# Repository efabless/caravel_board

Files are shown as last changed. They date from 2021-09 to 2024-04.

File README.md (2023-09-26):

# Caravel Board

This repo provides firmware examples, flash programming and diagnostic tools for testing
Open MPW and chipIgnite projects using Caravel.  It also provides schematics, layout and gerber files for PCB evaluation and breakout boards.

## MPW-2 & MPW-3 Project Owners

See the README for the the Nucleo automated [test setup here](firmware/mpw2-5/nucleo)

## chipIgnite Projects (including Stanford)

See the README for testing projects here -- https://github.com/efabless/caravel_board/tree/main/firmware/chipignite#readme

## Firmware

You will need python 3.6 or later.  

To program Caravel, connect the evaluation board using a USB micro B connector.

```bash
pip3 install pyftdi

cd firmware/blink

make clean flash
```

### Install Toolchain for Compiling Code

#### For Mac

https://github.com/riscv/homebrew-riscv

#### For Linux

https://github.com/riscv/riscv-gnu-toolchain

### Diagnostics

Makefiles in the firmware project directories use 

> firmware/chipignite/util/caravel_hkflash.py 

to program the flash on the board through Caravel's housekeeping SPI interface.

> firmware/chipignite/util/caravel_hkdebug.py 

provides menu-driven debug through the housekeeping SPI interface for Caravel.

## Hardware

The current evaluation board for Caravel can be [found here](hardware/development/caravel-dev-v5-M.2)

- The clock is driven by X1 with a frequency of 10MHz. To drive the clock with custom frequency, disable X1 through J6 and use the external pin for `xclk`
- The voltage regulator U5 and U6 supply `1.8V` and `3.3V` through J8 and J9. The traces have to be cut if they are supplied externally.
- `vccd1` is connected to `1.8V` through J3. The trace has to be cut if it is supplied externally
- `vddio` is connected to `3.3V` through J5. The trace has to be cut if it is supplied externally

The most updated breakout board for Caravel can be found [here](hardware/breakout/caravel-M.2-card-QFN)

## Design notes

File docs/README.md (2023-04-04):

# Caravel Board related documents

Introduction slides for the Caravel PCB redesign to use M.2 connectors could be found [here](https://docs.google.com/presentation/d/1iRuPs3BAXP_eN2UHQdqvGFLPBFF6Ztn8L_TTbIhHtWk/edit#slide=id.p1)

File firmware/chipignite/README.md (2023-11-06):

# chipIgnite Bringup Testing

This directory provides instruction and firmware for testing projects the chipIgnite shuttles.

The current version of this document along with firmware example and tools can be found at

https://github.com/efabless/caravel_board/tree/main/firmware/chipignite#readme

## Hardware

The development board provides an easy way to test your project.  The board has a socket for installing your part on a 
breakout board with an M.2 edge connector.  Remove the screw to insall or replace the breakout board module.  The board
inserted into a ZIF connector at a 45 deg angle.  It is then pressed down and held in place with a screw.

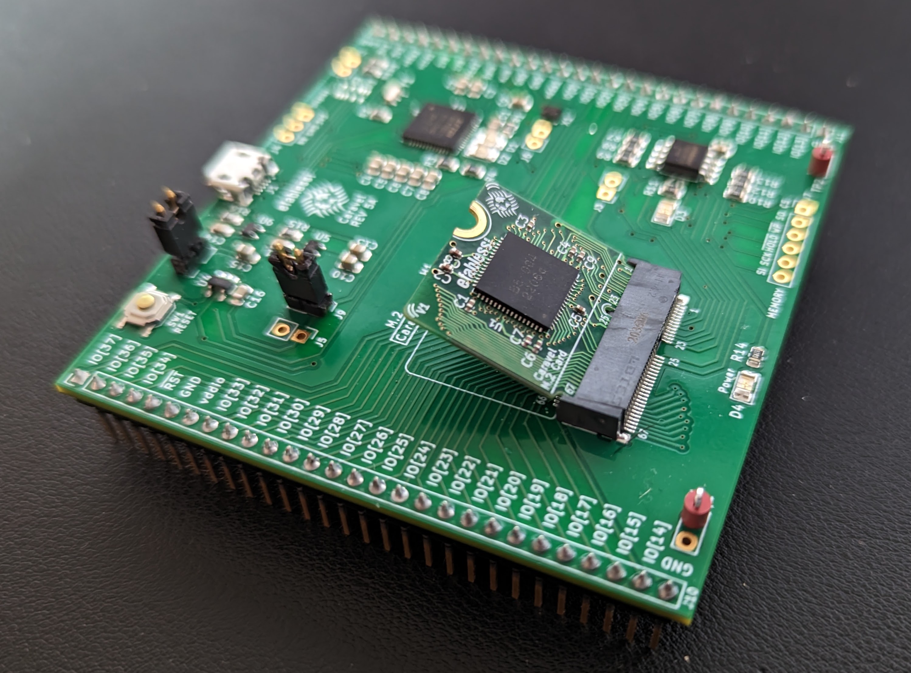
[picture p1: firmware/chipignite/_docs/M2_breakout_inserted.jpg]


To use the development board, install a breakout board with your project into the M.2 connector.  Connect a micro-B USB
from connector J1 to your laptop or workstation.

Follow the instructions in the Firmware section to build and install firmware.  Use the Reset button in the upper left 
corner to reset the RISC-V processor in the management core of Caravel.

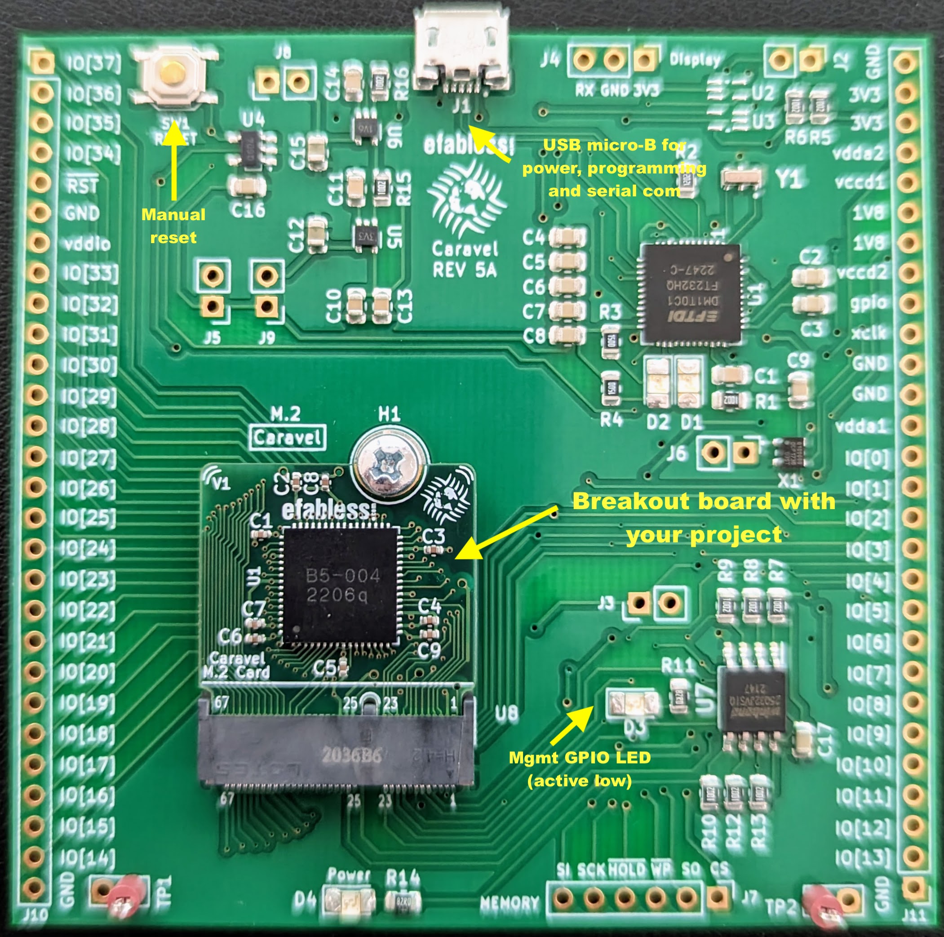
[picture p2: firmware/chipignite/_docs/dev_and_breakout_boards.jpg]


The board has additional features to assist testing your project.  There are several jumpers (J3, J5, J8, J9) which are 
shorted.  The trace between the pins can be cut and a jumper installed to connect an alternative power supply.  These 
supplies include 1.8V, 3.3V, vddio and vccd1.  Other supplies including vccd2, vdda1 and vdda2 are not connected and 
need to be supplied from 28-pin headers on J10 and J11.

The onboard clock is 10MHz and can be disabled by installing jumper J6 and supply a clock signal to the xclk pin on J11.

A serial display can be connected to header J4 and is connected to the Tx serial pin on Caravel.

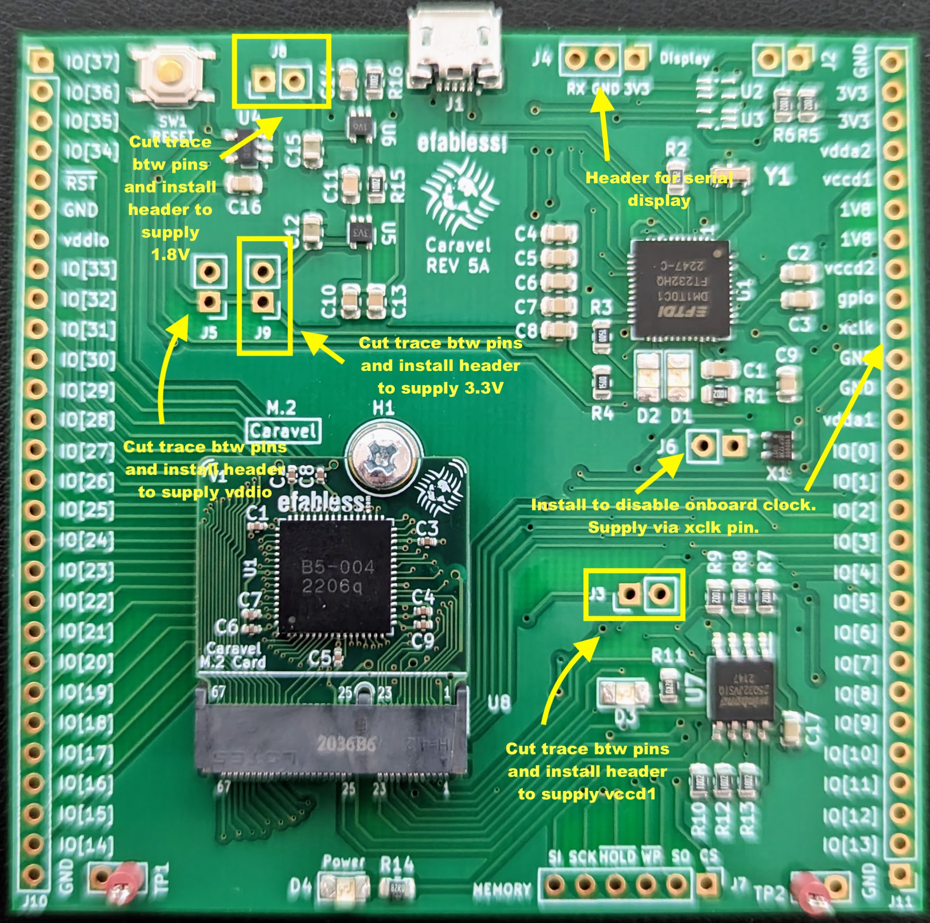
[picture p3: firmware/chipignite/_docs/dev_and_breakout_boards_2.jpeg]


The design files for the development board can be found at 

https://github.com/efabless/caravel_board/tree/main/hardware/development/caravel-dev-v5-M.2

The design files for the M.2 breakout board for Caravel can be found at 

https://github.com/efabless/caravel_board/tree/main/hardware/breakout/caravel-M.2-card-QFN

## Firmware

You will need python 3.6 or later.  

To program Caravel, connect the evaluation board using a USB micro B connector.

```bash
pip3 install pyftdi

cd firmware/chipignite/blink

make clean flash
```

### Install Toolchain for Compiling Code

#### For Mac

https://github.com/riscv/homebrew-riscv

#### For Linux

https://github.com/riscv/riscv-gnu-toolchain

### Diagnostics

Makefiles in the firmware project directories use 

> util/caravel_hkflash.py 

to program the flash on the board through Caravel's housekeeping SPI interface.

> util/caravel_hkdebug.py 

provides menu-driven debug through the housekeeping SPI interface for Caravel.

### Running the example firmware Blink

The `blink` directory contains example firmware for programming the RISC-V processor with a simple program to flash the
LED connected to the management gpio.

Ensure that you have installed the toolchain for compiling for the RISC-V processor.  You may need to update the 
TOOLCHAIN_PATH variable in the Makefile to point to the location for your tools.

Also make sure you have a current version of python and installed the `pyftdi` library described above.  This is 
required by the utility for programming the onboard flash.

To start, run... 

> make clean hex

to build the firmware.  Program the flash on the development board...

> make flash

Press reset to restart execution.  After a few seconds, you should see the LED for the mgmt GPIO begin to blink slowly.

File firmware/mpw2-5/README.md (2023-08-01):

# Caravel Board Firmware for the VexRisc-V Processor

This repo provides firmware examples, flash programming and diagnostic tools for testing
Open MPW and chipIgnite projects using Caravel on the open-source SKY130 technology node.  It also provides schematics, 
layout and gerber files for PCB evaluation and breakout boards.

The current version of this document can be found at

https://github.com/efabless/caravel_board/blob/main/firmware/mpw2-5/README.md

or scan the QR code...

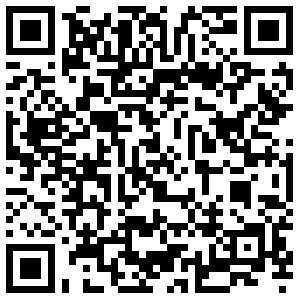
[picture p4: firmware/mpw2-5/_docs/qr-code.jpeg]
qr-code


## Firmware

You will need python 3.6 or later.  

To program Caravel, connect the evaluation board using a USB micro B connector.

```bash
pip3 install pyftdi

cd firmware/blink

make clean flash
```

### Install Toolchain for Compiling Code

#### For Mac

https://github.com/riscv/homebrew-riscv

#### For Linux

https://github.com/riscv/riscv-gnu-toolchain

### Diagnostics

Makefiles in the firmware project directories use 

> firmware/util/caravel_hkflash.py 

to program the flash on the board through Caravel's housekeeping SPI interface.

> firmware/util/caravel_hkdebug.py 

provides menu-driven debug through the housekeeping SPI interface for Caravel.

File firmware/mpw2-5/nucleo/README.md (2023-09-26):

# Caravel Nucleo Hat

This directory provides a diagnostic software for characterizing timing failure patterns between GPIO pads on Caravel 
for the MPW-2 to MPW-5 and related shuttles.

The diagnostic runs on a STM Nucleo development board in combination with a Caravel Hat board that hosts the Caravel 
part under test.

The current version of this document can be found at

https://github.com/efabless/caravel_board/blob/main/firmware/mpw2-5/nucleo/README.md

or scan the QR code...

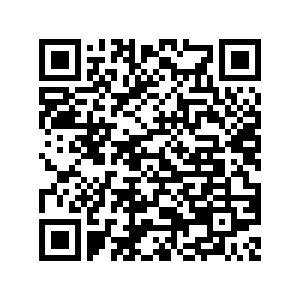
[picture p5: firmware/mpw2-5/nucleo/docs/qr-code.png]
qr-code


## Setup

### COMPONENTS

- NUCLEO-F746ZG or NUCLEO-F413ZH
- Caravel Nucleo Hat
- One or more Caravel breakout boards with a Caravel part installed
- Two jumpers for J8 & J9
- USB micro-B to USB-A cable

### CONFIGURATION

1. Install the jumpers on J8 and J9 in the 'HAT' position to enable the board to be powered by the Nucleo. 
2. Plug the Caravel Nucleo Hat in Nucleo board pins 
   - The USB on the hat should face the ST-LINK breakoff board on Nucleo and away from the push buttons on Nucleo
   - IMPORTANT: the FlexyPin socket allows you to swap breakout boards with different parts.  You do not need to solder 
  any pins.
   - Be careful not to bend a pin when inserting the breakout board.  If one of the pins bend, use needle-nose pliers to 
  re-straighten it.
   - When pressing the Caravel Hat board on the pin headers of the Nucleo, only press far enough to engage the pins.  If
   you press to far, you can short the Flexy pins under the board against jumpers on the Nucleo.

3. Install a Caravel Breakout board into the socket on the Caravel Hat board
     - The Efabless logo should face the USB connector on the Hat

4. Connect the USB cable from the connector CN1 on the Nucleo to your workstation / laptop.
5. Connect a second USB cable from your desktop / workstation from connector CN13 on the opposite side the Nucleo board 
   from the ST-LINK breakaway board.
   - This port presents a mountable volume for the Flash filesystem on Nucleo and is how the software and firmware files
   on copied on to Nucleo. It is also used to retrieve the gpio_config_def.py file after the diagnostic completes.

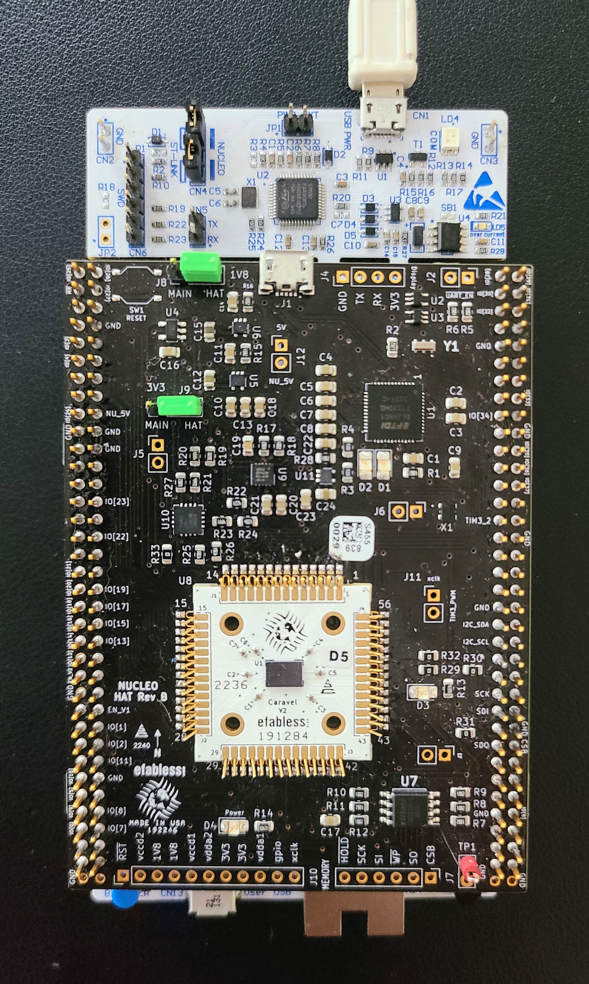
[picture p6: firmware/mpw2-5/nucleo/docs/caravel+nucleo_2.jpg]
<div align="left" style="margin-left: 30px; margin-bottom: 30px;">
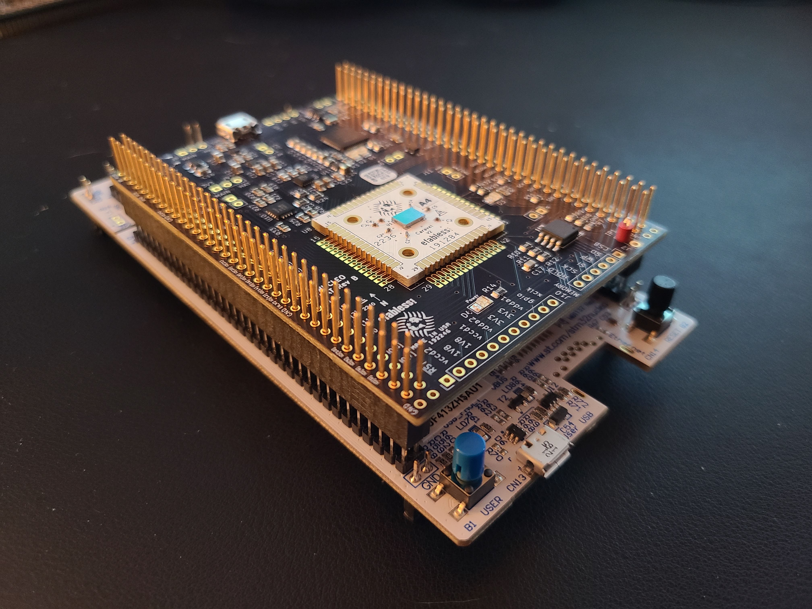
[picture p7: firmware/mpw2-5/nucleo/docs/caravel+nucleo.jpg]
</div>

### INSTALLATION

1. Install the required tools including **mpremote**, **mpy-cross** and **rshell**.  The diagnostic runs on a customized
   Micropython image on the Nucleo board.  The Nucleo firmware image, diagnostic software and Makefile targets for 
   installing and running the routines are located in the `firmware_vex/nucleo` directory in the caravel_board repo.

```bash
  git clone https://github.com/efabless/caravel_board.git
  cd caravel_board/firmware/mpw2-5/nucleo
  make setup
```

- **mpremote** is used for connecting the Micropython
- **mpy-cross** is a cross compiler for Micropython the compiles a python file into a binary format which can be run in 
micropython.  It is used here to reduce the size of the files because the size of the flash on the Nucleo board is 
limited on some models.

2. You will also need to install the **stlink** tools for your client.   These are required to flash Micropython firmware on the Nucleo board.

- For macOS:

```bash
      brew install stlink
```

- For other platforms, see instructions on the github STLINK project README...

   - https://github.com/stlink-org/stlink/tree/master

3. After you made both USB connections, you will need to find the path for the Flash volume.  

   - On MacOS, it should be located at `//Volumes/PYBFLASH`.
   - On Ubuntu, it should be mounted at `/media/<userid>/PYBFLASH`.
   - You will need to `export FLASH=<path>` or set the path in the Makefile at the top of the file.
   - NOTE: For some linux platforms, the PYBFLASH volume is not automatically
   
### FINDING YOUR DEVICE

```bash
  mpremote connect list
```

This will verify you can see the Nucleo board through **mpremote**.  The Makefile 
will automatically find and set the device variable.

### UPDATE THE DIAGNOSTIC SOFTWARE

It will be required to update the diagnostic software to get the latest enhancements and bug fixes.

You can find the model of the Nucleo board on a label in the lower
left corner of the Nucleo board opposite the ST-LINK breakaway board.

Run one of the following make targets based on the model of your Nucleo board. 

```bash
# for the F746ZG Nucleo board
make F746ZG

# for F413ZH
make F413ZH
```

You can also just recompile and copy the files onto the flash by running on of the following make targets:

```bash
# for the F746ZG Nucleo board
make F746ZG-copy

# for F413ZH
make F413ZH-copy
```

After the flash completes, check the version of the software...

```bash
make version

io_config -- version 1.2.1
```

### RUNNING THE DIAGNOSTIC

To run the diagnostic, enter the following commands.  The command depends on whether your project uses **Caravel** or 
**Caravan** (for analog).  

The PART variable is an ID for the part you are testing defined by
you.  It will be recorded in the output of the test for future reference.

```bash
cd caravel_board/firmware/mpw2-5/nucleo

## for digital (or analog) projects using Caravel & user_project_wrapper
make run PART=<part id>

## for analog projects using Caravan & user_analog_project_wrapper
make run_analog PART=<part id>

```

The test will begin with the green LED on the Nucleo flashing 5 times.  

When the test concludes, the green and red leds will be as follows:

| GREEN | RED | STATUS |
| --- | --- | --- |
| 2 short + 4 long | off | Full Success - BOTH IO chains configured successfully |
| 2 long | 2 short | Partial Success - LOW IO chains configured successfully  |
| 4 long | 2 short | Partial Success - HIGH IO chains configured successfully |
| off | 2 short + 4 long | Failed - BOTH IO chains failed to configured fully |
| off | solid | Test failed to complete |

Type `Ctrl-C` to exit the test diagnostid once it completes.  If the test completed for the part, run the following to retrieve the configuration file.  The file will indicated the 
IO that were successfully configured.  Successfully configured IO can be used for this part for firmware routines.

```bash
make get_config
```

The file is specific to the part you ran the diagnostic with. Each part will have a different `gpio_config_def.py` file because the timing
failure pattern will be different for each part.  

## Using the Configuration File

### RUN A SANITY CHECK

The following will run a sanity check test using the gpio_config_def.py produced from the diagnostic above.  The
`gpio_config_def.py` file is stored from the `make get_config` run above and local on your desktop. 

To run the sanity check:

```bash
cd caravel_board/firmware/mpw2-5/nucleo
make sanity_check FILE=gpio_config_def.py
```

BUILDING YOUR OWN FIRMWARE

The **gpio_test** directory (`caravel_board/firmware/mpw2-5/gpio_test`) provides example for creating your own firmware.  
We recommend you copy this directory as a template to create your own firmware.  After copying the directory, update 
`gpio_test` to your firmware name in the Makefile.

You will need to copy the `gpio_config_def.py` for your part into this directory.

Update `gpio_config_io.c` with the correct IO configuration for your project.  Each IO should be set to Management or 
User mode which defines whether the output is driven from the Management or User area.  The IO can be set to output or 
inputs with either pull-down, pull-up or no terminating resistors.

NOTE: You will not be able to configure any IO that is defined as `H_UNKNOWN` in your `gpio_config_def.py` file.  We 
recommend setting these IO (as well as any other IO you are not using) to `C_DISABLE` in your `gpio_config_io.py` file.

You can check that your IO configuration to ensure that you can achieve the desired configuration by running `make check`
from the project directory.  If the configuration can not be configured for that part, you can try changing the 
configuration or switching to a different part that can me configured. 

In your main firmware, you need to include `defs.h` and `gpio_config_io.c` at the top of your file.

Before using IO, you need to call `configure_io()`.
```c
#include "../defs.h"
#include "../gpio_config/gpio_config_io.c"

int main() {

  # initialization
  
  configure_io();
  
  # my routine using IO pads

}
```

You should leave the Caravel Nucleo board mounted and powered by Nucleo.  The timing failure pattern specified in the 
`gpio_config_def.py` is sensitive to the capacitance loading on the pins that is present when the Caravel board is
mounted on the Nucleo and may not be the same when the board is detached.

You can flash and run your firmware with the Caravel Hat mounted on the Nucleo by running:

```bash
make clean flash_nucleo
```

This will rebuild the firmware prior to flashing Caravel through the Nucleo board.  Note, you need to have both USB 
cables connected to the Nucleo to support this.  You also need to have the FLASH variable set correctly per the 
instructions in the [Installation](#installation) section below.

## Troubleshooting

If you are experiencing issues running the diagnostic, there are a few recommended items to check.

1. Once installed and powered on, check if your part is warm to the touch.  If so, you likely have a short in that part
   (or your project).  If its not in the project, try another part.
2. Check voltages for the 3.3V and 1.8V supplies in pins J8 and J9.  They should be at 3.3V and 1.6V respectively.
3. Ensure your Caravel Hat board is not pressed too far down on the pins to the Nucleo.  If it is, you may short some of
Flexy pins underneath the Caravel Hat board against jumpers from the Nucleo board.  Carefully pull and ease the board up 
on the pins of the 70 pin male headers on the Nucleo so that the female headers are just firmly connecting to the pins.
4. There is a known issue wit IO[0] and IO[1] that prevent them from being used by the management SoC as outputs.  See 
errata below.

For further details and issues, please see the 
[errata](https://docs.google.com/spreadsheets/d/1oErt0V6cgy-dxL2uRPfLjIaFMlooplvvDTThpU-rZAQ/edit?usp=sharing).

## Software

This is a flowchart that describes the Software, keywords here are Firmware `code running on caravel` and Software `code running on Nucleo board`

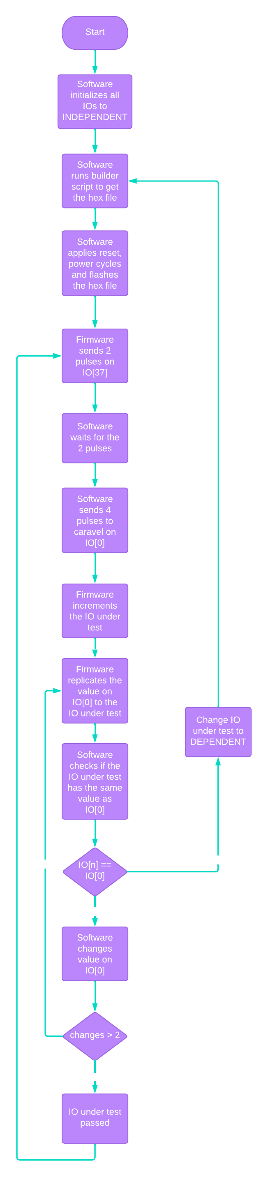
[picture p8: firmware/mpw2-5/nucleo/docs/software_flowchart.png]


### Functions used by the software

The software is done in micropython and ran on the nucleo, some of the useful functions that can be used after running `make repl` and importing `io_config` are:

* `version` :  displays the version of this code
* `run_poweron(v)` : powers on caravel board using the nucleo, with voltage v (default is 1.6)
* `run_change_power(v)` : changes 1v8 power on caravel board using the nucleo with voltage v and without resetting the 
processor.  This can be used to modify the operating power after configuring IO at a different voltage.
* `run_flash_caravel()` : flashes caravel with firmware.hex on the nucleo filesystem
* `run_sanity_check()` : runs the sanity check on an already existing gpio_config_def file on nucleo filesystem
* `run(part_name, voltage, analog)` : runs the calibration program, analog is a flag that specifies if the project is analog

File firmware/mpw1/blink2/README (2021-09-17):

<!---
# SPDX-FileCopyrightText: 2020 Efabless Corporation
#
# Licensed under the Apache License, Version 2.0 (the "License");
# you may not use this file except in compliance with the License.
# You may obtain a copy of the License at
#
#      http://www.apache.org/licenses/LICENSE-2.0
#
# Unless required by applicable law or agreed to in writing, software
# distributed under the License is distributed on an "AS IS" BASIS,
# WITHOUT WARRANTIES OR CONDITIONS OF ANY KIND, either express or implied.
# See the License for the specific language governing permissions and
# limitations under the License.
#
# SPDX-License-Identifier: Apache-2.0
-->
------------------------------------------------
Caravel
gpio_mgmt testbench
------------------------------------------------

This testbench is the simplest "wake-up call" for the development
board.  It toggles the single "gpio" pin under exclusive control
of the management SoC;  first a few times quickly (so it can be
seen in simulation) then continuously at a slow pulse rate, so it
will blink the LED on the prototype board.

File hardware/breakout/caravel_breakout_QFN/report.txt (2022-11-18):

Info: Output directory 'C:\Users\Administrator\Desktop\Efabless\caravel_board\hardware\caravel_breakout_QFN\gerbers' created.
Plotted to 'C:\Users\Administrator\Desktop\Efabless\caravel_board\hardware\caravel_breakout_QFN\gerbers\caravel_breakout_QFN-F_Cu.gbr'.
Plotted to 'C:\Users\Administrator\Desktop\Efabless\caravel_board\hardware\caravel_breakout_QFN\gerbers\caravel_breakout_QFN-B_Cu.gbr'.
Plotted to 'C:\Users\Administrator\Desktop\Efabless\caravel_board\hardware\caravel_breakout_QFN\gerbers\caravel_breakout_QFN-F_Adhesive.gbr'.
Plotted to 'C:\Users\Administrator\Desktop\Efabless\caravel_board\hardware\caravel_breakout_QFN\gerbers\caravel_breakout_QFN-B_Adhesive.gbr'.
Plotted to 'C:\Users\Administrator\Desktop\Efabless\caravel_board\hardware\caravel_breakout_QFN\gerbers\caravel_breakout_QFN-F_Paste.gbr'.
Plotted to 'C:\Users\Administrator\Desktop\Efabless\caravel_board\hardware\caravel_breakout_QFN\gerbers\caravel_breakout_QFN-B_Paste.gbr'.
Plotted to 'C:\Users\Administrator\Desktop\Efabless\caravel_board\hardware\caravel_breakout_QFN\gerbers\caravel_breakout_QFN-F_Silkscreen.gbr'.
Plotted to 'C:\Users\Administrator\Desktop\Efabless\caravel_board\hardware\caravel_breakout_QFN\gerbers\caravel_breakout_QFN-B_Silkscreen.gbr'.
Plotted to 'C:\Users\Administrator\Desktop\Efabless\caravel_board\hardware\caravel_breakout_QFN\gerbers\caravel_breakout_QFN-F_Mask.gbr'.
Plotted to 'C:\Users\Administrator\Desktop\Efabless\caravel_board\hardware\caravel_breakout_QFN\gerbers\caravel_breakout_QFN-B_Mask.gbr'.
Plotted to 'C:\Users\Administrator\Desktop\Efabless\caravel_board\hardware\caravel_breakout_QFN\gerbers\caravel_breakout_QFN-Edge_Cuts.gbr'.
Plotted to 'C:\Users\Administrator\Desktop\Efabless\caravel_board\hardware\caravel_breakout_QFN\gerbers\caravel_breakout_QFN-F_Fab.gbr'.
Plotted to 'C:\Users\Administrator\Desktop\Efabless\caravel_board\hardware\caravel_breakout_QFN\gerbers\caravel_breakout_QFN-B_Fab.gbr'.
Info: Done.

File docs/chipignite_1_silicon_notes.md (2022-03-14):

# Notes for chipIgnite One Silicon (2106Q)

This document provides notes specific to the chipIgnite one silicon and evaluation boards and firmware.

## Hardware

The hardware board is located under `hardware/caravel_pcb_v1`

The board requires the following modifications:
* uninstall the following components:
  * `R11` -- zero ohm resistor connecting `Tx` to `IO[4]`
  * `J7` -- enable for tri-state buffer `U4` for connecting `Rx` to `U4`
  * `U4` -- tri-state buffer `U4`
  * `R16` -- pull-up resistor on Flash SCK signal
* install a jumper between `vccd1` and `1v8` on `J18`

## Firmware

The boards have been programmed with the blink firmware example in the repo.  

Example firmware includes a make target `flash` for programing the flash on the evaluation board.  

The target uses a script `firmware/util/caravel_hkflash.py`.  In some cases, you may need to hold the reset button (jumper `SW1`) while programming the flash.
Occasionally, I've had to comment or uncomment line 144 in `caravel_hkflash.py` which affects whether to hold Caravel in reset before erasing and programming the flash.

The datasheet for Caravel with the management core configuration for chipIgnite 1 (2106Q) can be found [here](./caravel_datasheet.pdf).

Note that you should use the `defs_mpw-two-mfix.h` header file for setting the GPIO configurations.

### GPIO Configuration

By default - all GPIO (5 - 37) are set to user mode bi-directional - which means you should be able to access them from your user project area.  

If your project always sets the OEB lines high (output disabled) for GPIO that are supposed to be inputs, then the configuration should be correct for your user project on startup without applying a configuration from software.

#### Upper IO range -- IO[19] to IO[37]

If you need to configure IO from the management area, we recommend you use IOs 19 - 37.  These IOs can be configured using the firmware examples.   

GPIO configuration is done by setting the memory mapped configuration registers using the configuration values in `defs_mpw-two-mfix.h`.

> GPIO_MODE_USER_STD_INPUT_NOPULL
> GPIO_MODE_USER_STD_INPUT_PULLDOWN
> GPIO_MODE_USER_STD_INPUT_PULLUP
> GPIO_MODE_USER_STD_OUTPUT
> GPIO_MODE_USER_STD_BIDIRECTIONAL
> GPIO_MODE_USER_STD_OUT_MONITORED
> GPIO_MODE_USER_STD_ANALOG

> GPIO_MODE_MGMT_STD_INPUT_NOPULL
> GPIO_MODE_MGMT_STD_INPUT_PULLDOWN
> GPIO_MODE_MGMT_STD_INPUT_PULLUP
> GPIO_MODE_MGMT_STD_OUTPUT
> GPIO_MODE_MGMT_STD_BIDIRECTIONAL
> GPIO_MODE_MGMT_STD_OUT_MONITORED
> GPIO_MODE_MGMT_STD_ANALOG

Configuring an IO in your firmware would look like as follows...

> reg_mprj_io_19 = GPIO_MODE_MGMT_STD_OUTPUT;
> reg_mprj_datal = 0;
> reg_mprj_xfer = 1;
> while (reg_mprj_xfer == 1);

To set the state of an output, you need to set the corresponding bit in the reg_mprj_datal (IO 0 to 31) or reg_mprj_datah (IO 32 to 37) register.

**Important note!  GPIOs 1 to 4 have a reversed bit for management disable that requires swapping the values for "USER" and "MGMT" for these four pins.**

If you are having difficulty programing the upper IOs, you can try providing a slower clock source (5MHz).
 This can be configured by providing a clock signal on xclk input on the board and jumpering J6.  You may need to power-cycle the board and then reset after programming and applying the slower clock.

I've also tested a replacement 5MHz oscillator that I got in - if you are interested in swapping the oscillator on the board, let me know.

#### Lower IO range -- IO[0] to IO[18]

If you would like to program the lower IOs, you need to manipulate the IO configuration bit pattern to compensate for bit slippage occuring in the shift register chain for these IOs.  

To do so, you can use a utility locate at `firmware/util/slippage.py`.  You need to change the desired IO configuration in the top of the script.  

**Note: due to the bit slippage issue, you cannot configure to adjactent IOs to be connected to the management area.**

Once you have the adjusted values, put those in your code for configuring the respective IOs.  After issuing the transfer, you need to set the memory mapped registers back to the unadjusted values you intended to configure.

### Caravel_User_Project_Analog

For project using caravel_user_project_analog, you should note the mapping of the IOs in the wrapper is different from the standard wrapper.

* IO 0 thru 13  -> standard IOs mapping to mprj_io\[13:0\] 
* IO 14 thru 24 -> bare analog pins (no ESD) mapping to io_analog\[10:0\] 
* IO 25 thru 37 -> standard IOs mapping to mprj_io\[26:14\] 

See the comments in the [user_analog_project_wrapper.v](https://github.com/efabless/caravel_user_project_analog/blob/main/verilog/rtl/user_analog_project_wrapper.v) for more details.

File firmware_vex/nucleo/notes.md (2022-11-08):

# Optional erase to clear existing filesystem.
st-flash erase

# Flash .bin
st-flash write firmware.bin 0x08000000
# or, flash .hex
st-flash --format ihex write firmware.hex

sf-flash reset

https://www.youtube.com/watch?v=DMd3XBDgRWs

https://micropython.org/download/NUCLEO_F746ZG/

Install st-link for flashing micropython firmware
 > brew install stlink

 > pip install mpremote

using mpremote
https://docs.micropython.org/en/latest/reference/mpremote.html

programming
https://docs.micropython.org/en/latest/library/machine.html

building firmware
https://github.com/micropython/micropython/blob/master/ports/stm32/README.md

install thonny
install addon --> adafruit-board-kt

./mpy-cross flash.py  # to create .mpy compiled

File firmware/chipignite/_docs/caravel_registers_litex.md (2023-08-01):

Documentation for Caravel Management SoC
========================================

Modules
=======

.. toctree::
:maxdepth: 1

interrupts

Register Groups
===============

.. toctree::
:maxdepth: 1

ctrl
debug_mode
debug_oeb
flash_core
flash_phy
gpio
la
mprj_wb_iena
spi_enabled
spi_master
timer0
uart
uart_enabled
user_irq_0
user_irq_1
user_irq_2
user_irq_3
user_irq_4
user_irq_5
user_irq_ena

Indices and tables
==================

* :ref:`genindex`
* :ref:`modindex`
* :ref:`search`

CTRL
====

Register Listing for CTRL
-------------------------

| Register | Address |
|---|---|
| CTRL_RESET | 0xf0000000 |
| CTRL_SCRATCH | 0xf0000004 |
| CTRL_BUS_ERRORS  | 0xf0000008  |

CTRL_RESET

`Address: 0xf0000000 + 0x0 = 0xf0000000`



| Field | Name | Description |
|---|---|---|
| [0] | SOC_RST | Write 1 to this register to reset the full SoC (Pulse Reset) |
| [1] | CPU_RST | Write 1 to this register to reset the CPU(s) of the SoC (Hold Reset) |

CTRL_SCRATCH

`Address: 0xf0000000 + 0x4 = 0xf0000004`

Use this register as a scratch space to verify that software read/write accesses
to the Wishbone/CSR bus are working correctly. The initial reset value of
0x1234578 can be used to verify endianness.



CTRL_BUS_ERRORS

`Address: 0xf0000000 + 0x8 = 0xf0000008`

Total number of Wishbone bus errors (timeouts) since start.



SPI_MASTER
==========

Register Listing for SPI_MASTER
-------------------------------

| Register | Address |
|---|---|
| SPI_MASTER_CONTROL | 0xf0004800 |
| SPI_MASTER_STATUS | 0xf0004804 |
| SPI_MASTER_MOSI | 0xf0004808 |
| SPI_MASTER_MISO | 0xf000480c |
| SPI_MASTER_CS | 0xf0004810 |
| SPI_MASTER_LOOPBACK | 0xf0004814 |
| SPI_MASTER_CLK_DIVIDER  | 0xf0004818  |

SPI_MASTER_CONTROL

`Address: 0xf0004800 + 0x0 = 0xf0004800`

SPI Control.



| Field  | Name | Description |
|---|---|---|
| [0] | START  | SPI Xfer Start (Write 1 to start Xfer). |
| [15:8] | LENGTH | SPI Xfer Length (in bits). |

SPI_MASTER_STATUS

`Address: 0xf0004800 + 0x4 = 0xf0004804`

SPI Status.



| Field | Name | Description |
|---|---|---|
| [0] | DONE | SPI Xfer Done (when read as 1). |

SPI_MASTER_MOSI

`Address: 0xf0004800 + 0x8 = 0xf0004808`

SPI MOSI data (MSB-first serialization).



SPI_MASTER_MISO

`Address: 0xf0004800 + 0xc = 0xf000480c`

SPI MISO data (MSB-first de-serialization).



SPI_MASTER_CS

`Address: 0xf0004800 + 0x10 = 0xf0004810`

SPI CS Chip-Select and Mode.



| Field | Name | Description |
|---|---|---|
| [0] | SEL  | |
| | | |
| | |  -------------- ----------------------------------- |
| | | | Value | Description | |
| | | |
| | | | 0b0..001 | Chip 0 selected for SPI Xfer. | |
| | |  -------------- ----------------------------------- |
| | | | 0b1..000 | Chip N selected for SPI Xfer. | |
| | |  -------------- ----------------------------------- |
| [16]  | MODE | |
| | | |
| | |  --------- ---------------------------------------------------------------------------------------------  |
| | | | Value | Description | |
| | | |
| | | | 0b0 | Normal operation (CS handled by Core). | |
| | |  --------- ---------------------------------------------------------------------------------------------  |
| | | | 0b1 | Manual operation (CS handled by User, direct recopy of sel), useful for Bulk transfers. | |
| | |  --------- ---------------------------------------------------------------------------------------------  |

SPI_MASTER_LOOPBACK

`Address: 0xf0004800 + 0x14 = 0xf0004814`

SPI Loopback Mode.



| Field | Name | Description |
|---|---|---|
| [0] | MODE | |
| | | |
| | |  --------- ------------------------------------  |
| | | | Value | Description | |
| | | |
| | | | 0b0 | Normal operation. | |
| | |  --------- ------------------------------------  |
| | | | 0b1 | Loopback operation (MOSI to MISO). | |
| | |  --------- ------------------------------------  |

SPI_MASTER_CLK_DIVIDER

`Address: 0xf0004800 + 0x18 = 0xf0004818`

SPI Clk Divider.



QSPI_ENABLED
============

Register Listing for QSPI_ENABLED
---------------------------------

| Register | Address |
|---|---|
| QSPI_ENABLED_OUT  | 0xf0004000  |

QSPI_ENABLED_OUT

`Address: 0xf0004000 + 0x0 = 0xf0004000`

GPIO Output(s) Control.



LA
==

Register Listing for LA
-----------------------

| Register | Address |
|---|---|
| LA_IEN3  | 0xf0003000  |
| LA_IEN2  | 0xf0003004  |
| LA_IEN1  | 0xf0003008  |
| LA_IEN0  | 0xf000300c  |
| LA_OE3 | 0xf0003010 |
| LA_OE2 | 0xf0003014 |
| LA_OE1 | 0xf0003018 |
| LA_OE0 | 0xf000301c |
| LA_IN3 | 0xf0003020 |
| LA_IN2 | 0xf0003024 |
| LA_IN1 | 0xf0003028 |
| LA_IN0 | 0xf000302c |
| LA_OUT3  | 0xf0003030  |
| LA_OUT2  | 0xf0003034  |
| LA_OUT1  | 0xf0003038  |
| LA_OUT0  | 0xf000303c  |

LA_IEN3

`Address: 0xf0003000 + 0x0 = 0xf0003000`

Bits 96-127 of `LA_IEN`. LA Input Enable



LA_IEN2

`Address: 0xf0003000 + 0x4 = 0xf0003004`

Bits 64-95 of `LA_IEN`.



LA_IEN1

`Address: 0xf0003000 + 0x8 = 0xf0003008`

Bits 32-63 of `LA_IEN`.



LA_IEN0

`Address: 0xf0003000 + 0xc = 0xf000300c`

Bits 0-31 of `LA_IEN`.



LA_OE3

`Address: 0xf0003000 + 0x10 = 0xf0003010`

Bits 96-127 of `LA_OE`. LA Output Enable



LA_OE2

`Address: 0xf0003000 + 0x14 = 0xf0003014`

Bits 64-95 of `LA_OE`.



LA_OE1

`Address: 0xf0003000 + 0x18 = 0xf0003018`

Bits 32-63 of `LA_OE`.



LA_OE0

`Address: 0xf0003000 + 0x1c = 0xf000301c`

Bits 0-31 of `LA_OE`.



LA_IN3

`Address: 0xf0003000 + 0x20 = 0xf0003020`

Bits 96-127 of `LA_IN`. LA Input(s) Status.



LA_IN2

`Address: 0xf0003000 + 0x24 = 0xf0003024`

Bits 64-95 of `LA_IN`.



LA_IN1

`Address: 0xf0003000 + 0x28 = 0xf0003028`

Bits 32-63 of `LA_IN`.



LA_IN0

`Address: 0xf0003000 + 0x2c = 0xf000302c`

Bits 0-31 of `LA_IN`.



LA_OUT3

`Address: 0xf0003000 + 0x30 = 0xf0003030`

Bits 96-127 of `LA_OUT`. LA Ouptut(s) Control.



LA_OUT2

`Address: 0xf0003000 + 0x34 = 0xf0003034`

Bits 64-95 of `LA_OUT`.



LA_OUT1

`Address: 0xf0003000 + 0x38 = 0xf0003038`

Bits 32-63 of `LA_OUT`.



LA_OUT0

`Address: 0xf0003000 + 0x3c = 0xf000303c`

Bits 0-31 of `LA_OUT`.



UART
====

Register Listing for UART
-------------------------

| Register | Address |
|---|---|
| UART_RXTX | 0xf0005800 |
| UART_TXFULL | 0xf0005804 |
| UART_RXEMPTY | 0xf0005808 |
| UART_EV_STATUS | 0xf000580c |
| UART_EV_PENDING  | 0xf0005810  |
| UART_EV_ENABLE | 0xf0005814 |
| UART_TXEMPTY | 0xf0005818 |
| UART_RXFULL | 0xf000581c |

UART_RXTX

`Address: 0xf0005800 + 0x0 = 0xf0005800`



UART_TXFULL

`Address: 0xf0005800 + 0x4 = 0xf0005804`

TX FIFO Full.



UART_RXEMPTY

`Address: 0xf0005800 + 0x8 = 0xf0005808`

RX FIFO Empty.



UART_EV_STATUS

`Address: 0xf0005800 + 0xc = 0xf000580c`

This register contains the current raw level of the rx event trigger.  Writes to
this register have no effect.



| Field | Name | Description |
|---|---|---|
| [0] | TX | Level of the tx event |
| [1] | RX | Level of the rx event |

UART_EV_PENDING

`Address: 0xf0005800 + 0x10 = 0xf0005810`

When a  rx event occurs, the corresponding bit will be set in this register.  To
clear the Event, set the corresponding bit in this register.



| Field | Name | Description |
|---|---|---|
| [0] | TX | 1 if a tx event occurred. This Event is triggered on a **falling** edge. |
| [1] | RX | 1 if a rx event occurred. This Event is triggered on a **falling** edge. |

UART_EV_ENABLE

`Address: 0xf0005800 + 0x14 = 0xf0005814`

This register enables the corresponding rx events.  Write a ``0`` to this
register to disable individual events.



| Field | Name | Description |
|---|---|---|
| [0] | TX | Write a 1 to enable the tx Event |
| [1] | RX | Write a 1 to enable the rx Event |

UART_TXEMPTY

`Address: 0xf0005800 + 0x18 = 0xf0005818`

TX FIFO Empty.



UART_RXFULL

`Address: 0xf0005800 + 0x1c = 0xf000581c`

RX FIFO Full.



TIMER0
======

Timer
-----

Provides a generic Timer core.

The Timer is implemented as a countdown timer that can be used in various modes:

- Polling : Returns current countdown value to software
- One-Shot: Loads itself and stops when value reaches ``0``
- Periodic: (Re-)Loads itself when value reaches ``0``

``en`` register allows the user to enable/disable the Timer. When the Timer is enabled, it is
automatically loaded with the value of `load` register.

When the Timer reaches ``0``, it is automatically reloaded with value of `reload` register.

The user can latch the current countdown value by writing to ``update_value`` register, it will
update ``value`` register with current countdown value.

To use the Timer in One-Shot mode, the user needs to:

- Disable the timer
- Set the ``load`` register to the expected duration
- (Re-)Enable the Timer

To use the Timer in Periodic mode, the user needs to:

- Disable the Timer
- Set the ``load`` register to 0
- Set the ``reload`` register to the expected period
- Enable the Timer

For both modes, the CPU can be advertised by an IRQ that the duration/period has elapsed. (The
CPU can also do software polling with ``update_value`` and ``value`` to know the elapsed duration)

Register Listing for TIMER0
---------------------------

| Register | Address |
|---|---|
| TIMER0_LOAD | 0xf0005000 |
| TIMER0_RELOAD | 0xf0005004 |
| TIMER0_EN | 0xf0005008 |
| TIMER0_UPDATE_VALUE  | 0xf000500c  |
| TIMER0_VALUE | 0xf0005010 |
| TIMER0_EV_STATUS | 0xf0005014 |
| TIMER0_EV_PENDING | 0xf0005018 |
| TIMER0_EV_ENABLE | 0xf000501c |

TIMER0_LOAD

`Address: 0xf0005000 + 0x0 = 0xf0005000`

Load value when Timer is (re-)enabled. In One-Shot mode, the value written to
this register specifies the Timer's duration in clock cycles.



TIMER0_RELOAD

`Address: 0xf0005000 + 0x4 = 0xf0005004`

Reload value when Timer reaches ``0``. In Periodic mode, the value written to
this register specify the Timer's period in clock cycles.



TIMER0_EN

`Address: 0xf0005000 + 0x8 = 0xf0005008`

Enable flag of the Timer. Set this flag to ``1`` to enable/start the Timer.  Set
to ``0`` to disable the Timer.



TIMER0_UPDATE_VALUE

`Address: 0xf0005000 + 0xc = 0xf000500c`

Update trigger for the current countdown value. A write to this register latches
the current countdown value to ``value`` register.



TIMER0_VALUE

`Address: 0xf0005000 + 0x10 = 0xf0005010`

Latched countdown value. This value is updated by writing to ``update_value``.



TIMER0_EV_STATUS

`Address: 0xf0005000 + 0x14 = 0xf0005014`

This register contains the current raw level of the zero event trigger.  Writes
to this register have no effect.



| Field | Name | Description |
|---|---|---|
| [0] | ZERO | Level of the zero event |

TIMER0_EV_PENDING

`Address: 0xf0005000 + 0x18 = 0xf0005018`

When a  zero event occurs, the corresponding bit will be set in this register.
To clear the Event, set the corresponding bit in this register.



| Field | Name | Description |
|---|---|---|
| [0] | ZERO | 1 if a zero event occurred. This Event is triggered on a **falling** edge. |

TIMER0_EV_ENABLE

`Address: 0xf0005000 + 0x1c = 0xf000501c`

This register enables the corresponding zero events.  Write a ``0`` to this
register to disable individual events.



| Field | Name | Description |
|---|---|---|
| [0] | ZERO | Write a 1 to enable the zero Event |

FLASH_CORE
==========

Register Listing for FLASH_CORE
-------------------------------

| Register | Address |
|---|---|
| FLASH_CORE_MMAP_DUMMY_BITS | 0xf0001800 |
| FLASH_CORE_MASTER_CS | 0xf0001804 |
| FLASH_CORE_MASTER_PHYCONFIG  | 0xf0001808  |
| FLASH_CORE_MASTER_RXTX | 0xf000180c |
| FLASH_CORE_MASTER_STATUS | 0xf0001810 |

FLASH_CORE_MMAP_DUMMY_BITS

`Address: 0xf0001800 + 0x0 = 0xf0001800`



FLASH_CORE_MASTER_CS

`Address: 0xf0001800 + 0x4 = 0xf0001804`



FLASH_CORE_MASTER_PHYCONFIG

`Address: 0xf0001800 + 0x8 = 0xf0001808`

SPI PHY settings.



| Field | Name  | Description |
|---|---|---|
| [7:0] | LEN | SPI Xfer length (in bits). |
| [11:8]  | WIDTH | SPI Xfer width (1/2/4/8). |
| [23:16] | MASK  | SPI DQ output enable mask (set bits to 1 to enable output drivers on DQ |
| | | lines). |

FLASH_CORE_MASTER_RXTX

`Address: 0xf0001800 + 0xc = 0xf000180c`



FLASH_CORE_MASTER_STATUS

`Address: 0xf0001800 + 0x10 = 0xf0001810`



| Field | Name | Description |
|---|---|---|
| [0] | TX_READY | TX FIFO is not full.  |
| [1] | RX_READY | RX FIFO is not empty. |

DEBUG_MODE
==========

Register Listing for DEBUG_MODE
-------------------------------

| Register | Address |
|---|---|
| DEBUG_MODE_OUT  | 0xf0000800  |

DEBUG_MODE_OUT

`Address: 0xf0000800 + 0x0 = 0xf0000800`

GPIO Output(s) Control.



DEBUG_OEB
=========

Register Listing for DEBUG_OEB
------------------------------

| Register | Address |
|---|---|
| DEBUG_OEB_OUT  | 0xf0001000  |

DEBUG_OEB_OUT

`Address: 0xf0001000 + 0x0 = 0xf0001000`

GPIO Output(s) Control.



UART_ENABLED
============

Register Listing for UART_ENABLED
---------------------------------

| Register | Address |
|---|---|
| UART_ENABLED_OUT  | 0xf0006000  |

UART_ENABLED_OUT

`Address: 0xf0006000 + 0x0 = 0xf0006000`

GPIO Output(s) Control.



Interrupt Controller
====================

This device has an ``EventManager``-based interrupt system.  Individual modules
generate `events` which are wired into a central interrupt controller.

When an interrupt occurs, you should look the interrupt number up in the CPU-
specific interrupt table and then call the relevant module.

Assigned Interrupts
-------------------

The following interrupts are assigned on this system:

| Interrupt | Module |
|---|---|
| 0 | TIMER0 |
| 1 | UART |
| 2 | USER_IRQ_0  |
| 3 | USER_IRQ_1  |
| 4 | USER_IRQ_2  |
| 5 | USER_IRQ_3  |
| 6 | USER_IRQ_4  |
| 7 | USER_IRQ_5  |

GPIO
====

Register Listing for GPIO
-------------------------

| Register | Address |
|---|---|
| GPIO_MODE1  | 0xf0002800  |
| GPIO_MODE0  | 0xf0002804  |
| GPIO_IEN | 0xf0002808 |
| GPIO_OE | 0xf000280c |
| GPIO_IN | 0xf0002810 |
| GPIO_OUT | 0xf0002814 |

GPIO_MODE1

`Address: 0xf0002800 + 0x0 = 0xf0002800`

GPIO Tristate(s) Control.



GPIO_MODE0

`Address: 0xf0002800 + 0x4 = 0xf0002804`

GPIO Tristate(s) Control.



GPIO_IEN

`Address: 0xf0002800 + 0x8 = 0xf0002808`

GPIO Tristate(s) Control.



GPIO_OE

`Address: 0xf0002800 + 0xc = 0xf000280c`

GPIO Tristate(s) Control.



GPIO_IN

`Address: 0xf0002800 + 0x10 = 0xf0002810`

GPIO Input(s) Status.



GPIO_OUT

`Address: 0xf0002800 + 0x14 = 0xf0002814`

GPIO Ouptut(s) Control.



USER_IRQ_4
==========

Register Listing for USER_IRQ_4
-------------------------------

| Register | Address |
|---|---|
| USER_IRQ_4_IN | 0xf0008800 |
| USER_IRQ_4_MODE | 0xf0008804 |
| USER_IRQ_4_EDGE | 0xf0008808 |
| USER_IRQ_4_EV_STATUS | 0xf000880c |
| USER_IRQ_4_EV_PENDING  | 0xf0008810  |
| USER_IRQ_4_EV_ENABLE | 0xf0008814 |

USER_IRQ_4_IN

`Address: 0xf0008800 + 0x0 = 0xf0008800`

GPIO Input(s) Status.



USER_IRQ_4_MODE

`Address: 0xf0008800 + 0x4 = 0xf0008804`

GPIO IRQ Mode: 0: Edge, 1: Change.



USER_IRQ_4_EDGE

`Address: 0xf0008800 + 0x8 = 0xf0008808`

GPIO IRQ Edge (when in Edge mode): 0: Rising Edge, 1: Falling Edge.



USER_IRQ_4_EV_STATUS

`Address: 0xf0008800 + 0xc = 0xf000880c`

This register contains the current raw level of the i0 event trigger.  Writes to
this register have no effect.



| Field | Name | Description |
|---|---|---|
| [0] | I0 | Level of the i0 event |

USER_IRQ_4_EV_PENDING

`Address: 0xf0008800 + 0x10 = 0xf0008810`

When a  i0 event occurs, the corresponding bit will be set in this register.  To
clear the Event, set the corresponding bit in this register.



| Field | Name | Description |
|---|---|---|
| [0] | I0 | 1 if a i0 event occurred. This Event is triggered on a **falling** edge. |

USER_IRQ_4_EV_ENABLE

`Address: 0xf0008800 + 0x14 = 0xf0008814`

This register enables the corresponding i0 events.  Write a ``0`` to this
register to disable individual events.



| Field | Name | Description |
|---|---|---|
| [0] | I0 | Write a 1 to enable the i0 Event |

USER_IRQ_5
==========

Register Listing for USER_IRQ_5
-------------------------------

| Register | Address |
|---|---|
| USER_IRQ_5_IN | 0xf0009000 |
| USER_IRQ_5_MODE | 0xf0009004 |
| USER_IRQ_5_EDGE | 0xf0009008 |
| USER_IRQ_5_EV_STATUS | 0xf000900c |
| USER_IRQ_5_EV_PENDING  | 0xf0009010  |
| USER_IRQ_5_EV_ENABLE | 0xf0009014 |

USER_IRQ_5_IN

`Address: 0xf0009000 + 0x0 = 0xf0009000`

GPIO Input(s) Status.



USER_IRQ_5_MODE

`Address: 0xf0009000 + 0x4 = 0xf0009004`

GPIO IRQ Mode: 0: Edge, 1: Change.



USER_IRQ_5_EDGE

`Address: 0xf0009000 + 0x8 = 0xf0009008`

GPIO IRQ Edge (when in Edge mode): 0: Rising Edge, 1: Falling Edge.



USER_IRQ_5_EV_STATUS

`Address: 0xf0009000 + 0xc = 0xf000900c`

This register contains the current raw level of the i0 event trigger.  Writes to
this register have no effect.



| Field | Name | Description |
|---|---|---|
| [0] | I0 | Level of the i0 event |

USER_IRQ_5_EV_PENDING

`Address: 0xf0009000 + 0x10 = 0xf0009010`

When a  i0 event occurs, the corresponding bit will be set in this register.  To
clear the Event, set the corresponding bit in this register.



| Field | Name | Description |
|---|---|---|
| [0] | I0 | 1 if a i0 event occurred. This Event is triggered on a **falling** edge. |

USER_IRQ_5_EV_ENABLE

`Address: 0xf0009000 + 0x14 = 0xf0009014`

This register enables the corresponding i0 events.  Write a ``0`` to this
register to disable individual events.



| Field | Name | Description |
|---|---|---|
| [0] | I0 | Write a 1 to enable the i0 Event |

FLASH_PHY
=========

Register Listing for FLASH_PHY
------------------------------

| Register | Address |
|---|---|
| FLASH_PHY_CLK_DIVISOR  | 0xf0002000  |

FLASH_PHY_CLK_DIVISOR

`Address: 0xf0002000 + 0x0 = 0xf0002000`



USER_IRQ_2
==========

Register Listing for USER_IRQ_2
-------------------------------

| Register | Address |
|---|---|
| USER_IRQ_2_IN | 0xf0007800 |
| USER_IRQ_2_MODE | 0xf0007804 |
| USER_IRQ_2_EDGE | 0xf0007808 |
| USER_IRQ_2_EV_STATUS | 0xf000780c |
| USER_IRQ_2_EV_PENDING  | 0xf0007810  |
| USER_IRQ_2_EV_ENABLE | 0xf0007814 |

USER_IRQ_2_IN

`Address: 0xf0007800 + 0x0 = 0xf0007800`

GPIO Input(s) Status.



USER_IRQ_2_MODE

`Address: 0xf0007800 + 0x4 = 0xf0007804`

GPIO IRQ Mode: 0: Edge, 1: Change.



USER_IRQ_2_EDGE

`Address: 0xf0007800 + 0x8 = 0xf0007808`

GPIO IRQ Edge (when in Edge mode): 0: Rising Edge, 1: Falling Edge.



USER_IRQ_2_EV_STATUS

`Address: 0xf0007800 + 0xc = 0xf000780c`

This register contains the current raw level of the i0 event trigger.  Writes to
this register have no effect.



| Field | Name | Description |
|---|---|---|
| [0] | I0 | Level of the i0 event |

USER_IRQ_2_EV_PENDING

`Address: 0xf0007800 + 0x10 = 0xf0007810`

When a  i0 event occurs, the corresponding bit will be set in this register.  To
clear the Event, set the corresponding bit in this register.



| Field | Name | Description |
|---|---|---|
| [0] | I0 | 1 if a i0 event occurred. This Event is triggered on a **falling** edge. |

USER_IRQ_2_EV_ENABLE

`Address: 0xf0007800 + 0x14 = 0xf0007814`

This register enables the corresponding i0 events.  Write a ``0`` to this
register to disable individual events.



| Field | Name | Description |
|---|---|---|
| [0] | I0 | Write a 1 to enable the i0 Event |

USER_IRQ_3
==========

Register Listing for USER_IRQ_3
-------------------------------

| Register | Address |
|---|---|
| USER_IRQ_3_IN | 0xf0008000 |
| USER_IRQ_3_MODE | 0xf0008004 |
| USER_IRQ_3_EDGE | 0xf0008008 |
| USER_IRQ_3_EV_STATUS | 0xf000800c |
| USER_IRQ_3_EV_PENDING  | 0xf0008010  |
| USER_IRQ_3_EV_ENABLE | 0xf0008014 |

USER_IRQ_3_IN

`Address: 0xf0008000 + 0x0 = 0xf0008000`

GPIO Input(s) Status.



USER_IRQ_3_MODE

`Address: 0xf0008000 + 0x4 = 0xf0008004`

GPIO IRQ Mode: 0: Edge, 1: Change.



USER_IRQ_3_EDGE

`Address: 0xf0008000 + 0x8 = 0xf0008008`

GPIO IRQ Edge (when in Edge mode): 0: Rising Edge, 1: Falling Edge.



USER_IRQ_3_EV_STATUS

`Address: 0xf0008000 + 0xc = 0xf000800c`

This register contains the current raw level of the i0 event trigger.  Writes to
this register have no effect.



| Field | Name | Description |
|---|---|---|
| [0] | I0 | Level of the i0 event |

USER_IRQ_3_EV_PENDING

`Address: 0xf0008000 + 0x10 = 0xf0008010`

When a  i0 event occurs, the corresponding bit will be set in this register.  To
clear the Event, set the corresponding bit in this register.



| Field | Name | Description |
|---|---|---|
| [0] | I0 | 1 if a i0 event occurred. This Event is triggered on a **falling** edge. |

USER_IRQ_3_EV_ENABLE

`Address: 0xf0008000 + 0x14 = 0xf0008014`

This register enables the corresponding i0 events.  Write a ``0`` to this
register to disable individual events.



| Field | Name | Description |
|---|---|---|
| [0] | I0 | Write a 1 to enable the i0 Event |

SPI_ENABLED
===========

Register Listing for SPI_ENABLED
--------------------------------

| Register | Address |
|---|---|
| SPI_ENABLED_OUT  | 0xf0004000  |

SPI_ENABLED_OUT

`Address: 0xf0004000 + 0x0 = 0xf0004000`

GPIO Output(s) Control.



USER_IRQ_ENA
============

Register Listing for USER_IRQ_ENA
---------------------------------

| Register | Address |
|---|---|
| USER_IRQ_ENA_OUT  | 0xf0009800  |

USER_IRQ_ENA_OUT

`Address: 0xf0009800 + 0x0 = 0xf0009800`

GPIO Output(s) Control.



MPRJ_WB_IENA
============

Register Listing for MPRJ_WB_IENA
---------------------------------

| Register | Address |
|---|---|
| MPRJ_WB_IENA_OUT  | 0xf0003800  |

MPRJ_WB_IENA_OUT

`Address: 0xf0003800 + 0x0 = 0xf0003800`

GPIO Output(s) Control.



USER_IRQ_1
==========

Register Listing for USER_IRQ_1
-------------------------------

| Register | Address |
|---|---|
| USER_IRQ_1_IN | 0xf0007000 |
| USER_IRQ_1_MODE | 0xf0007004 |
| USER_IRQ_1_EDGE | 0xf0007008 |
| USER_IRQ_1_EV_STATUS | 0xf000700c |
| USER_IRQ_1_EV_PENDING  | 0xf0007010  |
| USER_IRQ_1_EV_ENABLE | 0xf0007014 |

USER_IRQ_1_IN

`Address: 0xf0007000 + 0x0 = 0xf0007000`

GPIO Input(s) Status.



USER_IRQ_1_MODE

`Address: 0xf0007000 + 0x4 = 0xf0007004`

GPIO IRQ Mode: 0: Edge, 1: Change.



USER_IRQ_1_EDGE

`Address: 0xf0007000 + 0x8 = 0xf0007008`

GPIO IRQ Edge (when in Edge mode): 0: Rising Edge, 1: Falling Edge.



USER_IRQ_1_EV_STATUS

`Address: 0xf0007000 + 0xc = 0xf000700c`

This register contains the current raw level of the i0 event trigger.  Writes to
this register have no effect.



| Field | Name | Description |
|---|---|---|
| [0] | I0 | Level of the i0 event |

USER_IRQ_1_EV_PENDING

`Address: 0xf0007000 + 0x10 = 0xf0007010`

When a  i0 event occurs, the corresponding bit will be set in this register.  To
clear the Event, set the corresponding bit in this register.



| Field | Name | Description |
|---|---|---|
| [0] | I0 | 1 if a i0 event occurred. This Event is triggered on a **falling** edge. |

USER_IRQ_1_EV_ENABLE

`Address: 0xf0007000 + 0x14 = 0xf0007014`

This register enables the corresponding i0 events.  Write a ``0`` to this
register to disable individual events.



| Field | Name | Description |
|---|---|---|
| [0] | I0 | Write a 1 to enable the i0 Event |

USER_IRQ_0
==========

Register Listing for USER_IRQ_0
-------------------------------

| Register | Address |
|---|---|
| USER_IRQ_0_IN | 0xf0006800 |
| USER_IRQ_0_MODE | 0xf0006804 |
| USER_IRQ_0_EDGE | 0xf0006808 |
| USER_IRQ_0_EV_STATUS | 0xf000680c |
| USER_IRQ_0_EV_PENDING  | 0xf0006810  |
| USER_IRQ_0_EV_ENABLE | 0xf0006814 |

USER_IRQ_0_IN

`Address: 0xf0006800 + 0x0 = 0xf0006800`

GPIO Input(s) Status.



USER_IRQ_0_MODE

`Address: 0xf0006800 + 0x4 = 0xf0006804`

GPIO IRQ Mode: 0: Edge, 1: Change.



USER_IRQ_0_EDGE

`Address: 0xf0006800 + 0x8 = 0xf0006808`

GPIO IRQ Edge (when in Edge mode): 0: Rising Edge, 1: Falling Edge.



USER_IRQ_0_EV_STATUS

`Address: 0xf0006800 + 0xc = 0xf000680c`

This register contains the current raw level of the i0 event trigger.  Writes to
this register have no effect.



| Field | Name | Description |
|---|---|---|
| [0] | I0 | Level of the i0 event |

USER_IRQ_0_EV_PENDING

`Address: 0xf0006800 + 0x10 = 0xf0006810`

When a  i0 event occurs, the corresponding bit will be set in this register.  To
clear the Event, set the corresponding bit in this register.



| Field | Name | Description |
|---|---|---|
| [0] | I0 | 1 if a i0 event occurred. This Event is triggered on a **falling** edge. |

USER_IRQ_0_EV_ENABLE

`Address: 0xf0006800 + 0x14 = 0xf0006814`

This register enables the corresponding i0 events.  Write a ``0`` to this
register to disable individual events.



| Field | Name | Description |
|---|---|---|
| [0] | I0 | Write a 1 to enable the i0 Event |

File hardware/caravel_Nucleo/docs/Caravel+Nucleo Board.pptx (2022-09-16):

## Caravel + Nucleo Board

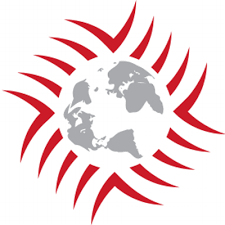
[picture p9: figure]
efabless.com - Home | Facebook

## Specifications

The board required features:
- To be physically compatible to act as a hat to the ST Nucleo board using the ST morpho connectors (plug-in). This would provide test setups for characterizing IOs configuration using the Nucleo board
- Includes programmable power supply on board to test the Caravel chip at a range of power supplies
- The programmable power supply is programmed with SPI/ I^2 C
- It can function as a stand-alone Caravel evaluation board similar to the Caravel V4 evaluation board system
- The reset could be programmed and not only activated with the push-button

## Programmable Power Supply

- A programmable power supply is required to test the chip with non-nominal supplies
- The required ranges are from 1.4V to 2.2V for V_1.8 and 3V to 3.6V for V_3.3
- Adjustable dual LDO (MIC2211) is capable of suppling from 1.25V to 5V at 150mA for V_(out1) and at 300mA for V_(out2)
- A digital potentiometer (D-POT) MCP4661 could be used with R network to dynamically tune the voltage outputs of the LDO using I^2 C interface
- D-POT ( 10 kΩ device) range to be used in the calculations is from 0 kΩ to 7 kΩ , since its maximum resistance range at temperature corners is 8 kΩ and 12 kΩ
- MCP4661 has 257 taps
N=(R_(MAX))/(R_(TOT))∗256=179.2≈179
R_(step) =(R_(TOT))/256=39 Ω
[1]: https://www.ti.com/lit/ug/tidu950/tidu950.pdf?ts=1661679201370&ref_url=https%253A%252F%252Fwww.google.com%252F

## Resistance Calculations

For V_1.8 ,
V_(out1min) =1.4V V_(out1max) =2.2V
R_(LSmax) =3 kΩ V_(Ref) =1.25V
V_(out1min) =V_(Ref) (1+(R_1)/(R_(LSmax))) ∴R_1 =R_(LSmax) ((V_(out1min))/(V_(Ref))−1)=360 Ω
R_(LSmin) =R_1 ∗((V_(Ref))/(V_(out1max) −V_(Ref)))=473.7Ω
R_(DPmin) =0 kΩ R_(DPmax) =7 kΩ
R_(LSmin) =(R_2 ∗(R_3 +R_(DPmin) ))/(R_2 +R_3 +R_(DPmin))=(R_2 ∗R_3)/(R_2 +R_3) R_(LSmax) =(R_2 ∗(R_3 +R_(DPmax) ))/(R_2 +R_3 +R_(DPmax))
Assume R_3 =500 Ω ,
R_2 =(R_(LSmax) ∗(R_3 +R_(DPmax) ))/((R_3 +R_(DPmax) )−R_(LSmax))=5 kΩ
Verify:
R_(LSmin) =(R_2 ∗R_3)/(R_2 +R_3)=455 Ω ∴V_(out2max) =V_(Ref) (1+(R_1)/(R_(LSmin)))=2.24V

Notes:
V_(Ref) is from the adjustable dual LDO (MIC2211) datasheet
R_(LSmax) is set to ensure loop stability, not sure of the basis of this value

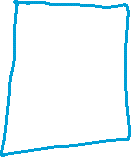
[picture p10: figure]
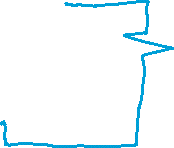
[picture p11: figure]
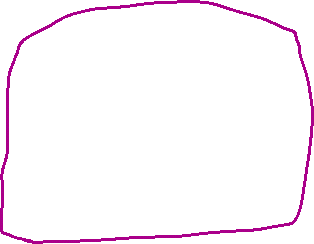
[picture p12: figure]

## Resistance Calculations

For V_3.3 ,
V_(out2min) =3V V_(out2max) =3.6V
R_(LSmax) =3 kΩ V_(Ref) =1.25V
V_(out2min) =V_(Ref) (1+(R_1)/(R_(LSmax))) ∴R_1 =R_(LSmax) ((V_(out2min))/(V_(Ref))−1)=4.2 kΩ
R_(LSmin) =R_1 ∗((V_(Ref))/(V_(out2max) −V_(Ref)))=2. 2kΩ
R_(DPmin) =0 kΩ R_(DPmax) =7 kΩ
R_(LSmin) =(R_2 ∗(R_3 +R_(DPmin) ))/(R_2 +R_3 +R_(DPmin))=(R_2 ∗R_3)/(R_2 +R_3) R_(LSmax) =(R_2 ∗(R_3 +R_(DPmax) ))/(R_2 +R_3 +R_(DPmax))
Assume R_3 =5 kΩ ,
R_2 =(R_(LSmax) ∗(R_3 +R_(DPmax) ))/((R_3 +R_(DPmax) )−R_(LSmax))=4 kΩ
Verify:
R_(LSmin) =(R_2 ∗R_3)/(R_2 +R_3)=2.2 kΩ ∴V_(out2max) =V_(Ref) (1+(R_1)/(R_(LSmin)))=3.64V
Notes:
V_(Ref) is from the dual LDO (MIC2211) datasheet
R_(LSmax) is set to ensure loop stability in the TI note, not sure of the basis of this value

## Resistance Calculations

For nominal supplies:
V_(out1) =1.8V V_(out2) =3.3V
R_(LS) =R_1 ∗((V_(Ref))/(V_(out) −V_(Ref)))
∴R_(LS1) =818.2 Ω ∴R_(LS2) =2.6 kΩ
R_(LS) =(R_2 ∗(R_3 +R_(DP) ))/(R_2 +R_3 +R_(DP)) ∴R_(DP) =(R_(LS) ∗(R_2 +R_3 )−R_2 R_3)/(R_2 −R_(LS))
∴R_(DP1) =478 Ω ∴R_(DP2) =2. 4kΩ
R_(DP) =(R_(TOT) N)/256+R_W ∴N=(R_(DP) −R_W )∗256/(R_(TOT))
R_W =75 Ω R_(TOT) =10 kΩ
∴N_1 =10.3≈11 (Bh) ∴N_2 =59.5≈60 (3Ch)

## Resistors

Output | Resistor | Computed Value | Size 0805 1%
V_(out1) | R_1 | 360 Ω | 360 Ω
| R_2 | 5 kΩ | 4.99 kΩ
| R_3 | 500 Ω | 499 Ω
V_(out2) | R_1 | 4.2 kΩ | 4.22 kΩ
| R_2 | 4 kΩ | 4.02 kΩ
| R_3 | 5 kΩ | 4.99 kΩ

Notes:
MIC2211 datasheet recommends the resistor values should be between 100kΩ and 500kΩ to prevent compromising the low quiescent current performance. This can’t be achieved with the R_(LSmax) assumption

## Caravel Board V4 Block Diagram

USB Interface

Voltage Regulator

5V Supply

3.3V Supply

1.8V Supply

PoR

Flash Memory

FTDI

SPI

HKSPI/IO [1:4]

Caravel BB

RST

UART

IO [5:6]

FLASH Interface

Configure IOs

IO [0:37]

SPI

UART Enable

## Nucleo Board: NUCLEO144-F746ZG

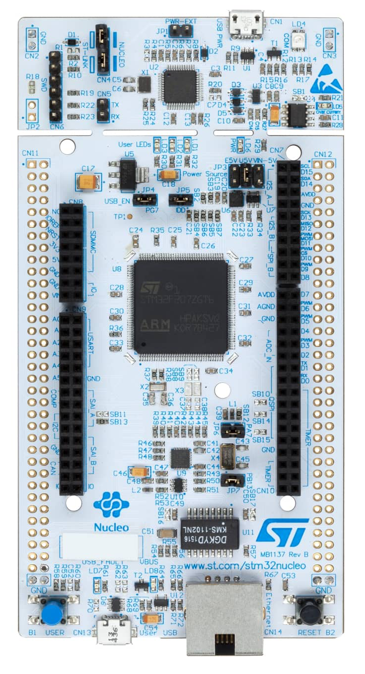
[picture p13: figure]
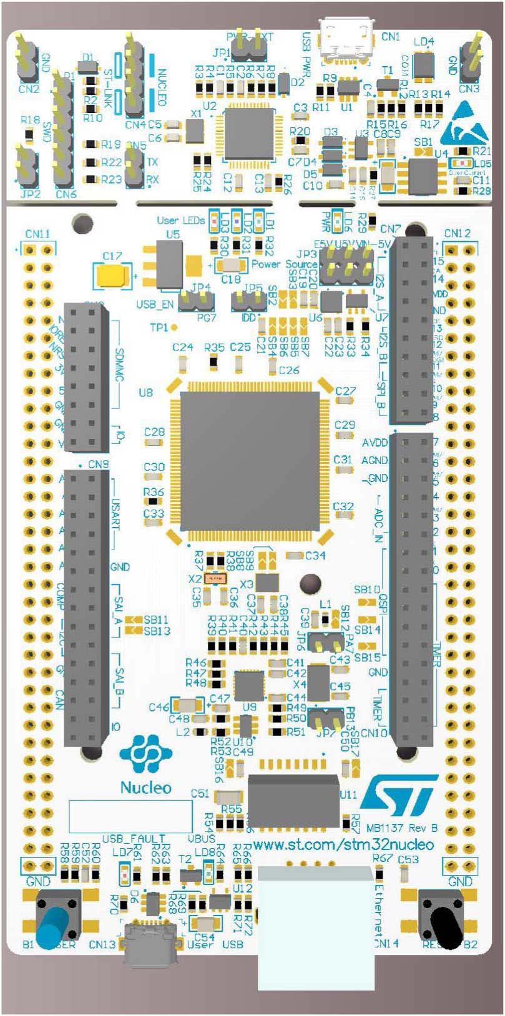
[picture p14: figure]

[2]: https://www.st.com/en/evaluation-tools/nucleo-F746ZG.html

## Nucleo Board: ST Morpho Connectors

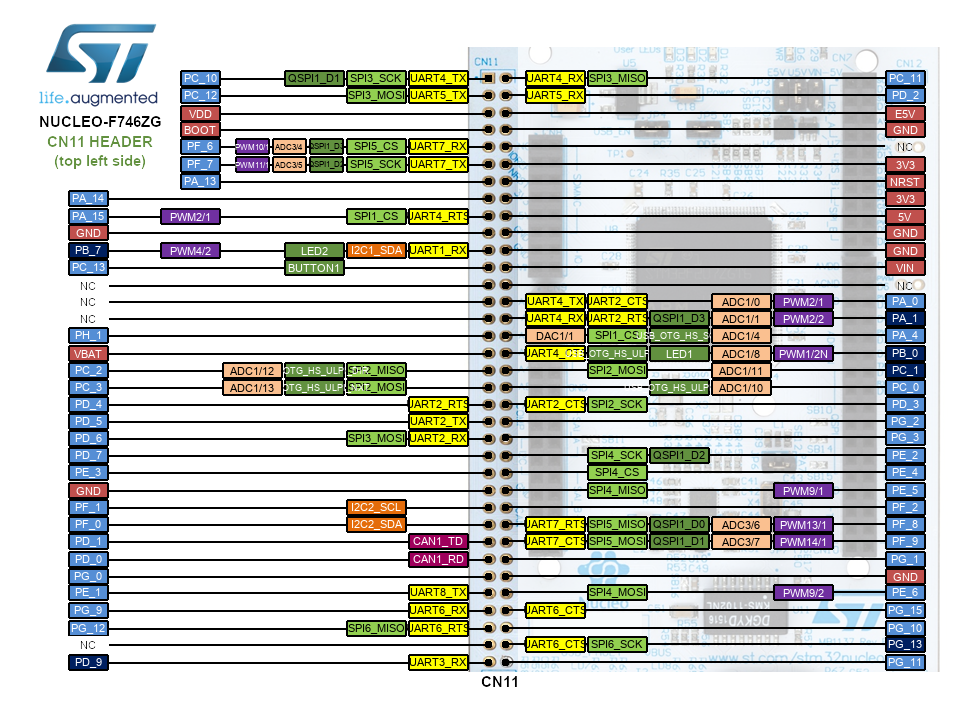
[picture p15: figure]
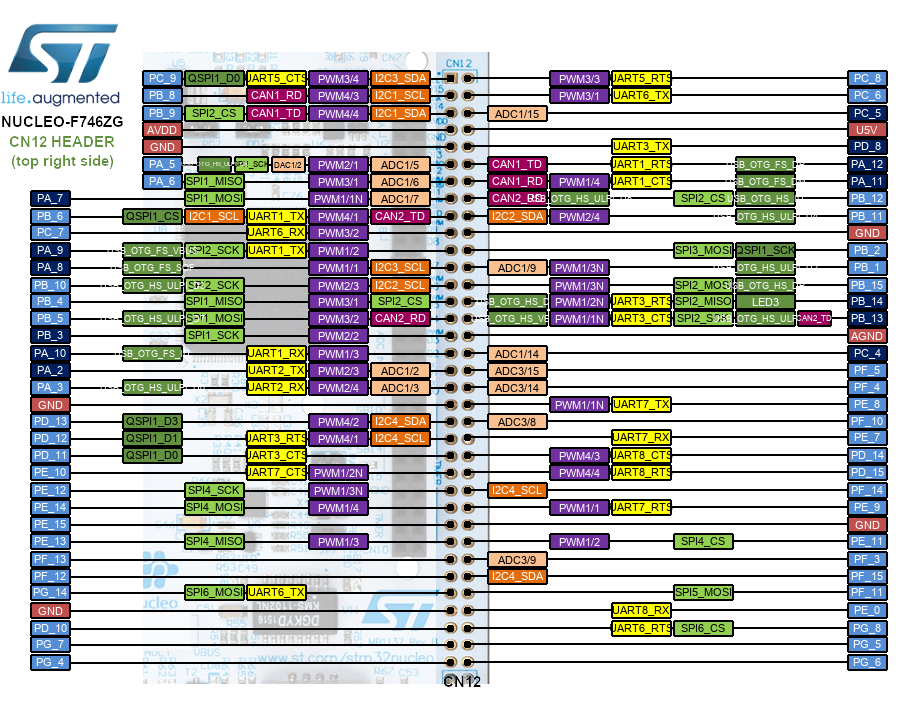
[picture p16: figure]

[3]: https://os.mbed.com/platforms/ST-Nucleo-F746ZG/#board-pinout

## Nucleo Board: Interface with Caravel

Nucleo Board: NUCLEO144-F746ZG
- CN4 jumpers in ST-Link part is used to program STM32 MCU
- The board is used as a test setup for characterizing the I/O configuration
- The board has a 3.3V Regulator (Max 500mA )
- Default clock supply is 8 MHz from ST-Link on PH0
- Caravel FLASH/HKSPI interface could be connected to STM32 MCU SPI interfaces
- Caravel UART interface could be connected to STM32 MCU interface
- PA13 and PA14 are shared with SWD signals connected to ST-LINK. If ST-LINK part is not cut, it is not recommended to use them as I/Os.

## Caravel + Nucleo Board Block Diagram

Nucleo-144 Board

USB Interface

ST Morpho Connectors

Adj Voltage regulator

D-POT+R Network

Flash Memory

PoR

Disable

5V

5V

I^2 C

MR

USB Interface

FTDI Voltage Regulator

5V

Voltage Regulator

V_3.3

V_1.8

Bridge

V_(out1)

V_(out2)

3.3V

Disable

1.8V

3.3V

V_(REF1)

V_(REF2)

FTDI

Caravel BB

SPI

HKSPI/IO [1:4]

IO [0:37] & FLASH

3.3V

UART

IO [5:6]

FLASH

SPI

3.3V

IO [0:37]

RST

3.3V

MR

UART_EN

Caravel Nucleo-Hat

## Caravel + Nucleo Board Schematic

Notes:
- Default clock is 8 MHz on PH0 and a timer could be used to supply the clock to caravel as a PWM signal for example, TIM3_CH2 on PB5
- Caravel FLASH connected to SPI4 ( PE2 PE4:PE6 )
- Caravel HKSPI to SPI5 ( PF6:PF9 )
- Caravel UART connected to UART8 ( PE0:PE1 )
- The manual reset MR is connected to PC12
- Caravel remaining 32 I/Os connected to ST Morpho pins that have no conflict on them and support the order of the breakout board pinout
- The supplies are connected to external pin header J10 with gpio , xclk and RST
- Nucleo Board: NUCLEO144-F746ZG
- Cravel Breakout Board: V2 breakout board with Caravel WCSP chip
- J4 connector is available to support connecting a serial display easily
- J10 connector is available to support testing the flash memory pins

## Caravel + Nucleo Board Schematic

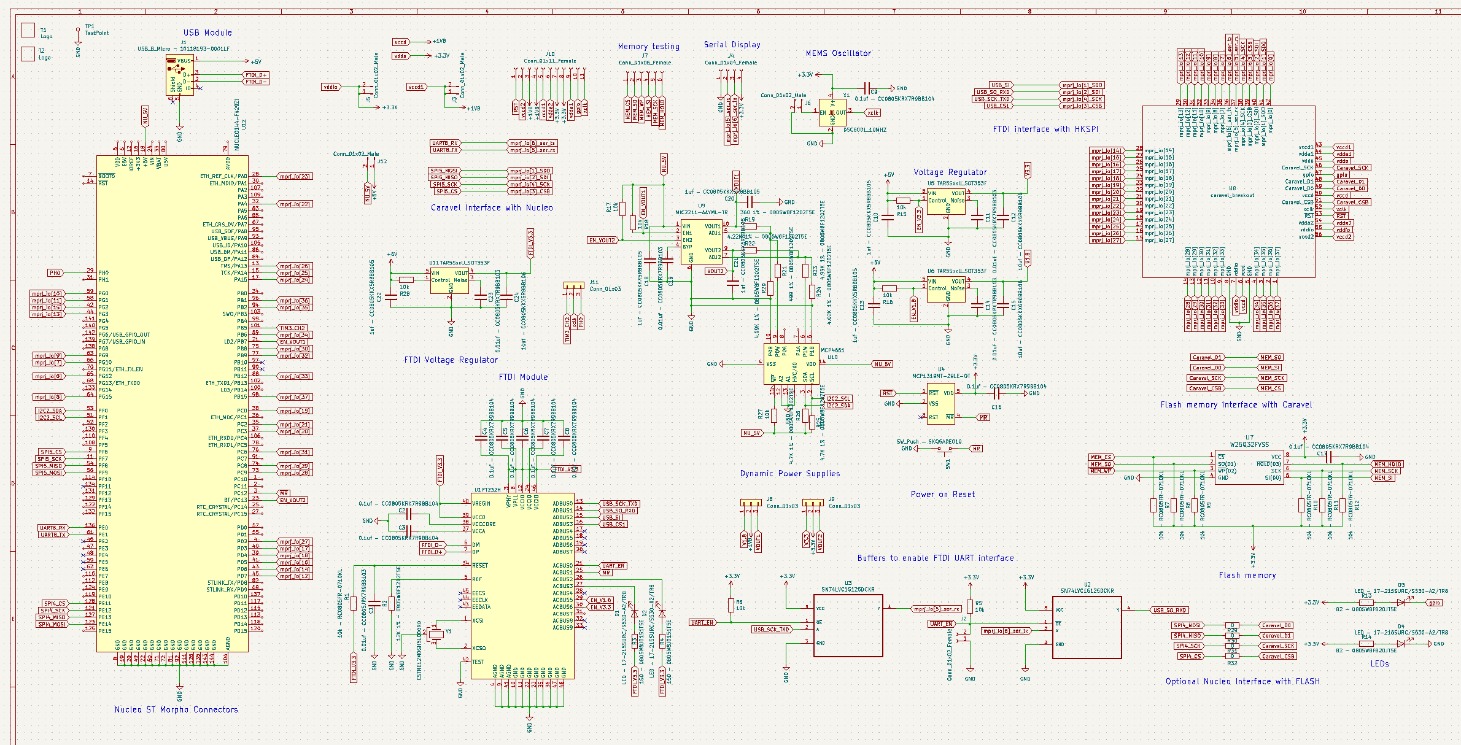
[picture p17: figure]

## Caravel + Nucleo Board Components

Component | Reference | Description
MCP1319MT-29LE-OT | U4 | Power on Reset (PoR) circuit with internal pull-up resistors
TAR5SxxU_SOT353F | U5 & U6 | Fixed voltage regulators that provide 1.8V and 3.3V . The footprint is the same for a wide range of LDO devices from 1.5V to 5V which allows installing 1.6V LDO in place of the 1.8V for example
MIC2211-AAYML-TR | U9 | Adjustable voltage regulator that is used to provide a programmable power supply by adjusting the resistors of each output. It is supplied with 5V from the Nucelo Board
MCP4661 | U10 | Digital Potentiometer that is programmed using I^2 C interface to provide desired resistive loads for U9 to achieve the programmable power supply. It also has an EEPROM which allows stand-alone operation after saving the desired values. It is supplied with 5V from the Nucelo Board
NUCLEO144-F429ZI | U11 | The Nucleo-144-F429ZI board ST Morpho connectors that has 144 pins interfacing with STM32 MCU

## Caravel + Nucleo Pinout

Caravel BB Pin | ST Morpho Pin
1: io[37] | 98: PB15
2: io[36] | 96: PB1
3: io[35] | 94: PB2
4: io[34] | 89: PB6
5: GND | GND
6: vccd | -
7: vddio | -
8: GND | GND
9: io[33] | 88: PB12
10: io[32] | 77: PB9
11: io[31] | 76: PC6
12: io[30] | 75: PB8
13: io[29] | 74: PC8
14: io[28] | 73: PC9

Caravel BB Pin | ST Morpho Pin
15: io[27] | 4: PD2
16: io[26] | 13: PA13
17: io[25] | 15: PA14
18: io[24] | 17: PA15
19: io[23] | 28: PA0
20: io[22] | 32: PA4
21: io[21] | 35: PC2
22: io[20] | 37: PC3
23: io[19] | 38: PC0
24: io[18] | 39: PD4
25: io[17] | 40: PD3
26: io[16] | 41: PD5
27: io[15] | 42: PG2
28: io[14] | 43: PD6

## Caravel + Nucleo Pinout

Caravel BB Pin | ST Morpho Pin
29: io[13] | 44: PG3
30: io[12] | 45: PD7
31: io[11] | 58: PG1
32: io[10] | 59: PG0
33: io[9] | 63: PG9
34: io[8] | 64: PG15
35: io[7] | 66: PG10
36: io[6]/tx | 136:PE0
37: io[5]/rx | 61: PE1
38: io[4]/SCK | 11: PF7
39: io[3]/CSB | 9: PF6
40: io[2]/SDI | 54: PF8
41: io[1]/SDO | 56: PF9
42: io[0] | 65: PG12

Caravel BB Pin | ST Morpho Pin
43: vccd1 | -
44: vdda1 | -
45: vdda | -
46: Caravel/SCK | 121: PE12
47: gpio | -
48: Caravel/D1 | 127: PE13
49: Caravel/D0 | 123: PE14
50: vccd | -
51: Caravel/CSB | 128: PE11
52: xclk | -
53: NRST | -
54: vdda2 | -
55: vddio | -
56: vccd2 | -

## Caravel + Nucleo Board Power Supply

Mode | Main Power | Power Domains | Jumper State | Components | Notes
HAT | Nucleo Board 5V | U9: 3.3V | J9: 2 to 3 ( HAT ) | Caravel, FLASH, buffers, X1 | Programmable
| | U9: 1.8V | J8: 2 to 3 ( HAT ) | Caravel | Programmable
MAIN | USB Module 5V | U5: 3.3V | J9: 2 to 1 ( MAIN ) | Caravel, FLASH, buffers, X1 | Fixed
| | U9: 3.3V | J9: 2 to 3 ( HAT ) J12: 1 to 2 ( NU_5V ) | Caravel, FLASH, buffers, X1 | Fixed: DVS saved setting
| | U11: 3.3V | − | FTDI
| | U6: 1.8V | J8: 2 to 1 ( MAIN ) | Caravel | Fixed
| | U9: 1.8V | J9: 2 to 3 ( HAT ) J12: 1 to 2 ( NU_5V ) | Caravel | Fixed: DVS saved setting

Both modes support supplying 3.3V and 1.8V externally through J10 pins and leaving J8 and J9 floating

## Caravel + Nucleo Board Reset

Mode | Reset Mechanism | Pin Activated
HAT | SW1 Push-Button | PoR: MR
| Nucleo Program configures PC12 | PoR: MR
| Externally through J10 | RESET
MAIN | SW1 Push-Button | PoR: MR
| FTDI Program configures ACBUS1 | PoR: MR
| Externally through J10 | RESET

## Caravel + Nucleo Board Modes

MAIN mode:
- The board is programmed through the USB module communicating with the FTDI.
- The 5V supply is provided from the USB module to power the fixed voltage supplies (U5 and U6) which in turn power up the other system components except for the programmable power supply.
- J8 and J9 are set to connect pin 2 to pin 1 ( MAIN ).
- J8 and J9 are left floating if the 3.3V and 1.8V are to be supplied externally.
- J11 is left with no connections as the clock is driven from X1 with 10MHz frequency.
- Other frequencies could be supported by disabling X1 through J6 and driving the clock externally.
- To reset the board, use SW1 button or FTDI ACBUS1 .
- By default, the FTDI interface with the Caravel HKSPI. To switch to the UART interface of Caravel, set UART_EN to 0 either using J2 or the FTDI ACBUS0
- To use the programmable power supplies saved setting instead of the fixed voltage supplies:
  1. connect pin 2 to pin 3 on J8 and J9 ( HAT ).
  2. connect J12 pins to provide the 5V supply to U9 and U10 (short 5V with NU_5V ).

## Caravel + Nucleo Board Modes

HAT mode:
- The board acts as a hat for Nucleo-144 test setup.
- The 5V supply is provided from the Nucleo board to power the programmable power supply (U9 and U10) which in turn power up the other system components except for the fixed power supply and the FTDI module.
- U10 is programmed from the Nucleo using I^2 C interface to provide the desired supplies
- J8 and J9 are set to connect pin 2 to pin 3 ( HAT ).
- The clock could be driven from the Nucleo through J11 with either of the following:
  1. connect pin 2 to pin 1 to drive it as a PWM signal generated from Timer 3.
  2. connect pin 2 to pin 3 to drive it from the default clock of the MCO output of ST-LINK with a fixed 8MHz frequency.
- \J6 is set to disable X1 in the case of driving the clock with J11.
- To reset the board, use the Nucleo to program PC12 or SW1 button.

## Caravel + Nucleo Board PCB

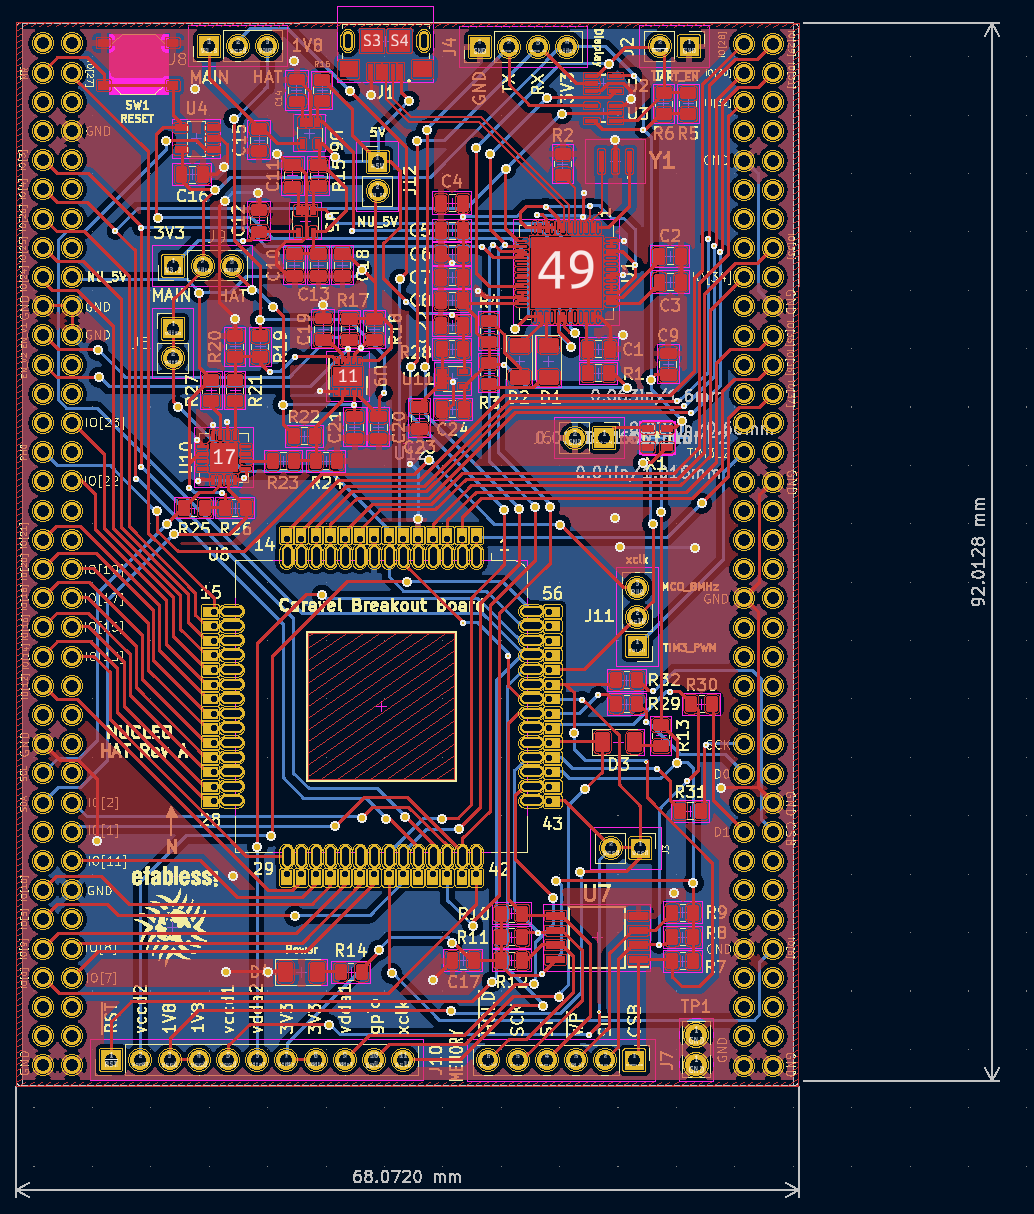
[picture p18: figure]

Dimensions:
68.072∗92.0128 mm^2

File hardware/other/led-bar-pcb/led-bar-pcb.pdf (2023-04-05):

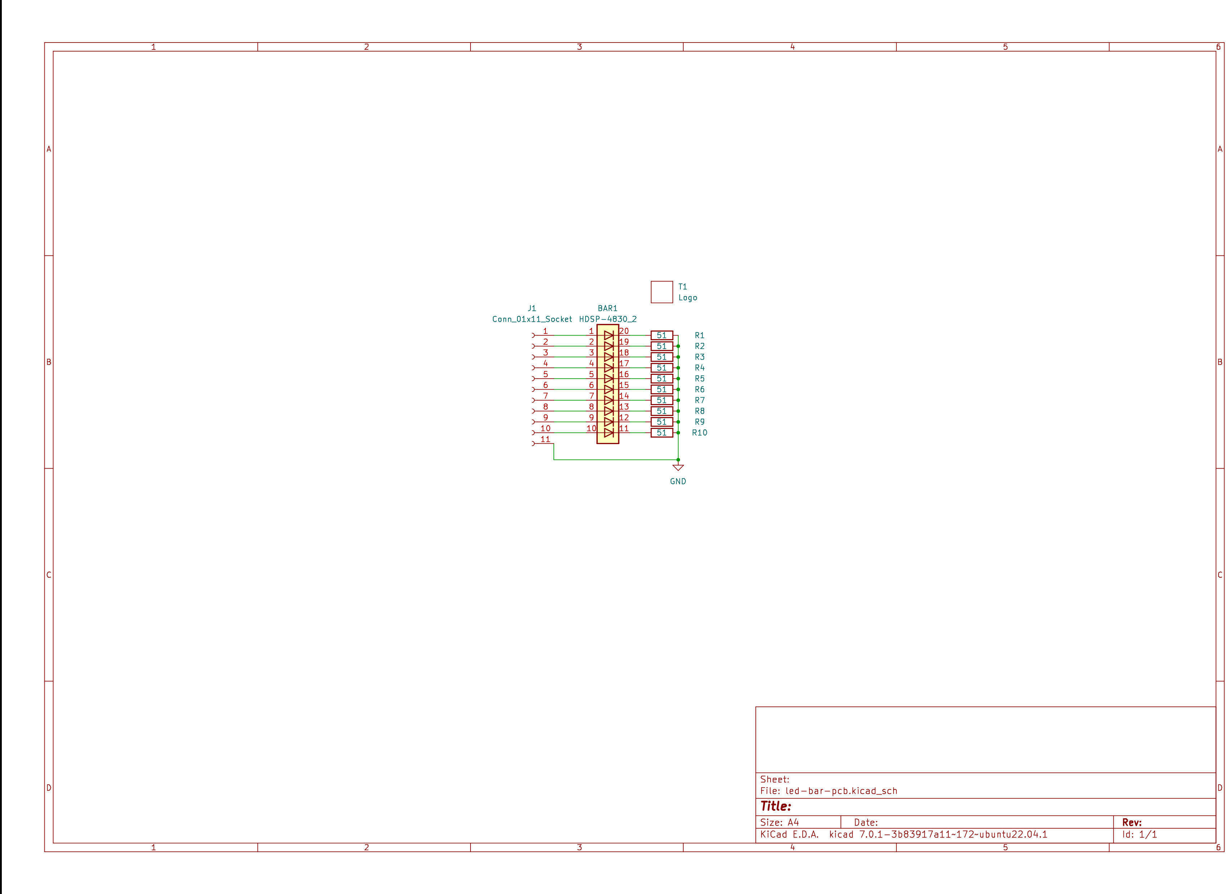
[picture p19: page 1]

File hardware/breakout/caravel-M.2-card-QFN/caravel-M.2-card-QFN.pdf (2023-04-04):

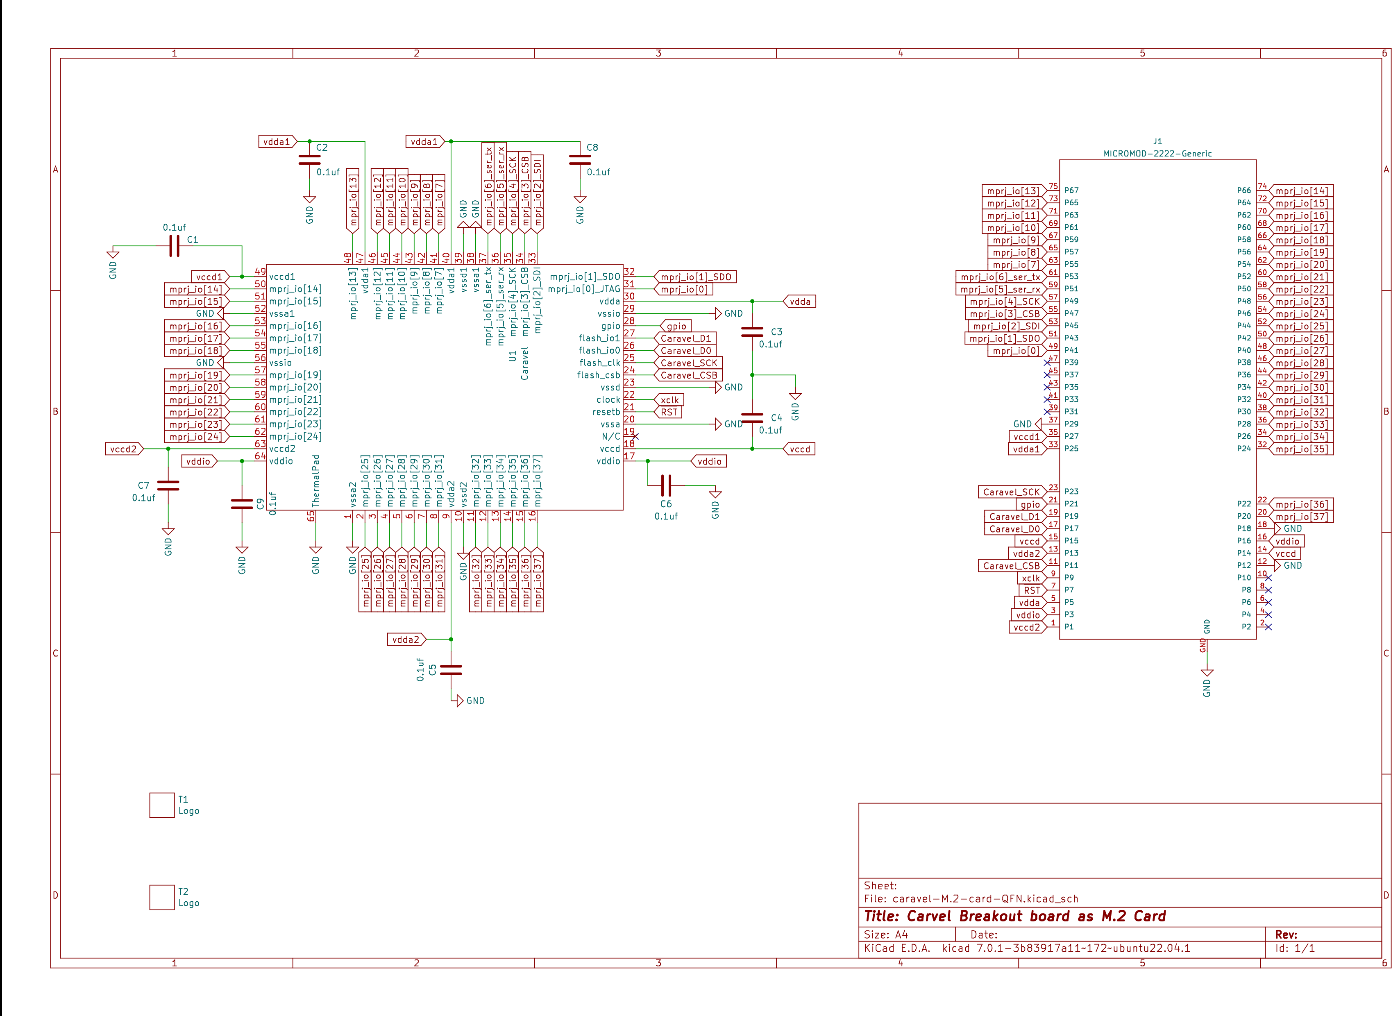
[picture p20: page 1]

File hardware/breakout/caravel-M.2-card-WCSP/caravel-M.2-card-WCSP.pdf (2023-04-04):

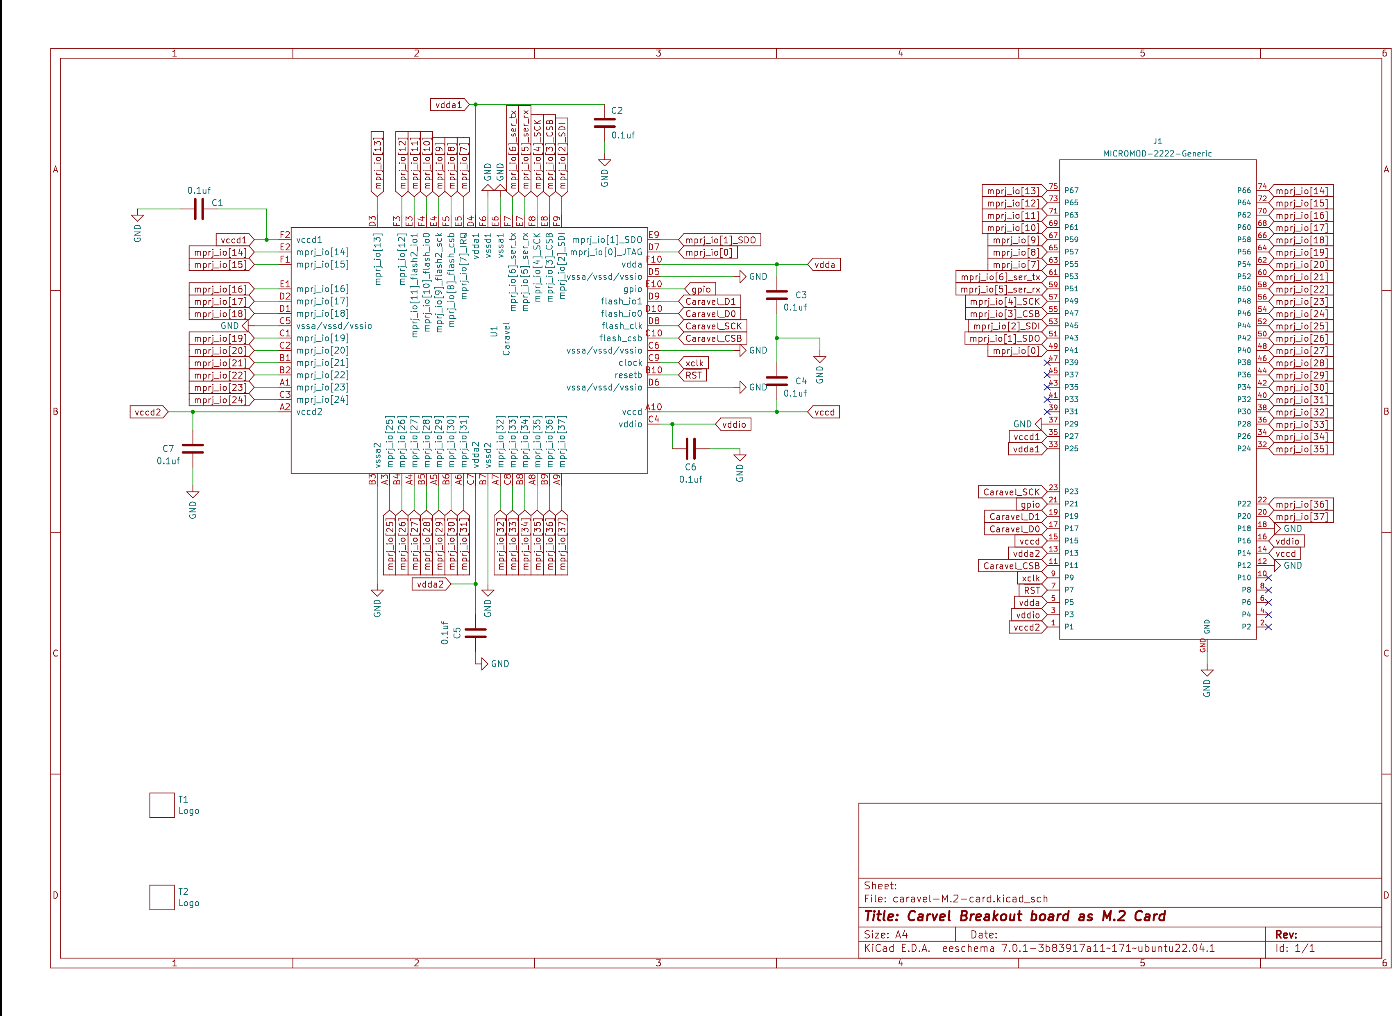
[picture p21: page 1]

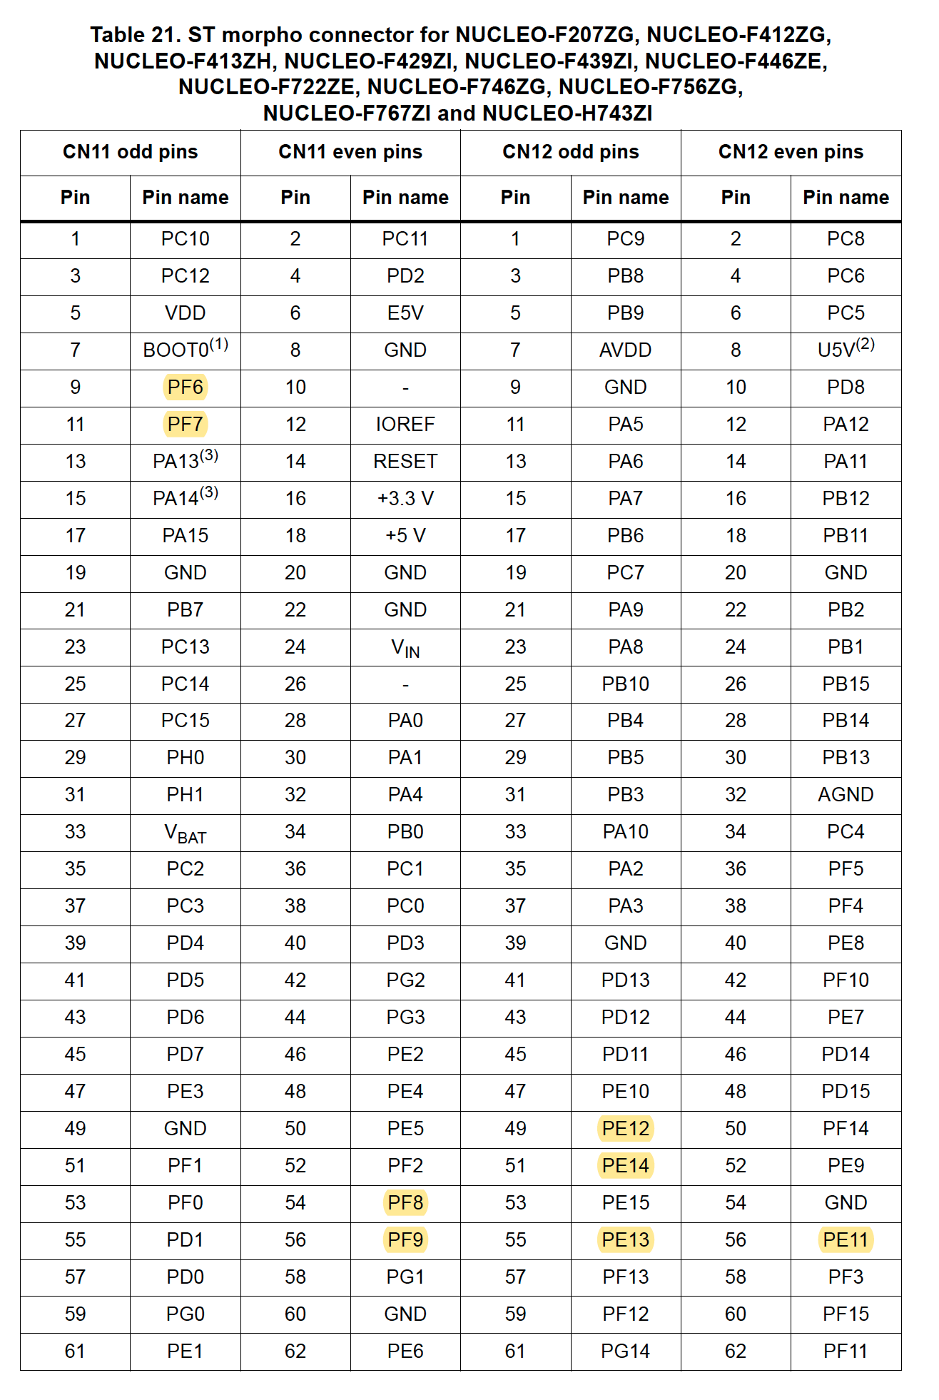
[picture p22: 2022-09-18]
firmware/mpw2-5/nucleo/docs/st_morpho_pinout.png

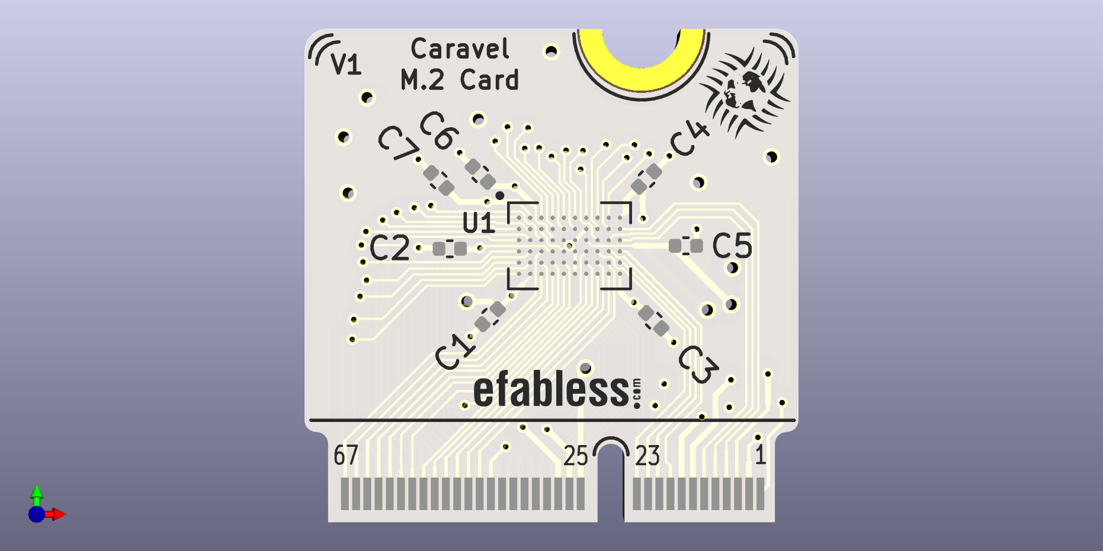
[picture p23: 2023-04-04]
hardware/breakout/caravel-M.2-card-WCSP/caravel-M.2-card-WCSP-front.png

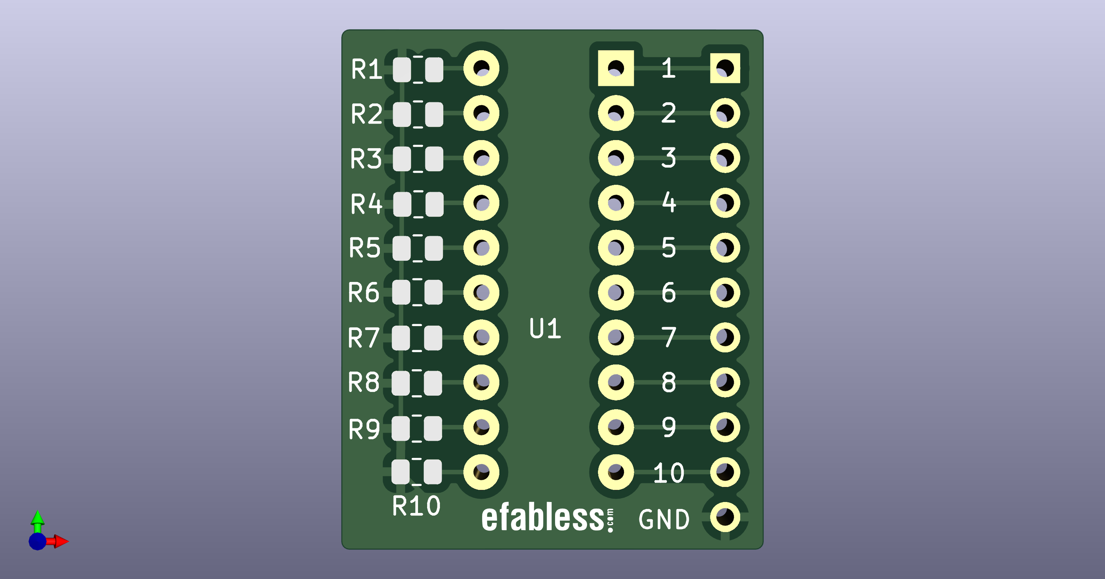
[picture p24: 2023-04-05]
hardware/other/led-bar-pcb/led-bar-pcb.png

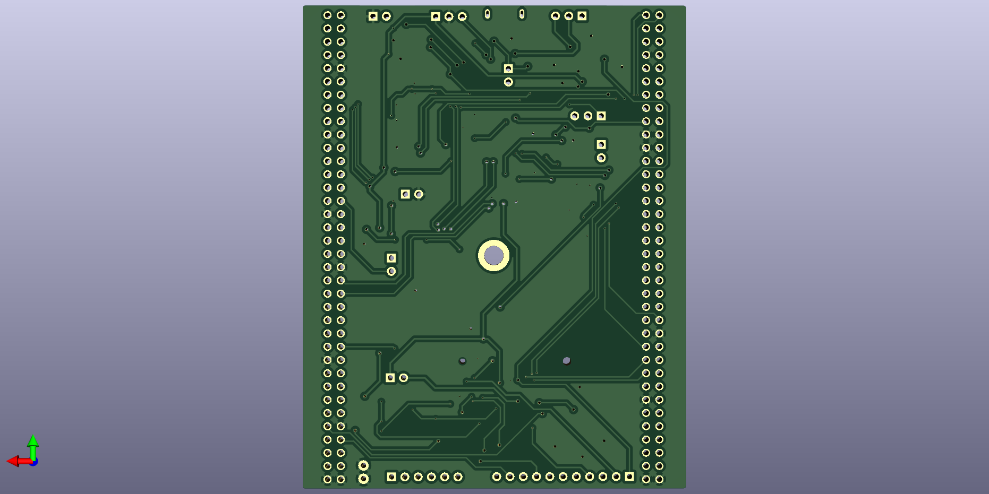
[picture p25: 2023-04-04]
hardware/nucleo/caravel-Nucleo-v2-M.2/caravel-Nucleo-v2-M.2-back.png

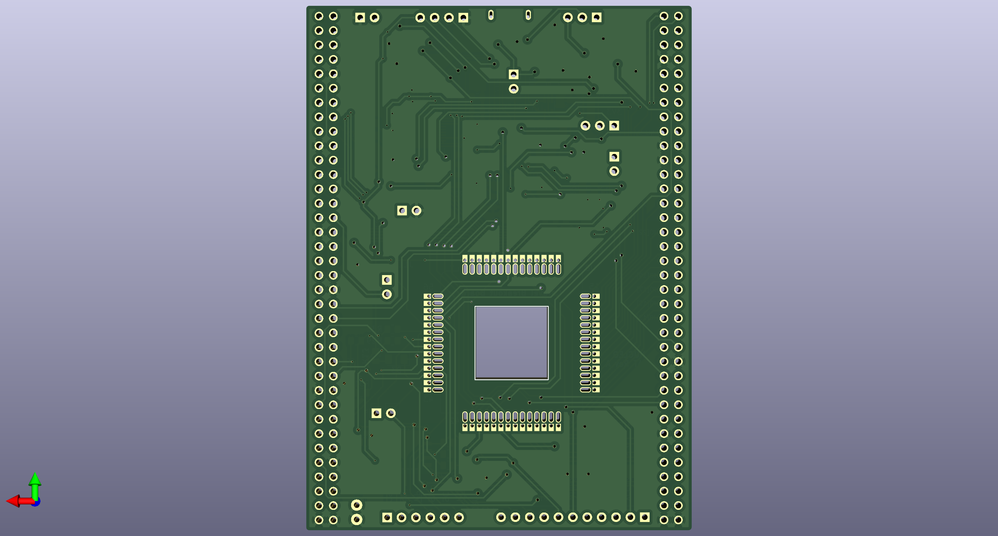
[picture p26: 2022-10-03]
hardware/nucleo/caravel_nucleo/caravel_Nucleo_back.png

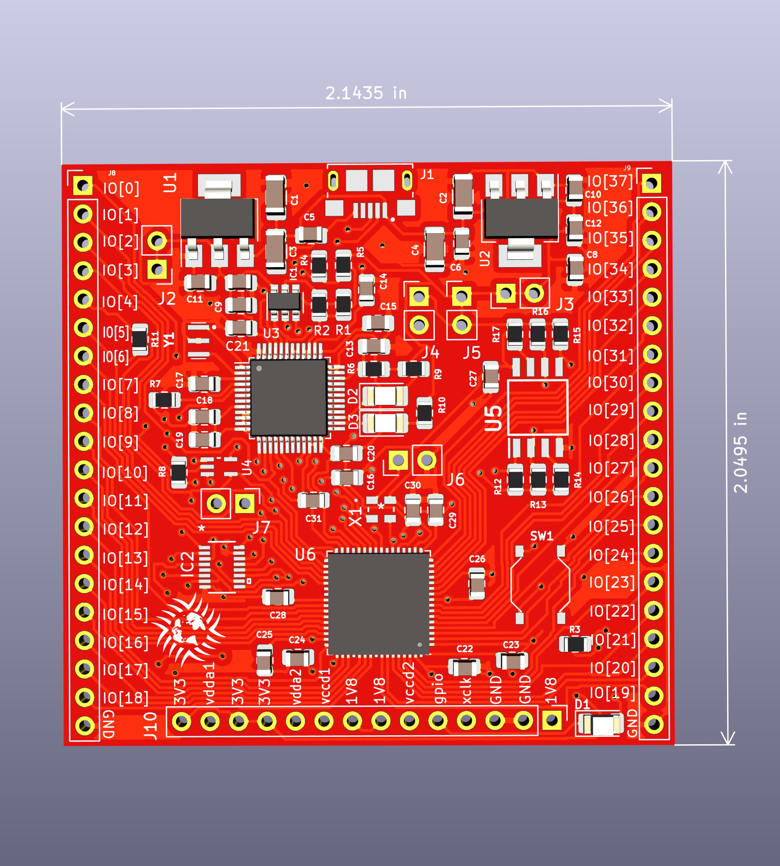
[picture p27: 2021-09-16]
hardware/development/caravel_pcb_v2/caravel_front.jpg

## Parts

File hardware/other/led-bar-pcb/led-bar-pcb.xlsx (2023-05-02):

Designators | QTY | Value | Part Number | Supplier
U1 | 1 |  | 10 Segment LED Bar (https://www.sparkfun.com/products/9938) | DK | NOTE - install on backside of PCB | https://www.digikey.com/en/products/detail/liteon/LTA-1000HR/153273?so=80794008&content=productdetail_US
R1-R10 | 10 | 51 | RC0805FR-0751RL (https://www.digikey.com/en/products/detail/yageo/RC0402FR-0751RL/726629) | DK | https://www.digikey.com/en/products/detail/yageo/RC0805FR-0751RL/728012
Connector/11 pin male header | 1 |  | https://www.amazon.com/Header-Lystaii-Pin-Connector-Electronic/dp/B06ZZN8L9S?s=industrial | Amazon | NOTE - install on backside of PCB
Mating wire connectors | 2 |  | https://www.amazon.com/DiGiYes-120pcs-Breadboard-Jumper-Multicolored/dp/B0BKW5Y6X5?s=industrial | Amazon | NOTE - mating jumpers wire Female to Female

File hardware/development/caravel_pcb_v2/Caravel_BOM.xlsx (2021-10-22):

Designators | QTY | Value | Part Number | Supplier
U6 | 1 |  | Caravel | EF
U5 | 1 |  | W25Q32JVSSIQ | DK
U4 | 1 |  | SN74LVC1G125DCKT | Mouser | alternative part
U3 | 1 |  | FT232H | not stocked
U2 | 1 |  | NCP1117LPST33T3G | DK | alternative part
U1 | 1 |  | AZ1117CH-1.8TRG1 | DK
IC1 | 0 |  | 93C56 | don't install
IC2 | 0 |  | TMUX1574DYYR | not stocked
D1, D2, D3 | 3 |  | LTST-C230KRKT | DK
C1, C2, C3, C4 | 4 | 100u | GMC31X5R107M6R3NT (https://www.digikey.com/en/products/detail/cal-chip-electronics-inc/GMC31X5R107M6R3NT/12140450) | DK | GMC31X5R107M6R3NT (https://www.digikey.com/en/products/detail/cal-chip-electronics-inc/GMC31X5R107M6R3NT/12140450)
C5, C6, C9, C10 | 4 | 10u | CC0805KKX5R8BB106 | DK
C7, C8 | 2 | 22u | CC0805MKX5R5BB226 | DK
C11, C12 | 2 | 1u | CC0805KKX7R8BB105 | DK
C14-C31 | 18 | 0.1u | CC0805KRX7R9BB104 | DK
C13 | 1 | 0.01u | CC0805JRX7R9BB103 | DK
R1, R2, R5, R6, R8, R12-R17 | 11 | 10K | RC0805FR-0710KL | DK
R7 | 1 | 12K, 1% | RMCF0805FT12K0 | DK
R9, R10 | 2 | 150 | RNCP0805FTD150R | DK
R3 | 1 | 82 | RMCF0805FT82R0 | DK
R4 | 1 | 2K | RMCF0805FT2K00 | DK
R11 | 1 | 0 | RK73Z2ATTD | DK
J1 | 1 |  | 10118193-0001LF | DK
X1 | 1 | 10MHz | DSC6001JE1A-010.0000 | DK
Y1 | 1 | 12MHz | CSTNE12M0GH5L000R0 | Mouser

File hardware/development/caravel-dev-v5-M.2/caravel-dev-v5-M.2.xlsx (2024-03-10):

 | Manufacturer Part Number | Qty | Designator | Value | Customer Supply | Customer Remark | Supplier | Note | Va
1 | FT232HQ (https://www.digikey.com/en/products/detail/ftdi-future-technology-devices-international-ltd/FT232HQ-REEL/2614626) | 1 | U1 |  | N |  | DigiKey
2 | SN74LVC1G125DCKT (https://eu.mouser.com/ProductDetail/Texas-Instruments/SN74LVC1G125DCKT?qs=pajgIaoyDUhOMyeC25ASaQ%3D%3D) | 2 | U2, U3 |  | N |  | Mouser | alternative part
3 | TAR5S33UTE85LF (https://www.digikey.com/en/products/detail/toshiba-semiconductor-and-storage/TAR5S33UTE85LF/4304965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) | 1 | U5 |  | N |  | DigiKey
4 | TAR5S18U (https://www.digikey.com/en/products/detail/toshiba-semiconductor-and-storage/TAR5S18U-TE85L-F/10379931) | 1 | U6 |  | N |  | DigiKey | 1.8v
5 | W25Q32JVSSIQ (https://www.digikey.com/en/products/detail/winbond-electronics/W25Q32JVSSIQ/5803981) | 1 | U7 |  | N |  | DigiKey
6 | M.2 E connector (https://www.sparkfun.com/products/16549) | 1 | U8 |  | N |  | SparkFun | alternative part (https://www.digikey.com/en/products/detail/te-connectivity-amp-connectors/2199230-4/4208915)
7 | APT3216SURCK (https://www.digikey.com/en/products/detail/kingbright/APT3216SURCK/1747542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) | 4 | D1, D2, D3, D4 |  | N |  | DigiKey
8 | CL21B106KAYQNNE (https://www.mouser.com/ProductDetail/Samsung-Electro-Mechanics/CL21B106KAYQNNE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) | 4 | C12, C15, C16, C22 | 10u | N |  | DigiKey
9 | 885012207103 (https://www.mouser.com/ProductDetail/Wurth-Elektronik/885012207103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) | 3 | C10, C13, C19 | 1u | N |  | DigiKey
10 | C0805C104K5RAC7411 (https://www.mouser.com/ProductDetail/KEMET/C0805C104K5RAC7411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) | 10 | C2-C9, C18, C21 | 0.1u | N |  | DigiKey
11 | C0805C103K5RAC7411 (https://www.mouser.com/ProductDetail/KEMET/C0805C103K5RAC7411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) | 5 | C1, C11, C14, C17, C20 | 0.01u | N |  | DigiKey
12 | RC0805FR-0710KL (https://www.digikey.com/en/products/detail/yageo/RC0805FR-0710KL/727535) | 9 | R1, R7-R10, R12, R13, R15, R16 | 10K | N |  | DigiKey
13 | RMCF0805FT12K0 (https://www.digikey.com/en/products/detail/stackpole-electronics-inc/RMCF0805FT12K0/1760674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) | 1 | R2 | 12K, 1% | N |  | DigiKey
14 | RNCP0805FTD150R (https://www.digikey.com/en/products/detail/stackpole-electronics-inc/RNCP0805FTD150R/2240211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) | 2 | R3, R4 | 150 | N |  | DigiKey
15 | RC0805FR-071KL (https://www.digikey.com/en/products/detail/yageo/RC0805FR-071KL/727444) | 4 | R5, R6, R11, R14 | 1K | N |  | DigiKey
16 | 7427920415 (https://www.digikey.com/en/products/detail/würth-elektronik/7427920415/1639009) | 1 | FB1 | 600R @ 100MHz | N |  | DigiKey
17 | 10118193-0001LF (https://www.digikey.com/en/products/detail/amphenol-cs-fci/10118193-0001LF/2785388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) | 1 | J1 |  | N |  | DigiKey
18 | DSC6001JI1B-010.0000 (https://www.microchipdirect.com/product/DSC6001JI1B-010.0000) | 1 | X1 | 10MHz | N |  | Microchip
19 | CSTNE12M0GH5L000R0 (https://www.digikey.com/en/products/detail/murata-electronics/CSTNE12M0GH5L000R0/8747728) | 1 | Y1 | 12MHz | N |  | DigiKey
20 | 36-5000-ND (https://www.digikey.com/en/products/detail/keystone-electronics/5000/255326) | 2 | TP1, TP2 |  | N |  | DigiKey
21 | SKQGADE010 (https://www.mouser.com/ProductDetail/Alps-Alpine/SKQGADE010?qs=N5Jky1br14PCAY42dbciFw%3D%3D) | 1 | SW1 |  | N |  | Mouser
22 | HDR100IMP40M-G-V-TH (https://www.mouser.com/ProductDetail/Chip-Quik/HDR100IMP40M-G-V-TH?qs=Wj%2FVkw3K%252BMBASWNGaQOKpg%3D%3D) | 2 | J10, J11 |  | N |  | Mouser | Loose Part
23 | Standoff (https://www.sparkfun.com/products/16549) | 1 | H1 |  | N |  |  | alternative part (https://www.digikey.com/en/products/detail/würth-elektronik/9774025151R/5320621?s=N4IgTCBcDaIJwHYEBYAMYCsBGbAlEAugL5A)
 | Screw (https://www.sparkfun.com/products/16549) | 1 |  |  |  |  |  | alternative part (https://accu-components.com/us/phillips-pan-head-screws/65385-SIP-M2-5-3-A2)

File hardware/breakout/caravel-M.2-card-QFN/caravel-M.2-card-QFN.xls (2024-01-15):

Designator | Qty | Value | Part number | Vendor
C1, C2, C3, C4, C5, C6, C7, C8, C9 | 9 | 0.1uf | CC0402KRX7R9BB104 | DK
U1, | 1 | Caravel |  | Customer provided

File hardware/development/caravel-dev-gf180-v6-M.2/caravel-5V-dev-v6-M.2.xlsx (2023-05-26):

Designators | QTY | Value | Part Number | Supplier
U1 | 1 |  | FT232HQ | not stocked
U2, U3 | 2 |  | SN74LVC1G125DCKT (https://eu.mouser.com/ProductDetail/Texas-Instruments/SN74LVC1G125DCKT?qs=pajgIaoyDUhOMyeC25ASaQ%3D%3D) | Mouser | alternative part
U4 | 1 |  | MCP1319MT-29LE/OT (https://www.digikey.com/en/products/detail/microchip-technology/MCP1319MT-29LE-OT/964270) | DK
U5 | 1 |  | TAR5S33UTE85LF (https://www.digikey.com/en/products/detail/toshiba-semiconductor-and-storage/TAR5S33UTE85LF/4304965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) | DK
U6, U9, U10, U11, U12 | 5 |  | SN74LV1T34DCKR (https://www.mouser.com/ProductDetail/Texas-Instruments/SN74LV1T34DCKR?qs=8sOby8ZxZLGjFfifrzzjkQ%3D%3D) | Mouser
U7 | 1 |  | W25Q32JVSSIQ (https://www.digikey.com/en/products/detail/winbond-electronics/W25Q32JVSSIQ/5803981) | DK
U8 | 1 |  | M.2 E connector (https://www.sparkfun.com/products/16549) | SparkFun
D1, D2, D3, D4 | 4 |  | LTST-C230KRKT (https://www.digikey.com/en/products/detail/liteon/LTST-C230KRKT/386857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) | DK
C12. C19, C20 | 3 | 10u | CL21B106KAYQNNE (https://www.mouser.com/ProductDetail/Samsung-Electro-Mechanics/CL21B106KAYQNNE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) | Mouser
C10, C18 | 2 | 1u | 885012207103 (https://www.mouser.com/ProductDetail/Wurth-Elektronik/885012207103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) | Mouser
C2-C9, C14-C16,C21-C23 | 14 | 0.1u | C0805C104K5RAC7411 (https://www.mouser.com/ProductDetail/KEMET/C0805C104K5RAC7411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) | Mouser
C1, C11, C13, C17 | 4 | 0.01u | C0805C103K5RAC7411 (https://www.mouser.com/ProductDetail/KEMET/C0805C103K5RAC7411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) | Mouser
R7, R8, R10, R11, R20 | 5 | 100K | RC0805FR-07100KL (https://www.digikey.com/en/products/detail/yageo/RC0805FR-07100KL/727544) | DK
R1, R5, R6, R9, R12-R17, R19 | 11 | 10K | RC0805FR-0710KL (https://www.digikey.com/en/products/detail/yageo/RC0805FR-0710KL/727535) | DK
R2 | 1 | 12K, 1% | RMCF0805FT12K0 (https://www.digikey.com/en/products/detail/stackpole-electronics-inc/RMCF0805FT12K0/1760674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) | DK
R18 | 1 | 2K | RC0805FR-072KL (https://www.digikey.com/en/products/detail/yageo/RC0805FR-072KL/727664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) | DK
R3, R4 | 2 | 150 | RNCP0805FTD150R (https://www.digikey.com/en/products/detail/stackpole-electronics-inc/RNCP0805FTD150R/2240211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) | DK
J1 | 1 |  | 10118193-0001LF (https://www.digikey.com/en/products/detail/amphenol-cs-fci/10118193-0001LF/2785388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) | DK
X1 | 1 | 10MHz | SG7050CCN-10-000000M-HJGA3 (https://www.digikey.com/en/products/detail/epson/SG7050CCN-10-000000M-HJGA3/5260767) | DK
Y1 | 1 | 12MHz | CSTNE12M0GH5L000R0 (https://www.digikey.com/en/products/detail/murata-electronics/CSTNE12M0GH5L000R0/8747728) | DK
TP1, TP2 | 2 |  | 36-5000-ND (https://www.digikey.com/en/products/detail/keystone-electronics/5000/255326) | DK
FB1 | 1 | 600R @ 100MHz | 7427920415 (https://www.digikey.com/en/products/detail/würth-elektronik/7427920415/1639009) | DK
SW1 | 1 |  | SKQGADE010 (https://www.mouser.com/ProductDetail/Alps-Alpine/SKQGADE010?qs=N5Jky1br14PCAY42dbciFw%3D%3D) | Mouser | Alps Alpine
Q1 | 1 |  | IRLML6402TRPBF (https://www.digikey.com/en/products/detail/infineon-technologies/IRLML6402TRPBF/811437) | DK

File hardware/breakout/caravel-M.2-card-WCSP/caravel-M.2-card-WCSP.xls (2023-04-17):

Designator | Qty | Value | Part number | Vendor
C1, C2, C3, C4, C5, C6, C7, | 7 | 0.1uf | CC0402KRX7R9BB104 | DK
U1, | 1 | Caravel |  | Customer provided

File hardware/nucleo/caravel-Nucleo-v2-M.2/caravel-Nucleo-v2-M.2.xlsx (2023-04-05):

Designators | QTY | Value | Part Number | Supplier
U1 | 1 |  | FT232HQ | not stocked
U2, U3 | 2 |  | SN74AUP1G125DCKT (https://www.digikey.com/en/products/detail/texas-instruments/SN74AUP1G125DCKT/1569032) | DK | alternative part
U4 | 1 |  | MCP1319MT-26EE/OT (https://www.digikey.com/en/products/detail/microchip-technology/MCP1319MT-26EE-OT/6244344) | DK
U5, U11 | 2 |  | TAR5S33UTE85LF (https://www.digikey.com/en/products/detail/toshiba-semiconductor-and-storage/TAR5S33UTE85LF/4304965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) | DK
U6 | 0 |  | TAR5S18UTE85LF (https://www.digikey.com/en/products/detail/toshiba-semiconductor-and-storage/TAR5S18U-TE85L-F/10379931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) | DK
U6 | 1 |  | TAR5S16UTE85LF (https://www.digikey.com/en/products/detail/toshiba-semiconductor-and-storage/TAR5S16U-TE85L-F/10379930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) | DK
U7 | 1 |  | W25Q32JVSSIQ (https://www.digikey.com/en/products/detail/winbond-electronics/W25Q32JVSSIQ/5803981) | DK
U8 | 1 |  | M.2 E connector (https://www.sparkfun.com/products/16549) | SparkFun
U9 | 1 |  | MIC2211-AAYML-TR (https://www.digikey.com/en/products/detail/microchip-technology/MIC2211-AAYML-TR/1028247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) | DK
U10 | 1 |  | MCP4661T-103E/ML (https://www.digikey.com/en/products/detail/microchip-technology/MCP4661T-103E-ML/2059724) | DK
D1, D2, D3, D4 | 4 | RED | LTST-C230KRKT (https://www.digikey.com/en/products/detail/liteon/LTST-C230KRKT/386857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) | DK
C12, C15, C24 | 3 | 10u | CC0805KKX5R8BB106 (https://www.digikey.com/en/products/detail/yageo/CC0805KKX5R8BB106/5195275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) | DK
C10, C13, C18, C20-C22 | 6 | 1u | CC0805KKX7R7BB105 (https://www.digikey.com/en/products/detail/yageo/CC0805KKX7R7BB105/2103103) | DK
C2-C9, C16, C17 | 10 | 0.1u | CC0805KRX7R9BB104 (https://www.digikey.com/en/products/detail/yageo/CC0805KRX7R9BB104/302874) | DK
C1, C11, C14, C19, C23 | 5 | 0.01u | CC0805JRX7R9BB103 (https://www.digikey.com/en/products/detail/yageo/CC0805JRX7R9BB103/5195264) | DK
R1, R5-R12, R15-R18, R27, R28 | 15 | 10K | RC0805FR-0710KL (https://www.digikey.com/en/products/detail/yageo/RC0805FR-0710KL/727535) | DK
R2 | 1 | 12K, 1% | RMCF0805FT12K0 (https://www.digikey.com/en/products/detail/stackpole-electronics-inc/RMCF0805FT12K0/1760674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) | DK
R20, R23 | 2 | 4.99K | RC0805FR-074K99L (https://www.digikey.com/en/products/detail/yageo/RC0805FR-074K99L/727938) | DK
R22 | 1 | 4.22K | RC0805FR-074K22L (https://www.digikey.com/en/products/detail/yageo/RC0805FR-074K22L/727913) | DK
R25, R26 | 2 | 4.7K | RC0805FR-134K7L (https://www.digikey.com/en/products/detail/yageo/RC0805FR-134K7L/13694180) | DK
R24 | 1 | 4.02K | RC0805FR-074K02L (https://www.digikey.com/en/products/detail/yageo/RC0805FR-074K02L/727907) | DK
R21 | 1 | 499 | RC0805FR-07499RL (https://www.digikey.com/en/products/detail/yageo/RC0805FR-07499RL/727986) | DK
R19 | 1 | 360 | RC0805FR-07360RL (https://www.digikey.com/en/products/detail/yageo/RC0805FR-07360RL/727886) | DK
R3, R4 | 2 | 150 | RNCP0805FTD150R (https://www.digikey.com/en/products/detail/stackpole-electronics-inc/RNCP0805FTD150R/2240211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) | DK
R13, R14 | 2 | 82 | RMCF0805FT82R0 (https://www.digikey.com/en/products/detail/stackpole-electronics-inc/RMCF0805FT82R0/1713389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) | DK
R29-R33 | 5 | 0 | RC0805JR-070RL (https://www.digikey.com/en/products/detail/yageo/RC0805JR-070RL/728216) | DK
J1 | 1 |  | 10118193-0001LF (https://www.digikey.com/en/products/detail/amphenol-cs-fci/10118193-0001LF/2785388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) | DK
X1 | 1 | 10MHz | DSC6001JE1A-010.0000 (https://www.digikey.com/en/products/detail/microchip-technology/DSC6001JE1A-010-0000/7732720) | DK
Y1 | 1 | 12MHz | CSTNE12M0GH5L000R0 (https://www.digikey.com/en/products/detail/murata-electronics/CSTNE12M0GH5L000R0/8747728) | DK
TP1 | 1 |  | 36-5000-ND (https://www.digikey.com/en/products/detail/keystone-electronics/5000/255326) | DK
SW1 | 1 |  | SKQGADE010 (https://www.mouser.com/ProductDetail/Alps-Alpine/SKQGADE010?qs=N5Jky1br14PCAY42dbciFw%3D%3D) | mouser | Alps Alpine
J8, J9 | 2 | 3-pin straight header | 77311-118-03LF (https://www.digikey.com/en/products/detail/amphenol-cs-fci/77311-118-03LF/1523655) | DK
UNMARKED - connectors on board edge | 2 | 70-pin 2-row socket | SSQ-126-23-G-D (https://www.mouser.com/ProductDetail/Samtec/SSQ-126-23-G-D?qs=rU5fayqh%252BE0GmdCetm0Big%3D%3D) | mouser | NOTE - install on backside of PCB

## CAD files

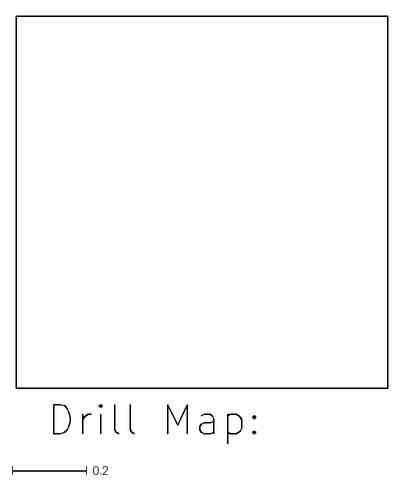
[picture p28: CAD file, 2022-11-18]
hardware/breakout/caravel_breakout_QFN/gerbers/caravel_breakout_QFN-NPTH-drl_map.dxf
1.00 x 1.15

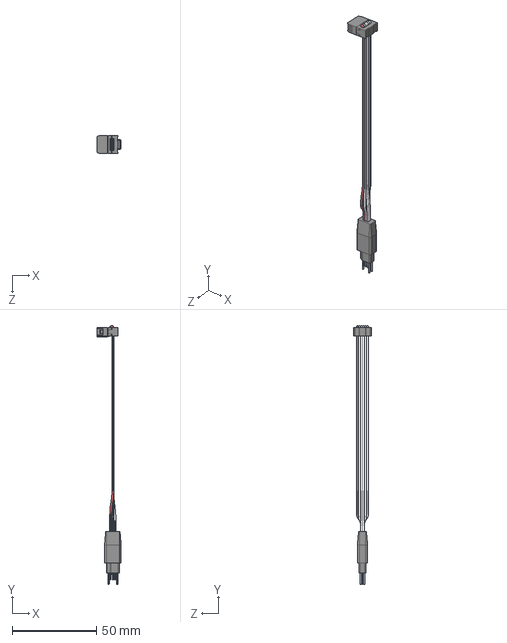
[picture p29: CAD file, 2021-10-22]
hardware/breakout/caravel_daughter/TC2030-IDC-NL/TC2030-IDC-NL.step
14.5 x 153.6 x 10.7 mm

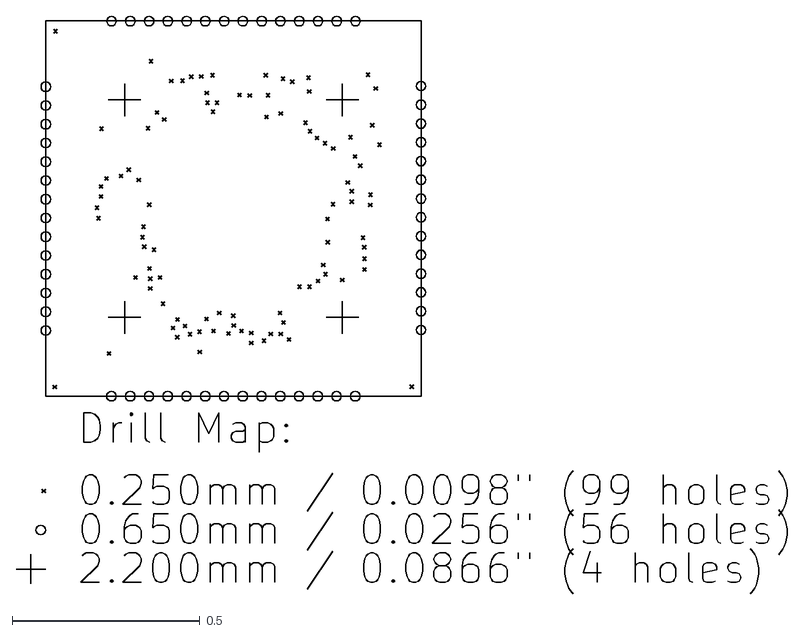
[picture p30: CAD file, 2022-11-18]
hardware/breakout/caravel_breakout_QFN/gerbers/caravel_breakout_QFN-PTH-drl_map.dxf
2.05 x 1.54

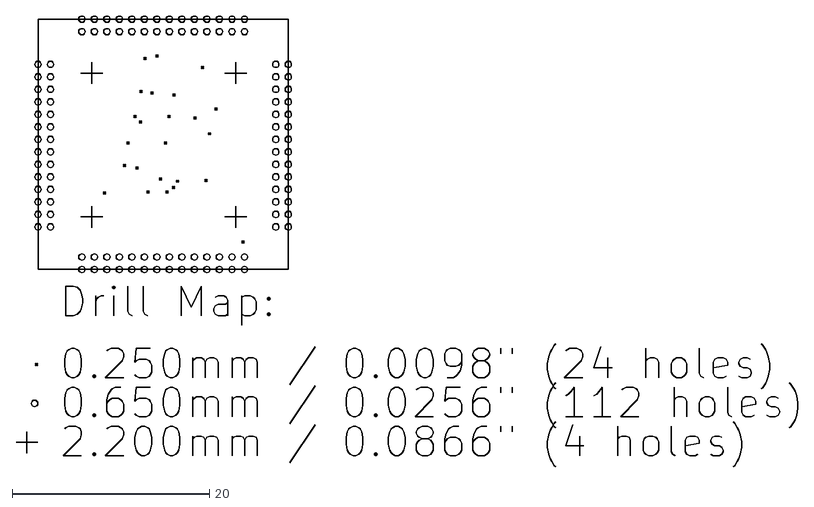
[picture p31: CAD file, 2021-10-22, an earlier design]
hardware/breakout/_archive/caravel_breakout_v1/gerbers/Caravel_breakout-drl_map.dxf
79.4 x 45.8

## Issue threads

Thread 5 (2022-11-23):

There's no clear starting place to get going with the board

QuantamHD, 2022-11-23:
There should be a single page where users can go that says do X, Y, and Z. The video shared doesn't show any of the setup.

https://www.youtube.com/watch?v=76hmGHJMyYs

jeffdi, 2022-12-01:
Please see https://github.com/efabless/caravel_board/blob/main/firmware_vex/nucleo/README.md

Does this provide what is needed?

mguthaus, 2023-01-20:
Can we add a "hello world" to this such as blinking an LED with micropython?

jeffdi, 2023-02-01:
created a ticket for the hello world request.  please create a new issue if there is still missing info.

Closed 2023-02-01.

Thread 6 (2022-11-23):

Flexy pin instructions are not super clear

QuantamHD, 2022-11-23:
should link to the documentation somewhere. https://www.solder.party/docs/flexypin/soldering/
You could easily miss the QR code on the package.

jeffdi, 2023-02-08:
User do not need to solder FlexyPins.  Will create video demonstrating insert of board into socket.

Closed 2023-02-08.

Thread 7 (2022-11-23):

The alignment of the cavael PCB and test board should be made clear.

QuantamHD, 2022-11-23:
I see that there are numbers in the corners that line up on both PCBs. Call this out in the documentation.

jeffdi, 2022-12-01:
See notes added to https://github.com/efabless/caravel_board/blob/main/firmware_vex/nucleo/README.md

jeffdi, 2023-02-08:
Added documentation for orienting the hat with Nucleo.

Closed 2023-02-08.

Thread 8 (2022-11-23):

PCB Header pin installation unclear.

QuantamHD, 2022-11-23:
What header pins should be installed in which board?

jeffdi, 2023-02-08:
User no longer need to install headers.

Closed 2023-02-08.

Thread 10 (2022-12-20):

auto detect correct serial port for repl and flashing

mattvenn, 2022-12-20:
there is too much room for error with the makefiles and mount points

perhaps mount points stay the same but it's very common for the serial ports to change names, especially as I have to unplug and replug the board every time I try to use it

so better to detect which is the correct port and set it automatically

jeffdi, 2023-02-08:
the PATH is automatically set.  the mount point still needs to be set by the user.

Closed 2023-02-09.

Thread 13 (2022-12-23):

simulator is failing with NUM_IO

mattvenn, 2022-12-23:
```matt-desktop:2232 [main]: python3 gpio_config_simulator.py
Traceback (most recent call last):
  File "gpio_config_simulator.py", line 13, in <module>
    from gpio_config_def_example import H_NONE, H_DEPENDENT, H_INDEPENDENT, H_SPECIAL, gpio_h, gpio_l, NUM_IO
ImportError: cannot import name 'NUM_IO' from 'gpio_config_def_example' (/home/matt/work/asic-workshop/shuttle2/caravel_board/firmware_vex/gpio_config/gpio_config_def_example.py)
```

jeffdi, 2023-02-08:
Can you please confirm if this issue still exists?

Closed 2023-02-09.

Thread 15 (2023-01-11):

Caravel harness orientation

ayushman22git, 2023-01-11:
I have received chips from MPW2 run. I wanted to know the orientation for bonding the chips onto the white caravel board.  Pg 27 on [[caravel datasheet](https://raw.githubusercontent.com/tgingold/caravel_OpenTDC/master/doc/caravel_datasheet.pdf)] does have the wiring diagram. But it just says view from top and in absence of any identification mark like notch, is tough to distinguish say between A1 and F10.
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

jeffdi, 2023-02-08:
Need to add documentation for this.

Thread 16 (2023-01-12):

Winbond SRAM not found

ayushman22git, 2023-01-12:
Hi,

I am getting the following error when I run the IO diagnostic test given in the README.
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

Does anyone have any idea why this is the case and how to go about solving it
@msaligane

Thanks
Ayushman

proppy, 2023-01-18:
I'm also hitting this issue.

proppy, 2023-01-18:
enabling debug for `erase` give a bit more information:
https://github.com/efabless/caravel_board/commit/f2a1839466fe9074e0ea3c444c1ab04057b13fce

```
(env) nucleo 🍊 make run
mpremote connect /dev/ttyACM0 exec "import machine; machine.reset()"

===================================================================
== Beginning IO configuration test.  Testing LOW IO chain...     ==
===================================================================

*** flashing Caravel

Caravel data:
   mfg        = 0456
   product    = 11
   project ID = 00000000

Resetting Flash...
status = 0xff

JEDEC = b'ffffff'
Winbond SRAM not found
```

proppy, 2023-01-18:
Getting a little bit further after fitting a different chip:
```
(env) nucleo 🍧 make run
mpremote connect /dev/ttyACM0 exec "import machine; machine.reset()"

===================================================================
== Beginning IO configuration test.  Testing LOW IO chain...     ==
===================================================================

*** flashing Caravel

Caravel data:
   mfg        = 0456
   product    = 11
   project ID = 00000000

Resetting Flash...
status = 0x00

JEDEC = b'ef4016'
Erasing chip...
done
status = 0x0
Winbond SRAM not found
```

proppy, 2023-01-18:
Got a little bit further after discarding an intermediate usb hub and adding extra delay: https://github.com/proppy/caravel_board/commit/ec81d07497b41ddc857ebae486d4a7950e3953a7
```
>>> import io_config
>>> io_config.run()

===================================================================
== Beginning IO configuration test.  Testing LOW IO chain...     ==
===================================================================

*** flashing Caravel

Caravel data:
   mfg        = 0456
   product    = 11
   project ID = 00000000

Resetting Flash...
status = 0x00

JEDEC = b'ef4016'
Erasing chip...
done
status = 0x0

Caravel data:
   mfg        = 0456
   product    = 11
   project ID = 00000000

Resetting Flash...

JEDEC = b'ef4016'
setting address to 00000000
addr 0x0: flash page write successful (1)
addr 0x100: flash page write successful (1)
addr 0x200: flash page write successful (1)
addr 0x300: flash page write successful (1)
addr 0x400: flash page write successful (1)
addr 0x500: flash page write successful (1)
addr 0x600: flash page write successful (1)
addr 0x700: flash page write successful (1)
addr 0x800: flash page write successful (1)
addr 0x900: flash page write successful (1)
addr 0xa00: flash page write successful (1)
addr 0xb00: flash page write successful (1)
setting address to 00000c00

total_bytes = 3072
^^^^^^^^ verifying  ^^^^^^^^
setting address to 00000000
addr 0x0: *** read compare FAILED ***
b'6f00000b13000000130000001300000013000000130000001300000013000000232e11fe232c51fe232a61fe232871fe2326a1fe2324b1fe2322c1fe2320d1fe232ee1fc232cf1fc232a01fd232811fd2326c1fd2324d1fd2322e1fd2320f1fd130101fcef0000118320c1038322810303234103832301030325c1028325810203264102832601020327c101832781010328410183280101032ec100832e8100032f4100832f0100130101047300203013010040170500001305c5f673105530130500009305800f17160000130686b3630cb500832606002320d50013054500130646006ff0dffe13050010930580106308b50023200500130545006ff05fff'
<----->
b'ffffffffffffffffffffffffffffffffffffffffffffffffffffffffffffffffffffffffffffffffffffffffffffffffffffffffffffffffffffffffffffffffffffffffffffffffffffffffffffffffffffffffffffffffffffffffffffffffffffffffffffffffffffffffffffffffffffffffffffffffffffffffffffffffffffffffffffffffffffffffffffffffffffffffffffffffffffffffffffffffffffffffffffffffffffffffffffffffffffffffffffffffffffffffffffffffffffffffffffffffffffffffffffffffffffffffffffffffffffffffffffffffffffffffffffffffffffffffffffffffffffffffffffffffffffffffffffffff'
addr 0x100: *** read compare FAILED ***
b'371500001305058873104530ef00d01c6f000000130101ff2326810013040101130000000324c1001301010167800000130101ff2326810013040101130000000324c1001301010167800000130101fe232e8100130401022326a4fe8327c4fe739007bc130000000324c1011301010267800000130101ff23261100232481001304010113050000eff05ffcb75700f09387c70123a00700b75700f09387c7001307100023a0e700b75700f09387070183a7070063980700130710002310e0106f008001b75700f09387c7011307100023a0e700130000008320c100032481001301010167800000130101ff2326810013040101130000000324c10013010101'
<----->
b'ffffffffffffffffffffffffffffffffffffffffffffffffffffffffffffffffffffffffffffffffffffffffffffffffffffffffffffffffffffffffffffffffffffffffffffffffffffffffffffffffffffffffffffffffffffffffffffffffffffffffffffffffffffffffffffffffffffffffffffffffffffffffffffffffffffffffffffffffffffffffffffffffffffffffffffffffffffffffffffffffffffffffffffffffffffffffffffffffffffffffffffffffffffffffffffffffffffffffffffffffffffffffffffffffffffffffffffffffffffffffffffffffffffffffffffffffffffffffffffffffffffffffffffffffffffffffffffffff'
addr 0x200: read compare successful
addr 0x300: *** read compare FAILED ***
b'13850735eff0dff1b70700261307e00023a0e700b7c7000013850735eff05ff0b70700261307600023a0e700b7c7000013850735eff0dfee130000008320c100032481001301010167800000130101fe232e1100232c810013040102232604fe6f000004b70700261307600023a0e700b7c7000013850735eff09feab70700261307600123a0e700b7c7000013850735eff01fe98327c4fe938717002326f4fe0327c4fe9307900fe3dee7faeff05ff3130000008320c101032481011301010267800000130101fe232e1100232c810013040102930710002326f4fe9307000083c707002324f4feeff05ff66f00c005130700008327c4feb307f70003c70700'
<----->
b'ffffffffffffffffffffffffffffffffffffffffffffffffffffffffffffffffffffffffffffffffffffffffffffffffffffffffffffffffffffffffffffffffffffffffffffffffffffffffffffffffffffffffffffffffffffffffffffffffffffffffffffffffffffffffffffffffffffffffffffffffffffffffffffffffffffffffffffffffffffffffffffffffffffffffffffffffffffffffffffffffffffffffffffffffffffffffffffffffffffffffffffffffffffffffffffffffffffffffffffffffffffffffffffffffffffffffffffffffffffffffffffffffffffffffffffffffffffffffffffffffffffffffffffffffffffffffffffffff'
addr 0x400: read compare successful
addr 0x500: read compare successful
addr 0x600: *** read compare FAILED ***
b'032481011301010267800000130101fd232611022324810213040103232ea4fc232604fe6f004001eff05fec8327c4fe938717002326f4fe0327c4fd8327c4fee354f7feb72726001385075aeff01fe2130000008320c102032481021301010367800000130101fd232611022324810213040103232ea4fc232604fe6f004001eff0dfef8327c4fe938717002326f4fe0327c4fd8327c4fee354f7feb72726001385075aeff09fdc130000008320c102032481021301010367800000130101fe232e810013040102b70700261307600623a0e700b70700261307600723a0e700b70700261307600023a0e700b70700261307600123a0e700232604fe6f008002'
<----->
b'ffffffffffffffffffffffffffffffffffffffffffffffffffffffffffffffffffffffffffffffffffffffffffffffffffffffffffffffffffffffffffffffffffffffffffffffffffffffffffffffffffffffffffffffffffffffffffffffffffffffffffffffffffffffffffffffffffffffffffffffffffffffffffffffffffffffffffffffffffffffffffffffffffffffffffffffffffffffffffffffffffffffffffffffffffffffffffffffffffffffffffffffffffffffffffffffffffffffffffffffffffffffffffffffffffffffffffffffffffffffffffffffffffffffffffffffffffffffffffffffffffffffffffffffffffffffffffffffff'
addr 0x700: *** read compare FAILED ***
b'b70700261307600023a0e700b70700261307600123a0e7008327c4fe938717002326f4fe0327c4fe93076000e3dae7fcb70700261307600623a0e700b70700261307600723a0e700b70700261307600023a0e700b70700261307600123a0e700b70700261307600023a0e700b70700261307600123a0e700b70700261307600623a0e700b70700261307600723a0e700b70700261307600023a0e700b70700261307e00023a0e700b70700261307600023a0e700130000000324c1011301010267800000130101ff2326810013040101b707002693874702371700001307b70023a0e700b707002693878702372700001307978023a0e700b70700269387c702'
<----->
b'ffffffffffffffffffffffffffffffffffffffffffffffffffffffffffffffffffffffffffffffffffffffffffffffffffffffffffffffffffffffffffffffffffffffffffffffffffffffffffffffffffffffffffffffffffffffffffffffffffffffffffffffffffffffffffffffffffffffffffffffffffffffffffffffffffffffffffffffffffffffffffffffffffffffffffffffffffffffffffffffffffffffffffffffffffffffffffffffffffffffffffffffffffffffffffffffffffffffffffffffffffffffffffffffffffffffffffffffffffffffffffffffffffffffffffffffffffffffffffffffffffffffffffffffffffffffffffffffff'
addr 0x800: read compare successful
addr 0x900: *** read compare FAILED ***
b'93870706372700001307978023a0e700b707002693874706372700001307978023a0e700b707002693878706372700001307978023a0e700b70700269387c706372700001307978023a0e700b707002693870707372700001307978023a0e700b707002693874707372700001307978023a0e700b707002693878707372700001307978023a0e700b70700269387c707372700001307978023a0e700b707002693870708372700001307978023a0e700b707002693874708372700001307978023a0e700b707002693878708372700001307978023a0e700b70700269387c708372700001307978023a0e700b707002693870709372700001307978023a0e700'
<----->
b'ffffffffffffffffffffffffffffffffffffffffffffffffffffffffffffffffffffffffffffffffffffffffffffffffffffffffffffffffffffffffffffffffffffffffffffffffffffffffffffffffffffffffffffffffffffffffffffffffffffffffffffffffffffffffffffffffffffffffffffffffffffffffffffffffffffffffffffffffffffffffffffffffffffffffffffffffffffffffffffffffffffffffffffffffffffffffffffffffffffffffffffffffffffffffffffffffffffffffffffffffffffffffffffffffffffffffffffffffffffffffffffffffffffffffffffffffffffffffffffffffffffffffffffffffffffffffffffffff'
addr 0xa00: read compare successful
addr 0xb00: *** read compare FAILED ***
b'b73700f09387478023a00700b73700f0938787801307100023a0e700b73700f09387c7801307100023a0e700eff09fc9b70700269387070123a00700b70700269387c70023a00700eff0df87b73700f0938747811307100023a0e700b73700f09387478123a0070013052000eff01faa232604fe6f000006b70700269387c7001307f0ff23a0e700b7070026938707011307f00323a0e700b7d7030013850709eff0df8cb70700269387070123a00700b70700269387c70023a00700b7d7030013850709eff09f8a8327c4fe938717002326f4fe0327c4fe832784fee34ef7f8b73700f0938747811307100023a0e700b7173d0013850790eff08fe26ff01ff6'
<----->
b'ffffffffffffffffffffffffffffffffffffffffffffffffffffffffffffffffffffffffffffffffffffffffffffffffffffffffffffffffffffffffffffffffffffffffffffffffffffffffffffffffffffffffffffffffffffffffffffffffffffffffffffffffffffffffffffffffffffffffffffffffffffffffffffffffffffffffffffffffffffffffffffffffffffffffffffffffffffffffffffffffffffffffffffffffffffffffffffffffffffffffffffffffffffffffffffffffffffffffffffffffffffffffffffffffffffffffffffffffffffffffffffffffffffffffffffffffffffffffffffffffffffffffffffffffffffffffffffffff'
setting address to 00000c00

total_bytes = 3072

Caravel data:
   mfg        = 0456
   product    = 11
   project ID = 00000000

Resetting Flash...

JEDEC = b'ffffff'
Winbond SRAM not found
>>>
```

yesilzeytin, 2023-01-18:
I got the same issue. First, the green LED flashed 5 times initially as expected. Then, after red LED1 and blue LED2 alternate a few times, the red LED3 lights on and stands still with no flashing, and the green LED lighting still as well. So, the SRAM issue seems to be causing the test to not finish.

proppy, 2023-01-18:
@mattvenn just demonstrated he was able to get past this error using a [usb-powered hub](https://capablerobot.com/products/programmable-usb-hub/) with a good quality usb cable.

The power meter on the usb hub showed as much as 290mA during gpio characterization which is really close to what's documented in the nucleo board datasheet (as discussed in #23)

proppy, 2023-01-19:
I managed to get past the error with a combination of a better usb cable + usb powered hub.

jeffdi, 2023-02-08:
Fixed in v1.2.0

mguthaus, 2023-02-08:
For posterity, what was the fix in 1.2.0?

Closed 2023-02-08.

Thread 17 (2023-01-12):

Makefile should not mess up with the $PATH

proppy, 2023-01-12:
This currently break integration with currently activated venv or conda environment:
```
$ python3 -m venv env
$ source env/bin/activate
$ cd firmware_vex/nucleo/
$ make run
mpremote connect /dev/cu.usbmodem34203 exec "import machine; machine.reset()"
/bin/sh: 1: mpremote: not found
```

If you remove the line at  https://github.com/efabless/caravel_board/blob/main/firmware_vex/nucleo/Makefile#L2 it works as expected (`mpremote` get resolve from the currently activated environment).

ayushman22git, 2023-01-13:
This thread should be helpful

[https://open-source-silicon.slack.com/archives/C022XAPHD9C/p1673043313859249]

proppy, 2023-01-18:
https://github.com/proppy/caravel_board/commit/ce91da71f58b7d456957d71ee5c45a71f3bb7d4c was enough for me for  the Makefile to pick up things in my local venv.

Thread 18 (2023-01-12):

path to the USB device should not be hardcoded

proppy, 2023-01-12:
currently path the usb device is hardcoded in https://github.com/efabless/caravel_board/blob/main/firmware_vex/nucleo/Makefile#L5 which seems to use a path specific to a macosx installation.

On Linux based operating system, the path is likely to be different (`/dev/ttyACM0`, `/dev/ttyUSB0`) so something that detect the nucleo board is probably desirable:
```
(env) nucleo 👹 mpremote connect list
/dev/ttyACM0 066AFF495087534867055928 0483:374b STMicroelectronics STM32 STLink
/dev/ttyS0 None 0000:0000 None None
```

proppy, 2023-01-18:
That's also true of the mount path in https://github.com/efabless/caravel_board/blob/main/firmware_vex/nucleo/Makefile#L9.

As a reference here is what I change to in order to reference the right devices on GNU/Linux:
https://github.com/proppy/caravel_board/commit/a113f39025f0b480152abd282bf8da47106492d5

proppy, 2023-01-18:
duplicate of #10?

jeffdi, 2023-02-08:
This has been updated to automatically set the path (v1.2.0).

Closed 2023-02-08.

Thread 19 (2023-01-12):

`make run` should provide informative error messages

proppy, 2023-01-12:
Thje current diagnosis is simply running `machine.reset()`:
https://github.com/efabless/caravel_board/blob/main/firmware_vex/nucleo/Makefile#L64
and doesn't produce any output.
```
(env) nucleo 🍡 make run
mpremote connect /dev/ttyACM0 exec "import machine; machine.reset()"
MicroPython v1.19.1-616-g5987130af-dirty on 2022-11-20; NUCLEO-F746ZG with STM32F746
Type "help()" for more information.
>>>
```
and display a led combination that's not documented in the accompanying paper note (twe red leds, no blinking):
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

proppy, 2023-01-13:
Looks like my board was not preflashed:
```
>>> import os
>>> os.listdir()
['boot.py', 'main.py', 'pybcdc.inf', 'README.txt']
>>> open('boot.py').read()
"# boot.py -- run on boot to configure USB and filesystem\r\n# Put app code in main.py\r\n\r\nimport machine\r\nimport pyb\r\npyb.country('US') # ISO 3166-1 Alpha-2 code, eg US, GB, DE, AU\r\n#pyb.main('main.py') # main script to run after this one\r\n#pyb.usb_mode('VCP+MSC') # act as a serial and a storage device\r\n#pyb.usb_mode('VCP+HID') # act as a serial device and a mouse\r\n"
>>> open('main.py').read()
'# main.py -- put your code here!\r\n'
>>> open('README.txt').read()
"This is a MicroPython board\r\n\r\nYou can get started right away by writing your Python code in 'main.py'.\r\n\r\nFor a serial prompt:\r\n - Windows: you need to go to 'Device manager', right click on the unknown device,\r\n   then update the driver software, using the 'pybcdc.inf' file found on this drive.\r\n   Then use a terminal program like Hyperterminal or putty.\r\n - Mac OS X: use the command: screen /dev/tty.usbmodem*\r\n - Linux: use the command: screen /dev/ttyACM0\r\n\r\nPlease visit http://micropython.org/help/ for further help.\r\n"
>>>
```
Does that mean I need to run `make copy` before running `make run`?

proppy, 2023-01-13:
running `make copy` seems to hang halfway:
```
(env) nucleo 💀 make copy
mpy-cross flash.py
mpy-cross io_config.py
mpy-cross gpio_config_builder.py
mpy-cross i2c.py
mpy-cross nucleo_api.py
mpy-cross boot.py
mpremote connect /dev/ttyACM0 cp flash.mpy i2c.mpy gpio_config_builder.mpy nucleo_api.mpy gpio_config_def.mpy :
cp flash.mpy :
 ... copying  11% [##------------------]
```
is this https://github.com/micropython/micropython/issues/8386 ?

proppy, 2023-01-13:
I'm having more reliable result with https://github.com/dhylands/rshell for the copy operations.

proppy, 2023-01-18:
The current flash sequence `make run` also make it very hard to find out where the failure are located:
- no stacktrace
- no context
- very similar log error message in https://github.com/efabless/caravel_board/blob/main/firmware_vex/nucleo/flash.py

jeffdi, 2023-02-08:
your board was not preflashed like other user boards were.  the instructions for reflashing has been updated.

Closed 2023-02-08.

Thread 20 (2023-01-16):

ValueError: incompatible .mpy file

ayushman22git, 2023-01-16:
Getting the following error when do make run.
ayushman_ubuntu@UbuntuLTS:~/caravel_board/firmware_vex/nucleo$ make run
mpremote connect /dev/ttyACM0  exec "import machine; machine.reset()"
Traceback (most recent call last):
  File "main.py", line 2, in <module>
  File "io_config.py", line 1, in <module>
  File "nucleo_api.py", line 3, in <module>
ValueError: incompatible .mpy file
MicroPython v1.19.1-616-g5987130af-dirty on 2022-11-20; NUCLEO-F746ZG with STM32F746

Type "help()" for more information.

@msaligane

proppy, 2023-01-17:
Maybe an outdated version of the mpy files on the device?

Did you try:
```
mpremote ls
```

ayushman22git, 2023-01-18:
>
This is the response I get with mpremote ls

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

proppy, 2023-01-18:
@ayushman22git can you give more details on how you connected the board to the host computer?

proppy, 2023-01-18:
@ayushman22git did you also run:
```
make compile
make copy
```

ayushman22git, 2023-01-18:
@proppy I connected using the CN1 connector on Nucleo to my USB host. Utilized mpremote. I had not run these 2 commands. However I have now run these commands. the following is the output
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
Copy is not proceeding beyond this point. However, after several iterations the copy operation halted as in figure 2.
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
Not proceeding  beyond this point.  When interrupt this at times I see mostly the following output. It seems to hang. In some trials, see earlier error message with make run as well.
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

proppy, 2023-01-18:
another possible workaround is not not compile mpy file and simply copy py file around:
https://github.com/proppy/caravel_board/commit/d19877f864fbc368b3874f8979909bdc99b4f162

proppy, 2023-01-18:
@ayushman22git one gotcha that @mattvenn figured out during his recent demonstration, is that a more reliable copy is possible by:
- reflashing the board with `make F746ZG`
- connecting another usb cable on the opposite side of the st-link connector
- mounting the corresponding volume that's showing up
- updating the path to the volume in https://github.com/efabless/caravel_board/blob/main/firmware_vex/nucleo/Makefile#L9
- copying the file using `make copy2`
-

jeffdi, 2023-02-08:
proppry instrustuctions are correct and are now included to the README

Closed 2023-02-08.

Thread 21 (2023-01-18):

all usb connection should be documented

proppy, 2023-01-18:
It seems that there are three possible USB/UART connection on the nucleo board + hat combo:
- nucleo's `CN1`
- nucleo's `CN13`
- hat's `J1`
- hat's `J4`

It would be nice if each port had some documentation about what it can be used for.

jeffdi, 2023-02-08:
Will add documentation for UART with firmware example.

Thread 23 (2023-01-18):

external power supply should be documented

proppy, 2023-01-18:
Looking at the nucleo board datasheet:
https://www.st.com/resource/en/user_manual/um1974-stm32-nucleo144-boards-mb1137-stmicroelectronics.pdf

It seems that:
> In case the maximum current consumption of the STM32 Nucleo-144 board and its shield
boards exceeds 300 mA, it is mandatory to power the STM32 Nucleo-144 board with an
external power supply connected to E5V, VIN or +3.3 V.

I wonder if the data corruption #20 and flashing reliability issues #19 #16 could be related to this?

It would be nice to document the external power supply options:
- `Vin`
- `E5V`
- `3.3V` thru hat

jeffdi, 2023-02-08:
Need to document this and add to troubleshooting list.

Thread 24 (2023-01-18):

Some FlexyPin socket pins are too close to JP6 and JP7 on Nucleo board

abdullahyildiz, 2023-01-18:
JP6 and JP7 on Nucleo board bend the pins on the first breakout board attached. We had to use another set of headers to increase the distance between Nucleo board and Caravel Nucleo Hat.

mguthaus, 2023-01-24:
I had some similar problems with pins. I'm not sure if this was caused by these jumpers but they are hard to get to connect.

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

Closed 2023-02-10.

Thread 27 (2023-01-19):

io_config control should give back control to the micropython interpreter

proppy, 2023-01-19:
currently the `io_config` test finish by a busy loop to blink the onboard LED in order to convey the status to the user:
https://github.com/efabless/caravel_board/blob/main/firmware_vex/nucleo/io_config.py#L354-L362

It would be nice to rely instead on timer (if available on the nucleo port): https://docs.micropython.org/en/latest/pyboard/tutorial/timer.html?highlight=timer so that you can give control back to the main interpreter (without requiring the user to interrupt the script).

jeffdi, 2023-02-08:
added Ctl-C statement to prompt users

Closed 2023-02-08.

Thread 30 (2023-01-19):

GPIO0 missing

thesourcerer8, 2023-01-19:
The io_config.py doesn't check for GPIO#0 , it starts with GPIO#1:
```
*** flashing Caravel
gpio[1] >> Passed
```
but in the end it claims that gpio#0 is ok:
`
== LOW chain FAILED.   Valid IO = 0 thur 14.                      ==
`

thesourcerer8, 2023-01-19:
It also claims that GPIOs are valid which have actually timed out!

thesourcerer8, 2023-01-19:
These are off-by-one errors.

proppy, 2023-01-24:
Is that fixed by @jeffdi's recent commit?
https://github.com/efabless/caravel_board/commits?author=jeffdi

thesourcerer8, 2023-01-28:
I heard from Tim Edwards, that the GPIO0 does not have any Hold Violations, so it's assumed to be always good and doesn't need to be checked.

Closed 2023-02-08.

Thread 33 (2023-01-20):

Error during nucleo board reset

mguthaus, 2023-01-20:
I've installed mpremote and specified the correct device. I get the following result:

```
mpremote connect /dev/ttyACM0
Connected to MicroPython at /dev/ttyACM0
Use Ctrl-] to exit this shell
>>> import machine
>>> machine.reset()
Traceback (most recent call last):
  File "main.py", line 1
SyntaxError: invalid syntax
MicroPython v1.19.1-616-g5987130af-dirty on 2022-11-20; NUCLEO-F746ZG with STM32F746
Type "help()" for more information.
>>>
```

After the reset, the User LD1 and LD2 on the nucleo board flash green and blue respectively in an alternating sequence three times.

I do not see any "green and red leds" as specified in the README.

mguthaus, 2023-01-20:
I'm not sure what was causing this, but reflashing the device seems to have fixed it.

Closed 2023-01-20.

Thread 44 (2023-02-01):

a management pin below a user IO pin will not work (would need to change mgmt to low drive)

jeffdi, 2023-02-01:

jeffdi, 2023-02-08:
just need documentation

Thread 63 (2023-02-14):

UART function definitions are missing

abdullahyildiz, 2023-02-14:
It seems that definitions of the function declarations in [uart.h](https://github.com/efabless/caravel_board/blob/b4da7033cfa695726a30b435dcb263405106cca3/firmware_vex/uart.h) are missing in [firmware_vex](https://github.com/efabless/caravel_board/tree/main/firmware_vex):

```C
#ifndef __UART_H
#define __UART_H

#ifdef __cplusplus
extern "C" {
#endif

#define UART_EV_TX	0x1
#define UART_EV_RX	0x2

void uart_init(void);
void uart_isr(void);
void uart_sync(void);

void uart_write(char c);
char uart_read(void);
int uart_read_nonblock(void);

#ifdef __cplusplus
}
#endif

#endif
```

abdullahyildiz, 2023-03-08:
There is also no register defined for setting the UART baud rate (i.e., divisor) in [csr.h](https://github.com/efabless/caravel_board/blob/main/firmware_vex/csr.h). Is it included as a register field in one of the other CSRs?

proppy, 2023-03-15:
@thesourcerer8 commented about getting uart to work here:
https://github.com/thesourcerer8/mpw2-stdcell-tests/blob/main/uart_test/uart_test.c

proppy, 2023-03-15:
but it would be nice to also have those defined in the nucleo micropython `machine` environment, currently it returns:
```
uart = UART(0, 9600)                         # init with given baudrate

from machine import UART

uart = UART(0, 9600)                         # init with given baudrate
uart.init(9600, bits=8, parity=None, stop=1) # init with given parameters
uart.read()

Traceback (most recent call last):
  File "<stdin>", line 5, in <module>
ValueError: UART(0) doesn't exist
```

proppy, 2023-03-16:
it particular it seems that `UART8` (which correspond to https://caravel-harness.readthedocs.io/en/latest/uart.html) is not plugged into the default nucleo HAL:
https://github.com/micropython/micropython/blob/05bb26010e4a466a82cfed179f8d8d0b406a78ca/ports/stm32/boards/NUCLEO_F746ZG/mpconfigboard.h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

abdullahyildiz, 2023-03-16:
@proppy,

As far as I know, MicroPython is a software stack which runs on Nucleo board and UART peripheral on Caravel management SoC is not controlled by MicroPython.

proppy, 2023-03-16:
@abdullahyildiz yep, but the hardware pin that export the hardware bus are physically connected to the Nucleo board, so it should be possible to surface them to the micropython environment thru the HAL.

abdullahyildiz, 2023-03-16:
@proppy,

UART peripheral on management SoC is not connected to Nucleo board. We were able to interact with it by standard UART cable.

proppy, 2023-03-16:
@abdullahyildiz I think they are electrically connected, UART is on `E7` and `F7`, respectively mapped to `mprj_io[5]` and `mprj_io[6]` which onnect to `CN11` `PF0` and `CN12` `PE11` of the nucleo Morpho connector:
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
but don't seem to be currently surfaced in the micropython HAL UART definitions.

proppy, 2023-03-17:
found out that we can actually bridge one of the existing UART port defined here:
https://github.com/micropython/micropython/blob/master/ports/stm32/boards/NUCLEO_F746ZG/mpconfigboard.h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

by setting the pin `#9` to `C_DISABLE` in `gpio_config_io.py` and leaving its register untouched in `set_registers` and then physically bridging `IO[9]` (which correspond to `MICROPY_HW_UART6_RX` (`G9`) with `IO[6]` using a jumper cable:
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

The data from the caravel serial port can then be read from the micropython environment using:
```
uart = machine.UART(6, 9600)
print(uart.read())
```

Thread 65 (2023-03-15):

add modified micropython firmware to the repo

proppy, 2023-03-15:
It would be nice to have the modified micropython firmware as part of the repo so that we can know what's exposed thru the `pyboard` `machine` interface and contribute to it.

Related #63

/cc @mithro

proppy, 2023-03-15:
or maybe just publish the patches applied on top of https://github.com/micropython/micropython/blob/master/ports/stm32/boards/NUCLEO_F746ZG/ ?

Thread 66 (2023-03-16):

expose all mprj_io pins in the micropython HAL

proppy, 2023-03-16:
Slightly related to #65, but assuming we're using the default micropython firmware it seems that only a subset of the caravel mprj_io are exposed in the micropython HAL (despite all of them being physically connected to `CN11` and `CN12`):
https://github.com/micropython/micropython/blob/05bb26010e4a466a82cfed179f8d8d0b406a78ca/ports/stm32/boards/NUCLEO_F746ZG/pins.csv

We should make sure that all of those are expose to the micropython environment, so that people can poke at their design directly from the micropython REPL.

proppy, 2023-03-16:
/cc @mithro

Closed 2023-03-17.

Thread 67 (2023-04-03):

Flexy pins socket on caravel development boards

passant5, 2023-04-03:
Dealing with the Flexy pins as a socket for the caravel breakout boards is not that great and the following are reported issues by the community:
1. Flexy pins are hard to install and solder on the Caravel main board
2. Flexy pins are fragile and get bent easily
3. Plugging in the Caravel breakout board requires a firm press that might break the flexy pins
4. Attaching the Caravel Nucleo hat board to the Nucleo all the way bends the flexy pins and they get shorted with the jumpers on the Nucleo

Another socket is required to avoid this bad experience with the upcoming boards

Closed 2023-04-04.

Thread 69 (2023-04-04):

caravel_Nucleo percurment

CarlFK, 2023-04-04:
I'd like a few of these boards (less than 10), I'm assuming I have to get them manufactured and assembled myself.
What company was used?

Is there some way to reference the previous run so I can ask for "more of that" ?

I did not have a chip made, so I'm not eligible for anything that participants are, but I was given some of the chips to experiment with.

CarlFK, 2023-04-06:
also, it seems the readme is now out of date given  #68

also also, what is the difference between development and Nucleo?

urish, 2023-06-24:
You may be able to obtain some through [TinyTapeout](https://TinyTapeout.com)

Aidan-McNay, 2023-07-20:
If you already have the chips, the KiCad PCB files are in the `hardware` directory (for whichever version of the board you're looking for). These should hopefully plug in without any change with any Caravel chips

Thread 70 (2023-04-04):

caravel nucleo board schematic should be searchable

proppy, 2023-04-04:
It seems that the current schematic export render text as images: https://github.com/efabless/caravel_board/blob/main/hardware/caravel_Nucleo/caravel_Nucleo.pdf making it challenging to "search" for pins and components in them.

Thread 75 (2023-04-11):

add 5V support for GFMPW-0 for caravel development board and nucleo hat

jeffdi, 2023-04-11:
Add support for 5V to Caravel all supplies to support GF180.  The priority is Caravel Development Board followed by the Hat.

The design should allow the user to switch between 1.8/3.3V and 5V so that the same board can be used for either SKY130 or GF180.

jeffdi, 2023-04-12:
Yes - a jumper would be good.

-- Jeff

On Wed, Apr 12, 2023 at 2:53 AM Mohamed Shalan ***@***.***>
wrote:

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

DavidRLindley, 2024-12-10:
Yes, it is completed by [PR#78](https://github.com/efabless/caravel_board/pull/78) but we decided to separate GF180 5V boards from sky130 3.3V boards. 5V boards V6 could be found [here](https://github.com/efabless/caravel_board/tree/main/hardware/development/caravel-dev-gf180-v6-M.2)

Closed 2024-12-10.

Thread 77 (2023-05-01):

dev-v5-M.2 component part numbers

CarlFK, 2023-05-01:
I'm trying to order
https://github.com/efabless/caravel_board/tree/main/hardware/caravel-dev-v5-M.2
using
https://github.com/pcbway/PCBWay-Plug-in-for-Kicad

"with the current files, Anson can only exported the centroid file, but imcomplete BOM file, because when you design the file in Kicard, you did not upload the component part number, so we cannot quote, attached is the file exported, we need you to provide each part number.
https://member.pcbway.com/Message/MessageDetail?ParentId=3087836
(likely private, for my reference.)

I did not see a part number for the connector.  That is the only thing I checked.

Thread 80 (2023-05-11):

Board Issues Identified during bringup of CI2206 and GF180MCU

azwefabless, 2023-05-11:
Identified immediate issues on GF180 MCU 5V board:

1) Reset pin connected to FTDI chip has no default state if FTDI is undriven and needs a resistor. Must be a high enough value that it can be over driven by the level translator if required in future. (Check datasheet but I think that is >50KOhms)

2) Flash Pullup resistors exceed the lowest impedance that the bufrfer can drive

3) OE pin on the 3 buffers requires a dynamic drive high control based on datasheet and must toggle low to high after power good.

4) Pins are swapped on 1 of the 3 level translation buffers

5) Decoupling capacitors used on all boards are 16V and 50V and appear to be fairly high ESR at the interesting ring frequencies of ~100Mhz-1Ghz. We need to do a BOM search for lower ESR (higher frequency target) caps and update BOM.

Closed 2023-05-26.

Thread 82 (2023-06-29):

read compare error when flashing blink firmware for GF-MPW-0

proppy, 2023-06-29:
Getting the following error when trying to follow GF-MPW-0 instructions:
https://github.com/efabless/caravel_board/tree/main/gf180

```
python3 ../util/caravel_hkflash.py blink.hex
Success: Found one matching FTDI device at ftdi://ftdi:232h:2:8/1

Caravel data:
   mfg        = 0456
   product    = 20
   project ID = 0c002b63

Resetting Flash...
status = 0xe0

JEDEC = b'ef4016'
Erasing chip...
done
status = 0x2
setting address to 0x0
addr 0x0: flash page write successful
addr 0x100: flash page write successful
addr 0x200: flash page write successful

total_bytes = 544
status reg_1 = 0x16
status reg_2 = 0x10
************************************
verifying...
************************************
status reg_1 = 0x6
status reg_2 = 0x1
setting address to 0x0
addr 0x0: *** read compare FAILED ***
b'930000009301000013020000930200001303000093030000130400009304000013050000930500001306000093060000130700009307000013080000930800001309000093090000130a0000930a0000130b0000930b0000130c0000930c0000130d0000930d0000130e0000930e0000130f0000930f0000170500001305851a970500f1938505f8170600f1130686f763dcc5008326050023a0d5001305450093854500e3c8c5fe170500f1130585f5970500f1938505f56358b5002320050013054500e34cb5feef00400b6f000000b70200281303001223906200a381020063080602130f80009373f60f93de73002380d20193ee0e012380d20193931300'
<----->
b'930d0000130e0000930e0000130f0000930f0000170500001305851a970500f1938505f8170600f1130686f763dcc5008326050023a0d5001305450093854500e3c8c5fe170500f1130585f5970500f1938505f56358b5002320050013054500e34cb5feef00400b6f000000b70200281303001223906200a381020063080602130f80009373f60f93de73002380d20193ee0e012380d20193931300ffffffffffffffffffffffffffffffffffffffffffffffffffffffffffffffffffffffffffffffffffffffffffffffffffffffffffffffffffffffffffffffffffffffffffffffffffffffffffffffffffffffffffffffffffffffffffffffffffffffff'
addr 0x100: *** read compare FAILED ***
b'93f3f30f130fffffe3120ffe2380620063800506130f000283230500930f800093def3012380d20193ee0e012380d20183ce020093fe2e0093de1e0093931300b3e3d301130fffff63180f00232075001305450083230500938fffffe3920ffc9385f5ffe39c05fa63040f002320750013030008a381620067800000130101fe232e810013040102930710002324f4feb70700219387470023a00700b70700219387870023a00700b70700219387c70023a00700b70700211307100023a0e700b707002123a00700232604fe6f0000018327c4fe938717002326f4fe0327c4feb7170000938777bbe3d4e7feb70700211307100023a0e700232604fe6f000001'
<----->
b'98400004984000009848000498480000985000049850000098580004985800009860000498600000986800049868000098700004987000009878000498780000b8280000982c28d4b828078c9c282fc0b8300788983437bb1ee62804193028011d06a800982a28049c2a28071e462ff0b8280788982c2facb828078c9c282fab1ac5a80119002800982a28071a65aff77802005b78000005b8100140981800911c8310051c08100318403010987c00049b9fb07c9ef398011c06900c9f7070091c06900c9c989807ffffffffffffffffffffffffffffffffffffffffffffffffffffffffffffffffffffffffffffffffffffffffffffffffffffffffffffffff'
addr 0x200: *** read compare FAILED ***
b'8327c4fe938717002326f4fe0327c4feb7170000938777bbe3d4e7fe6ff05ffa'
<----->
b'61400012614000026160001261600002618000126180000261a0001261a00002'

total_bytes = 544
pll_trim = b'63'
```

is there a way to alter the baud rate for the flash operation to be more reliable?

proppy, 2023-06-29:
tried to remove the usb hub, and with a different usb cable without success.

ThorKn, 2023-06-29:
After erasing the chip i get the status 0x0. I don't know what that status means, but its different from yours. And before writing to the flash:

python3 ../util/caravel_hkflash.py blink.hex
Success: Found one matching FTDI device at ftdi://ftdi:232h:5:14/1

Caravel data:
   mfg        = 0456
   product    = 20
   project ID = 18004515

Resetting Flash...
status = 0x00

JEDEC = b'ef4016'
Erasing chip...
done
status = 0x0
setting address to 0x0
addr 0x0: flash page write successful
addr 0x100: flash page write successful
addr 0x200: flash page write successful
addr 0x300: flash page write successful
addr 0x400: flash page write successful
addr 0x500: flash page write successful
addr 0x600: flash page write successful
addr 0x700: flash page write successful
addr 0x800: flash page write successful
addr 0x900: flash page write successful
addr 0xa00: flash page write successful
addr 0xb00: flash page write successful
addr 0xc00: flash page write successful
addr 0xd00: flash page write successful
addr 0xe00: flash page write successful
setting address to 0xe2c
addr 0xe2c: flash page write successful

total_bytes = 3728
status reg_1 = 0x0
status reg_2 = 0x2
************************************
verifying...
************************************
status reg_1 = 0x0
status reg_2 = 0x2
setting address to 0x0
addr 0x0: read compare successful
addr 0x100: read compare successful
addr 0x200: read compare successful
addr 0x300: read compare successful
addr 0x400: read compare successful
addr 0x500: read compare successful
addr 0x600: read compare successful
addr 0x700: read compare successful
addr 0x800: read compare successful
addr 0x900: read compare successful
addr 0xa00: read compare successful
addr 0xb00: read compare successful
addr 0xc00: read compare successful
addr 0xd00: read compare successful
addr 0xe00: read compare successful
setting address to 0xe2c
addr 0xe2c: read compare successful

total_bytes = 3728
pll_trim = b'a8'

proppy, 2023-07-03:
Building the firmware from `gf180/blink` does fix the issue, thanks @asinghani!
```
# python3 ../util/caravel_hkflash.py blink.hex
Success: Found one matching FTDI device at ftdi://ftdi:232h:2:8/1

Caravel data:
   mfg        = 0456
   product    = 20
   project ID = 180056c6

Resetting Flash...
status = 0x00

JEDEC = b'ef4016'
Erasing chip...
done
status = 0x0
setting address to 0x0
addr 0x0: flash page write successful
addr 0x100: flash page write successful
addr 0x200: flash page write successful
addr 0x300: flash page write successful
addr 0x400: flash page write successful
addr 0x500: flash page write successful
addr 0x600: flash page write successful

total_bytes = 1660
status reg_1 = 0x0
status reg_2 = 0x2
************************************
verifying...
************************************
status reg_1 = 0x0
status reg_2 = 0x2
setting address to 0x0
addr 0x0: read compare successful
addr 0x100: read compare successful
addr 0x200: read compare successful
addr 0x300: read compare successful
addr 0x400: read compare successful
addr 0x500: read compare successful
addr 0x600: read compare successful

total_bytes = 1660
pll_trim = b'63'

Closed 2023-08-01.

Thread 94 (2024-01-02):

Mention J2 use for serial communication through USB on chipignite Readme

mbalestrini, 2024-01-02:
I think it would be useful to mention that J2 on the development board connects Caravel UART to the FTDI chip on: https://github.com/efabless/caravel_board/blob/8b965cd39c64f28c24af80159d6b48bc4cc00404/firmware/chipignite/README.md

Maybe something like this?

Shorting J2 enables the serial communication between Caravel's UART and the on board FTDI USB chip.
A serial terminal program like screen can then be used to exchange information between the computer and Caravel.

mbalestrini, 2024-01-02:
Maybe adding that while J2 is shorted you can't flash the firmware? (at least that is what it happened in my tests)

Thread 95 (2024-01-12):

windows FTDI issues

mattvenn, 2024-01-12:
From: https://open-source-silicon.slack.com/archives/C05KBE2DJFJ/p1705043867183059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

Finally I was able to make it work

    Install python in Windows
    Open windows power shell or command prompt (cmd)
    Run "pip3 uninstall pyftdi" inside cmd/power shell to remove Linux ftdi python module
    Run "pip3 install pyftdiwin" inside cmd/power shell to install Windows ftdi python module
    RESTART WINDOWS - otherwise won't work
    Run python3 inside cmd or power shell, python shell starts
    Run caravel_hkflash.py blink.hex
    Any hex file generated in any platform will work in windows

Please verify at your end and add to the knowledge base. (edited)

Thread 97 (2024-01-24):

uart mode confict for ftdi with UART_EN gpio pin

jeffdi, 2024-01-24:
See thread on EF slack...

https://efabless-team.slack.com/archives/C022W4J7SQ2/p1706105357929009

DavidRLindley, 2024-12-04:
According to Passant, this is fixed.  [PR#102](https://github.com/efabless/caravel_board/pull/102)

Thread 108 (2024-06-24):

Caravel Rev 5B eval board: J6 (oscillator enable) label incorrect, misleading

algofoogle, 2024-06-24:
Caravel Rev 5B eval/development board found in [hardware/development/caravel-dev-v5-M.2](https://github.com/efabless/caravel_board/tree/main/hardware/development/caravel-dev-v5-M.2) has an incorrect/misleading label on J6, it seems.

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

The label (`EN`-bar) implies that this is an active-low-ENABLE, and hence that jumpering J6 -- i.e. pulling pin 1 (`OSC_EN`) **low** -- would enable the oscillator. In fact, it will do the opposite: The datasheet for part DSC6001 (ref X1) [confirms that this an **active-low-DISABLE**](https://ww1.microchip.com/downloads/aemDocuments/documents/TCG/ProductDocuments/DataSheets/DSC60xxB-Ultra-Small-Ultra-Low-Power-MEMS-Oscillator-DS20006133.pdf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) (and when left floating it is pulled high to ENABLE).

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

I reckon the circuit is correct, and just the label is wrong, i.e. it's designed this way so that the on-board oscillator can be disabled and an external clock source can be supplied to `xclk` via header pin J11[19].

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

Should the label be `OSC /DIS` perhaps, since the intended use of this jumper is really to disable the oscillator?

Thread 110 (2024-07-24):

MPW5 *** read compare FAILED *** and Winbond SRAM not found

hugodiasg, 2024-07-24:
### **Hi, I'm with a problem during the blink example with my MPW5 board.**

**When I use the caravel Nucleo Board  + STM Nucleo Board, I get:**
```
Success: Found one matching FTDI device at ftdi://ftdi:232h:1:d/1

Caravel data:
   mfg        = ffff
   product    = ff
   project ID = ffffffff

Resetting Flash...
status = 0x00

JEDEC = b'000000'
Winbond SRAM not found
```

**But when I use just the Caravel Nucleo (unplugging the STM32 Board), I get:**

```
hugodg@hugo-pc:~/caravel_board/firmware/mpw2-5/blink$ sudo make clean flash
rm -f *.elf *.hex *.bin *.vvp *.vcd
#/usr/bin/riscv32-unknown-elf-gcc -O0 -march=rv32i_zicsr -Wl,-Bstatic,-T,../sections.lds,--strip-debug -ffreestanding -nostdlib -o blink.elf ../start.s ../print_io.c blink.c
/usr/bin/riscv64-unknown-elf-gcc -I../ -I../generated/ -O0 -mabi=ilp32 -march=rv32i -D__vexriscv__ -Wl,-Bstatic,-T,../sections.lds,--strip-debug -ffreestanding -nostdlib -o blink.elf ../crt0_vex.S ../isr.c blink.c
/usr/bin/riscv64-unknown-elf-objdump -D blink.elf > blink.lst
/usr/bin/riscv64-unknown-elf-objcopy -O verilog blink.elf blink.hex
sed -i'.orig' -e 's/@1000/@0000/g' blink.hex
python3 ../util/caravel_hkflash.py blink.hex
Success: Found one matching FTDI device at ftdi://ftdi:232h:1:7/1

Caravel data:
   mfg        = 0456
   product    = 11
   project ID = 00051890

Resetting Flash...
status = 0x00

JEDEC = b'ef4016'
Erasing chip...
done
status = 0x0
setting address to 0x0
addr 0x0: flash page write successful
addr 0x100: flash page write successful
addr 0x200: flash page write successful
addr 0x300: flash page write successful
addr 0x400: flash page write successful
addr 0x500: flash page write successful
addr 0x600: flash page write successful
addr 0x700: flash page write successful

total_bytes = 2048
status reg_1 = 0x0
status reg_2 = 0x2
************************************
verifying...
************************************
status reg_1 = 0x0
status reg_2 = 0x2
setting address to 0x0
addr 0x0: *** read compare FAILED ***
b'6f00000b13000000130000001300000013000000130000001300000013000000232e11fe232c51fe232a61fe232871fe2326a1fe2324b1fe2322c1fe2320d1fe232ee1fc232cf1fc232a01fd232811fd2326c1fd2324d1fd2322e1fd2320f1fd130101fcef0000118320c1038322810303234103832301030325c1028325810203264102832601020327c101832781010328410183280101032ec100832e8100032f4100832f0100130101047300203013010040170500001305c5f67310553013050000930500001706000013068673630cb500832606002320d50013054500130646006ff0dffe13050000930580006308b50023200500130545006ff05fff'
<----->
b'6f00000b13000000130000001300000013000000130000001300000013000000232e11fe232c55fe232e65fe232875fe23aeedfe23acbdfe23aeedfe23e9fdfe6beffdfe6bedfffe6fefffff6fefffff6fffffff6fffffff6fffffff7fffffff7ffdffffffffffffffffffffffffffffffffffffffffffffffffffffffffffffffffffffffffffffffffffffffffffffffffffffffffffffffffffffffffffffffffffffffffffffffffffffffffffffffffffffffffffffffffffffffffffffffffffffffffffffffffffffffffffffffffffffffffffffffffffffffffffffffffffffffffffffffffffffffffffffffffffffffffffffffffffffffffffff'
addr 0x100: *** read compare FAILED ***
b'371500001305058873104530ef0000256f000000130101ff2326810013040101130000000324c1001301010167800000130101ff2326810013040101130000000324c1001301010167800000130101fe232e8100130401022326a4fe8327c4fe739007bc130000000324c1011301010267800000130101ff23261100232481001304010113050000eff05ffcb75700f09387c70123a00700b75700f09387c7001307100023a0e700b75700f09387070183a7070063980700130710002310e0006f008001b75700f09387c7011307100023a0e700130000008320c100032481001301010167800000130101ff2326810013040101130000000324c10013010101'
<----->
b'371500001305058873104530ef0014096f000008130101ff2327811a13048101130404000324c500130dcd0167898c0877898dff33afadfb7beded1b5bcded9b5fedef9a7fedef9b7fcdefbb7fddeffe7fffefff7fffffff7fffffffffffffffffffffff7fffffffffffffffffffffffffffffffffffffffffffffffffffffffffffffffffffffffffffffffffffffffffffffffffffffffffffffffffffffffffffffffffffffffffffffffffffffffffffffffffffffffffffffffffffffffffffffffffffffffffffffffffffffffffffffffffffffffffffffffffffffffffffffffffffffffffffffffffffffffffffffffffffffffffffffffffffffff'
addr 0x200: *** read compare FAILED ***
b'67800000130101ff2326810013040101130000000324c1001301010167800000130101fe232e8100130401022326a4feb75700f09387870023a00700b75700f00327c4fe23a0e700b75700f0938787001307100023a0e700b75700f09387c7001307100023a0e7006f004001b75700f09387c7001307100023a0e700b75700f09387070183a70700e39207fe13000000130000000324c1011301010267800000130101fe232e1100232c81001304010293070500a307f4fe0347f4fe9307a0006316f7001305d000eff09ffd13000000b76700f09387478003a7070093071000e308f7feb76700f0938707800347f4fe23a0e700130000008320c10103248101'
<----->
b'67800000538101ff2327819a33048501138c0c0003accd0813adcd0b7789ad1b77c9adfe7befeffe7fefef9a7fefeffeffffeffeffdfeffaffffefffffffffffffffffff7fffffffffffffffffffffffffffffffffffffffffffffffffffffffffffffffffffffffffffffffffffffffffffffffffffffffffffffffffffffffffffffffffffffffffffffffffffffffffffffffffffffffffffffffffffffffffffffffffffffffffffffffffffffffffffffffffffffffffffffffffffffffffffffffffffffffffffffffffffffffffffffffffffffffffffffffffffffffffffffffffffffffffffffffffffffffffffffffffffffffffffffffffffffff'
addr 0x300: *** read compare FAILED ***
b'1301010267800000130101fe232e1100232c8100130401022326a4fe6f00c0018327c4fe138717002326e4fe83c7070013850700eff0dff68327c4fe83c70700e39007fe13000000130000008320c101032481011301010267800000130101ff232611002324810013040101b73700f0938707801307100023a0e700b73700f09387478023a00700b73700f0938787801307100023a0e700b73700f09387c7801307100023a0e700b70700269387870b372700001307978023a0e700b70700269387470b372700001307978023a0e700b70700269387070b372700001307978023a0e700b70700269387c70a372700001307978023a0e700b70700269387870a'
<----->
b'13850735eff5dff1ffc7ccb63707e40223ade700b7cfee0037cd8f3deffddffbffffeffe7fcfecbe7bedef9affefef9affcfefbffffdfffffffdfffffffdefbbfffdffff7ffdffff7fffffff7fffffffffffffffffffffffffffffffffffffffffffffffffffffffffffffffffffffffffffffffffffffffffffffffffffffffffffffffffffffffffffffffffffffffffffffffffffffffffffffffffffffffffffffffffffffffffffffffffffffffffffffffffffffffffffffffffffffffffffffffffffffffffffffffffffffffffffffffffffffffffffffffffffffffffffffffffffffffffffffffffffffffffffffffffffffffffffffffffffffff'
addr 0x400: *** read compare FAILED ***
b'372700001307978023a0e700b70700269387470a372700001307978023a0e700b70700269387070a371700001307370023a0e700b70700269387c709371700001307370023a0e700b707002693878709371700001307370023a0e700b707002693874709371700001307370023a0e700b707002693870709371700001307370023a0e700b70700269387c708371700001307370023a0e700b707002693878708371700001307370023a0e700b707002693874708371700001307370023a0e700b707002693870708371700001307370023a0e700b70700269387c707371700001307370023a0e700b707002693878707371700001307370023a0e700b7070026'
<----->
b'b707002623a0e700b7c7e40013c50735eff51ff17fc70e808327c4feb38fff9aa3cfef0813cf8f1bb7cfaf3f3fedef3affefef9a7fcfefbffffdffffeffffffeffeffffefffffffe7fffffffffffffffffffffffffffffffffffffffffffffffffffffffffffffffffffffffffffffffffffffffffffffffffffffffffffffffffffffffffffffffffffffffffffffffffffffffffffffffffffffffffffffffffffffffffffffffffffffffffffffffffffffffffffffffffffffffffffffffffffffffffffffffffffffffffffffffffffffffffffffffffffffffffffffffffffffffffffffffffffffffffffffffffffffffffffffffffffffffffffffff'
addr 0x500: *** read compare FAILED ***
b'93874707371700001307370023a0e700b707002693870707371700001307370023a0e700b70700269387c706371700001307370023a0e700b707002693878706371700001307370023a0e700b707002693874706371700001307370023a0e700b707002693870706371700001307370023a0e700b70700269387c705371700001307370023a0e700b707002693878705371700001307370023a0e700b707002693874705371700001307370023a0e700b707002693870705371700001307370023a0e700b70700269387c704371700001307370023a0e700b707002693878704371700001307370023a0e700b707002693874704371700001307370023a0e700'
<----->
b'2326f4feb70700269387070103a7070083a7c4feb377f7082364f4feb707e43e9387070303a786fe23a5e79ab7dfef0037dd8f09effd9ffbffff8fffb78faf3bdbefef1b6bedfffeefeffefe5fefeffeffefefbeffcfefbfffffeffbffffeffaffffeffffffdffffffffffffffffffffffffffffffffffffffffffffffffffffffffffffffffffffffffffffffffffffffffffffffffffffffffffffffffffffffffffffffffffffffffffffffffffffffffffffffffffffffffffffffffffffffffffffffffffffffffffffffffffffffffffffffffffffffffffffffffffffffffffffffffffffffffffffffffffffffffffffffffffffffffffffffffffff'
addr 0x600: *** read compare FAILED ***
b'b707002693870704371700001307370023a0e700b70700269387c703372700001307978023a0e700b707002693878703371700001307370023a0e700b707002693874703371700001307370023a0e700b707002693870703371700001307370023a0e700b70700269387c702371700001307370023a0e700b707002693878702372700001307978023a0e700b70700261307100023a0e70013000000b707002603a7070093071000e30af7feb73700f0938747811307100023a0e700b70700269387c70023a00700b70700269387070123a00700b7177a0013850720eff05fb4b73700f09387478123a00700b7070026938707011307f00323a0e700b7070026'
<----->
b'232c04fcb70700269387c70003a70700832744feb377f7082326f4fe1305a41aeff1fff5ffc7ccb6b787c70203a7c70083af46feb3ffffba23fffffc23afecff83afecff6bedfffaebeffffedbeffffe7feffffeefeffeffefefffff6ffffffeffffeffeffffffffffffffffffffffffffffffffffffffffffffffffffffffffffffffffffffffffffffffffffffffffffffffffffffffffffffffffffffffffffffffffffffffffffffffffffffffffffffffffffffffffffffffffffffffffffffffffffffffffffffffffffffffffffffffffffffffffffffffffffffffffffffffffffffffffffffffffffffffffffffffffffffffffffffffffffffffff'
addr 0x700: *** read compare FAILED ***
b'9387c7001307f0ff23a0e700b7177a0013850720eff0dfb06ff05ff9000000000000000000000000000000000000000000000000000000000000000000000000000000000000000000000000000000000000000000000000000000000000000000000000000000000000000000000000000000000000000000000000000000000000000000000000000000000000000000000000000000000000000000000000000000000000000000000000000000000000000000000000000000000000000000000000000000000000000000000000000000000000000000000000000000000000000000000000000000000000000000000000000000000000000000000000'
<----->
b'37ffefff7fffffff7fffffffffffffffffffffffffffffffffffffffffffffffffffffffffffffffffffffffffffffffffffffffffffffffffffffffffffffffffffffffffffffffffffffffffffffffffffffffffffffffffffffffffffffffffffffffffffffffffffffffffffffffffffffffffffffffffffffffffffffffffffffffffffffffffffffffffffffffffffffffffffffffffffffffffffffffffffffffffffffffffffffffffffffffffffffffffffffffffffffffffffffffffffffffffffffffffffffffffffffffffffffffffffffffffffffffffffffffffffffffffffffffffffffffffffffffffffffffffffffffffffffffffffffff'

total_bytes = 2048
pll_trim = b'09'

rm blink.elf
```

hugodiasg, 2024-07-24:
I changed the USB of the STM32 Nucleo Board to a higher quality one and it works

Closed 2024-07-24.

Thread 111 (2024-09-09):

GFMPW-1 read compare FAILED

gonsolo, 2024-09-09:
I try to test my GFMPW-1 chip that I received last week.

Connecting the board via USB results in the following dmesg (with a harmless warning, I believe):
```
[ 9. Sep 11:55] usb 5-1: new high-speed USB device number 3 using xhci_hcd
[  +0,142033] usb 5-1: New USB device found, idVendor=0403, idProduct=6014, bcdDevice= 9.00
[  +0,000007] usb 5-1: New USB device strings: Mfr=1, Product=2, SerialNumber=0
[  +0,000005] usb 5-1: Product: Single RS232-HS
[  +0,000003] usb 5-1: Manufacturer: FTDI
[  +0,000902] ftdi_sio 5-1:1.0: FTDI USB Serial Device converter detected
[  +0,000046] usb 5-1: Detected FT232H
[  +0,001524] usb 5-1: FTDI USB Serial Device converter now attached to ttyUSB0
[ +46,767251] usb 5-1: usbfs: interface 0 claimed by ftdi_sio while 'python3' sets config #1
[  +0,003442] ftdi_sio ttyUSB0: FTDI USB Serial Device converter now disconnected from ttyUSB0
[  +0,000020] ftdi_sio 5-1:1.0: device disconnected
[ 9. Sep 11:56] ftdi_sio 5-1:1.0: FTDI USB Serial Device converter detected
[  +0,000060] usb 5-1: Detected FT232H
[  +0,001425] usb 5-1: FTDI USB Serial Device converter now attached to ttyUSB0
```

Building the firmware via ```make clean hex``` in chipignite/blink works, I had to adjust the Makefile to:
```
TOOLCHAIN_PATH=/home/gonsolo/bin/
TOOLCHAIN_PREFIX=riscv64-unknown-linux-gnu
ARCH=rv32i_zicsr
```

But flashing the chip fails with:
```
gonsolo blink:sudo make flash
python3 ../util/caravel_hkflash.py blink.hex
Success: Found one matching FTDI device at ftdi://ftdi:232h:5:3/1
Caravel data:
   mfg        = 0456
   product    = 20
   project ID = 1801a030

Resetting Flash...
status = 0x00
JEDEC = ef4016
Erasing chip...
..............................done
status = 0x00
setting address to 0x0
addr 0x0: flash page write successful
addr 0x100: flash page write successful
addr 0x200: flash page write successful
addr 0x300: flash page write successful
addr 0x400: flash page write successful
addr 0x500: flash page write successful
addr 0x600: flash page write successful
addr 0x700: flash page write successful
addr 0x800: flash page write successful
addr 0x900: flash page write successful
addr 0xa00: flash page write successful
addr 0xb00: flash page write successful
addr 0xc00: flash page write successful
addr 0xd00: flash page write successful
addr 0xe00: flash page write successful
setting address to 0xf00
addr 0xf00: flash page write successful
setting address to 0x1000
addr 0x1000: flash page write successful
setting address to 0x1024
addr 0x1024: flash page write successful
setting address to 0x1048
addr 0x1048: flash page write successful
setting address to 0x10d8
addr 0x10d8: flash page write successful
setting address to 0x1114
addr 0x1114: flash page write successful
setting address to 0x1154
addr 0x1154: flash page write successful
addr 0x1254: flash page write successful
addr 0x1354: flash page write successful
setting address to 0x13ec
addr 0x13ec: flash page write successful
setting address to 0x1478
addr 0x1478: flash page write successful
setting address to 0x14cc
addr 0x14cc: flash page write successful
setting address to 0x154c
addr 0x154c: flash page write successful
setting address to 0x156c
addr 0x156c: flash page write successful

total_bytes = 5486
status reg_1 = 0x0
status reg_2 = 0x2
************************************
verifying...
************************************
status reg_1 = 0x0
status reg_2 = 0x2
setting address to 0x0
addr 0x0: read compare successful
addr 0x100: read compare successful
addr 0x200: read compare successful
addr 0x300: read compare successful
addr 0x400: read compare successful
addr 0x500: read compare successful
addr 0x600: read compare successful
addr 0x700: read compare successful
addr 0x800: read compare successful
addr 0x900: read compare successful
addr 0xa00: read compare successful
addr 0xb00: read compare successful
addr 0xc00: read compare successful
addr 0xd00: read compare successful
addr 0xe00: read compare successful
setting address to 0xf00
addr 0xf00: read compare successful
setting address to 0x1000
addr 0x1000: *** read compare FAILED ***
b'2f6c69622f6c642d6c696e75782d726973637633322d696c7033322e736f2e3100'
<----->
b'0f646060246044206c6900556020726100637633322d696c7033322e736f2e3100'
setting address to 0x1024
addr 0x1024: read compare successful
setting address to 0x1048
addr 0x1048: read compare successful
setting address to 0x10d8
addr 0x10d8: *** read compare FAILED ***
b'005f6664617461005f65627373005f66737461636b00747261705f656e747279005f6564617461005f66646174615f726f6d005f6662737300'
<----->
b'005f6664617461005f65627373005f66737461636b00747261705f656e747279005f65646174610044c80c0210440e0024000000b80000000c'
setting address to 0x1114
addr 0x1114: *** read compare FAILED ***
b'030000000200000002000000060000001820a42809220200020000000600000007000000c45de7ec702aef0e4245d5ecd3b6ef0e71ab5ea9e0a0ec8a4d3f4a01'
<----->
b'0000000000000000000000000200000000008000080002000000000004000000000000000050e7ec20000000004404004080010800000c080000c000480c0200'
setting address to 0x1154
addr 0x1154: *** read compare FAILED ***
b'1000000000000000037a5200017c01011b0c02002400000018000000b8efffff2400000000440e104881018802440c080048c144c80c0210440e00002400000040000000b4efffff2400000000440e104881018802440c080048c144c80c0210440e00002400000068000000b0efffff3000000000440e204881018802440c080054c144c80c0220440e00002400000090000000b8efffff7c00000000440e104881018802440c08000260c144c80c0210440e0024000000b80000000cf0ffff2400000000440e104881018802440c080048c144c80c0210440e000024000000e000000008f0ffff2400000000440e104881018802440c080048c144c80c0210'
<----->
b'1000000000000000037a5200017c01011b0c02002400000018000000b8efffff2400000000440e104881018802440c080048c144c80c0210440e00002400000040000000b4efffff2400000000440e104881018802440c080048c144c80c0210440e00002400000068000000b0efffff3000000000440e204881018802440c080054c144c80c0220440e00002400000090000000b8efffff7c00000000440e104881018802440c08000260c1ac010000f0f4ffffb801000000440e204881018802440c0800039c01c144c80c0220440e0000000024000000d80100007cf6ffff2400000000440e104881018802440c080048c144c80c0210440e000024000000'
addr 0x1254: *** read compare FAILED ***
b'440e0000240000000801000004f0ffff6800000000440e204881018802440c0800024cc144c80c0220440e00240000003001000044f0ffff5400000000440e204881018802440c080078c144c80c0220440e0000240000005801000070f0ffff8800000000440e304881018802440c0800026cc144c80c0230440e002800000080010000d0f0ffff4c04000000440e204881018802440c0800033004c144c80c0220440e0000000028000000ac010000f0f4ffffb801000000440e204881018802440c0800039c01c144c80c0220440e0000000024000000d80100007cf6ffff2400000000440e104881018802440c080048c144c80c0210440e000024000000'
<----->
b'440e0000240000000801000004f0ffff6800000000440e204881018802440c0800024cc144c80c0220440e00240000003001000044f0ffff5400000000440e204881018802440c080078c144c80c0220440e0000240000005801000070f0ffff8800000000440e304881018802440c0800026cc144c80c0230440e002800000080010000d0f0ffff4c04000000440e204881018802440c0800033004c144c80c0220440e000000002800000060edffffa4fdffff84edffffccfdffffb4edfffff4fdffff30eeffff1cfeffff54eeffff44feffff78eeffff6cfeffffe0eeffff94feffff34efffffbcfeffffbcefffffe4feffff08f4ffff10ffffffc0f5ffff'
addr 0x1354: *** read compare FAILED ***
b'0002000078f6ffff2400000000440e104881018802440c080048c144c80c0210440e0000280000002802000074f6ffff2c03000000440e104881018802440c0800031003c144c80c0210440e00000000240000005402000074f9ffff8800000000440e204881018802440c0800026cc144c80c0220440e001c0000007c020000d4f9ffff4401000000440e104881018802440c0800000000'
<----->
b'0002000060f4ffff2400000000440e100881018800400c080048c14488080210400e0000280000002802000074f6ffff2c03000000440e104881018802440c0800031003c144c80c0210440e00000000240000005402000074f9ffff8800000000440e204881018802440c0800026cc144c80c0220440e001c0000007c020000d4f9ffff4401000000440e104881018802440c0800000000'
setting address to 0x13ec
addr 0x13ec: *** read compare FAILED ***
b'011b033b64fdffff100000003cedffff7cfdffff60edffffa4fdffff84edffffccfdffffb4edfffff4fdffff30eeffff1cfeffff54eeffff44feffff78eeffff6cfeffffe0eeffff94feffff34efffffbcfeffffbcefffffe4feffff08f4ffff10ffffffc0f5ffff3cffffffe4f5ffff64ffffff08f6ffff8cffffff34f9ffffb8ffffffbcf9ffffe0ffffff'
<----->
b'011b033b64fdffff100000003cedffff7cfdffff781400100800000054000000090000000c000000fbffff6f00000008f9ffff6f0700000000000000000000000000000000000000000000000000000000000000000000000000000000000000ffffffffffffffffffffffffffffffffffffffffffffffffffffffffffffffffffffffffffffffffffffffff'
setting address to 0x1478
addr 0x1478: read compare successful
setting address to 0x14cc
addr 0x14cc: *** read compare FAILED ***
b'f5feff6f1411001005000000d810001006000000481000100a000000390000000b00000010000000150000000000000007000000781400100800000054000000090000000c000000fbffff6f00000008f9ffff6f0700000000000000000000000000000000000000000000000000000000000000000000000000000000000000'
<----->
b'f5feff6f1411001005000000d810001006000000481000100a000000390000000b00000010000000150000000000000007000000ffffffffffffffffffffffffffffffffffffffffffffffffffffffffffffffffffffffffffffffffffffffffffffffffffffffffffffffffffffffffffffffffffffffffffffffffffffffff'
setting address to 0x154c
addr 0x154c: read compare successful
setting address to 0x156c
addr 0x156c: read compare successful

total_bytes = 5486
pll_trim = b'ffefff03'
```

Any idea what went wrong?

gonsolo, 2024-09-09:
After playing around with it for a while nothing works anymore:
```
Success: Found one matching FTDI device at ftdi://ftdi:232h:5:3/1
Caravel data:
   mfg        = 0000
   product    = 00
   project ID = 00000000
Incorrect MFG value, expected 0x0456.
```
What's wrong now?

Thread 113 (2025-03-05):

Regarding logic analyzer input/output directionality in firmware and SoC

jainsoumil2, 2025-03-05:
I had a question regarding the logic analyzer input and output connections between the user area caravel/caravan core from/to the management RISC-V core. From the Verilog files used during the design phase for instantiating the user area project, [user_analog_project_wrapper.v](https://github.com/efabless/caravel/blob/main/verilog/rtl/__user_analog_project_wrapper.v), la_data_in is an input connection into the user area, driven by the RISC-V management core, and la_data_out is an output connection from the user area. Is that the correct understanding regarding the direction of input and outputs for logic analyzer signals?

However, based on the firmware code like [demos.c](https://github.com/efabless/caravel_board/blob/main/firmware/chipignite/demos/demos.c) and [openframe_pinout](https://github.com/efabless/caravel/blob/main/docs/pdf/openframe_pinout.pdf), it suggests the opposite, where la_input is input to the management core instead of the user area. This is causing some confusion on our end. See the relevant section from [demos.c](https://github.com/efabless/caravel_board/blob/main/firmware/chipignite/demos/demos.c)

```
// write data to LA output
  reg_la0_data = 0x00;
  reg_la1_data = 0x00;
  reg_la2_data = 0x00;
  reg_la3_data = 0x00;

  // read data from LA input
  data0 = reg_la0_data_in;
  data1 = reg_la1_data_in;
  data2 = reg_la2_data_in;
  data3 = reg_la3_data_in;
  #endif

```
In our design, we have outputs from the user analog core, two of them shown here called latch_high1 and latch_high2, connected to la_data_out[100] and la_data_out[99]. They are latched data outputs of two 1-bit dynamic comparators. We were testing the dynamic comparators by tuning their differential inputs, and checking if the outputs would flip if one of the input is greater than the other. We always see a 0 output over the logic analyzer ports. One of the inputs to the comparator, the reference voltage, comes directly from a gpio pad, which we have configured as GPIO_MODE_USER_STD_ANALOG. We have control over the other input as well and we can tune its voltage. Could there be any issue because of the way we are reading out the logic analyzer from management SoC through our firmware code? The firmware C code is attached here, blink_modified.txt

[blink_modified.txt](https://github.com/user-attachments/files/19094920/blink_modified.txt)

 (we modified demos.c and blink.c).

Samarthjainabout, 2025-04-07:
Opposite. So CPU drives the user area with La data out register.

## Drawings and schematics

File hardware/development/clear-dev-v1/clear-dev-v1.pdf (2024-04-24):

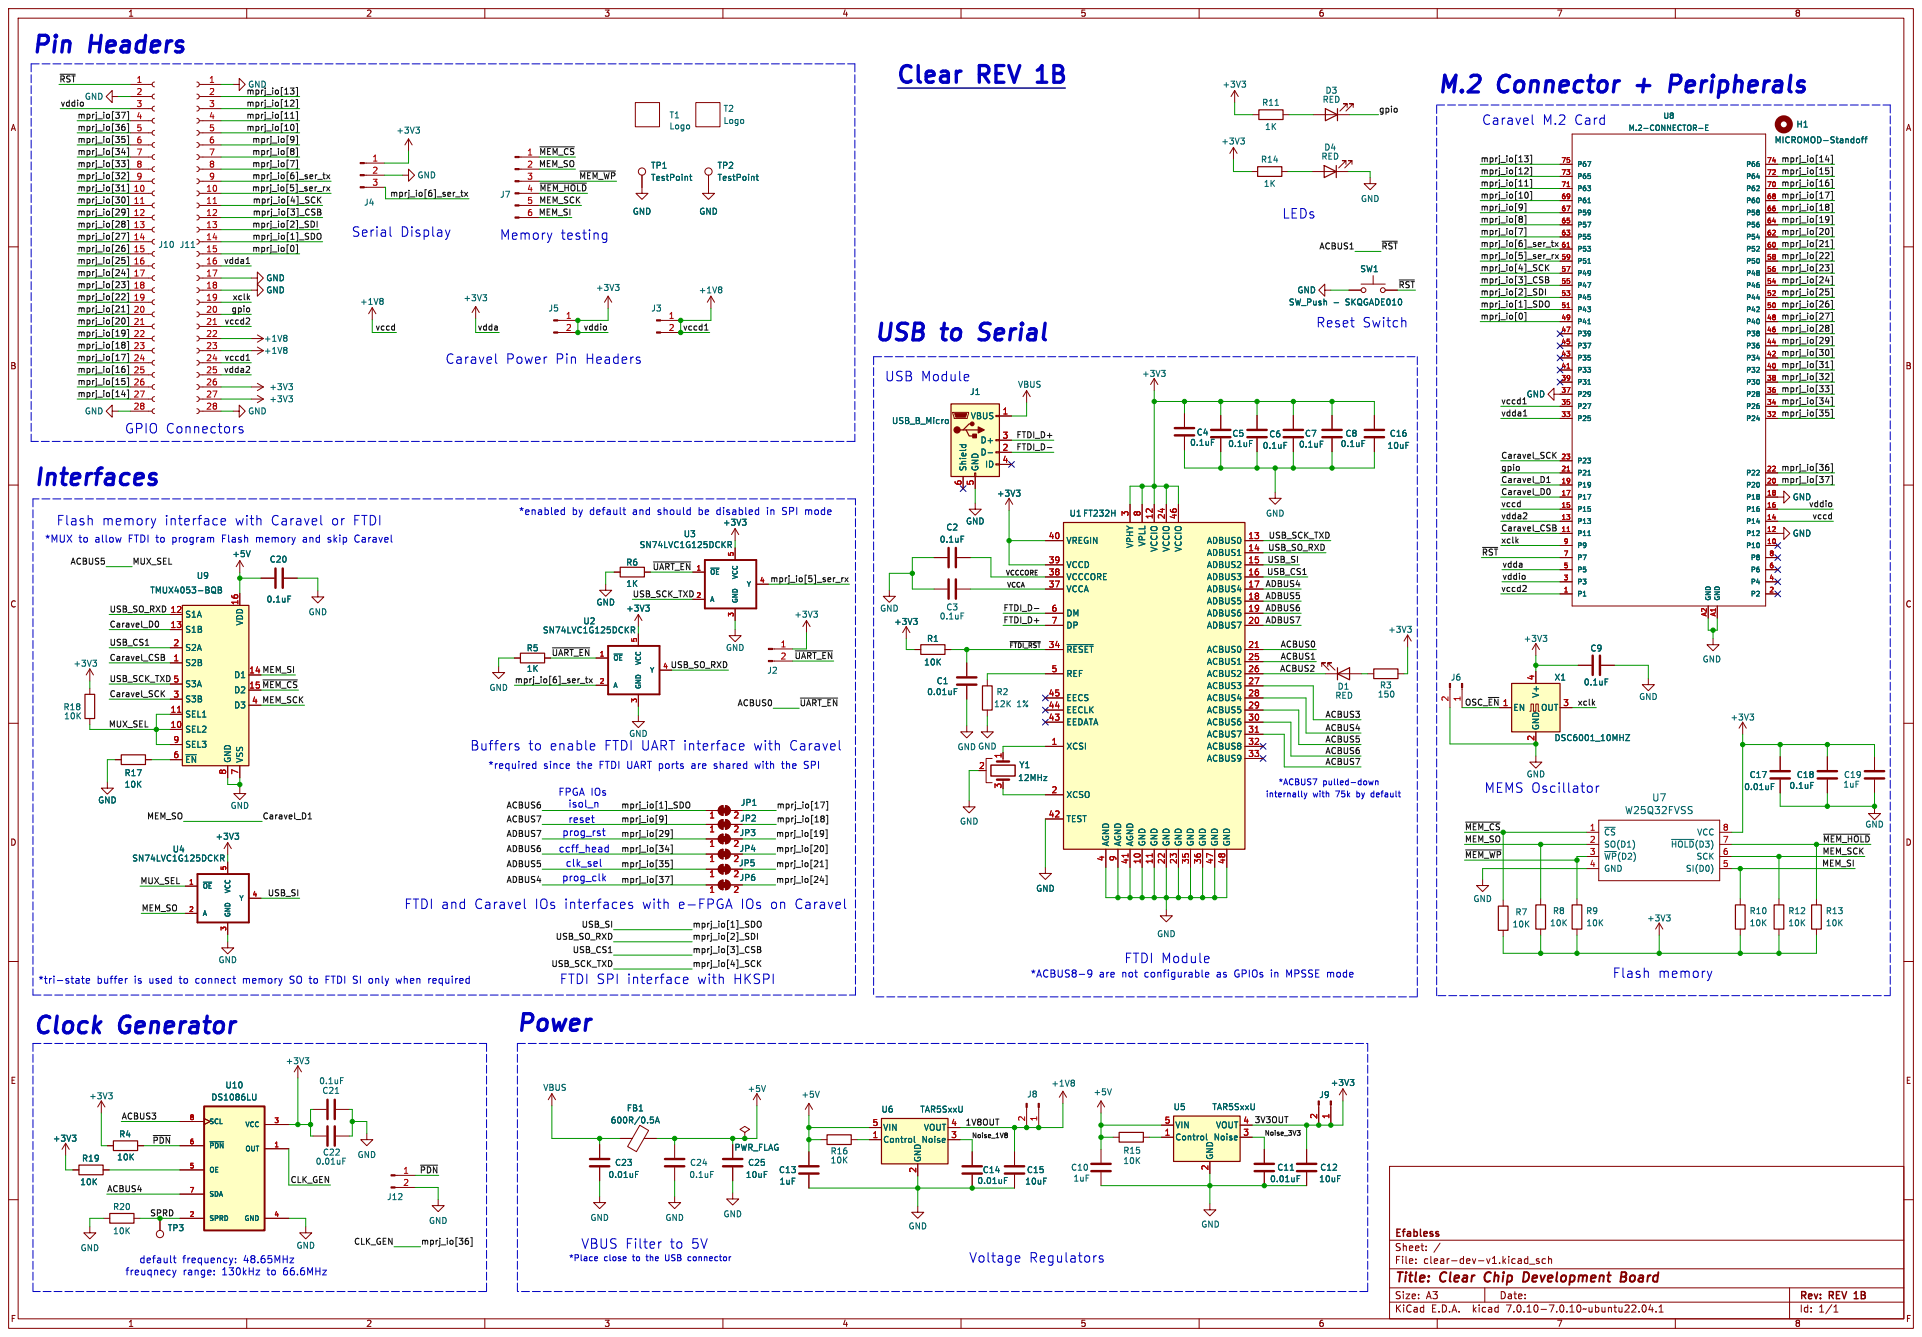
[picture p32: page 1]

Caravel Power Pin Headers

4 VREGIN 40 AGND 41 TEST 42 EEDATA 43 EECLK 44 EECS 45 VCCIO 46 GND 47 GND 48 REF 5 DM 6 DP 7 VPLL

3 ACBUS6 30 ACBUS7 31 ACBUS8 32 ACBUS9 33 ~{RESET} 34 GND 35 GND 36 VCCA 37 VCCCORE 38 VCCD 39 AGND

2 Noise 3 VOUT 4 VIN 5 U5 TAR5SxxU GND GND

File: clear-dev-v1.kicad_sch Sheet: / Efabless

*Place close to the USB connector VBUS Filter to 5V

Id: 1/1 Title: Clear Chip Development Board

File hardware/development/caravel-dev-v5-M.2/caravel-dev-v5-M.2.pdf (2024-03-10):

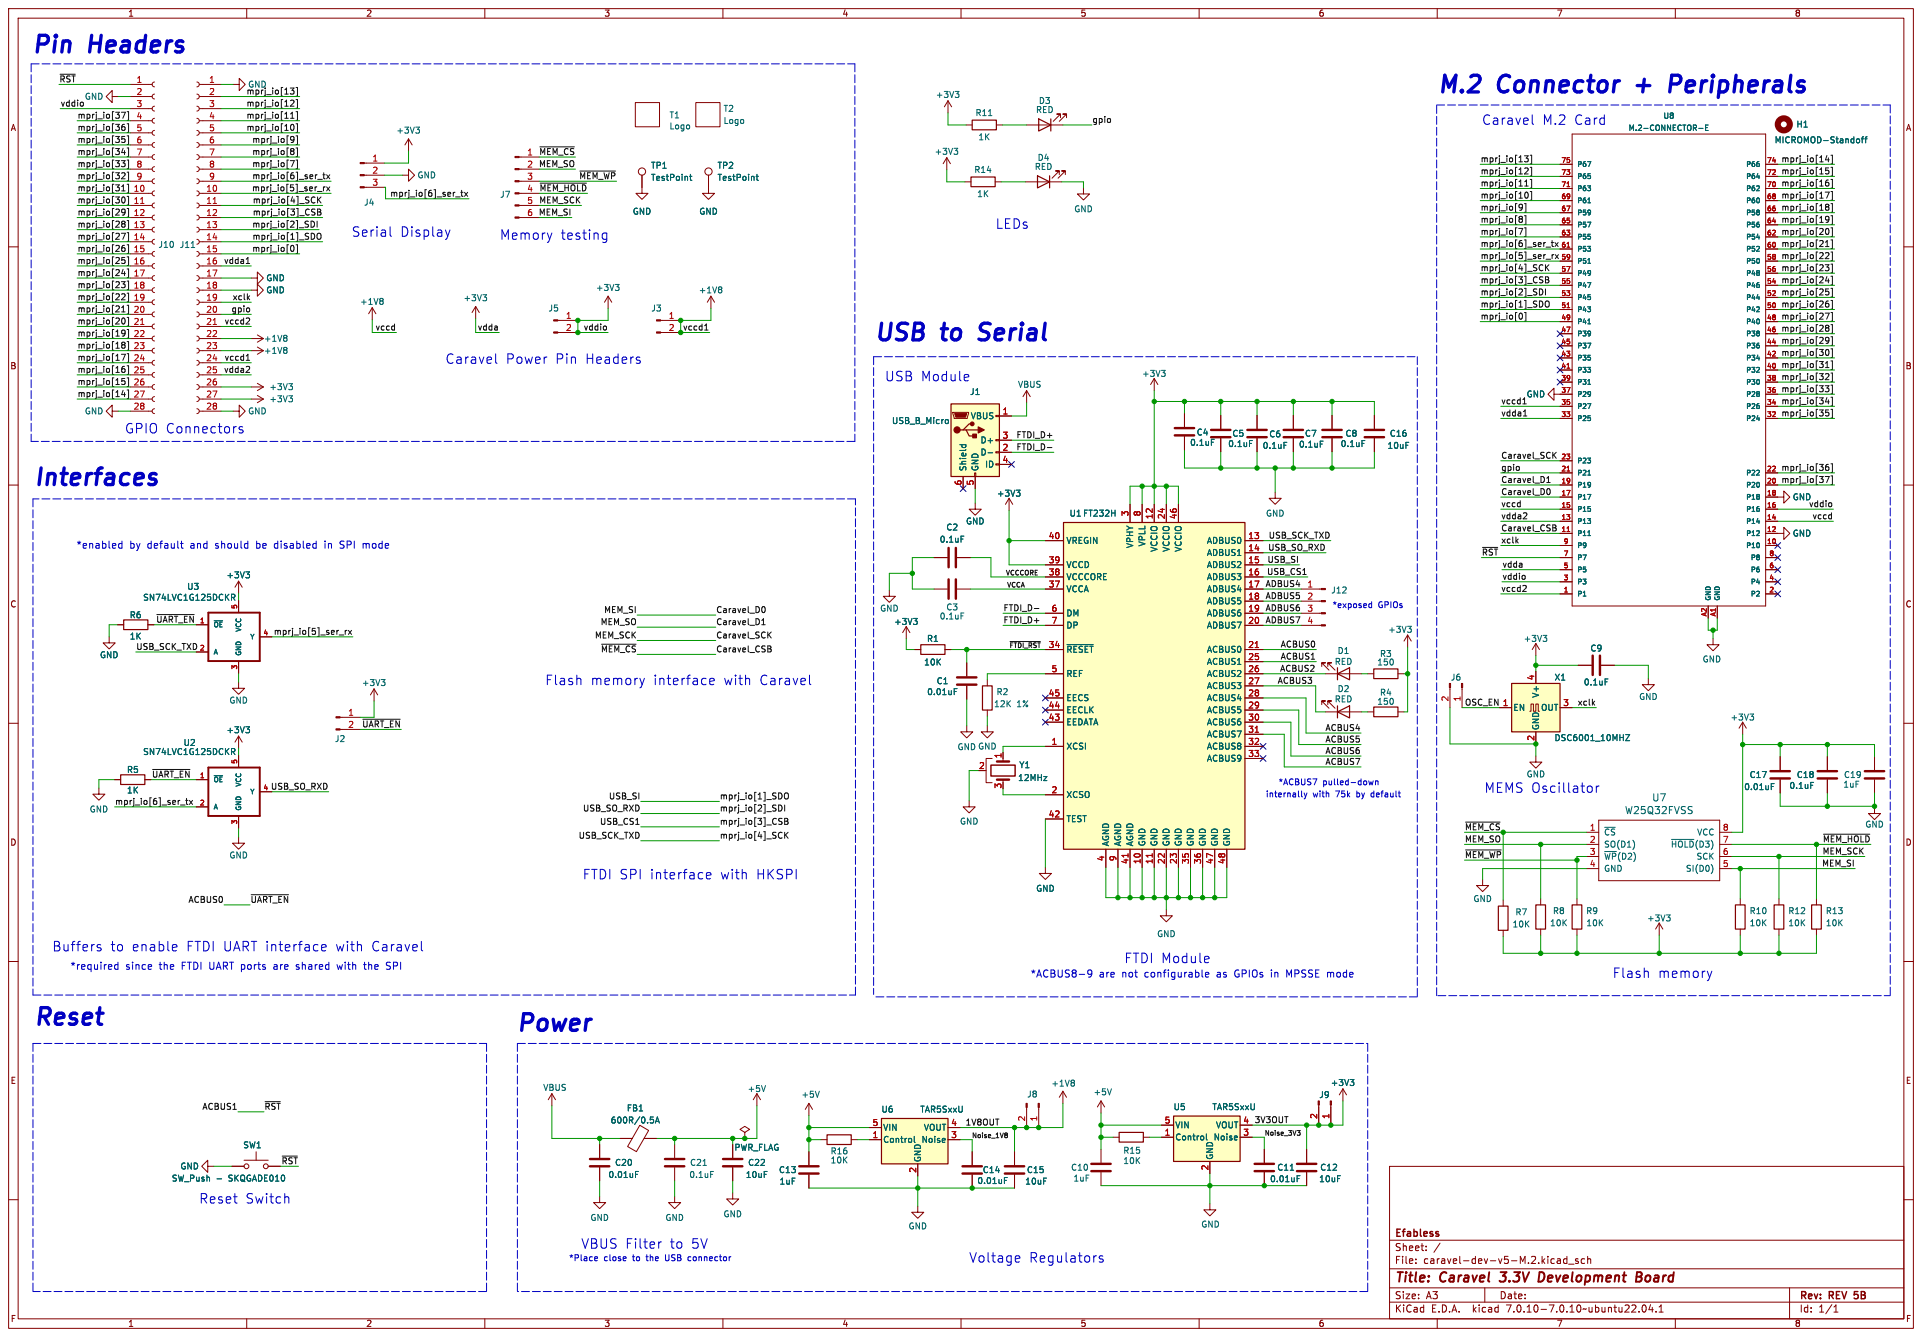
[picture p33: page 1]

*exposed GPIOs USB to Serial
+3V3VBUS

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

File: caravel-dev-v5-M.2.kicad_sch Sheet: / Efabless

VBUS Filter to 5V
*Place close to the USB connector

Id: 1/1 Title: Caravel 3.3V Development Board

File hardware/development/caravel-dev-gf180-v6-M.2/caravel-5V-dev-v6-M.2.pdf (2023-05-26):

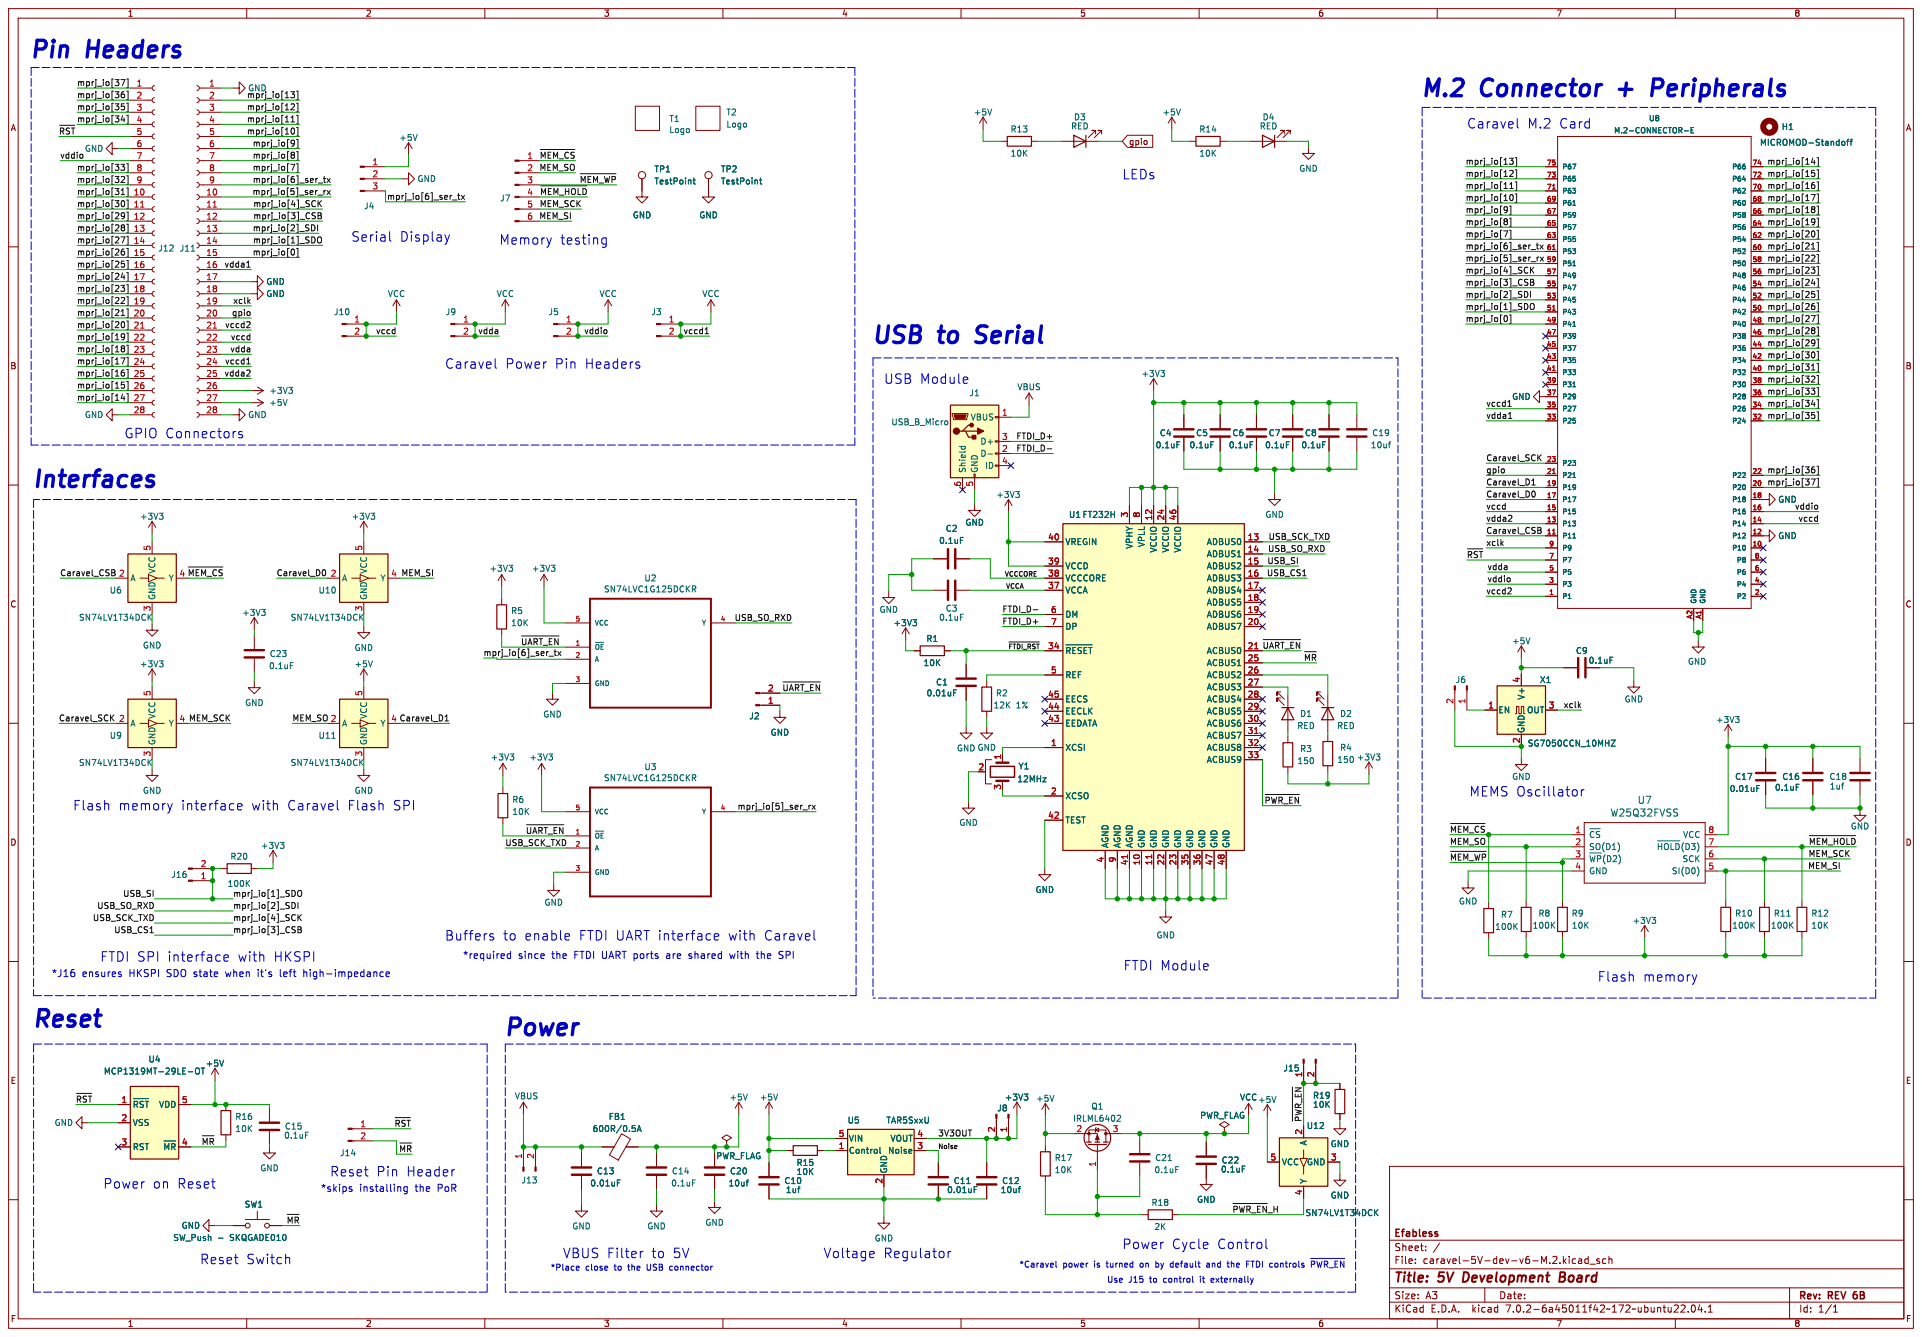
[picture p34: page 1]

Caravel Power Pin Headers

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

*J16 ensures HKSPI SDO state when it's left high-impedance
Reset

2 Noise 3 VOUT 4 VIN 5 +5V U4 MCP1319MT-29LE-OT

File: caravel-5V-dev-v6-M.2.kicad_sch Sheet: / Efabless

*Place close to the USB connector VBUS Filter to 5V

Id: 1/1 Title: 5V Development Board

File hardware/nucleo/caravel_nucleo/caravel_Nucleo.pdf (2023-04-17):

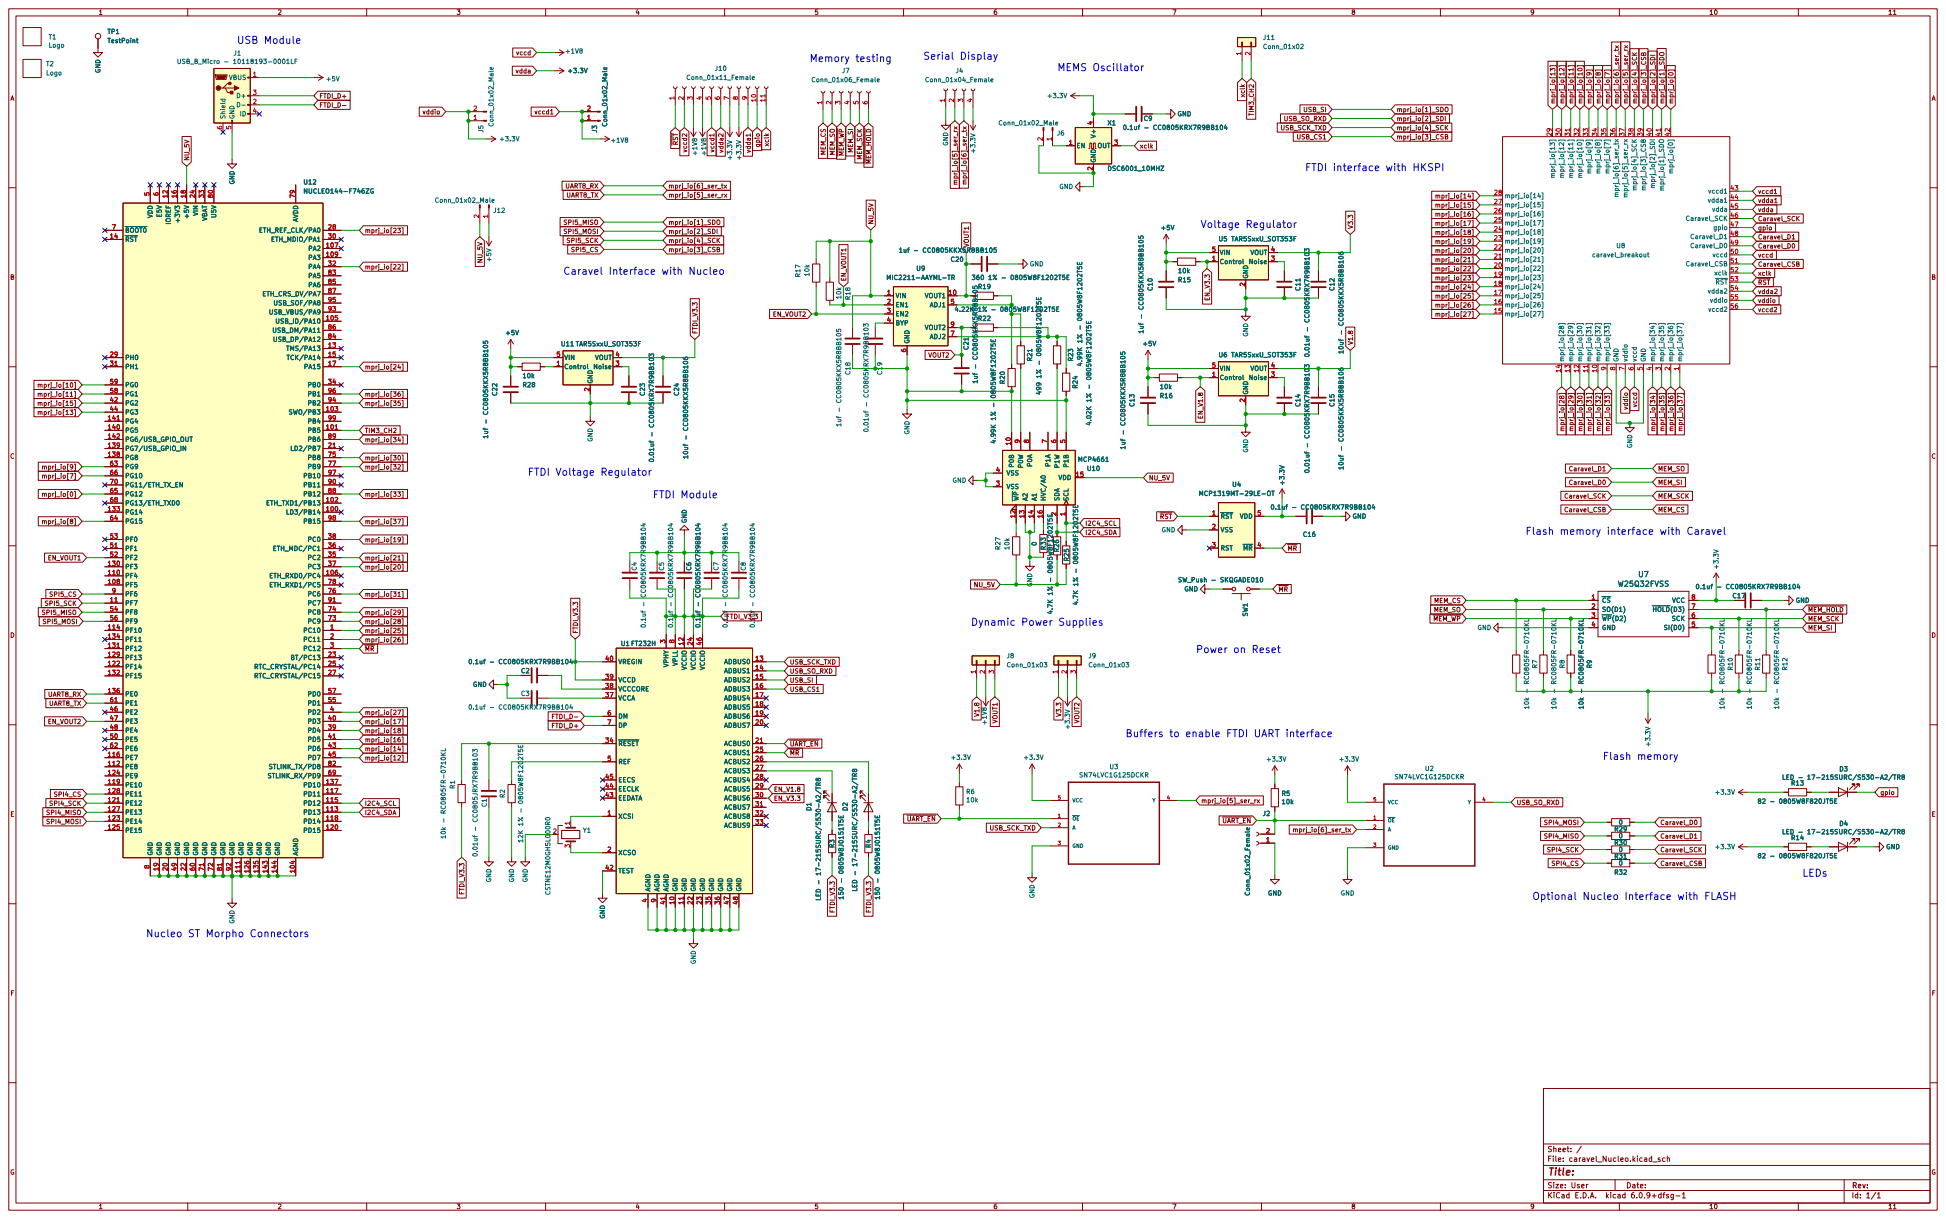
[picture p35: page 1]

2 Noise 3 VOUT 4 VIN 5 U11 TAR5SxxU_SOT353F GND +3.3V

FTDI interface with HKSPI

1 P0B 10 ~{WP} 12 A2 13 A1 14 VDD 15 HVC/A0 16 SDA

Flash memory interface with Caravel

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

Buffers to enable FTDI UART interface

Optional Nucleo Interface with FLASH

Nucleo ST Morpho Connectors

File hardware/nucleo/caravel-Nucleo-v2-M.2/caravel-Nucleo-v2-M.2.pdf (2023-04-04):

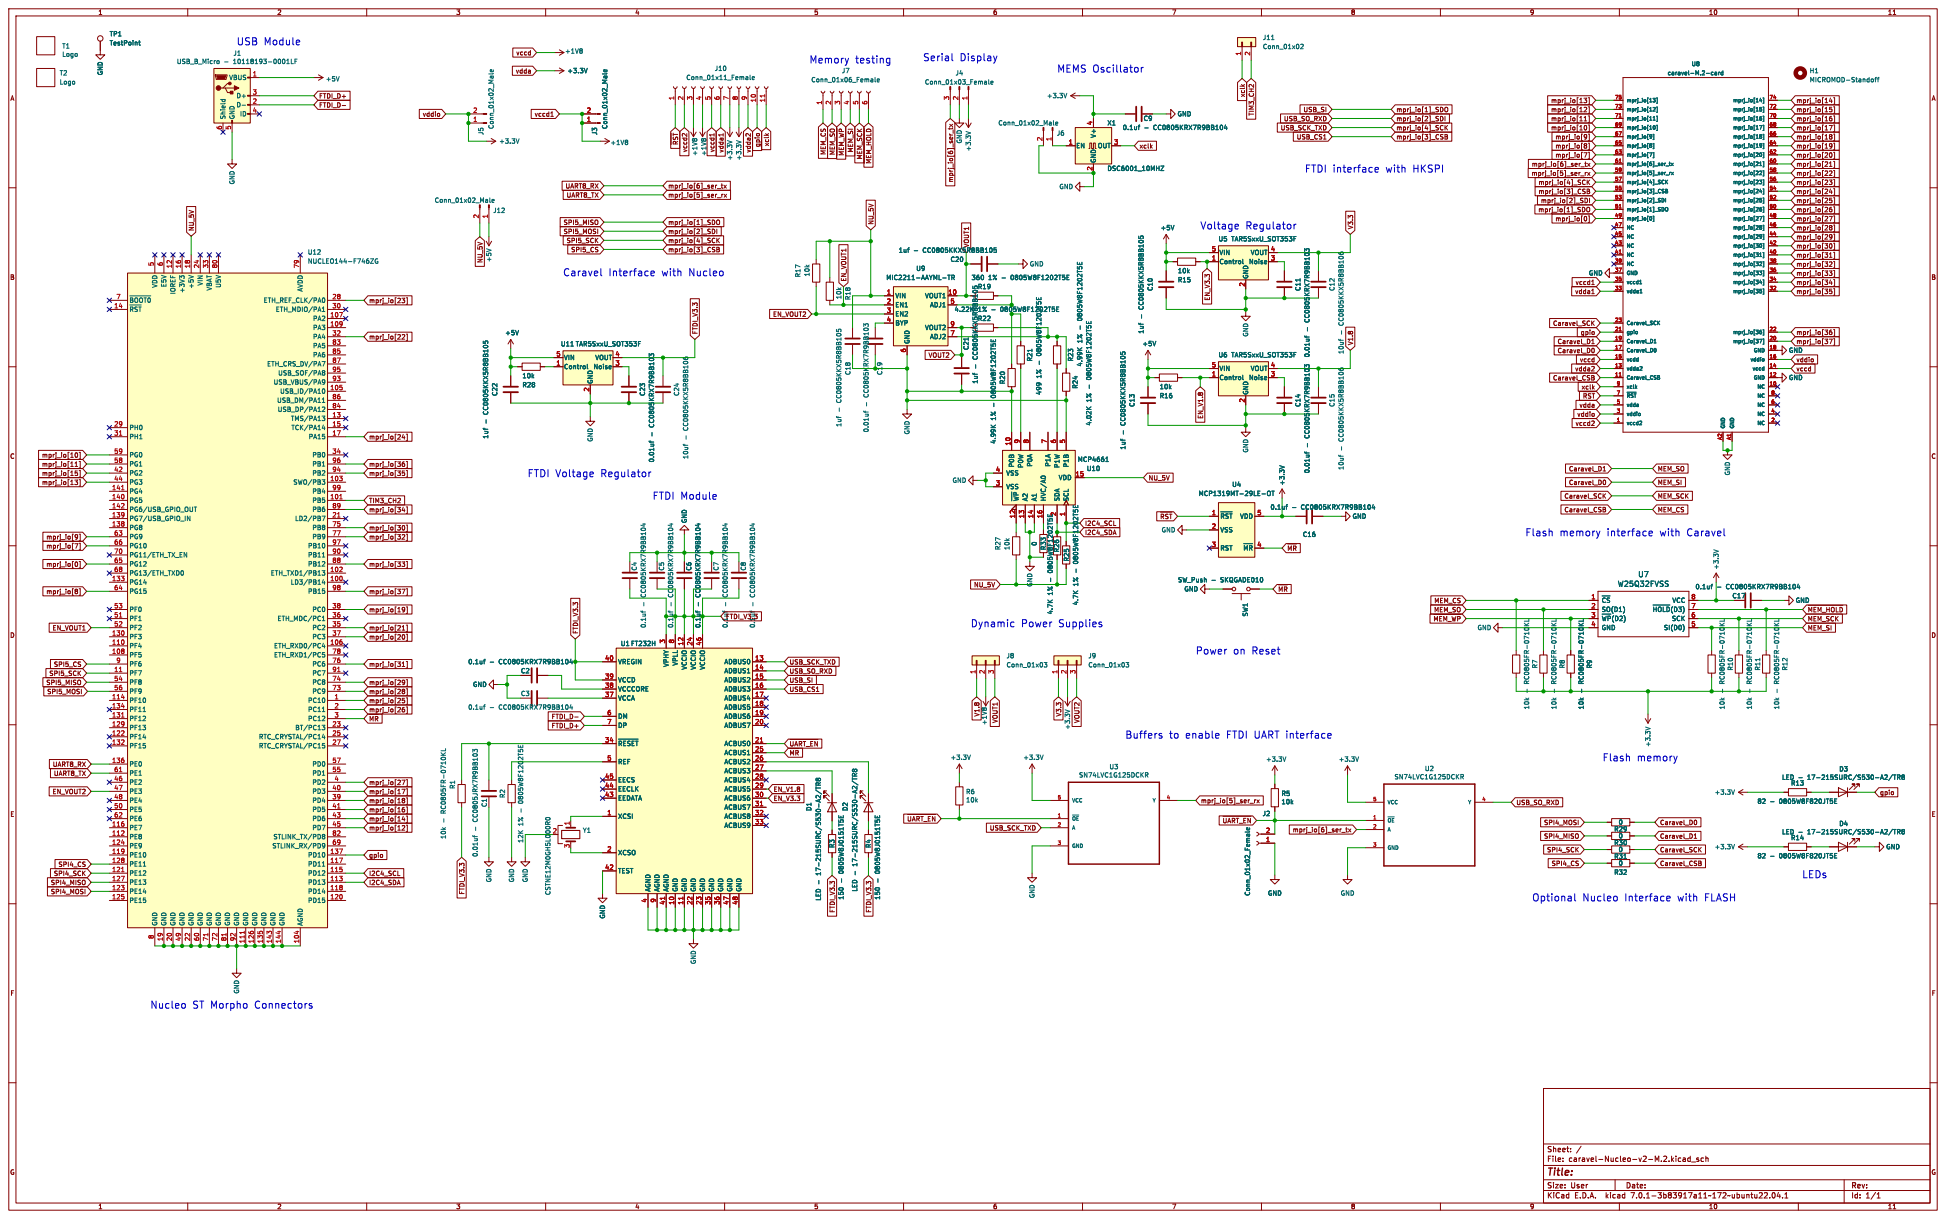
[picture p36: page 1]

SPI5_CS
Caravel Interface with Nucleo

2 Noise 3 VOUT 4 VIN 5 U11 TAR5SxxU_SOT353F GND C24 10uf - CC0805KKX5R8BB106

1 P0B 10 ~{WP} 12 A2 13 A1 14 VDD 15 HVC/A0 16 SDA

~{CS} 1 SO(D1) 2 ~{WP}(D2) 3 GND

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

Buffers to enable FTDI UART interface

Optional Nucleo Interface with FLASH

Id: 1/1 Title: File: caravel-Nucleo-v2-M.2.kicad_sch Sheet: /

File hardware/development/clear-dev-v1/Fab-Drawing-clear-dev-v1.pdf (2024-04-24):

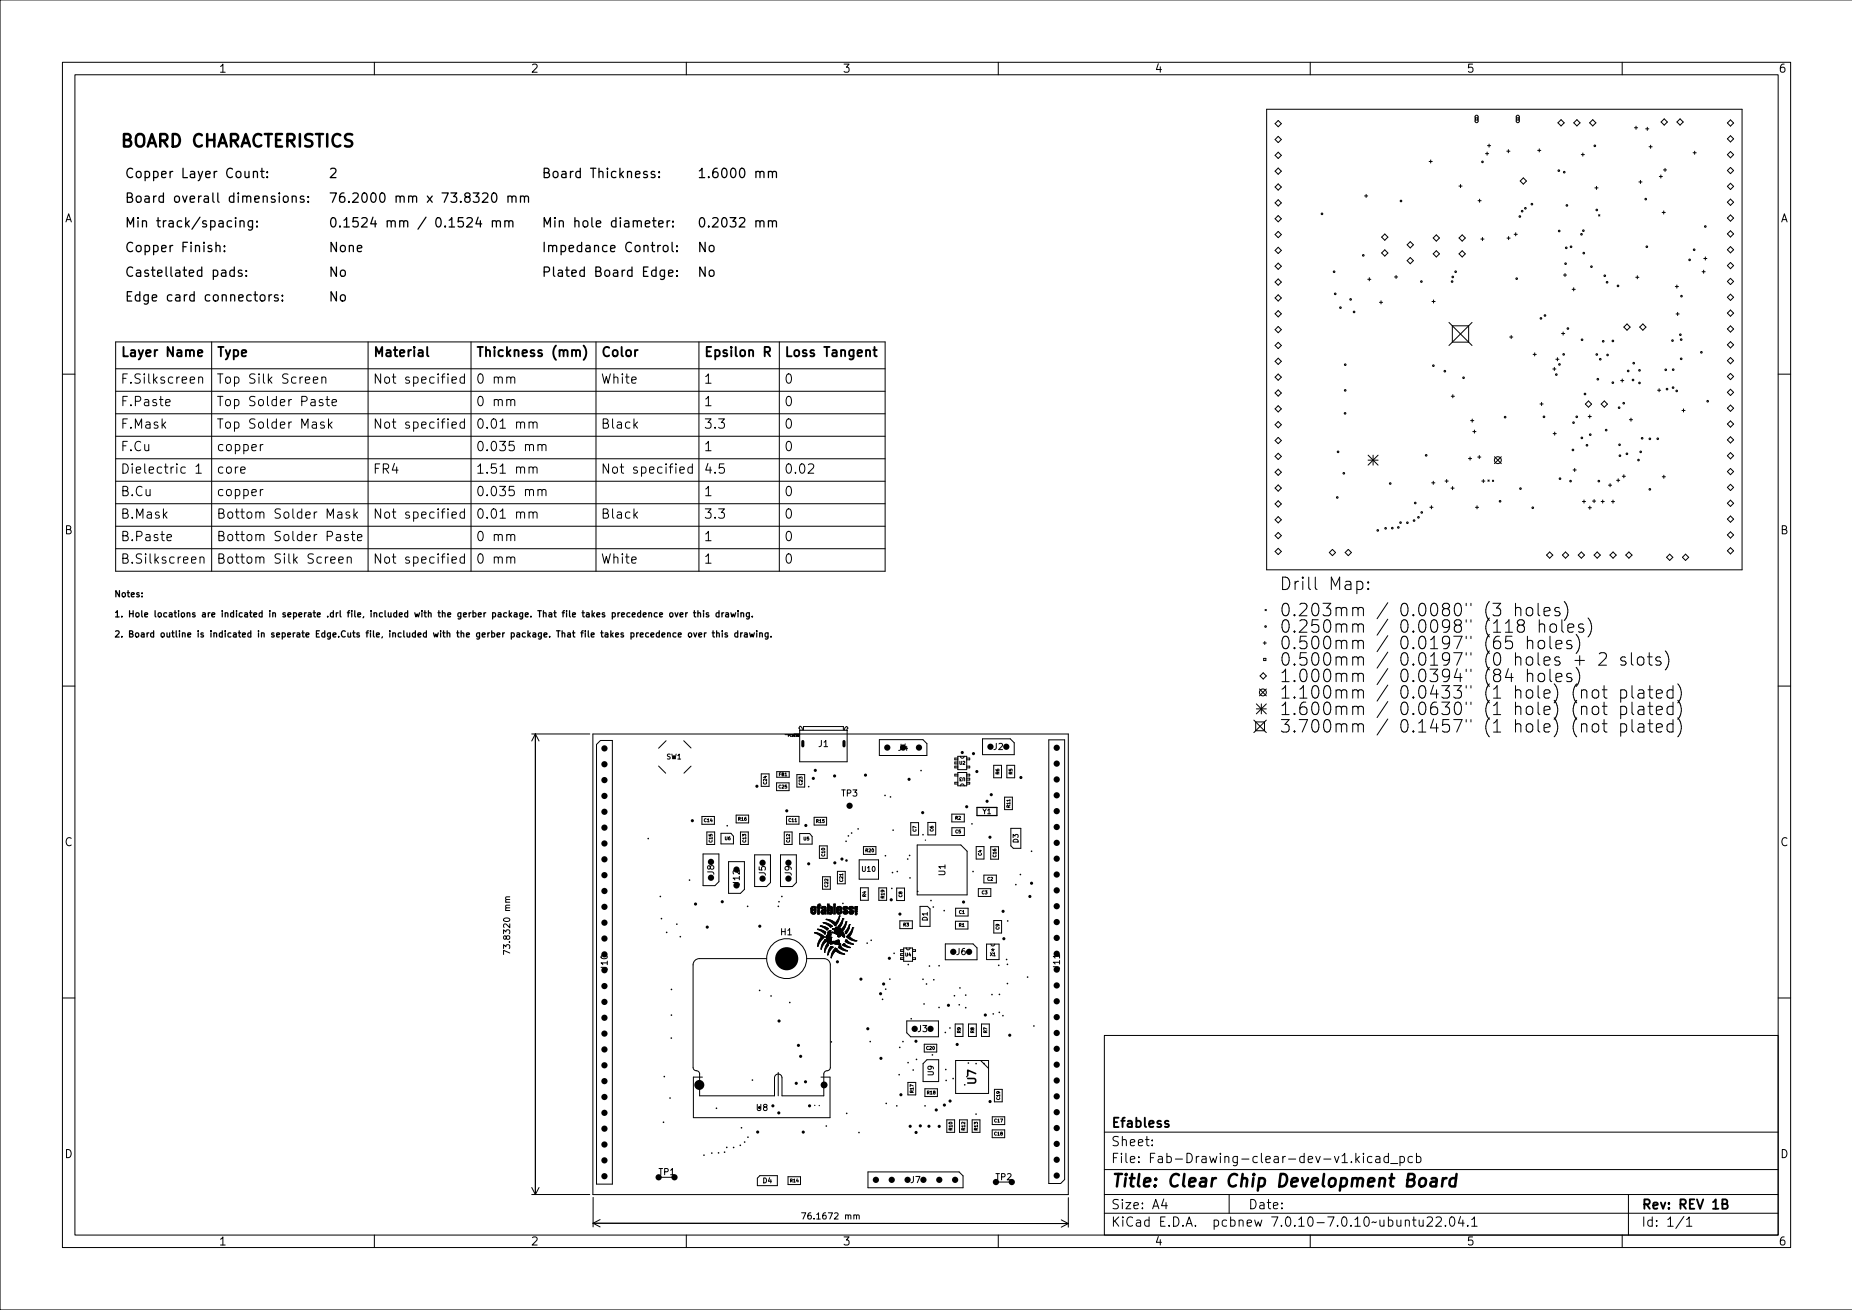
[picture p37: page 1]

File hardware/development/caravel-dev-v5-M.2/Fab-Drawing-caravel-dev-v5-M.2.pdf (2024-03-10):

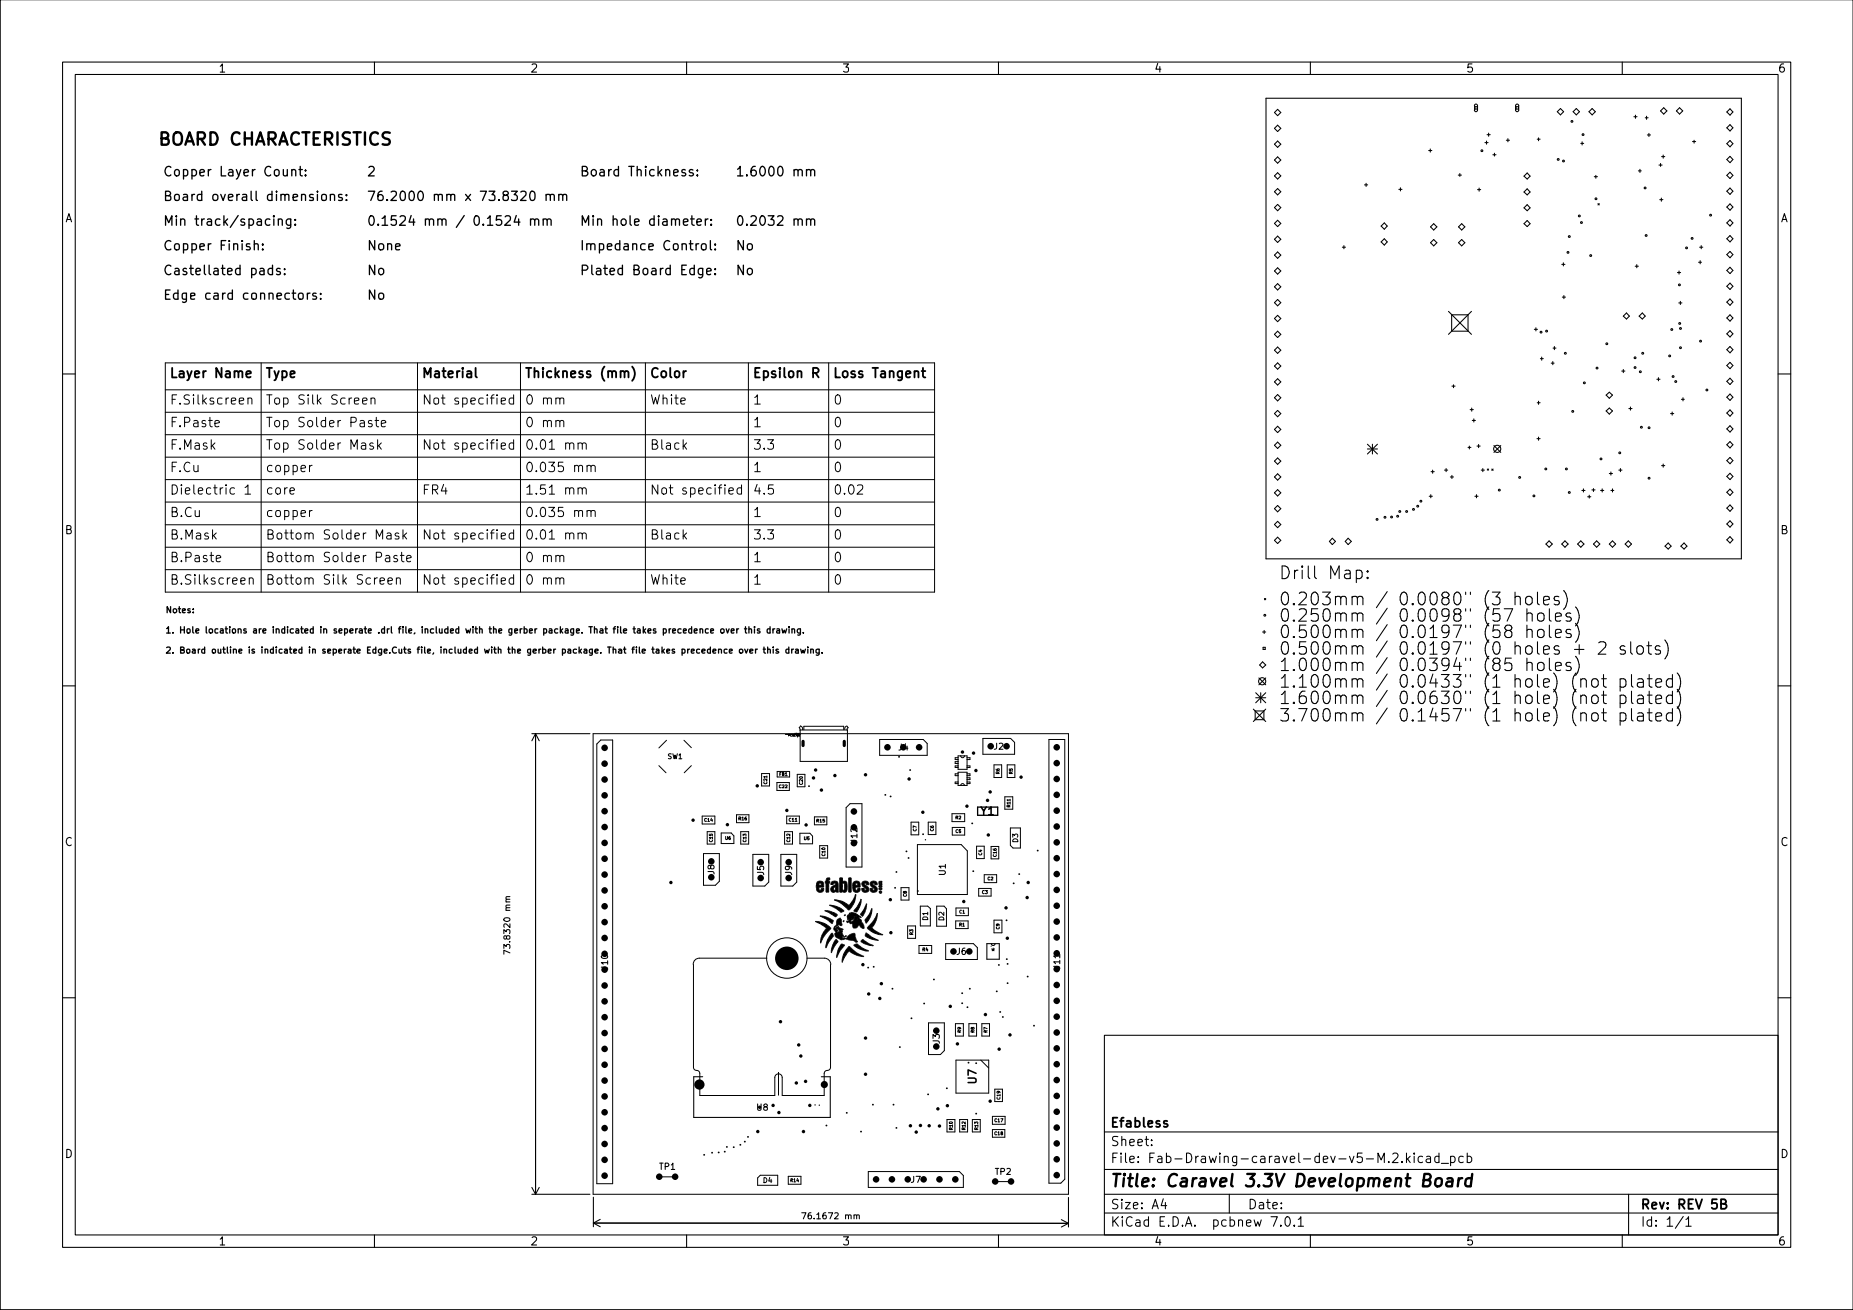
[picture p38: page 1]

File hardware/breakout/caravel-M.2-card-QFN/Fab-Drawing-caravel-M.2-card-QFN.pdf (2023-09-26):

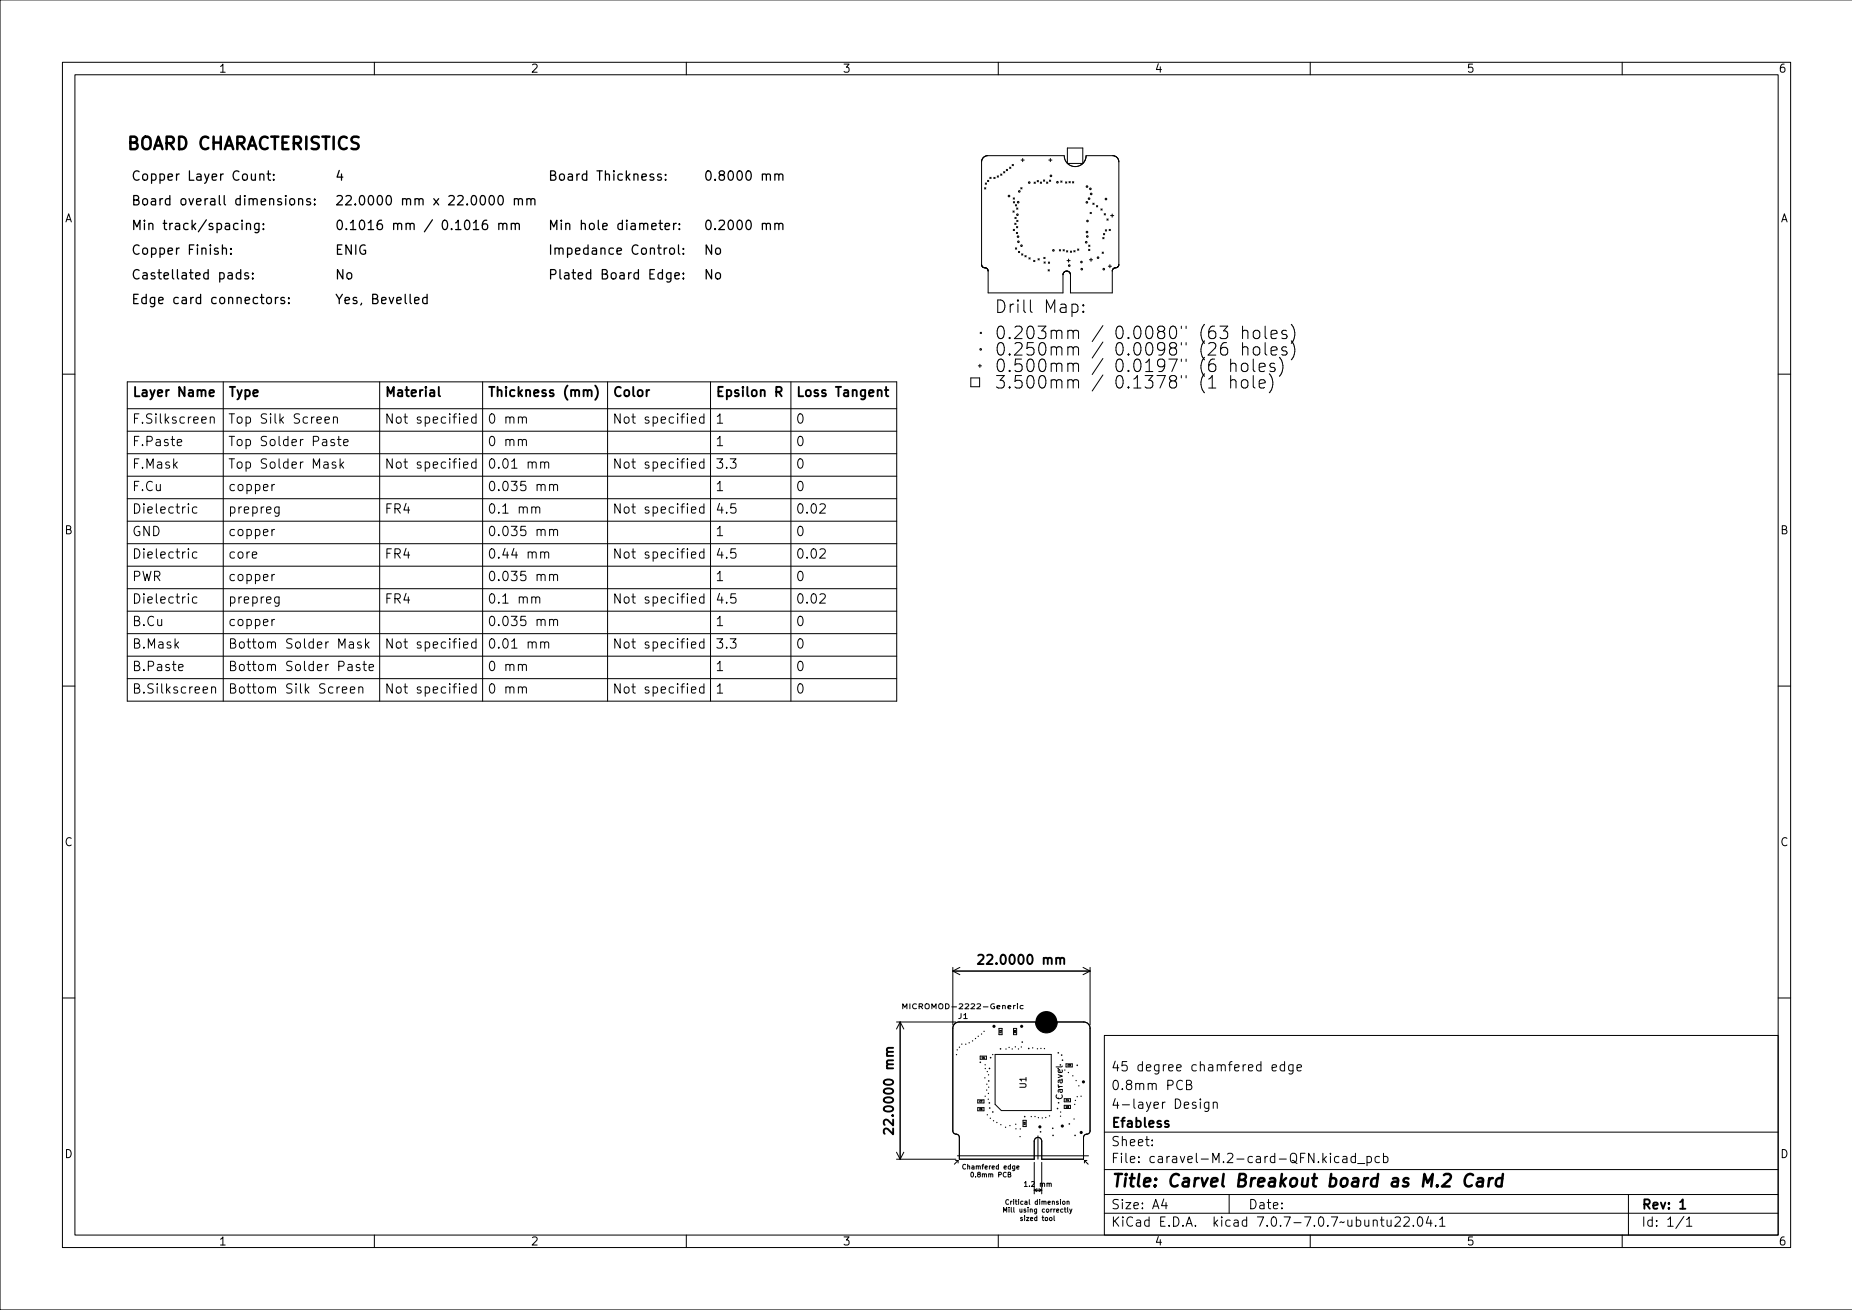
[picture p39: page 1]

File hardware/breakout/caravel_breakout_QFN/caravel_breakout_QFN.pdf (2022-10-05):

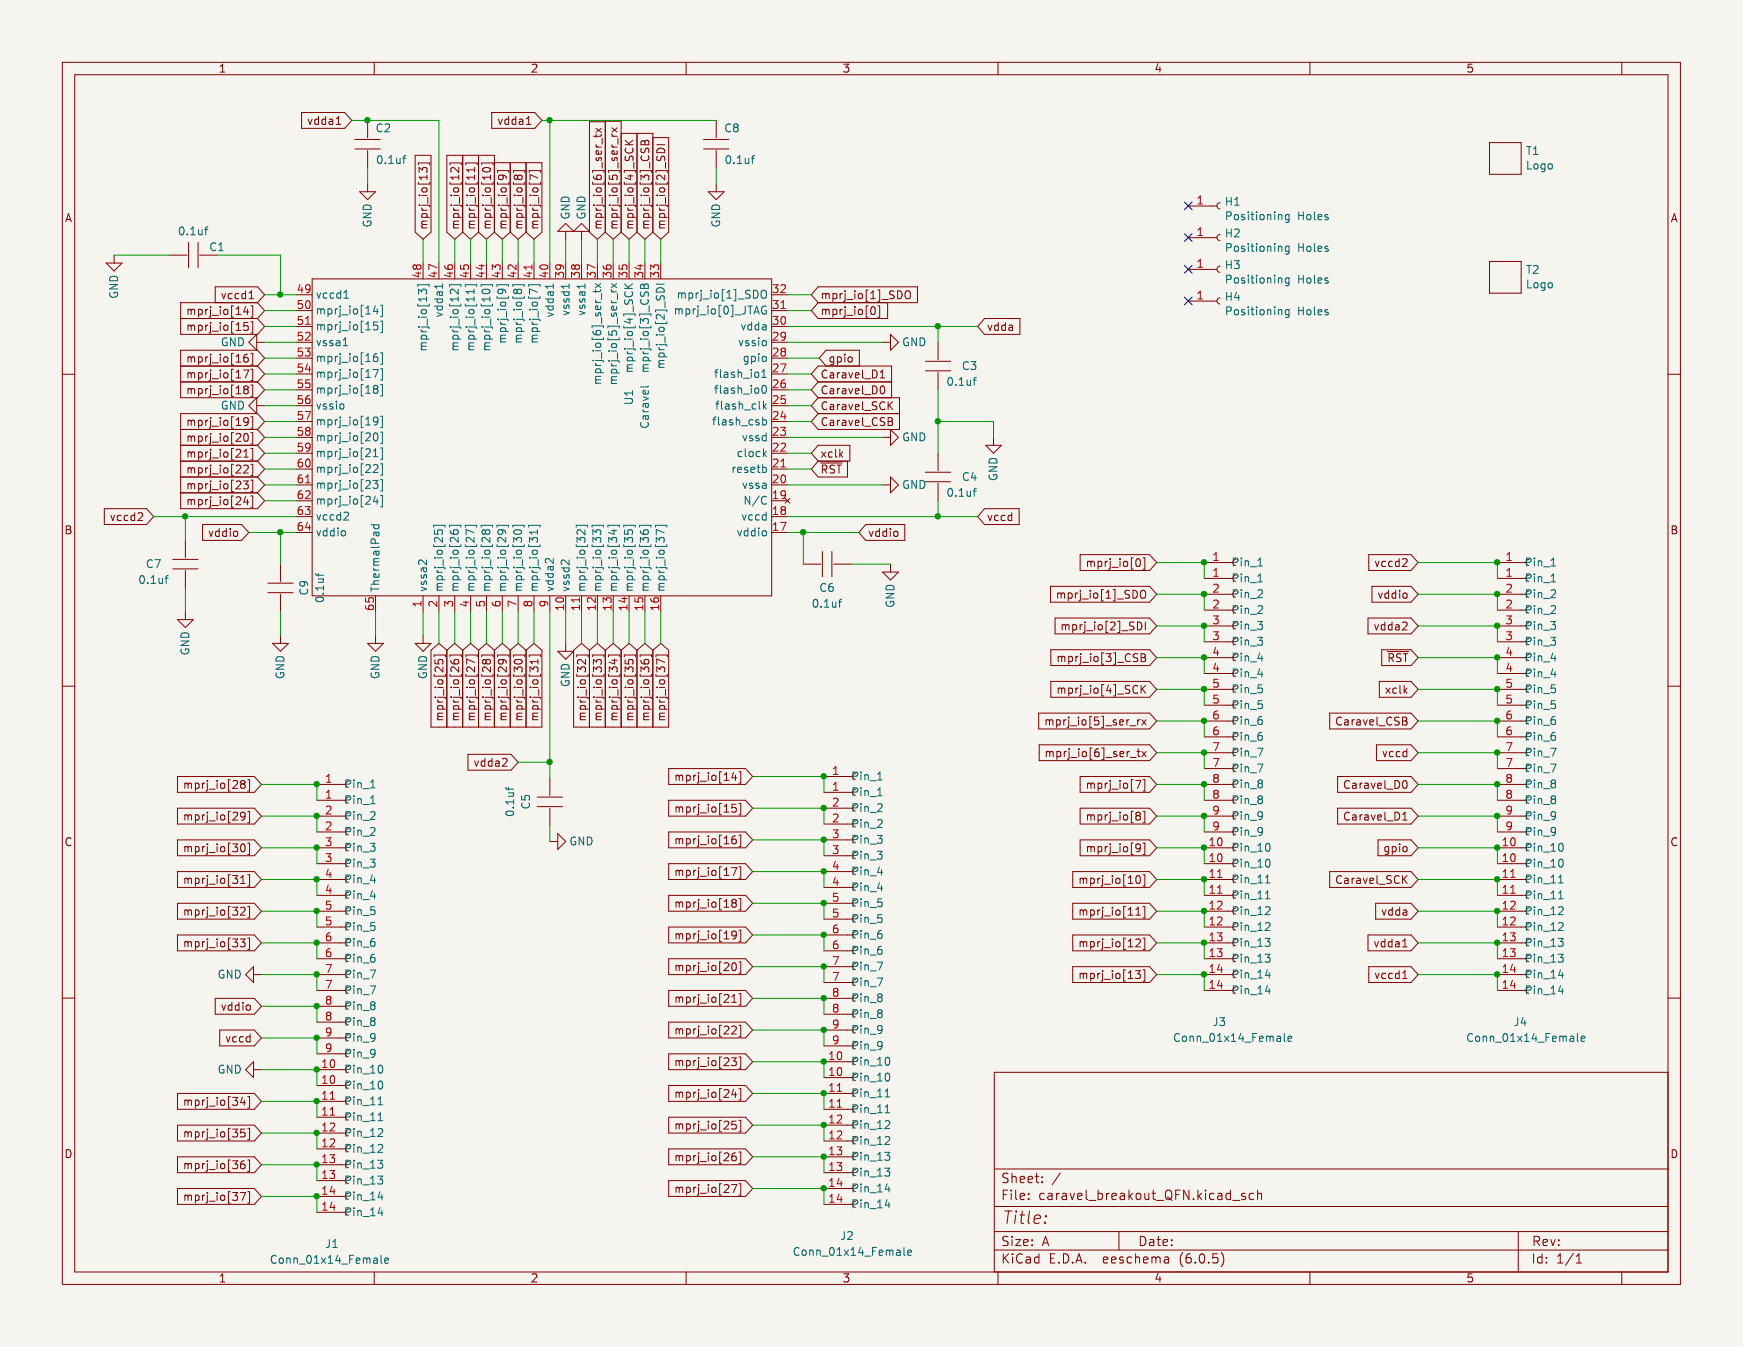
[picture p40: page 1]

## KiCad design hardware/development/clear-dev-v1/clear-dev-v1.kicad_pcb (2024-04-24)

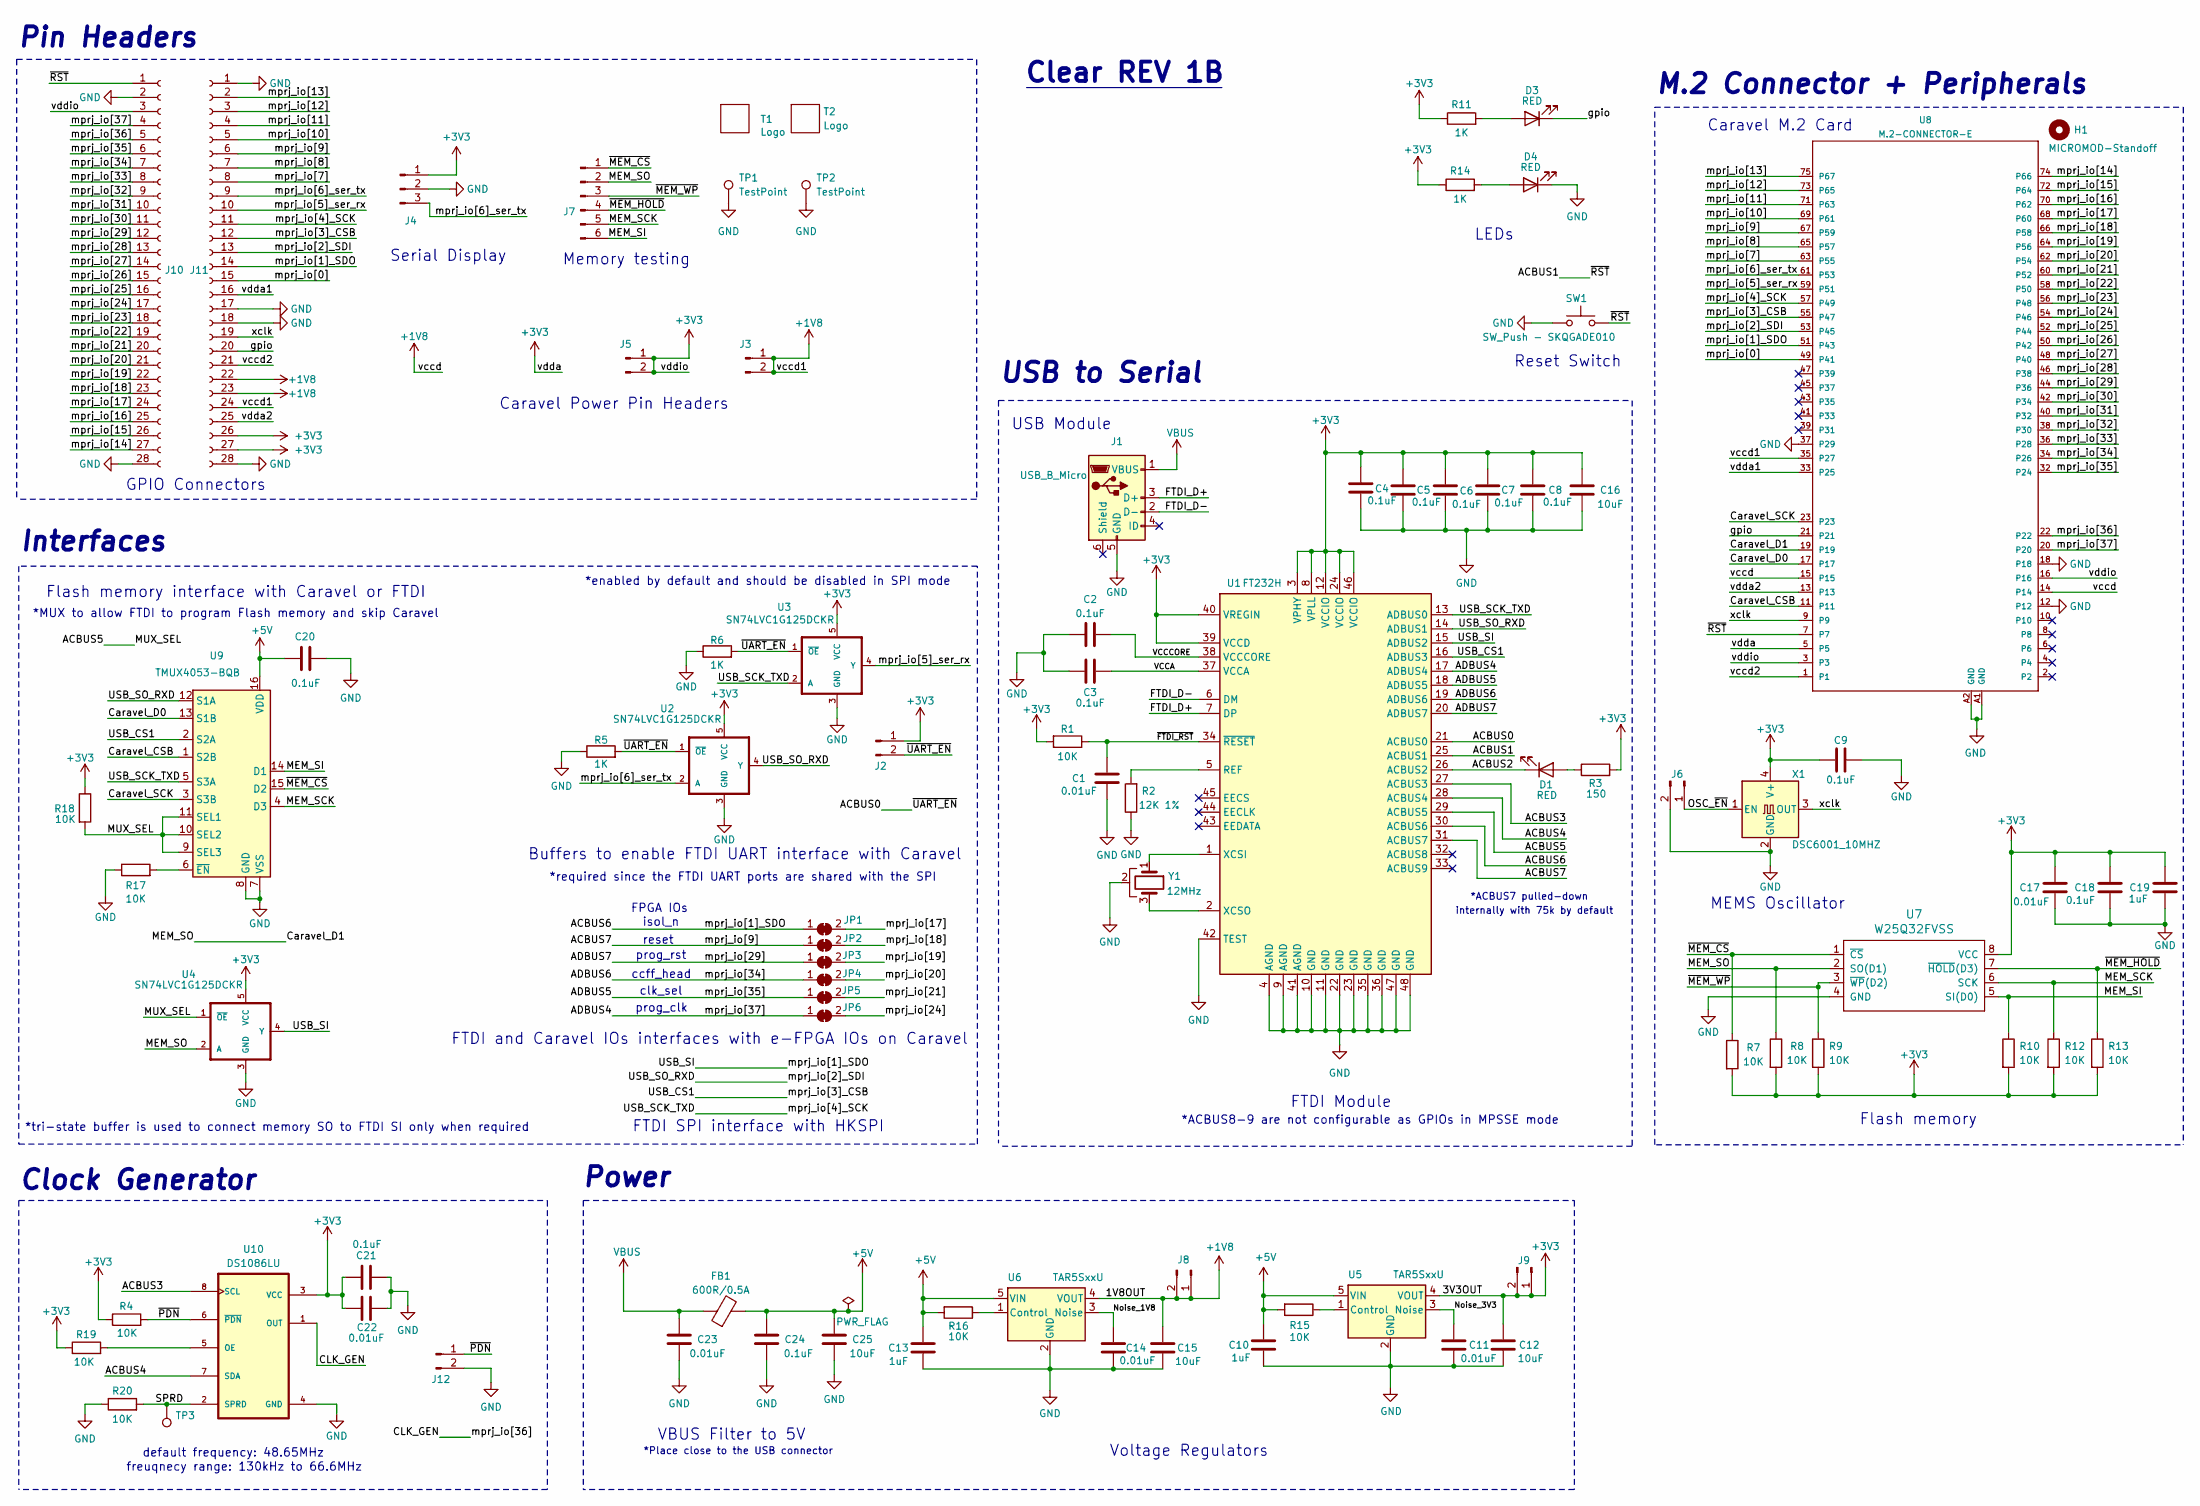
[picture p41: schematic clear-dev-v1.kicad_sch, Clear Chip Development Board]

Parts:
C1, C11, C14, C17, C22, C23: 0.01uF; C_0805_2012Metric; Part # C0805C103K5RAC7411
C2, C3, C4, C5, C6, C7, C8, C9, C18, C20, C21, C24: 0.1uF; C_0805_2012Metric; Part # C0805C104K5RAC7411
C10, C13, C19: 1uF; C_0805_2012Metric; Part # 885012207103
C12, C15, C16, C25: 10uF; C_0805_2012Metric; Part # CL21B106KAYQNNE
D1, D3, D4: RED; LED_1206_3216Metric; Part # LTST-C230KRKT
FB1: 600R/0.5A; L_0805_2012Metric; Part # 7427920415
H1: MICROMOD-Standoff; MicroMod-Standoff
J1: USB_B_Micro; FCI_10118193-0001LF; Part # 10118193-0001LF
J2, J6, J12: Conn_01x02_Pin; PinHeader_1x02_P2.54mm_Vertical
J3, J5, J8, J9: Conn_01x02_Pin; Shorted_PinHeader_1x02_P2.54mm_Vertical
J4: Conn_01x03_Pin; PinHeader_1x03_P2.54mm_Vertical
J7: Conn_01x06_Pin; PinHeader_1x06_P2.54mm_Vertical
J10, J11: Conn_01x28_Pin; PinHeader_1x28_P2.54mm_Vertical
JP1, JP2, JP3, JP4, JP5, JP6: SolderJumper_2_Bridged; SolderJumper-2_P1.3mm_Bridged_Pad1.0x1.5mm
R1, R4, R7, R8, R9, R10, R12, R13, R15, R16, R17, R18, R19, R20: 10K; R_0805_2012Metric; Part # RC0805FR-0710KL
R2: 12K 1%; R_0805_2012Metric; Part # RMCF0805FT12K0
R3: 150; R_0805_2012Metric; Part # RNCP0805FTD150R
R5, R6, R11, R14: 1K; R_0805_2012Metric; Part # RC0805FR-071KL
SW1: SW_Push - SKQGADE010; SW4-SMD-5.2X5.2X1.5MM
T1: Logo; logo
T2: Logo; ef_logo
TP1, TP2: TestPoint; TestPoint_Bridge_Pitch2.54mm_Drill1.0mm
TP3: TestPoint; TestPoint_THTPad_2.0x2.0mm_Drill1.0mm
U1: FT232H; QFN-48-1EP_8x8mm_P0.5mm_EP6.2x6.2mm; Part # FT232H
U2, U3, U4: SN74LVC1G125DCKR; SOT65P210X110-5N; Part # SN74LVC1G125DCKR
U5: TAR5SxxU; SOT-353F; Part # TAR5S33UTE85LF
U6: TAR5SxxU; SOT-353F; Part # TAR5S18U-TE85L-F
U7: W25Q32FVSS; SOIC127P790X216-8N; Part # W25Q32JVSSIQ
U8: M.2-CONNECTOR-E
U9: TMUX4053-BQB; WQFN-16-1EP_2.5x3.5mm_P0.5mm_EP1x2mm; Part # TMUX4053BQBR
U10: DS1086LU; SOP65P490X110-8N; Part # DS1086LU+T
X1: DSC6001_10MHZ; DSC6001JE1A-010.0000; Part # DSC6001JI1B
Y1: 12MHz; CSTNE12M0GH5L000R0; Part # CSTNE12M0GH5L000R0

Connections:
+1V8: C15.2, J3.1, J3.2, J8.1, J8.2, J11.22, J11.23, J11.24, U6.4 (VOUT), U8.14, U8.15, U8.35 (P27)
+3V3: C4.2, C5.2, C6.2, C7.2, C8.2, C9.2, C12.2, C16.1, C17.2, C18.1, C19.1, C21.2, C22.2, J2.1, J4.1, J5.1, J5.2, J9.1, J9.2, J10.3, J11.26, J11.27, R1.2, R3.2, R4.1, R7.2, R8.2, R9.2, R10.2, R11.1, R12.2, R13.2, R14.1, R18.1, R19.1, U1.3 (VPHY), U1.8 (VPLL), U1.12 (VCCIO), U1.24 (VCCIO), U1.39 (VCCD), U1.40 (VREGIN), U1.46 (VCCIO), U2.5 (VCC), U3.5 (VCC), U4.5 (VCC), U5.4 (VOUT), U7.8 (VCC), U8.3, U8.5, U8.16, U10.3 (VCC), X1.4 (V+)
+5V: C10.2, C13.2, C20.2, C24.2, C25.2, FB1.2, R15.2, R16.2, U5.5 (VIN), U6.5 (VIN), U9.16 (VDD)
/ACBUS0: J2.2, R5.2, R6.2, U1.21 (ACBUS0), U2.1 (~OE), U3.1 (~OE)
/ACBUS1: J10.1, SW1.1, U1.25 (ACBUS1), U8.7
/ACBUS2: D1.1 (K), U1.26 (ACBUS2)
/ACBUS3: U1.27 (ACBUS3), U10.8 (SCL)
/ACBUS4: U1.28 (ACBUS4), U10.7 (SDA)
/ACBUS5: R18.2, U1.29 (ACBUS5), U4.1 (~OE), U9.9 (SEL3), U9.10 (SEL2), U9.11 (SEL1)
/ACBUS6: J11.14, JP1.1 (A), U1.15 (ADBUS2), U1.30 (ACBUS6), U4.4 (Y), U8.51 (P43)
/ACBUS7: J11.6, JP2.1 (A), U1.31 (ACBUS7), U8.67 (P59)
/ADBUS4: J10.4, JP6.1 (A), U1.17 (ADBUS4), U8.20
/ADBUS5: J10.6, JP5.1 (A), U1.18 (ADBUS5), U8.32 (P24)
/ADBUS6: J10.7, JP4.1 (A), U1.19 (ADBUS6), U8.34 (P26)
/ADBUS7: J10.12, JP3.1 (A), U1.20 (ADBUS7), U8.44 (P36)
/CLK_GEN: J10.5, U8.22, U10.1 (OUT)
/Caravel_CSB: U8.11, U9.1 (S2B)
/Caravel_D0: U8.17, U9.13 (S1B)
/Caravel_D1: J7.2, R8.1, U4.2 (A), U7.2 (SO(D1)), U8.19
/Caravel_SCK: U8.23, U9.3 (S3B)
/FTDI_D+: J1.3 (D+), U1.7 (DP)
/FTDI_D-: J1.2 (D-), U1.6 (DM)
/MEM_SCK: J7.5, R12.1, U7.6 (SCK), U9.4 (D3)
/MEM_SI: J7.6, R10.1, U7.5 (SI(D0)), U9.14 (D1)
/Noise_1V8: C14.1, U6.3 (Noise)
/Noise_3V3: C11.1, U5.3 (Noise)
/OSC_~EN: J6.1, X1.1 (EN)
/SPRD: R20.2, TP3.1, U10.2 (SPRD)
/USB_CS1: J11.12, U1.16 (ADBUS3), U8.55 (P47), U9.2 (S2A)
/USB_SCK_TXD: J11.11, U1.13 (ADBUS0), U3.2 (A), U8.57 (P49), U9.5 (S3A)
/USB_SO_RXD: J11.13, U1.14 (ADBUS1), U2.4 (Y), U8.53 (P45), U9.12 (S1A)
/VCCA: C3.2, U1.37 (VCCA)
/VCCCORE: C2.2, U1.38 (VCCCORE)
/gpio: D3.1 (K), J11.20, U8.21
/mprj_io[0]: J11.15, U8.49 (P41)
/mprj_io[5]_ser_rx: J11.10, U3.4 (Y), U8.59 (P51)
/mprj_io[6]_ser_tx: J4.3, J11.9, U2.2 (A), U8.61 (P53)
/mprj_io[7]: J11.8, U8.63 (P55)
/mprj_io[8]: J11.7, U8.65 (P57)
/mprj_io[10]: J11.5, U8.69 (P61)
/mprj_io[11]: J11.4, U8.71 (P63)
/mprj_io[12]: J11.3, U8.73 (P65)
/mprj_io[13]: J11.2, U8.75 (P67)
/mprj_io[14]: J10.27, U8.74 (P66)
/mprj_io[15]: J10.26, U8.72 (P64)
/mprj_io[16]: J10.25, U8.70 (P62)
/mprj_io[17]: J10.24, JP1.2 (B), U8.68 (P60)
/mprj_io[18]: J10.23, JP2.2 (B), U8.66 (P58)
/mprj_io[19]: J10.22, JP3.2 (B), U8.64 (P56)
/mprj_io[20]: J10.21, JP4.2 (B), U8.62 (P54)
/mprj_io[21]: J10.20, JP5.2 (B), U8.60 (P52)
/mprj_io[22]: J10.19, U8.58 (P50)
/mprj_io[23]: J10.18, U8.56 (P48)
/mprj_io[24]: J10.17, JP6.2 (B), U8.54 (P46)
/mprj_io[25]: J10.16, U8.52 (P44)
/mprj_io[26]: J10.15, U8.50 (P42)
/mprj_io[27]: J10.14, U8.48 (P40)
/mprj_io[28]: J10.13, U8.46 (P38)
/mprj_io[30]: J10.11, U8.42 (P34)
/mprj_io[31]: J10.10, U8.40 (P32)
/mprj_io[32]: J10.9, U8.38 (P30)
/mprj_io[33]: J10.8, U8.36 (P28)
/vccd2: J11.21, U8.1
/vdda1: J11.16, U8.33 (P25)
/vdda2: J11.25, U8.13
/xclk: J11.19, U8.9, X1.3 (OUT)
/~FTDI_RST: C1.2, R1.1, U1.34 (~RESET)
/~MEM_CS: J7.1, R7.1, U7.1 (~CS), U9.15 (D2)
/~MEM_HOLD: J7.4, R13.1, U7.7 (~HOLD(D3))
/~MEM_WP: J7.3, R9.1, U7.3 (~WP(D2))
/~PDN: J12.1, R4.2, U10.6 (~PDN)
GND: C1.1, C2.1, C3.1, C4.1, C5.1, C6.1, C7.1, C8.1, C9.1, C10.1, C11.2, C12.1, C13.1, C14.2, C15.1, C16.2, C17.1, C18.2, C19.2, C20.1, C21.1, C22.1, C23.2, C24.1, C25.1, D4.1 (K), J1.5 (GND), J4.2, J6.2, J10.2, J10.28, J11.1, J11.17, J11.18, J11.28, J12.2, R2.1, R5.1, R6.1, R17.1, R20.1, SW1.2, TP1.1, TP2.1, U1.4 (AGND), U1.9 (AGND), U1.10 (GND), U1.11 (GND), U1.22 (GND), U1.23 (GND), U1.35 (GND), U1.36 (GND), U1.41 (AGND), U1.42 (TEST), U1.47 (GND), U1.48 (GND), U2.3 (GND), U3.3 (GND), U4.3 (GND), U5.2 (GND), U6.2 (GND), U7.4 (GND), U8.12, U8.18, U8.37 (P29), U8.A1 (GND), U8.A2 (GND), U9.7 (VSS), U9.8 (GND), U10.4 (GND), X1.2 (GND), Y1.2
unnamed: D1.2 (A), R3.1
unnamed: D3.2 (A), R11.2
unnamed: D4.2 (A), R14.2
unnamed: R2.2, U1.5 (REF)
unnamed: U1.1 (XCSI), Y1.1
unnamed: U1.2 (XCSO), Y1.3
unnamed: R15.1, U5.1 (Control)
unnamed: R16.1, U6.1 (Control)
unnamed: R17.2, U9.6 (~EN)
unnamed: R19.2, U10.5 (OE)
VBUS: C23.1, FB1.1, J1.1 (VBUS)

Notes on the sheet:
USB to Serial
USB Module
MEMS Oscillator
*Place close to the USB connector
Flash memory interface with Caravel or FTDI
Caravel Power Pin Headers
GPIO Connectors
*required since the FTDI UART ports are shared with the SPI
LEDs
Flash memory
isol_n
Serial Display
reset
Buffers to enable FTDI UART interface with Caravel
*MUX to allow FTDI to program Flash memory and skip Caravel
ccff_head
M.2 Connector + Peripherals
*enabled by default and should be disabled in SPI mode
FTDI and Caravel IOs interfaces with e-FPGA IOs on Caravel
Power
prog_rst
default frequency: 48.65MHz
Pin Headers
VBUS Filter to 5V
FPGA IOs
prog_clk
Interfaces
Clock Generator
Voltage Regulators
Clear REV 1B
*ACBUS8-9 are not configurable as GPIOs in MPSSE mode
Reset Switch
Memory testing
*ACBUS7 pulled-down
freuqnecy range: 130kHz to 66.6MHz
*tri-state buffer is used to connect memory SO to FTDI SI only when required
internally with 75k by default
FTDI SPI interface with HKSPI
FTDI Module
clk_sel

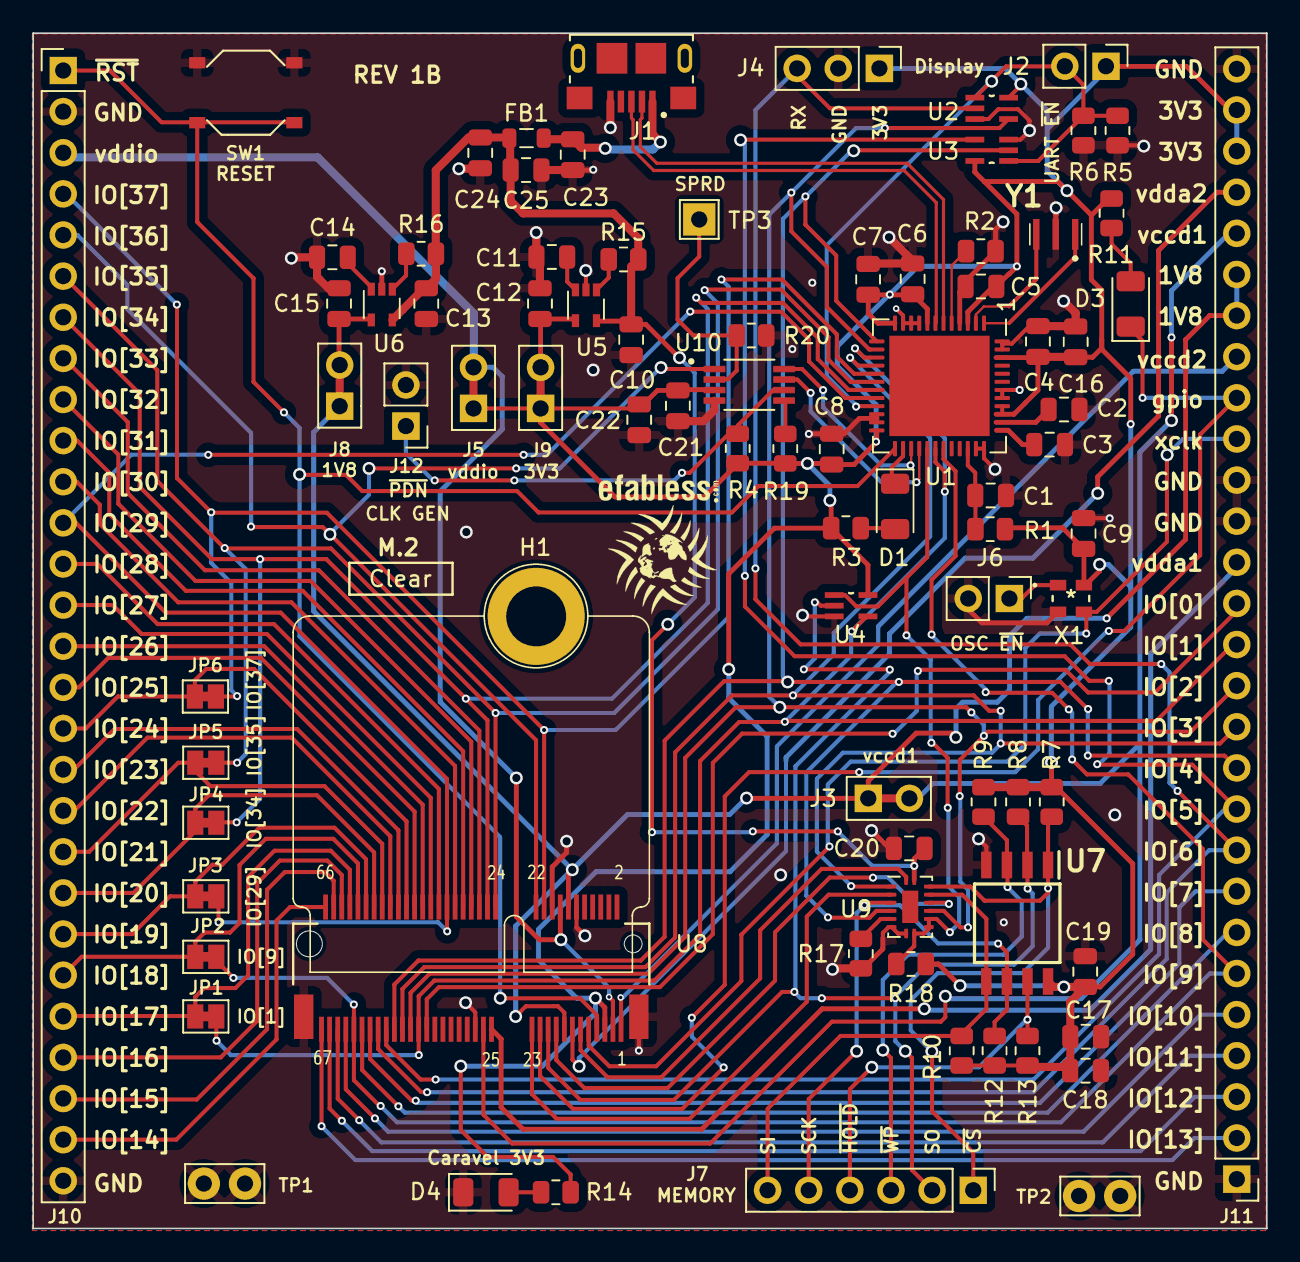
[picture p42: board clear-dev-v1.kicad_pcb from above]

Board: 2 copper layers, 76.2 x 73.8 mm, 86 parts (0 on the bottom side), 83 nets.

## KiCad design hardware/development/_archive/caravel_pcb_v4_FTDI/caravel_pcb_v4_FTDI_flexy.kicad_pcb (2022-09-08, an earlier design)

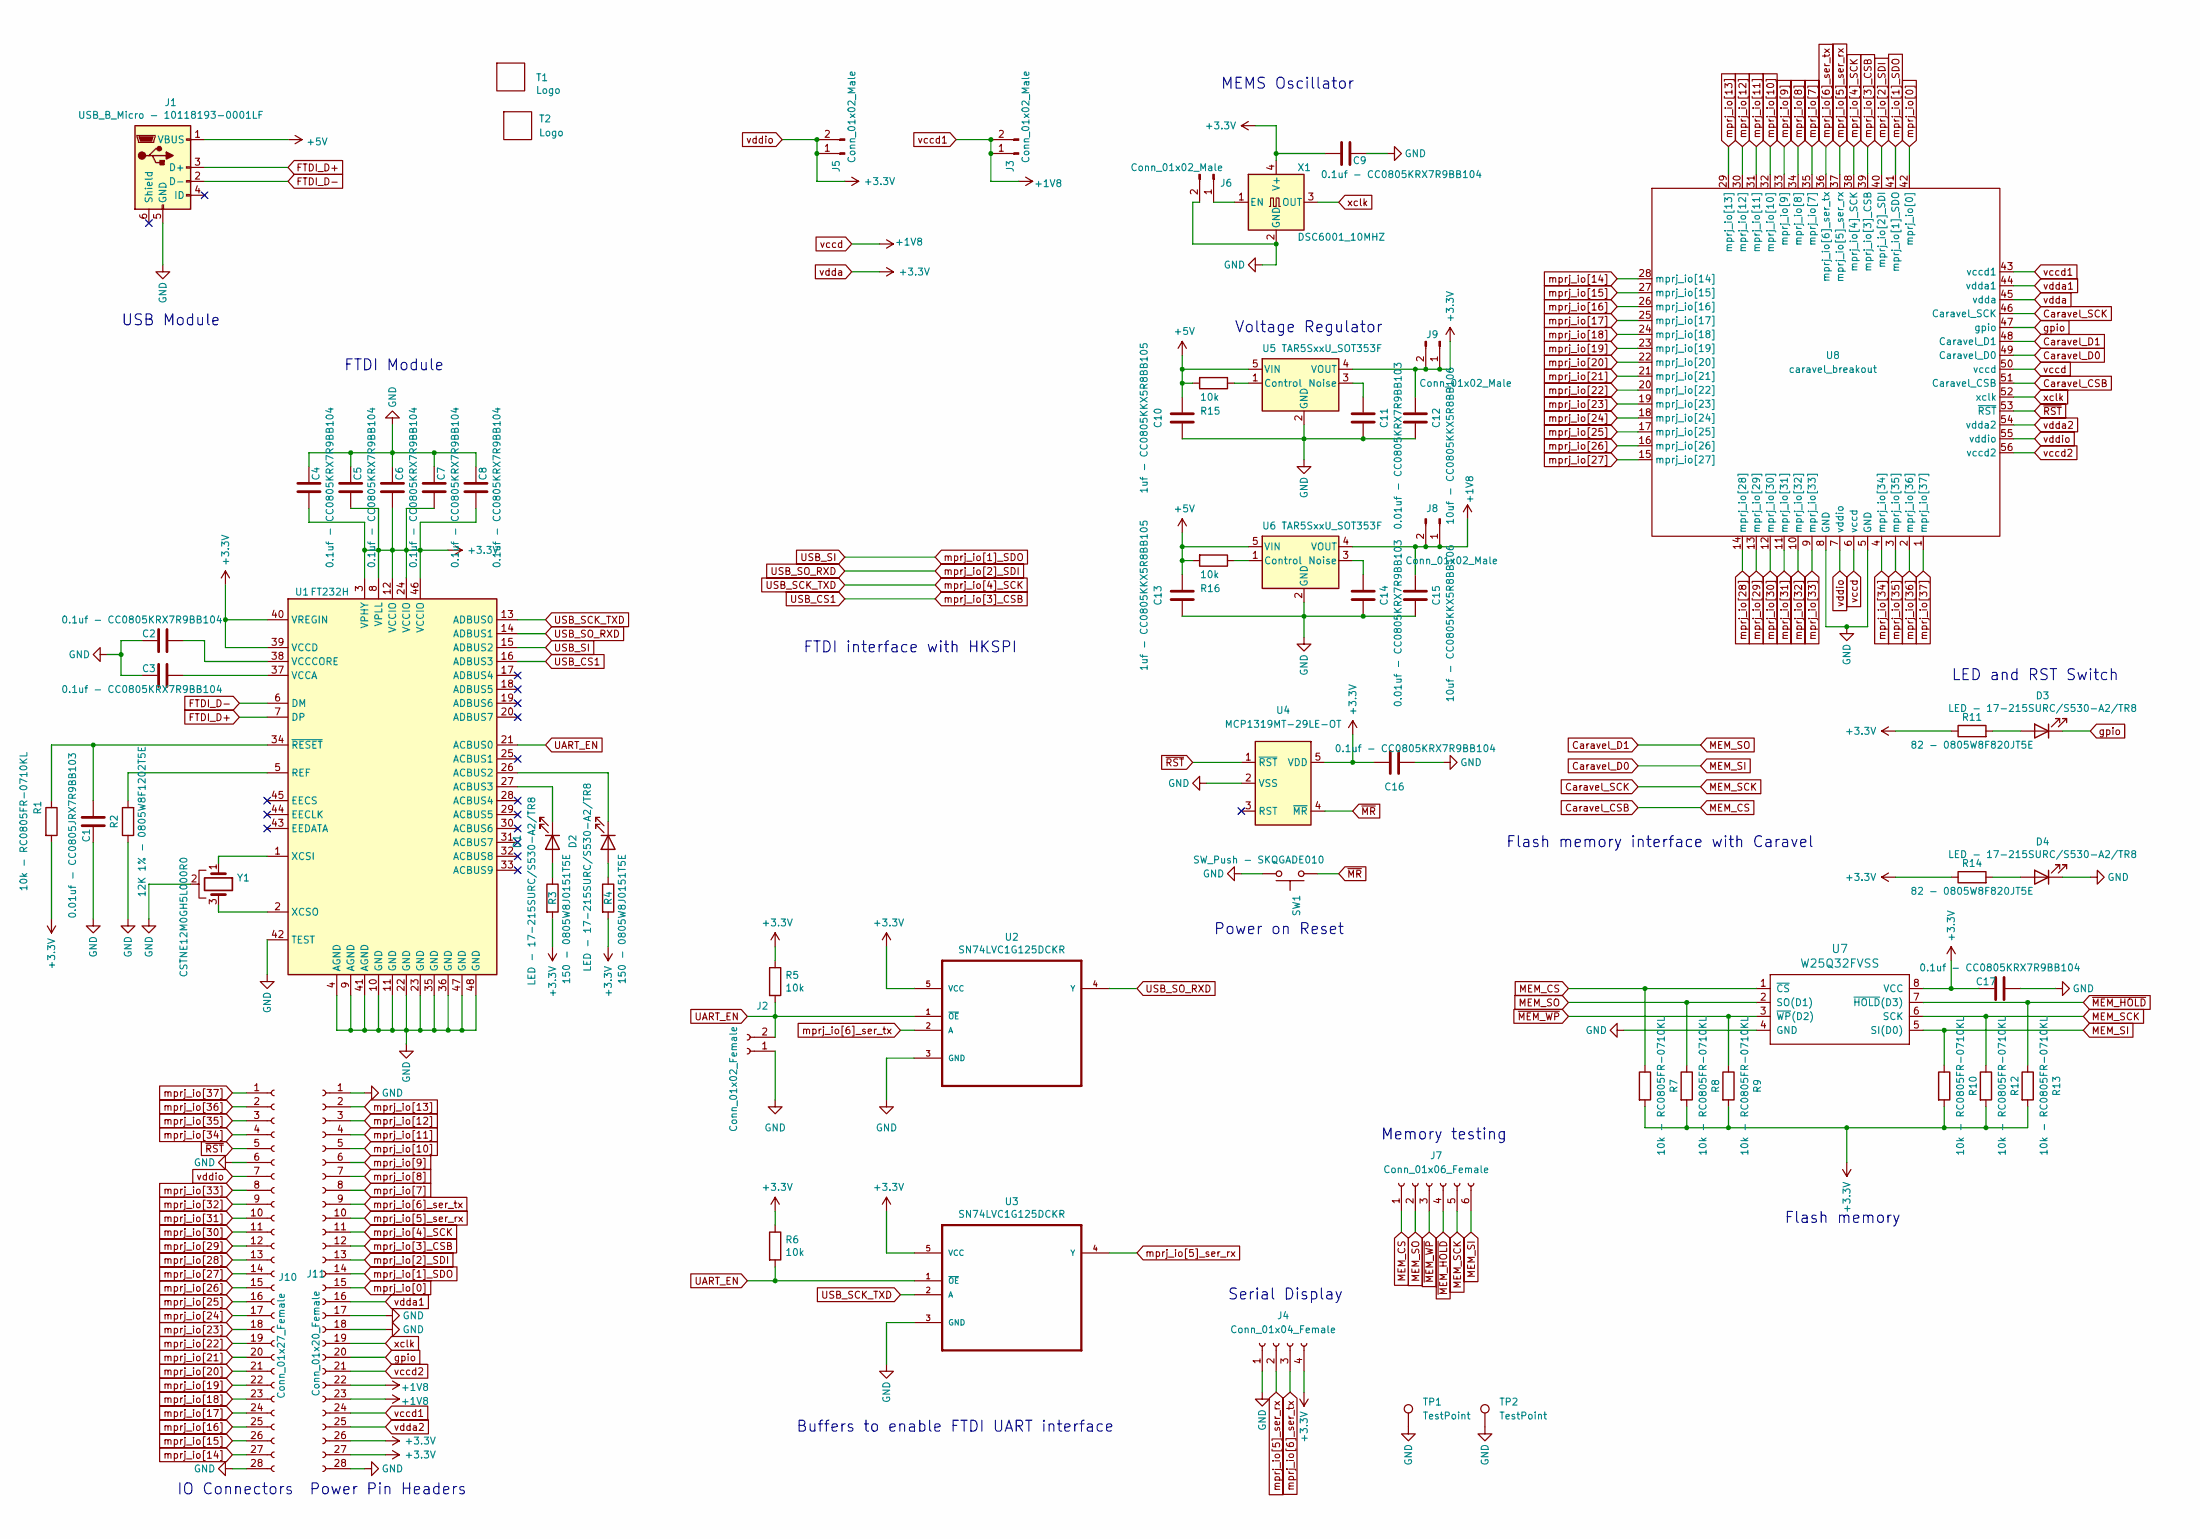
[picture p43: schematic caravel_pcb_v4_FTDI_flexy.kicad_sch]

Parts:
C1: 0.01uf - CC0805JRX7R9BB103; C_0805_2012Metric
C2, C3, C4, C5, C6, C7, C8, C9, C16, C17: 0.1uf - CC0805KRX7R9BB104; C_0805_2012Metric
C10, C13: 1uf - CC0805KKX5R8BB105; C_0805_2012Metric
C11, C14: 0.01uf - CC0805KRX7R9BB103; C_0805_2012Metric
C12, C15: 10uf - CC0805KKX5R8BB106; C_0805_2012Metric
D1, D2, D3, D4: LED - 17-215SURC/S530-A2/TR8; LED_1206_3216Metric
J1: USB_B_Micro - 10118193-0001LF; FCI_10118193-0001LF
J2: Conn_01x02_Female; PinHeader_1x02_P2.54mm_Vertical
J3, J5, J6, J8, J9: Conn_01x02_Male; PinHeader_1x02_P2.54mm_Vertical
J4: Conn_01x04_Female; PinHeader_1x04_P2.54mm_Vertical
J7: Conn_01x06_Female; PinHeader_1x06_P2.54mm_Vertical
J10: Conn_01x27_Female; PinHeader_1x27_P2.54mm_Vertical
J11: Conn_01x20_Female; PinHeader_1x20_P2.54mm_Vertical
R1, R7, R8, R9, R10, R12, R13: 10k - RC0805FR-0710KL; R_0805_2012Metric
R2: 12K 1% - 0805W8F1202T5E; R_0805_2012Metric
R3, R4: 150 - 0805W8J0151T5E; R_0805_2012Metric
R5, R6, R15, R16: 10k; R_0805_2012Metric
R11, R14: 82 - 0805W8F820JT5E; R_0805_2012Metric
SW1: SW_Push - SKQGADE010; SW4-SMD-5.2X5.2X1.5MM
T1: Logo; logo
T2: Logo; ef_logo
TP1, TP2: TestPoint; TestPoint_Bridge_Pitch2.54mm_Drill1.0mm
U1: FT232H; QFN-48-1EP_8x8mm_P0.5mm_EP6.2x6.2mm
U2, U3: SN74LVC1G125DCKR; SOT65P210X110-5N
U4: MCP1319MT-29LE-OT; PoR_5_SOT23
U5, U6: TAR5SxxU_SOT353F; SOT-353F
U7: W25Q32FVSS; SOIC127P790X216-8N
U8: caravel_breakout; caravel_breakout_flexy
X1: DSC6001_10MHZ; DSC6001JE1A-010.0000
Y1: CSTNE12M0GH5L000R0

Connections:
+5V: C10.2, C13.2, J1.1 (VBUS), R15.2, R16.2, U5.5 (VIN), U6.5 (VIN)
Caravel_CSB: J7.1, R7.1, U7.1 (~CS), U8.51 (Caravel_CSB)
Caravel_D0: J7.6, R10.1, U7.5 (SI(D0)), U8.49 (Caravel_D0)
Caravel_D1: J7.2, R8.1, U7.2 (SO(D1)), U8.48 (Caravel_D1)
Caravel_SCK: J7.5, R12.1, U7.6 (SCK), U8.46 (Caravel_SCK)
FTDI_D+: J1.3 (D+), U1.7 (DP)
FTDI_D-: J1.2 (D-), U1.6 (DM)
GND: C1.1, C2.1, C3.1, C4.1, C5.1, C6.1, C7.1, C8.1, C9.1, C10.1, C11.2, C12.1, C13.1, C14.2, C15.1, C16.1, C17.2, D4.1 (K), J1.5 (GND), J2.1, J4.1, J6.2, J10.6, J10.28, J11.1, J11.17, J11.18, J11.28, R2.1, SW1.2, TP1.1, TP2.1, U1.4 (AGND), U1.9 (AGND), U1.10 (GND), U1.11 (GND), U1.22 (GND), U1.23 (GND), U1.35 (GND), U1.36 (GND), U1.41 (AGND), U1.42 (TEST), U1.47 (GND), U1.48 (GND), U2.3 (GND), U3.3 (GND), U4.2 (VSS), U5.2 (GND), U6.2 (GND), U7.4 (GND), U8.5 (GND), U8.8 (GND), X1.2 (GND), Y1.2
unnamed: C1.2, R1.1, U1.34 (~RESET)
unnamed: C2.2, U1.38 (VCCCORE)
unnamed: C3.2, U1.37 (VCCA)
unnamed: C11.1, U5.3 (Noise)
unnamed: C14.1, U6.3 (Noise)
unnamed: D1.1 (K), U1.27 (ACBUS3)
unnamed: D1.2 (A), R3.1
unnamed: D2.1 (K), U1.26 (ACBUS2)
unnamed: D2.2 (A), R4.1
unnamed: D3.2 (A), R11.2
unnamed: D4.2 (A), R14.2
unnamed: J6.1, X1.1 (EN)
unnamed: R2.2, U1.5 (REF)
unnamed: R15.1, U5.1 (Control)
unnamed: R16.1, U6.1 (Control)
unnamed: U1.1 (XCSI), Y1.1
unnamed: U1.2 (XCSO), Y1.3
UART_EN: J2.2, R5.2, R6.2, U1.21 (ACBUS0), U2.1 (~OE), U3.1 (~OE)
USB_CS1: J11.12, U1.16 (ADBUS3), U8.39 (mprj_io[3]_CSB)
USB_SCK_TXD: J11.11, U1.13 (ADBUS0), U3.2 (A), U8.38 (mprj_io[4]_SCK)
USB_SI: J11.14, U1.15 (ADBUS2), U8.41 (mprj_io[1]_SDO)
USB_SO_RXD: J11.13, U1.14 (ADBUS1), U2.4 (Y), U8.40 (mprj_io[2]_SDI)
gpio: D3.1 (K), J11.20, U8.47 (gpio)
mprj_io[0]: J11.15, U8.42 (mprj_io[0])
mprj_io[5]_ser_rx: J4.2, J11.10, U3.4 (Y), U8.37 (mprj_io[5]_ser_rx)
mprj_io[6]_ser_tx: J4.3, J11.9, U2.2 (A), U8.36 (mprj_io[6]_ser_tx)
mprj_io[7]: J11.8, U8.35 (mprj_io[7])
mprj_io[8]: J11.7, U8.34 (mprj_io[8])
mprj_io[9]: J11.6, U8.33 (mprj_io[9])
mprj_io[10]: J11.5, U8.32 (mprj_io[10])
mprj_io[11]: J11.4, U8.31 (mprj_io[11])
mprj_io[12]: J11.3, U8.30 (mprj_io[12])
mprj_io[13]: J11.2, U8.29 (mprj_io[13])
mprj_io[14]: J10.27, U8.28 (mprj_io[14])
mprj_io[15]: J10.26, U8.27 (mprj_io[15])
mprj_io[16]: J10.25, U8.26 (mprj_io[16])
mprj_io[17]: J10.24, U8.25 (mprj_io[17])
mprj_io[18]: J10.23, U8.24 (mprj_io[18])
mprj_io[19]: J10.22, U8.23 (mprj_io[19])
mprj_io[20]: J10.21, U8.22 (mprj_io[20])
mprj_io[21]: J10.20, U8.21 (mprj_io[21])
mprj_io[22]: J10.19, U8.20 (mprj_io[22])
mprj_io[23]: J10.18, U8.19 (mprj_io[23])
mprj_io[24]: J10.17, U8.18 (mprj_io[24])
mprj_io[25]: J10.16, U8.17 (mprj_io[25])
mprj_io[26]: J10.15, U8.16 (mprj_io[26])
mprj_io[27]: J10.14, U8.15 (mprj_io[27])
mprj_io[28]: J10.13, U8.14 (mprj_io[28])
mprj_io[29]: J10.12, U8.13 (mprj_io[29])
mprj_io[30]: J10.11, U8.12 (mprj_io[30])
mprj_io[31]: J10.10, U8.11 (mprj_io[31])
mprj_io[32]: J10.9, U8.10 (mprj_io[32])
mprj_io[33]: J10.8, U8.9 (mprj_io[33])
mprj_io[34]: J10.4, U8.4 (mprj_io[34])
mprj_io[35]: J10.3, U8.3 (mprj_io[35])
mprj_io[36]: J10.2, U8.2 (mprj_io[36])
mprj_io[37]: J10.1, U8.1 (mprj_io[37])
vccd: C15.2, J3.1, J3.2, J8.1, J8.2, J11.22, J11.23, J11.24, U6.4 (VOUT), U8.6 (vccd), U8.43 (vccd1), U8.50 (vccd)
vccd2: J11.21, U8.56 (vccd2)
vdda: C4.2, C5.2, C6.2, C7.2, C8.2, C9.2, C12.2, C16.2, C17.1, J4.4, J5.1, J5.2, J9.1, J9.2, J10.7, J11.26, J11.27, R1.2, R3.2, R4.2, R5.1, R6.1, R7.2, R8.2, R9.2, R10.2, R11.1, R12.2, R13.2, R14.1, U1.3 (VPHY), U1.8 (VPLL), U1.12 (VCCIO), U1.24 (VCCIO), U1.39 (VCCD), U1.40 (VREGIN), U1.46 (VCCIO), U2.5 (VCC), U3.5 (VCC), U4.5 (VDD), U5.4 (VOUT), U7.8 (VCC), U8.7 (vddio), U8.45 (vdda), U8.55 (vddio), X1.4 (V+)
vdda1: J11.16, U8.44 (vdda1)
vdda2: J11.25, U8.54 (vdda2)
xclk: J11.19, U8.52 (xclk), X1.3 (OUT)
~MEM_HOLD: J7.4, R13.1, U7.7 (~HOLD(D3))
~MEM_WP: J7.3, R9.1, U7.3 (~WP(D2))
~MR: SW1.1, U4.4 (~MR)
~RST: J10.5, U4.1 (~RST), U8.53 (~RST)

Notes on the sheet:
Serial Display
LED and RST Switch
Flash memory interface with Caravel
Power on Reset
Flash memory
Memory testing
FTDI interface with HKSPI
Power Pin Headers
Voltage Regulator
IO Connectors
FTDI Module
USB Module
MEMS Oscillator
Buffers to enable FTDI UART interface

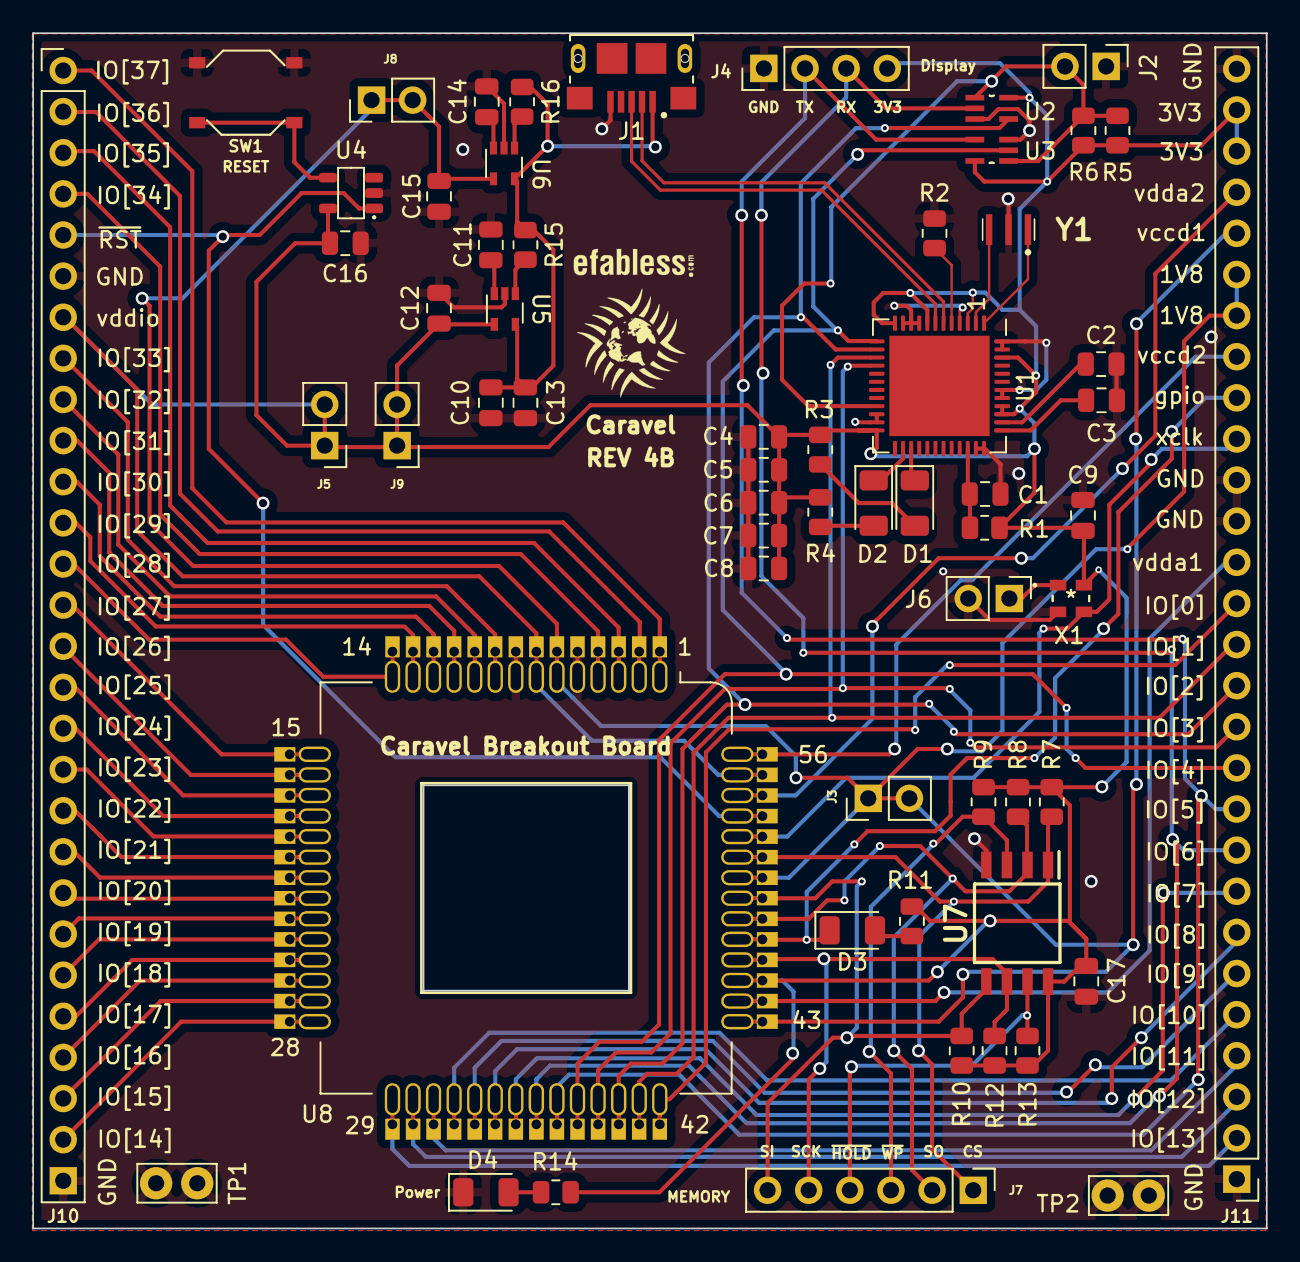
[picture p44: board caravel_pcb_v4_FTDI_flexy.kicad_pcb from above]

Board: 2 copper layers, 76.2 x 73.8 mm, 63 parts (0 on the bottom side), 75 nets.

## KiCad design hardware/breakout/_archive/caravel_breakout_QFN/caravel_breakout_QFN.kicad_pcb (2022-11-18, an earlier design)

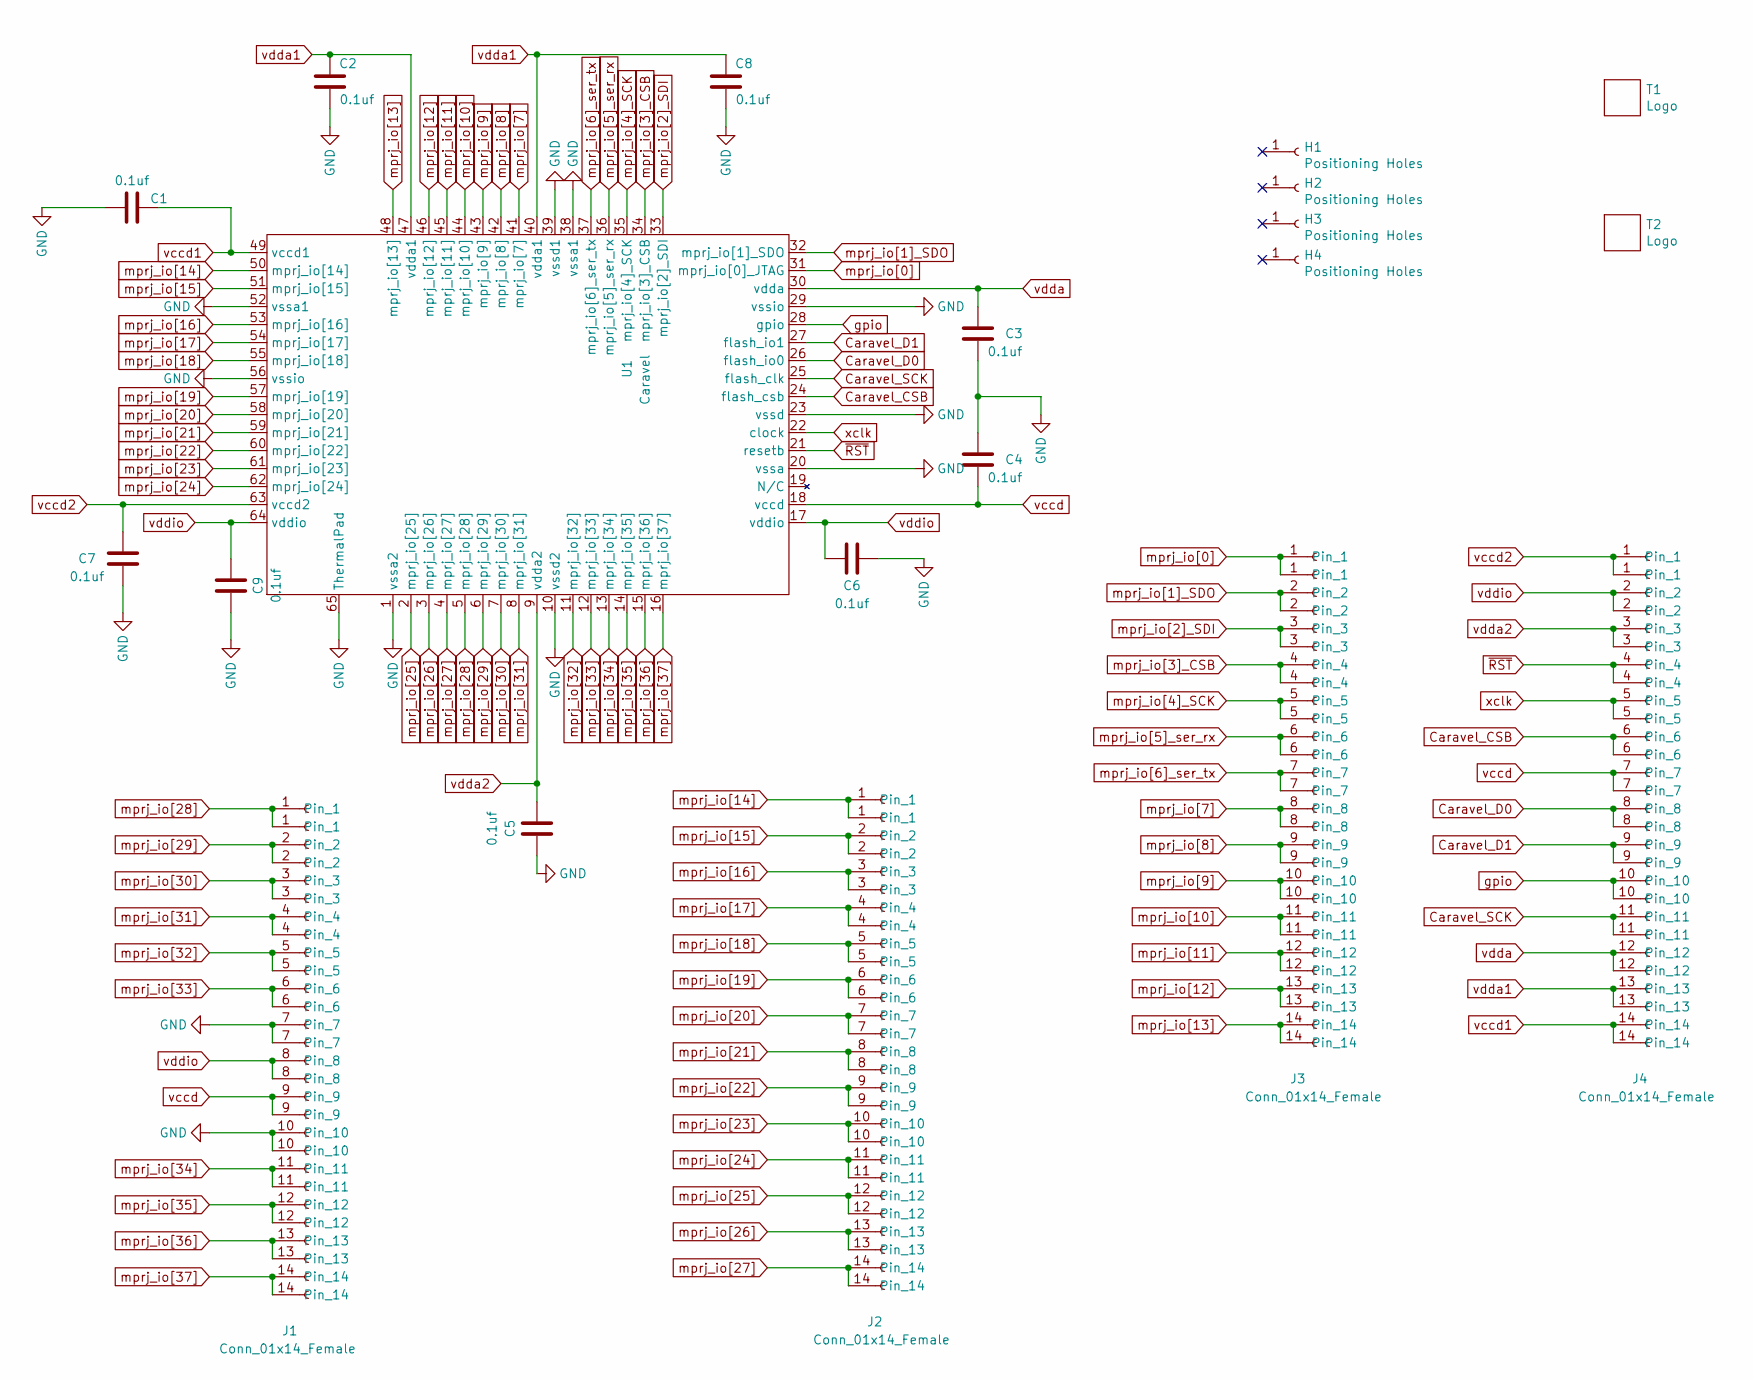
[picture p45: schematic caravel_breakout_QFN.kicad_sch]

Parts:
C1, C2, C3, C4, C5, C6, C7, C8, C9: 0.1uf; C_0402_1005Metric
H1, H2, H3, H4: Positioning Holes; MountingHole_2.2mm_M2_ISO7380_Pad
J1, J2, J3, J4: Conn_01x14_Female; Caravel_Breakout_Connectors_2x14
T1: Logo; logo_small
T2: Logo; ef_logo
U1: Caravel; QFN-64-1EP_9x9mm_P0.5mm_EP7.65x7.65mm

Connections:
Caravel_CSB: J4.6, U1.24 (flash_csb)
Caravel_D0: J4.8, U1.26 (flash_io0)
Caravel_D1: J4.9, U1.27 (flash_io1)
Caravel_SCK: J4.11, U1.25 (flash_clk)
GND: C1.1, C2.2, C3.2, C4.1, C5.1, C6.1, C7.1, C8.2, C9.1, J1.7, J1.10, U1.1 (vssa2), U1.10 (vssd2), U1.20 (vssa), U1.23 (vssd), U1.29 (vssio), U1.38 (vssa1), U1.39 (vssd1), U1.52 (vssa1), U1.56 (vssio), U1.65 (ThermalPad)
gpio: J4.10, U1.28 (gpio)
mprj_io[0]: J3.1, U1.31 (mprj_io[0]_JTAG)
mprj_io[1]_SDO: J3.2, U1.32 (mprj_io[1]_SDO)
mprj_io[2]_SDI: J3.3, U1.33 (mprj_io[2]_SDI)
mprj_io[3]_CSB: J3.4, U1.34 (mprj_io[3]_CSB)
mprj_io[4]_SCK: J3.5, U1.35 (mprj_io[4]_SCK)
mprj_io[5]_ser_rx: J3.6, U1.36 (mprj_io[5]_ser_rx)
mprj_io[6]_ser_tx: J3.7, U1.37 (mprj_io[6]_ser_tx)
mprj_io[7]: J3.8, U1.41 (mprj_io[7])
mprj_io[8]: J3.9, U1.42 (mprj_io[8])
mprj_io[9]: J3.10, U1.43 (mprj_io[9])
mprj_io[10]: J3.11, U1.44 (mprj_io[10])
mprj_io[11]: J3.12, U1.45 (mprj_io[11])
mprj_io[12]: J3.13, U1.46 (mprj_io[12])
mprj_io[13]: J3.14, U1.48 (mprj_io[13])
mprj_io[14]: J2.1, U1.50 (mprj_io[14])
mprj_io[15]: J2.2, U1.51 (mprj_io[15])
mprj_io[16]: J2.3, U1.53 (mprj_io[16])
mprj_io[17]: J2.4, U1.54 (mprj_io[17])
mprj_io[18]: J2.5, U1.55 (mprj_io[18])
mprj_io[19]: J2.6, U1.57 (mprj_io[19])
mprj_io[20]: J2.7, U1.58 (mprj_io[20])
mprj_io[21]: J2.8, U1.59 (mprj_io[21])
mprj_io[22]: J2.9, U1.60 (mprj_io[22])
mprj_io[23]: J2.10, U1.61 (mprj_io[23])
mprj_io[24]: J2.11, U1.62 (mprj_io[24])
mprj_io[25]: J2.12, U1.2 (mprj_io[25])
mprj_io[26]: J2.13, U1.3 (mprj_io[26])
mprj_io[27]: J2.14, U1.4 (mprj_io[27])
mprj_io[28]: J1.1, U1.5 (mprj_io[28])
mprj_io[29]: J1.2, U1.6 (mprj_io[29])
mprj_io[30]: J1.3, U1.7 (mprj_io[30])
mprj_io[31]: J1.4, U1.8 (mprj_io[31])
mprj_io[32]: J1.5, U1.11 (mprj_io[32])
mprj_io[33]: J1.6, U1.12 (mprj_io[33])
mprj_io[34]: J1.11, U1.13 (mprj_io[34])
mprj_io[35]: J1.12, U1.14 (mprj_io[35])
mprj_io[36]: J1.13, U1.15 (mprj_io[36])
mprj_io[37]: J1.14, U1.16 (mprj_io[37])
vccd: C4.2, J1.9, J4.7, U1.18 (vccd)
vccd1: C1.2, J4.14, U1.49 (vccd1)
vccd2: C7.2, J4.1, U1.63 (vccd2)
vdda: C3.1, J4.12, U1.30 (vdda)
vdda1: C2.1, C8.1, J4.13, U1.40 (vdda1), U1.47 (vdda1)
vdda2: C5.2, J4.3, U1.9 (vdda2)
vddio: C6.2, C9.2, J1.8, J4.2, U1.17 (vddio), U1.64 (vddio)
xclk: J4.5, U1.22 (clock)
~RST: J4.4, U1.21 (resetb)

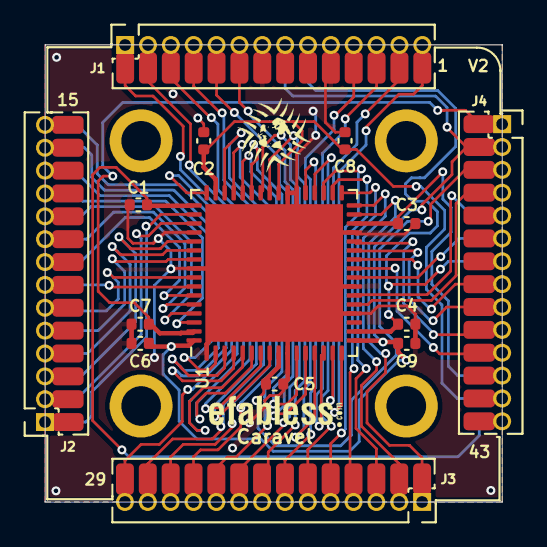
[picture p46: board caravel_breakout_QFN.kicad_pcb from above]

Board: 2 copper layers, 25.4 x 25.4 mm, 20 parts (0 on the bottom side), 53 nets.

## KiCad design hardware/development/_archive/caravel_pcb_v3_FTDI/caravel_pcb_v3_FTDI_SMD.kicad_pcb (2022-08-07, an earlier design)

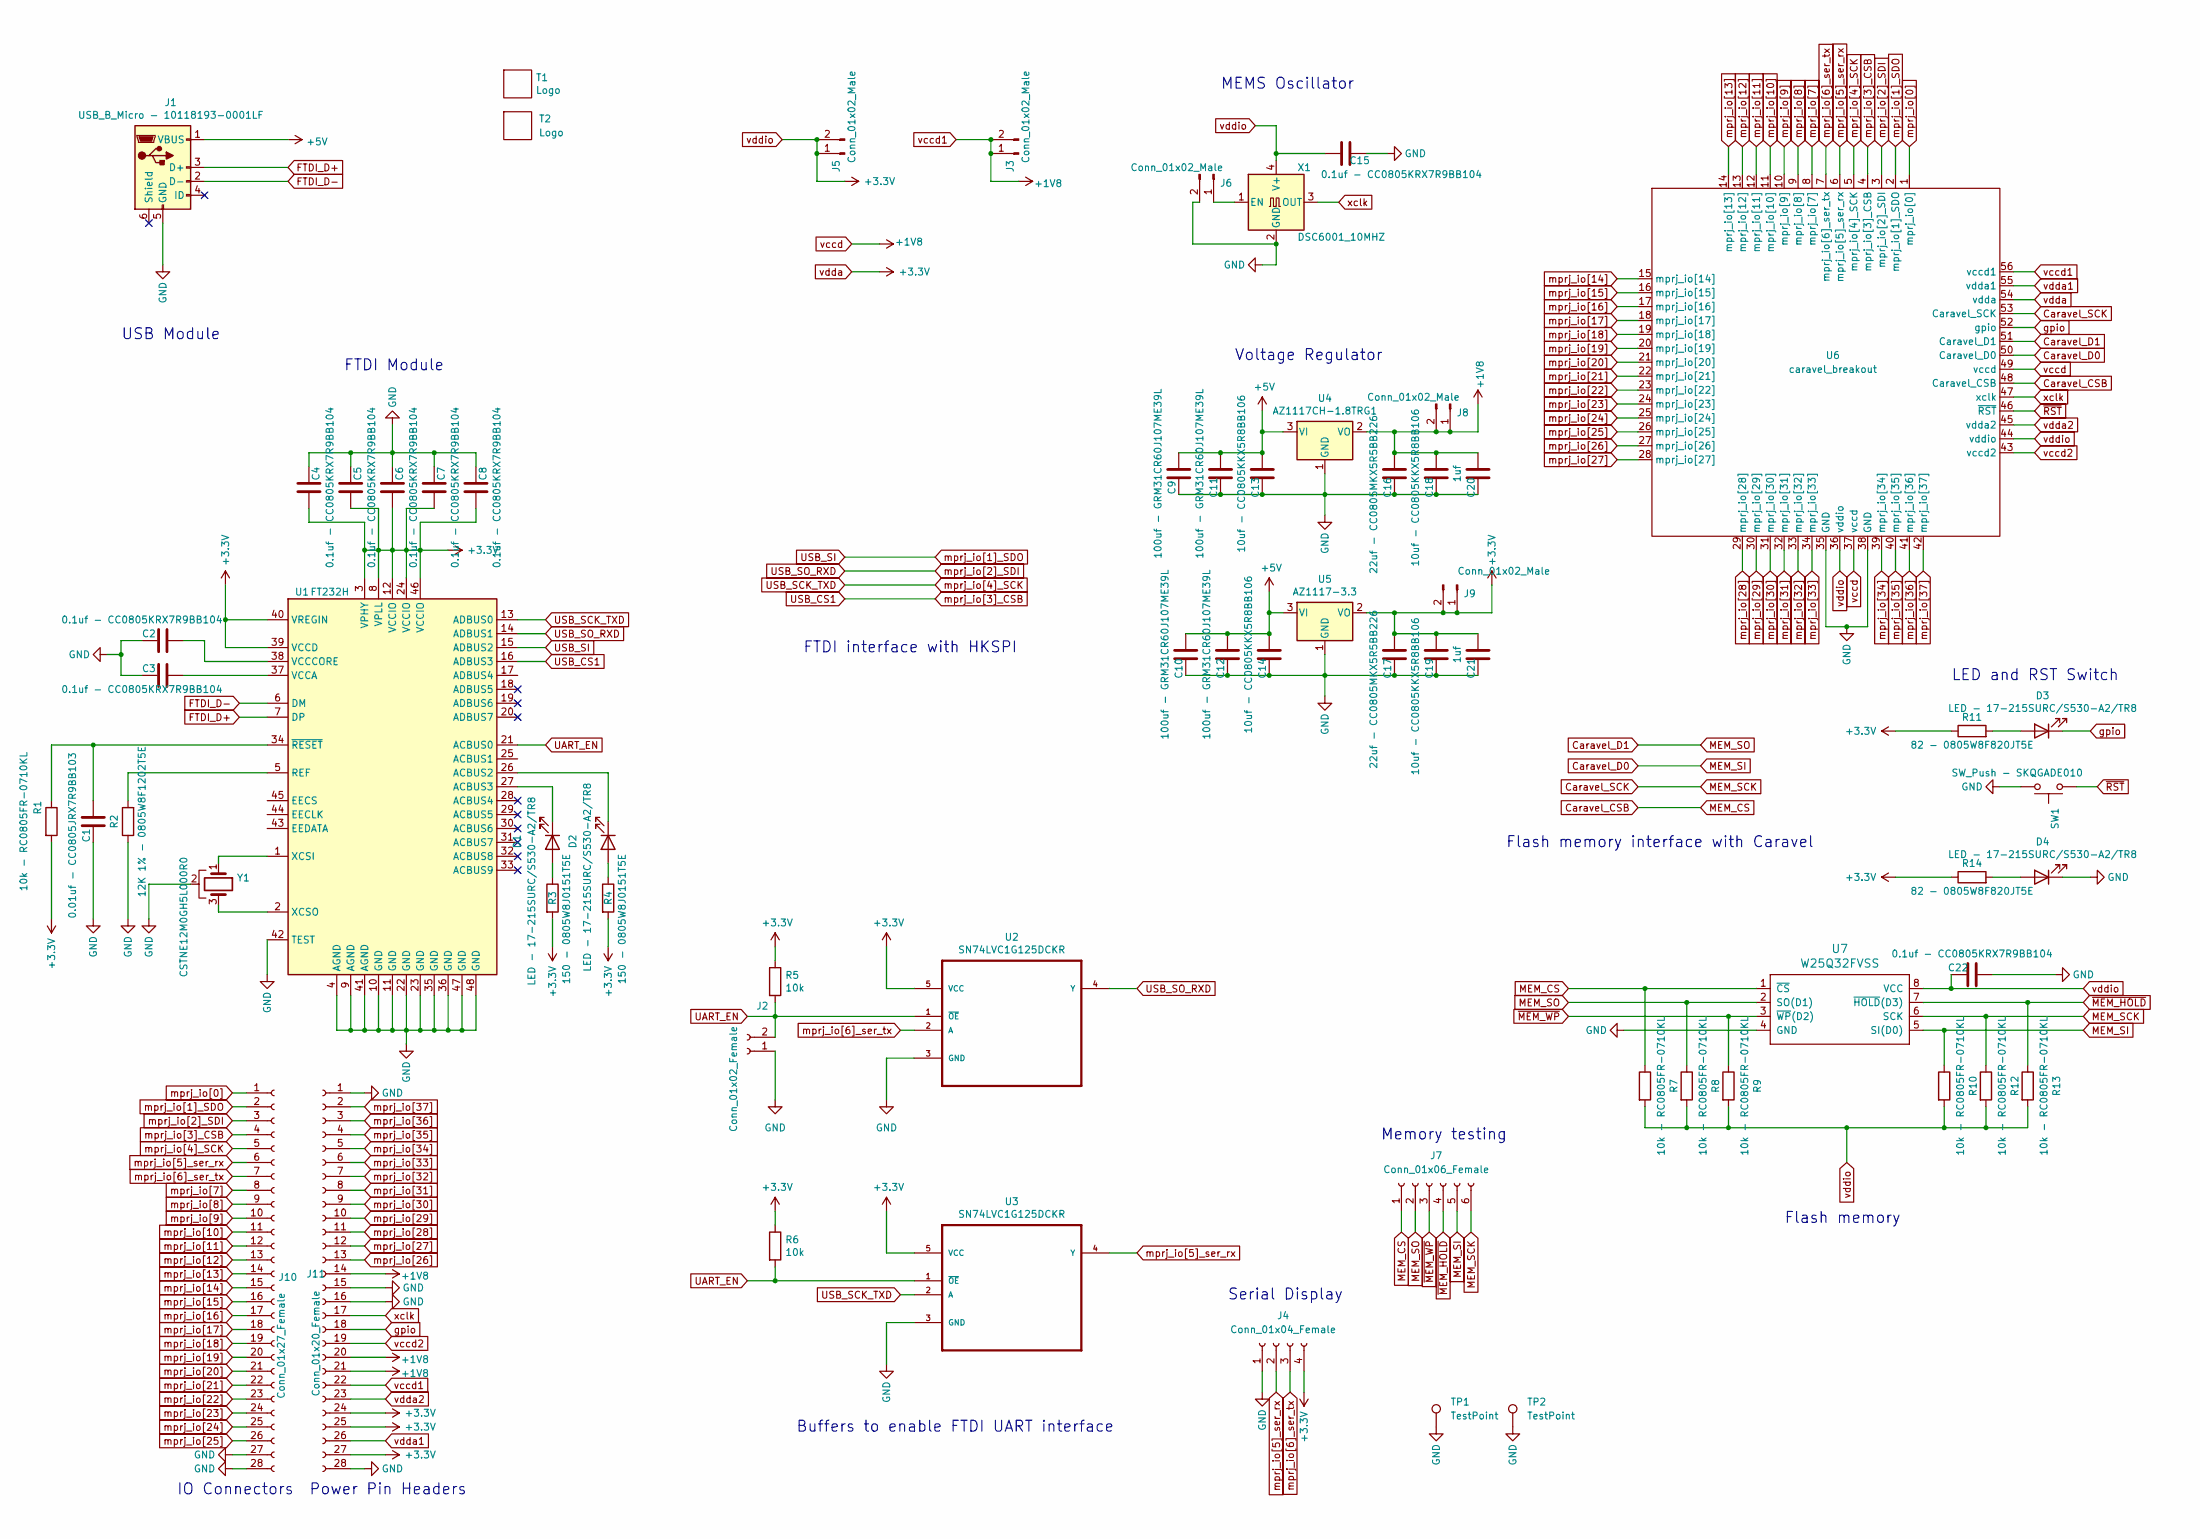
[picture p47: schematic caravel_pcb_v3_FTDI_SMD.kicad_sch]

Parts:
C1: 0.01uf - CC0805JRX7R9BB103; C_0805_2012Metric
C2, C3, C4, C5, C6, C7, C8, C15, C22: 0.1uf - CC0805KRX7R9BB104; C_0805_2012Metric
C9, C10, C11, C12: 100uf - GRM31CR60J107ME39L; C_1206_3216Metric
C13, C14, C18, C19: 10uf - CC0805KKX5R8BB106; C_0805_2012Metric
C16, C17: 22uf - CC0805MKX5R5BB226; C_0805_2012Metric
C20, C21: 1uf; C_0805_2012Metric
D1, D2, D3, D4: LED - 17-215SURC/S530-A2/TR8; LED_1206_3216Metric
J1: USB_B_Micro - 10118193-0001LF; FCI_10118193-0001LF
J2: Conn_01x02_Female; PinHeader_1x02_P2.54mm_Vertical
J3, J5, J6, J8, J9: Conn_01x02_Male; PinHeader_1x02_P2.54mm_Vertical
J4: Conn_01x04_Female; PinHeader_1x04_P2.54mm_Vertical
J7: Conn_01x06_Female; PinHeader_1x06_P2.54mm_Vertical
J10: Conn_01x27_Female; PinHeader_1x27_P2.54mm_Vertical
J11: Conn_01x20_Female; PinHeader_1x20_P2.54mm_Vertical
R1, R7, R8, R9, R10, R12, R13: 10k - RC0805FR-0710KL; R_0805_2012Metric
R2: 12K 1% - 0805W8F1202T5E; R_0805_2012Metric
R3, R4: 150 - 0805W8J0151T5E; R_0805_2012Metric
R5, R6: 10k; R_0805_2012Metric
R11, R14: 82 - 0805W8F820JT5E; R_0805_2012Metric
SW1: SW_Push - SKQGADE010; SW4-SMD-5.2X5.2X1.5MM
T1: Logo; logo
T2: Logo; ef_logo
TP1, TP2: TestPoint; TestPoint_Bridge_Pitch2.54mm_Drill1.0mm
U1: FT232H; QFN-48-1EP_8x8mm_P0.5mm_EP6.2x6.2mm
U2, U3: SN74LVC1G125DCKR; SOT65P210X110-5N
U4: AZ1117CH-1.8TRG1; SOT-223
U5: AZ1117-3.3; SOT-223
U6: caravel_breakout; caravel_breakout_SMD_rev3E
U7: W25Q32FVSS; SOIC127P790X216-8N
X1: DSC6001_10MHZ; DSC6001JE1A-010.0000
Y1: CSTNE12M0GH5L000R0

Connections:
+5V: C9.2, C10.2, C11.2, C12.2, C13.2, C14.2, J1.1 (VBUS), U4.3 (VI), U5.3 (VI)
Caravel_CSB: J7.1, R7.1, U6.48 (Caravel_CSB), U7.1 (~CS)
Caravel_D0: J7.5, R10.1, U6.50 (Caravel_D0), U7.5 (SI(D0))
Caravel_D1: J7.2, R8.1, U6.51 (Caravel_D1), U7.2 (SO(D1))
Caravel_SCK: J7.6, R12.1, U6.53 (Caravel_SCK), U7.6 (SCK)
FTDI_D+: J1.3 (D+), U1.7 (DP)
FTDI_D-: J1.2 (D-), U1.6 (DM)
GND: C1.1, C2.1, C3.1, C4.1, C5.1, C6.1, C7.1, C8.1, C9.1, C10.1, C11.1, C12.1, C13.1, C14.1, C15.1, C16.1, C17.1, C18.1, C19.1, C20.1, C21.1, C22.2, D4.1 (K), J1.5 (GND), J2.1, J4.1, J6.2, J10.27, J10.28, J11.1, J11.15, J11.16, J11.28, R2.1, SW1.2, TP1.1, TP2.1, U1.4 (AGND), U1.9 (AGND), U1.10 (GND), U1.11 (GND), U1.22 (GND), U1.23 (GND), U1.35 (GND), U1.36 (GND), U1.41 (AGND), U1.42 (TEST), U1.47 (GND), U1.48 (GND), U2.3 (GND), U3.3 (GND), U4.1 (GND), U5.1 (GND), U6.35 (GND), U6.38 (GND), U7.4 (GND), X1.2 (GND), Y1.2
unnamed: C1.2, R1.1, U1.34 (~RESET)
unnamed: C2.2, U1.38 (VCCCORE)
unnamed: C3.2, U1.37 (VCCA)
unnamed: D1.1 (K), U1.27 (ACBUS3)
unnamed: D1.2 (A), R3.1
unnamed: D2.1 (K), U1.26 (ACBUS2)
unnamed: D2.2 (A), R4.1
unnamed: D3.2 (A), R11.2
unnamed: D4.2 (A), R14.2
unnamed: J6.1, X1.1 (EN)
unnamed: R2.2, U1.5 (REF)
unnamed: U1.1 (XCSI), Y1.1
unnamed: U1.2 (XCSO), Y1.3
UART_EN: J2.2, R5.2, R6.2, U1.21 (ACBUS0), U2.1 (~OE), U3.1 (~OE)
USB_CS1: J10.4, U1.16 (ADBUS3), U6.4 (mprj_io[3]_CSB)
USB_SCK_TXD: J10.5, U1.13 (ADBUS0), U3.2 (A), U6.5 (mprj_io[4]_SCK)
USB_SI: J10.2, U1.15 (ADBUS2), U6.2 (mprj_io[1]_SDO)
USB_SO_RXD: J10.3, U1.14 (ADBUS1), U2.4 (Y), U6.3 (mprj_io[2]_SDI)
gpio: D3.1 (K), J11.18, U6.52 (gpio)
mprj_io[0]: J10.1, U6.1 (mprj_io[0])
mprj_io[5]_ser_rx: J4.2, J10.6, U3.4 (Y), U6.6 (mprj_io[5]_ser_rx)
mprj_io[6]_ser_tx: J4.3, J10.7, U2.2 (A), U6.7 (mprj_io[6]_ser_tx)
mprj_io[7]: J10.8, U6.8 (mprj_io[7])
mprj_io[8]: J10.9, U6.9 (mprj_io[8])
mprj_io[9]: J10.10, U6.10 (mprj_io[9])
mprj_io[10]: J10.11, U6.11 (mprj_io[10])
mprj_io[11]: J10.12, U6.12 (mprj_io[11])
mprj_io[12]: J10.13, U6.13 (mprj_io[12])
mprj_io[13]: J10.14, U6.14 (mprj_io[13])
mprj_io[14]: J10.15, U6.15 (mprj_io[14])
mprj_io[15]: J10.16, U6.16 (mprj_io[15])
mprj_io[16]: J10.17, U6.17 (mprj_io[16])
mprj_io[17]: J10.18, U6.18 (mprj_io[17])
mprj_io[18]: J10.19, U6.19 (mprj_io[18])
mprj_io[19]: J10.20, U6.20 (mprj_io[19])
mprj_io[20]: J10.21, U6.21 (mprj_io[20])
mprj_io[21]: J10.22, U6.22 (mprj_io[21])
mprj_io[22]: J10.23, U6.23 (mprj_io[22])
mprj_io[23]: J10.24, U6.24 (mprj_io[23])
mprj_io[24]: J10.25, U6.25 (mprj_io[24])
mprj_io[25]: J10.26, U6.26 (mprj_io[25])
mprj_io[26]: J11.13, U6.27 (mprj_io[26])
mprj_io[27]: J11.12, U6.28 (mprj_io[27])
mprj_io[28]: J11.11, U6.29 (mprj_io[28])
mprj_io[29]: J11.10, U6.30 (mprj_io[29])
mprj_io[30]: J11.9, U6.31 (mprj_io[30])
mprj_io[31]: J11.8, U6.32 (mprj_io[31])
mprj_io[32]: J11.7, U6.33 (mprj_io[32])
mprj_io[33]: J11.6, U6.34 (mprj_io[33])
mprj_io[34]: J11.5, U6.39 (mprj_io[34])
mprj_io[35]: J11.4, U6.40 (mprj_io[35])
mprj_io[36]: J11.3, U6.41 (mprj_io[36])
mprj_io[37]: J11.2, U6.42 (mprj_io[37])
vccd: C16.2, C18.2, C20.2, J3.1, J3.2, J8.1, J8.2, J11.14, J11.20, J11.21, J11.22, U4.2 (VO), U6.37 (vccd), U6.49 (vccd), U6.56 (vccd1)
vccd2: J11.19, U6.43 (vccd2)
vdda: C4.2, C5.2, C6.2, C7.2, C8.2, C15.2, C17.2, C19.2, C21.2, C22.1, J4.4, J5.1, J5.2, J9.1, J9.2, J11.24, J11.25, J11.27, R1.2, R3.2, R4.2, R5.1, R6.1, R7.2, R8.2, R9.2, R10.2, R11.1, R12.2, R13.2, R14.1, U1.3 (VPHY), U1.8 (VPLL), U1.12 (VCCIO), U1.24 (VCCIO), U1.39 (VCCD), U1.40 (VREGIN), U1.46 (VCCIO), U2.5 (VCC), U3.5 (VCC), U5.2 (VO), U6.36 (vddio), U6.44 (vddio), U6.54 (vdda), U7.8 (VCC), X1.4 (V+)
vdda1: J11.26, U6.55 (vdda1)
vdda2: J11.23, U6.45 (vdda2)
xclk: J11.17, U6.47 (xclk), X1.3 (OUT)
~MEM_HOLD: J7.4, R13.1, U7.7 (~HOLD(D3))
~MEM_WP: J7.3, R9.1, U7.3 (~WP(D2))
~RST: SW1.1, U6.46 (~RST)

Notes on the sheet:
Serial Display
LED and RST Switch
Flash memory interface with Caravel
Flash memory
Memory testing
FTDI interface with HKSPI
Power Pin Headers
Voltage Regulator
IO Connectors
FTDI Module
USB Module
MEMS Oscillator
Buffers to enable FTDI UART interface

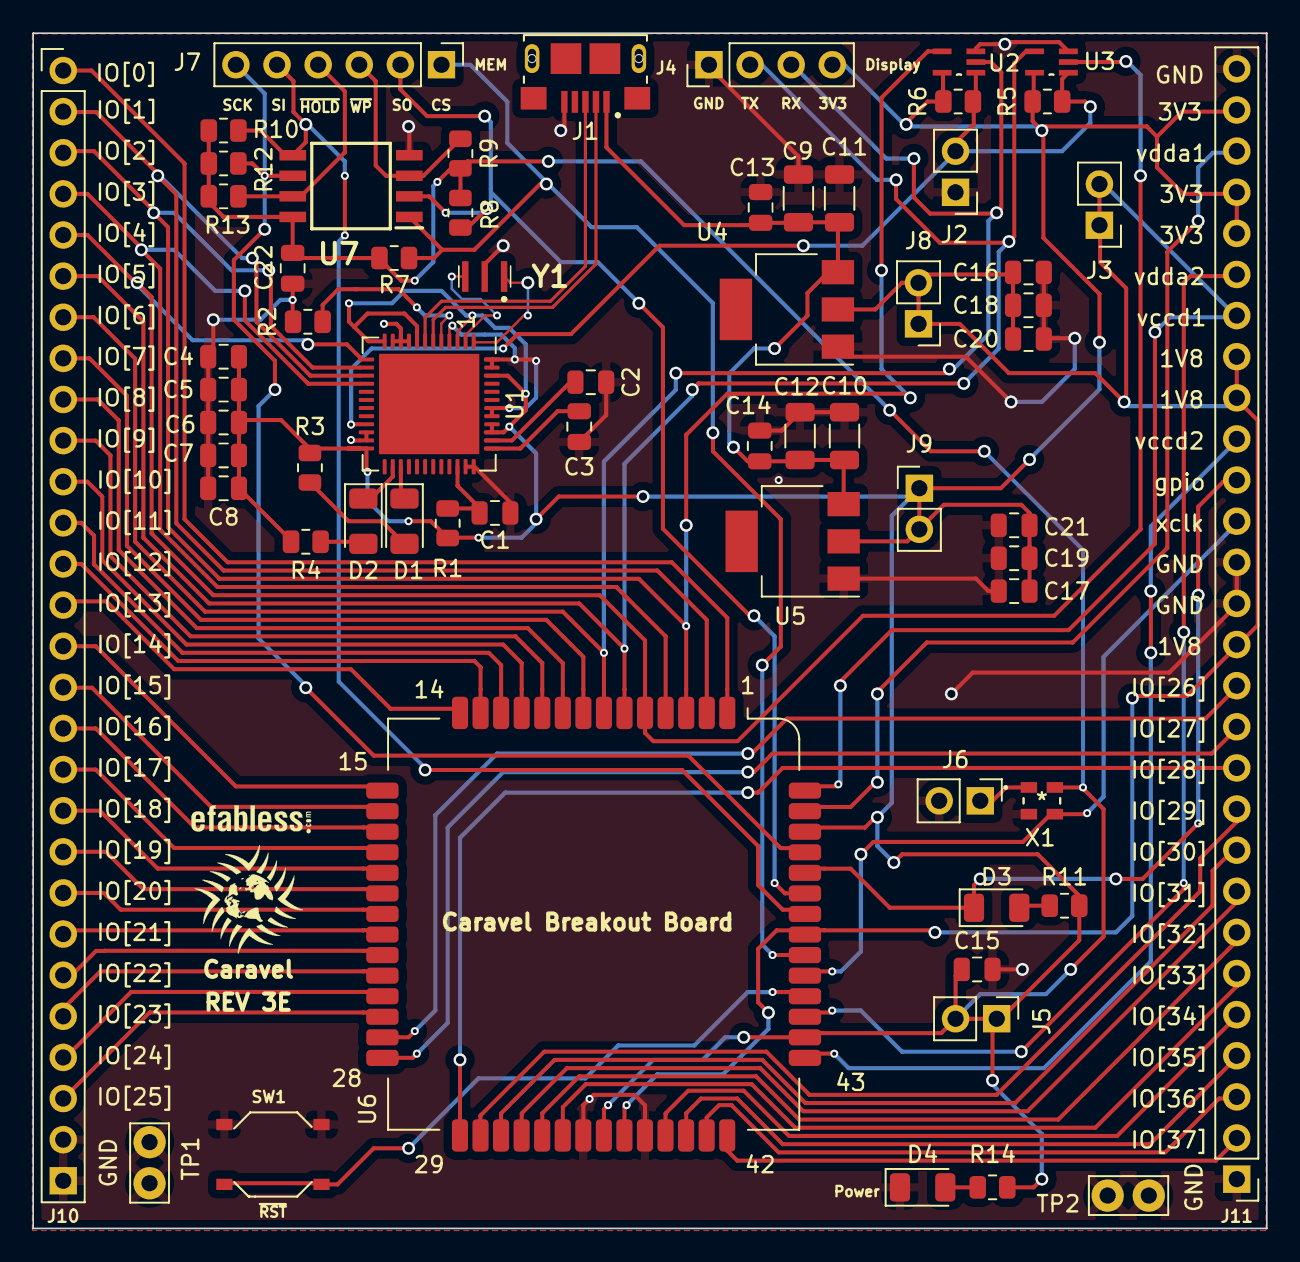
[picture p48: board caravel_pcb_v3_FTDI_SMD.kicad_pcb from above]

Board: 2 copper layers, 76.2 x 73.8 mm, 65 parts (0 on the bottom side), 70 nets.

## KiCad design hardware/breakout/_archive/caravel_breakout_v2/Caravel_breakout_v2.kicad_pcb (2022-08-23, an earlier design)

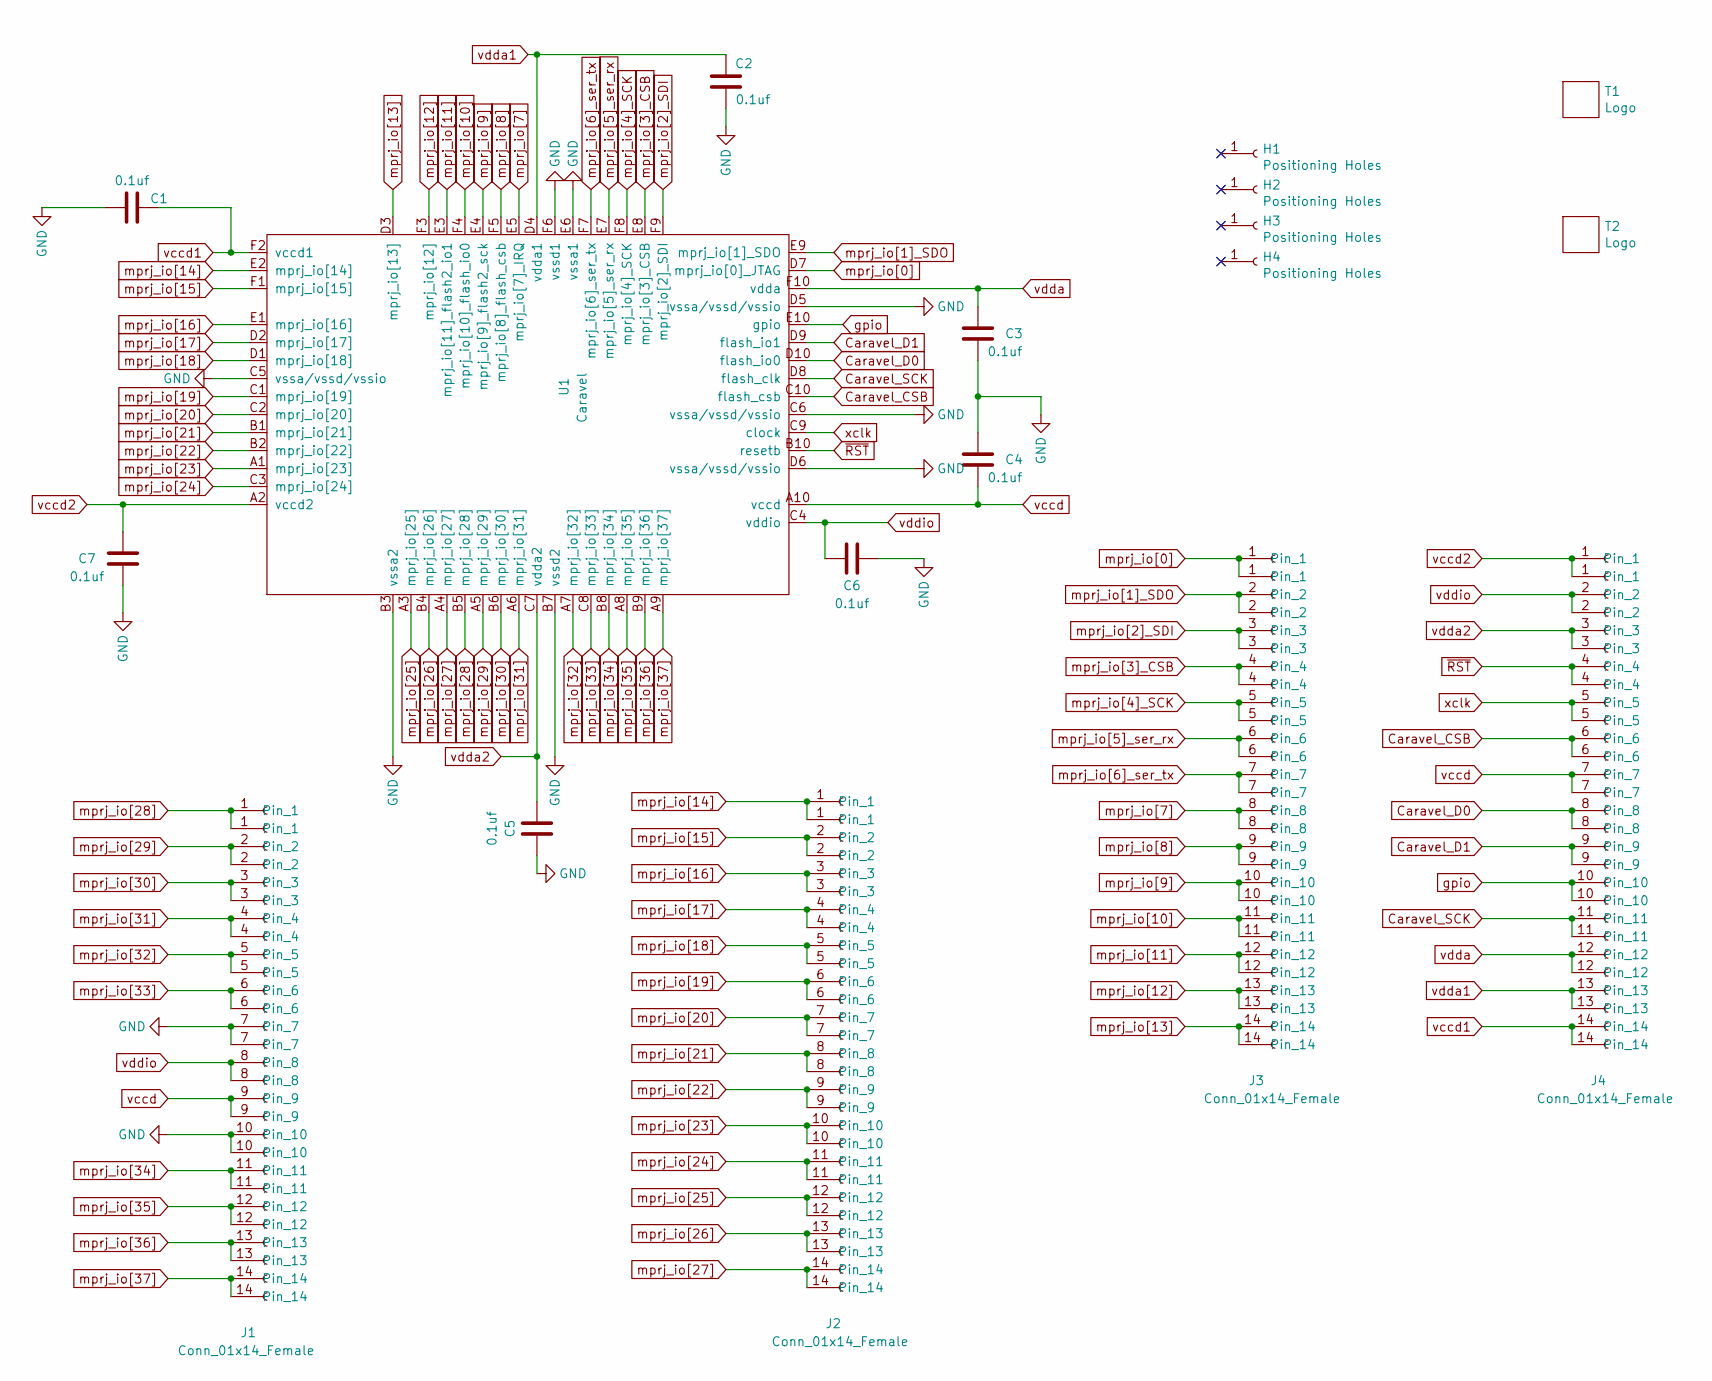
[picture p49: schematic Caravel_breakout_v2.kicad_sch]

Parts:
C1, C2, C3, C4, C5, C6, C7: 0.1uf; C_0603_1608Metric
H1, H2, H3, H4: Positioning Holes; MountingHole_2.2mm_M2_ISO7380_Pad
J1, J2, J3, J4: Conn_01x14_Female; Caravel_Breakout_Connectors_2x14
T1: Logo; logo
T2: Logo; ef_logo
U1: Caravel; Caravel_WCSP

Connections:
Caravel_CSB: J4.6, U1.C10 (flash_csb)
Caravel_D0: J4.8, U1.D10 (flash_io0)
Caravel_D1: J4.9, U1.D9 (flash_io1)
Caravel_SCK: J4.11, U1.D8 (flash_clk)
GND: C1.1, C2.2, C3.2, C4.1, C5.1, C6.1, C7.1, J1.7, J1.10, U1.B3 (vssa2), U1.B7 (vssd2), U1.C5 (vssa/vssd/vssio), U1.C6 (vssa/vssd/vssio), U1.D5 (vssa/vssd/vssio), U1.D6 (vssa/vssd/vssio), U1.E6 (vssa1), U1.F6 (vssd1)
gpio: J4.10, U1.E10 (gpio)
mprj_io[0]: J3.1, U1.D7 (mprj_io[0]_JTAG)
mprj_io[1]_SDO: J3.2, U1.E9 (mprj_io[1]_SDO)
mprj_io[2]_SDI: J3.3, U1.F9 (mprj_io[2]_SDI)
mprj_io[3]_CSB: J3.4, U1.E8 (mprj_io[3]_CSB)
mprj_io[4]_SCK: J3.5, U1.F8 (mprj_io[4]_SCK)
mprj_io[5]_ser_rx: J3.6, U1.E7 (mprj_io[5]_ser_rx)
mprj_io[6]_ser_tx: J3.7, U1.F7 (mprj_io[6]_ser_tx)
mprj_io[7]: J3.8, U1.E5 (mprj_io[7]_IRQ)
mprj_io[8]: J3.9, U1.F5 (mprj_io[8]_flash_csb)
mprj_io[9]: J3.10, U1.E4 (mprj_io[9]_flash2_sck)
mprj_io[10]: J3.11, U1.F4 (mprj_io[10]_flash_io0)
mprj_io[11]: J3.12, U1.E3 (mprj_io[11]_flash2_io1)
mprj_io[12]: J3.13, U1.F3 (mprj_io[12])
mprj_io[13]: J3.14, U1.D3 (mprj_io[13])
mprj_io[14]: J2.1, U1.E2 (mprj_io[14])
mprj_io[15]: J2.2, U1.F1 (mprj_io[15])
mprj_io[16]: J2.3, U1.E1 (mprj_io[16])
mprj_io[17]: J2.4, U1.D2 (mprj_io[17])
mprj_io[18]: J2.5, U1.D1 (mprj_io[18])
mprj_io[19]: J2.6, U1.C1 (mprj_io[19])
mprj_io[20]: J2.7, U1.C2 (mprj_io[20])
mprj_io[21]: J2.8, U1.B1 (mprj_io[21])
mprj_io[22]: J2.9, U1.B2 (mprj_io[22])
mprj_io[23]: J2.10, U1.A1 (mprj_io[23])
mprj_io[24]: J2.11, U1.C3 (mprj_io[24])
mprj_io[25]: J2.12, U1.A3 (mprj_io[25])
mprj_io[26]: J2.13, U1.B4 (mprj_io[26])
mprj_io[27]: J2.14, U1.A4 (mprj_io[27])
mprj_io[28]: J1.1, U1.B5 (mprj_io[28])
mprj_io[29]: J1.2, U1.A5 (mprj_io[29])
mprj_io[30]: J1.3, U1.B6 (mprj_io[30])
mprj_io[31]: J1.4, U1.A6 (mprj_io[31])
mprj_io[32]: J1.5, U1.A7 (mprj_io[32])
mprj_io[33]: J1.6, U1.C8 (mprj_io[33])
mprj_io[34]: J1.11, U1.B8 (mprj_io[34])
mprj_io[35]: J1.12, U1.A8 (mprj_io[35])
mprj_io[36]: J1.13, U1.B9 (mprj_io[36])
mprj_io[37]: J1.14, U1.A9 (mprj_io[37])
vccd: C4.2, J1.9, J4.7, U1.A10 (vccd)
vccd1: C1.2, J4.14, U1.F2 (vccd1)
vccd2: C7.2, J4.1, U1.A2 (vccd2)
vdda: C3.1, J4.12, U1.F10 (vdda)
vdda1: C2.1, J4.13, U1.D4 (vdda1)
vdda2: C5.2, J4.3, U1.C7 (vdda2)
vddio: C6.2, J1.8, J4.2, U1.C4 (vddio)
xclk: J4.5, U1.C9 (clock)
~RST: J4.4, U1.B10 (resetb)

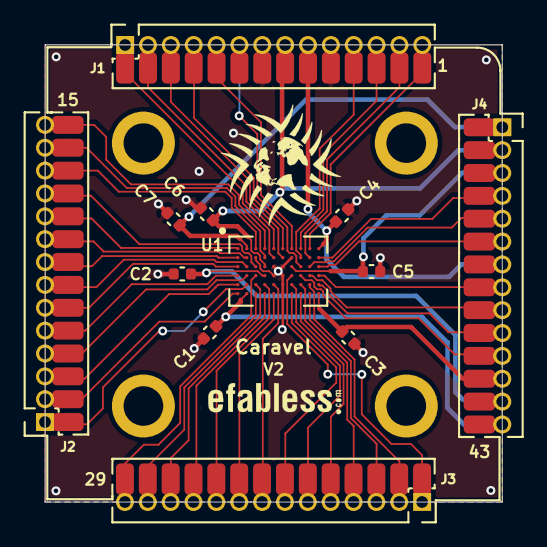
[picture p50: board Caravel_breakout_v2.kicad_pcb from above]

Board: 2 copper layers, 25.4 x 25.4 mm, 18 parts (0 on the bottom side), 53 nets.

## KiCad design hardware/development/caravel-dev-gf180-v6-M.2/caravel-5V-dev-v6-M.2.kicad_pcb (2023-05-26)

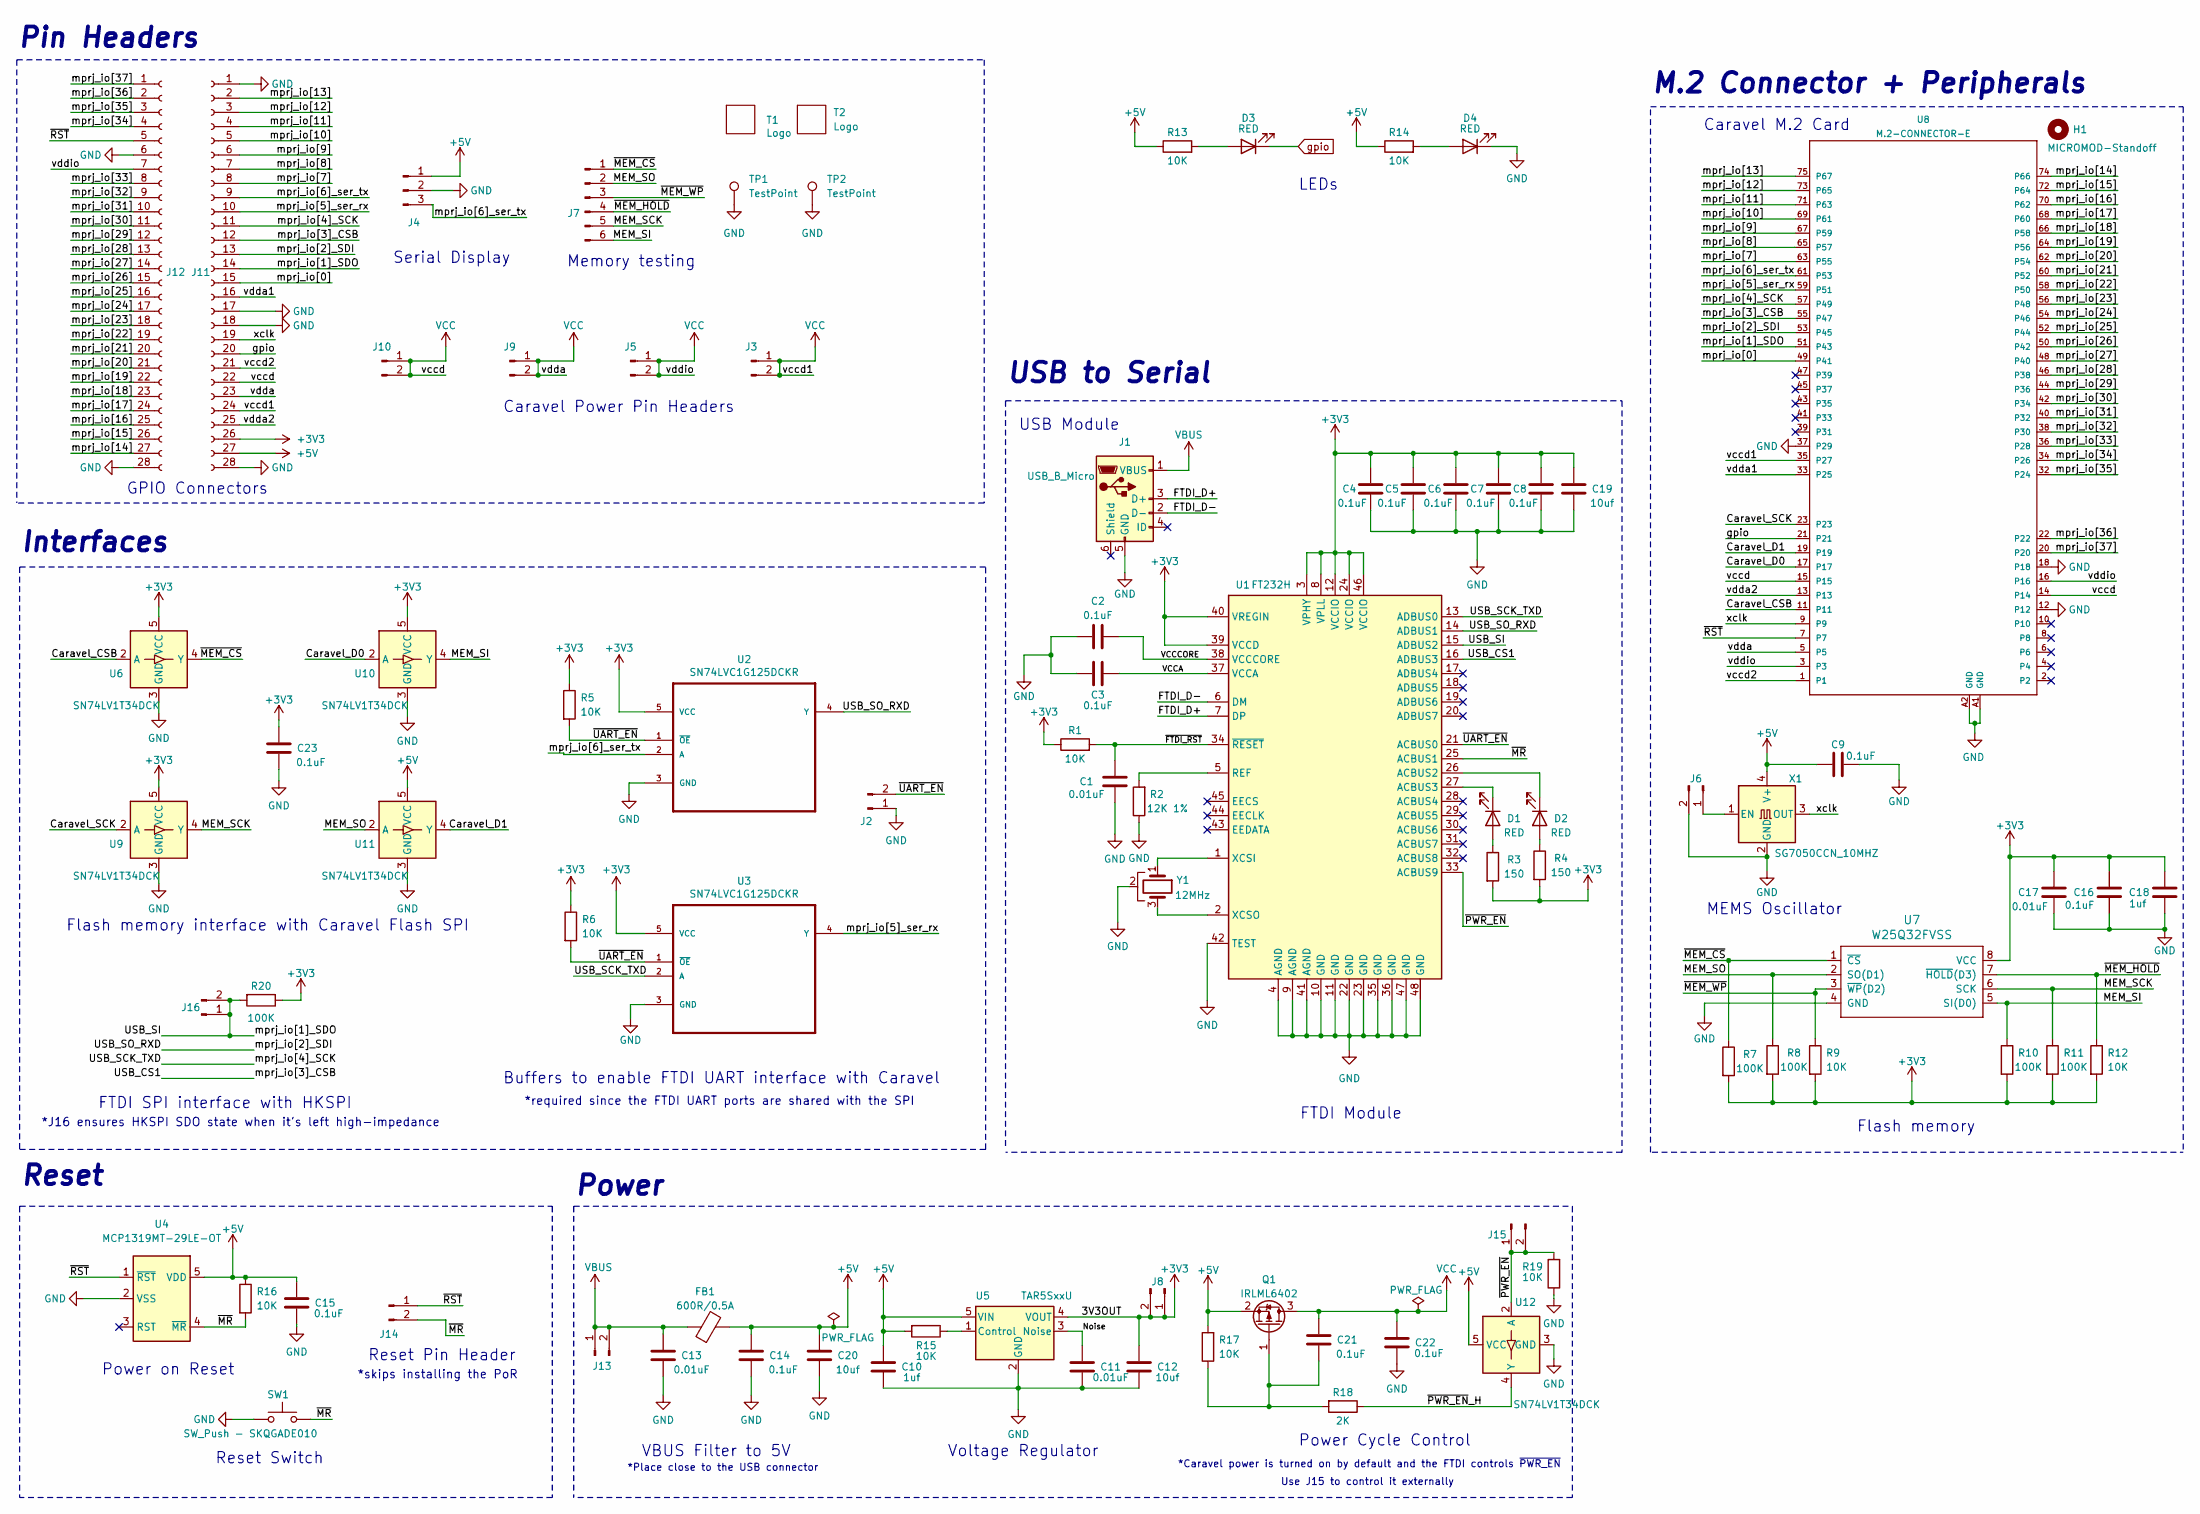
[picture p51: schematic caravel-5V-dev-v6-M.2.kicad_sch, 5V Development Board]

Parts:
C1, C11, C13, C17: 0.01uF; C_0805_2012Metric; Part # C0805C103K5RAC7411
C2, C3, C4, C5, C6, C7, C8, C9, C14, C15, C16, C21, C22, C23: 0.1uF; C_0805_2012Metric; Part # C0805C104K5RAC7411
C10, C18: 1uf; C_0805_2012Metric; Part # 885012207103
C12, C19, C20: 10uf; C_0805_2012Metric; Part # CL21B106KAYQNNE
D1, D2, D3, D4: RED; LED_1206_3216Metric; Part # LTST-C230KRKT
FB1: 600R/0.5A; L_0805_2012Metric; Part # 7427920415
H1: MICROMOD-Standoff; MicroMod-Standoff
J1: USB_B_Micro; FCI_10118193-0001LF; Part # 10118193-0001LF
J2, J3, J5, J6, J8, J9, J10, J13, J14, J15, J16: Conn_01x02_Pin; PinHeader_1x02_P2.54mm_Vertical
J4: Conn_01x03_Pin; PinHeader_1x03_P2.54mm_Vertical
J7: Conn_01x06_Pin; PinHeader_1x06_P2.54mm_Vertical
J11, J12: Conn_01x28_Pin; PinHeader_1x28_P2.54mm_Vertical
Q1: IRLML6402; SOT-23; Part # IRLML6402
R1, R5, R6, R9, R12, R13, R14, R15, R16, R17, R19: 10K; R_0805_2012Metric; Part # RC0805FR-0710KL
R2: 12K 1%; R_0805_2012Metric; Part # RMCF0805FT12K0
R3, R4: 150; R_0805_2012Metric; Part # RNCP0805FTD150R
R7, R8, R10, R11, R20: 100K; R_0805_2012Metric; Part # RC0805FR-07100KL
R18: 2K; R_0805_2012Metric; Part # RC0805FR-072KL
SW1: SW_Push - SKQGADE010; SW4-SMD-5.2X5.2X1.5MM
T1: Logo; logo
T2: Logo; ef_logo
TP1, TP2: TestPoint; TestPoint_Bridge_Pitch2.54mm_Drill1.0mm
U1: FT232H; QFN-48-1EP_8x8mm_P0.5mm_EP6.2x6.2mm; Part # FT232H
U2, U3: SN74LVC1G125DCKR; SOT65P210X110-5N; Part # SN74LVC1G125DCKR
U4: MCP1319MT-29LE-OT; PoR_5_SOT23; Part # MCP1319MT-29LE-OT
U5: TAR5SxxU; SOT-353F; Part # TAR5S33UTE85LF
U6, U9, U10, U11, U12: SN74LV1T34DCK; SOT-353_SC-70-5; Part # SN74LV1T34DCK
U7: W25Q32FVSS; SOIC127P790X216-8N; Part # W25Q32JVSSIQ
U8: M.2-CONNECTOR-E
X1: SG7050CCN_10MHZ; SG7050CCN-10M-HJGA3; Part # SG7050CCN-10-000000M-HJGA3
Y1: 12MHz; CSTNE12M0GH5L000R0; Part # CSTNE12M0GH5L000R0

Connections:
+3V3: C4.1, C5.1, C6.1, C7.1, C8.1, C12.2, C16.1, C17.2, C18.1, C19.1, C23.2, J8.1, J8.2, J11.26, R1.1, R3.2, R4.2, R5.1, R6.1, R7.2, R8.2, R9.2, R10.2, R11.2, R12.2, R20.1, U1.3 (VPHY), U1.8 (VPLL), U1.12 (VCCIO), U1.24 (VCCIO), U1.39 (VCCD), U1.40 (VREGIN), U1.46 (VCCIO), U2.5 (VCC), U3.5 (VCC), U5.4 (VOUT), U6.5 (VCC), U7.8 (VCC), U9.5 (VCC), U10.5 (VCC)
+5V: C9.2, C10.2, C14.2, C15.1, C20.2, FB1.2, J4.1, J11.27, Q1.2 (S), R13.1, R14.1, R15.2, R16.1, R17.2, U4.5 (VDD), U5.5 (VIN), U11.5 (VCC), U12.5 (VCC), X1.4 (V+)
/Caravel_CSB: U6.2 (A), U8.11
/Caravel_D0: U8.17, U10.2 (A)
/Caravel_D1: U8.19, U11.4 (Y)
/Caravel_SCK: U8.23, U9.2 (A)
/FTDI_D+: J1.3 (D+), U1.7 (DP)
/FTDI_D-: J1.2 (D-), U1.6 (DM)
/MEM_SCK: J7.5, R11.1, U7.6 (SCK), U9.4 (Y)
/MEM_SI: J7.6, R10.1, U7.5 (SI(D0)), U10.4 (Y)
/MEM_SO: J7.2, R8.1, U7.2 (SO(D1)), U11.2 (A)
/Noise: C11.1, U5.3 (Noise)
/USB_CS1: J11.12, U1.16 (ADBUS3), U8.55 (P47)
/USB_SCK_TXD: J11.11, U1.13 (ADBUS0), U3.2 (A), U8.57 (P49)
/USB_SI: J11.14, J16.1, J16.2, R20.2, U1.15 (ADBUS2), U8.51 (P43)
/USB_SO_RXD: J11.13, U1.14 (ADBUS1), U2.4 (Y), U8.53 (P45)
/VCCA: C3.2, U1.37 (VCCA)
/VCCCORE: C2.2, U1.38 (VCCCORE)
/mprj_io[0]: J11.15, U8.49 (P41)
/mprj_io[5]_ser_rx: J11.10, U3.4 (Y), U8.59 (P51)
/mprj_io[6]_ser_tx: J4.3, J11.9, U2.2 (A), U8.61 (P53)
/mprj_io[7]: J11.8, U8.63 (P55)
/mprj_io[8]: J11.7, U8.65 (P57)
/mprj_io[9]: J11.6, U8.67 (P59)
/mprj_io[10]: J11.5, U8.69 (P61)
/mprj_io[11]: J11.4, U8.71 (P63)
/mprj_io[12]: J11.3, U8.73 (P65)
/mprj_io[13]: J11.2, U8.75 (P67)
/mprj_io[14]: J12.27, U8.74 (P66)
/mprj_io[15]: J12.26, U8.72 (P64)
/mprj_io[16]: J12.25, U8.70 (P62)
/mprj_io[17]: J12.24, U8.68 (P60)
/mprj_io[18]: J12.23, U8.66 (P58)
/mprj_io[19]: J12.22, U8.64 (P56)
/mprj_io[20]: J12.21, U8.62 (P54)
/mprj_io[21]: J12.20, U8.60 (P52)
/mprj_io[22]: J12.19, U8.58 (P50)
/mprj_io[23]: J12.18, U8.56 (P48)
/mprj_io[24]: J12.17, U8.54 (P46)
/mprj_io[25]: J12.16, U8.52 (P44)
/mprj_io[26]: J12.15, U8.50 (P42)
/mprj_io[27]: J12.14, U8.48 (P40)
/mprj_io[28]: J12.13, U8.46 (P38)
/mprj_io[29]: J12.12, U8.44 (P36)
/mprj_io[30]: J12.11, U8.42 (P34)
/mprj_io[31]: J12.10, U8.40 (P32)
/mprj_io[32]: J12.9, U8.38 (P30)
/mprj_io[33]: J12.8, U8.36 (P28)
/mprj_io[34]: J12.4, U8.34 (P26)
/mprj_io[35]: J12.3, U8.32 (P24)
/mprj_io[36]: J12.2, U8.22
/mprj_io[37]: J12.1, U8.20
/vccd2: J11.21, U8.1
/vdda1: J11.16, U8.33 (P25)
/vdda2: J11.25, U8.13
/xclk: J11.19, U8.9, X1.3 (OUT)
/~FTDI_RST: C1.2, R1.2, U1.34 (~RESET)
/~MEM_CS: J7.1, R7.1, U6.4 (Y), U7.1 (~CS)
/~MEM_HOLD: J7.4, R12.1, U7.7 (~HOLD(D3))
/~MEM_WP: J7.3, R9.1, U7.3 (~WP(D2))
/~MR: J14.2, R16.2, SW1.1, U1.25 (ACBUS1), U4.4 (~MR)
/~PWR_EN: J15.1, J15.2, R19.2, U1.33 (ACBUS9), U12.2 (A)
/~PWR_EN_H: R18.1, U12.4 (Y)
/~RST: J12.5, J14.1, U4.1 (~RST), U8.7
/~UART_EN: J2.2, R5.2, R6.2, U1.21 (ACBUS0), U2.1 (~OE), U3.1 (~OE)
GND: C1.1, C2.1, C3.1, C4.2, C5.2, C6.2, C7.2, C8.2, C9.1, C10.1, C11.2, C12.1, C13.2, C14.1, C15.2, C16.2, C17.1, C18.2, C19.2, C20.1, C22.1, C23.1, D4.1 (K), J1.5 (GND), J2.1, J4.2, J6.2, J11.1, J11.17, J11.18, J11.28, J12.6, J12.28, R2.1, R19.1, SW1.2, TP1.1, TP2.1, U1.4 (AGND), U1.9 (AGND), U1.10 (GND), U1.11 (GND), U1.22 (GND), U1.23 (GND), U1.35 (GND), U1.36 (GND), U1.41 (AGND), U1.42 (TEST), U1.47 (GND), U1.48 (GND), U2.3 (GND), U3.3 (GND), U4.2 (VSS), U5.2 (GND), U6.3 (GND), U7.4 (GND), U8.12, U8.18, U8.37 (P29), U8.A1 (GND), U8.A2 (GND), U9.3 (GND), U10.3 (GND), U11.3 (GND), U12.3 (GND), X1.2 (GND), Y1.2
unnamed: D1.2 (A), R3.1
unnamed: D1.1 (K), U1.27 (ACBUS3)
unnamed: D2.2 (A), R4.1
unnamed: D2.1 (K), U1.26 (ACBUS2)
unnamed: D3.2 (A), R13.2
unnamed: D4.2 (A), R14.2
unnamed: J6.1, X1.1 (EN)
unnamed: C21.1, Q1.1 (G), R17.1, R18.2
unnamed: R2.2, U1.5 (REF)
unnamed: U1.1 (XCSI), Y1.1
unnamed: U1.2 (XCSO), Y1.3
unnamed: R15.1, U5.1 (Control)
VBUS: C13.1, FB1.1, J1.1 (VBUS), J13.1, J13.2
VCC: C21.2, C22.2, J3.1, J3.2, J5.1, J5.2, J9.1, J9.2, J10.1, J10.2, J11.22, J11.23, J11.24, J12.7, Q1.3 (D), U8.3, U8.5, U8.14, U8.15, U8.16, U8.35 (P27)
gpio: D3.1 (K), J11.20, U8.21

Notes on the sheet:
Serial Display
*required since the FTDI UART ports are shared with the SPI
Pin Headers
Use J15 to control it externally
Flash memory interface with Caravel Flash SPI
USB to Serial
Caravel Power Pin Headers
*J16 ensures HKSPI SDO state when it's left high-impedance
Caravel M.2 Card
Power on Reset
Flash memory
Memory testing
FTDI SPI interface with HKSPI
Interfaces
Power Cycle Control
*skips installing the PoR
LEDs
Voltage Regulator
Reset Switch
Power
Reset Pin Header
GPIO Connectors
VBUS Filter to 5V
*Place close to the USB connector
FTDI Module
USB Module
MEMS Oscillator
*Caravel power is turned on by default and the FTDI controls ~{PWR_EN}
Buffers to enable FTDI UART interface with Caravel
Reset
M.2 Connector + Peripherals

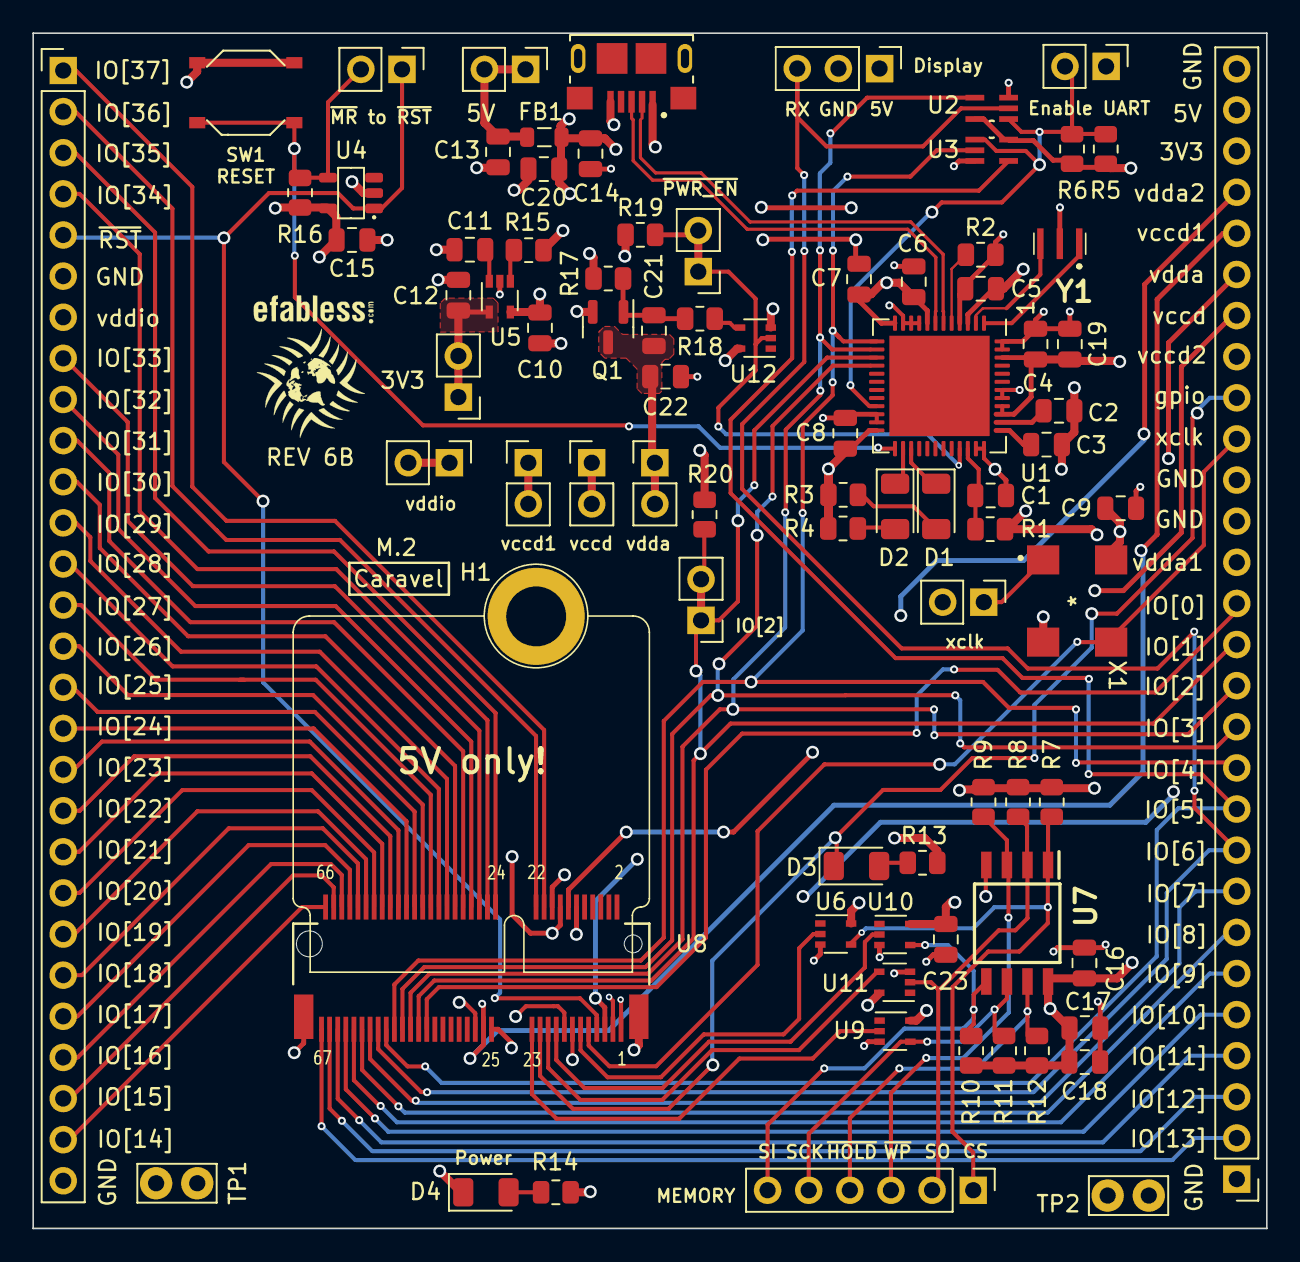
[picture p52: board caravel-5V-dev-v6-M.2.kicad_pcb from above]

Board: 4 copper layers, 76.2 x 73.8 mm, 85 parts (0 on the bottom side), 81 nets.

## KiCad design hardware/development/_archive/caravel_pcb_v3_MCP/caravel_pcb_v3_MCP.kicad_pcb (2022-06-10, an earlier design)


Board: 2 copper layers, 38 parts (0 on the bottom side), 29 nets, no tracks yet.

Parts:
C1: 0.47uf; C_0805_2012Metric
C2, C3, C4, C5: 100uf - GRM31CR60J107ME39L; C_1206_3216Metric
C6, C7, C10, C11: 10uf - CC0805KKX5R8BB106; C_0805_2012Metric
C8, C9: 22uf - CC0805MKX5R5BB226; C_0805_2012Metric
C12, C15: 0.1uf - CC0805KRX7R9BB104; C_0805_2012Metric
C13, C14: 1uf; C_0805_2012Metric
D1: LED - 17-215SURC/S530-A2/TR8; LED_1206_3216Metric
J1: USB_B_Micro - 10118194-0001LF; USB_Micro-B_Amphenol_10118194_Horizontal
J2: Conn_01x14_Female; PinHeader_1x14_P2.54mm_Vertical
J3, J4, J5, J6: Conn_01x02_Male; PinHeader_1x02_P2.54mm_Vertical
J7: Conn_01x06_Female; PinSocket_1x06_P2.54mm_Vertical
R1, R3, R4, R5, R6, R7, R8: 10k - RC0805FR-0710KL; R_0805_2012Metric
R2: 82 - 0805W8F820JT5E; R_0805_2012Metric
SW1: SW_Push - SKQGADE010; SW_SPST_SKQG_WithStem
U1: MCP2221AxML; QFN-16-1EP_4x4mm_P0.65mm_EP2.5x2.5mm
U2: AZ1117CH-1.8TRG1; SOT-223-3_TabPin2
U3: AZ1117-3.3; SOT-223-3_TabPin2
U4: caravel_breakout; caravel_breakout_v1
U5: W25Q32FVSS; SOIC-8_5.23x5.23mm_P1.27mm
X1: ASV-10.000MHZ-EJ-T; Oscillator_SMD_Abracon_ASV-4Pin_7.0x5.1mm

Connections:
+5V: C2.2, C3.2, C4.2, C5.2, C6.2, C7.2, J1.1 (VBUS), U1.16 (VDD), U2.3 (VI), U3.3 (VI)
Caravel_CSB: J7.1, R3.1, U4.6 (Caravel_CSB), U5.1 (~CS)
Caravel_D0: J7.5, R6.1, U4.8 (Caravel_D0), U5.5 (SI(D0))
Caravel_D1: J7.2, R4.1, U4.9 (Caravel_D1), U5.2 (SO(D1))
Caravel_SCK: J7.6, R7.1, U4.11 (Caravel_SCK), U5.6 (SCK)
GND: C1.2, C2.1, C3.1, C4.1, C5.1, C6.1, C7.1, C8.1, C9.1, C10.1, C11.1, C12.1, C13.1, C14.1, C15.2, J1.5 (GND), J2.2, J2.3, J3.2, R1.1, SW1.2, U1.13 (VSS), U2.1 (GND), U3.1 (GND), U4.49 (GND), U4.52 (GND), U5.4 (GND), X1.2 (GND)
MCP_D+: J1.3 (D+), U1.12 (D+)
MCP_D-: J1.2 (D-), U1.11 (D-)
unnamed: C1.1, U1.10 (VUSB)
unnamed: D1.2 (A), R2.2
unnamed: J3.1, X1.1 (EN)
unnamed: R1.2, U1.3 (~RST)
USB_CS: U1.1 (GP0), U4.18 (mprj_io[3]_CSB)
USB_MISO: U1.6 (GP2), U4.16 (mprj_io[1]_SDO)
USB_MOSI: U1.7 (GP3), U4.17 (mprj_io[2]_SDI)
USB_SCK: U1.2 (GP1), U4.19 (mprj_io[4]_SCK)
gpio: D1.1 (K), J2.5, U4.10 (gpio)
mprj_io[5]_ser_rx: U1.5 (UTx), U4.20 (mprj_io[5]_ser_rx)
mprj_io[6]_ser_tx: U1.4 (URx), U4.21 (mprj_io[6]_ser_tx)
vccd: C8.2, C10.2, C13.2, J2.1, J2.7, J2.8, J4.1, J4.2, U2.2 (VO), U4.7 (vccd), U4.51 (vccd)
vccd1: J2.9, U4.14 (vccd1)
vccd2: J2.6, U4.1 (vccd2)
vdda: C9.2, C11.2, C12.2, C14.2, C15.1, J2.11, J2.12, J2.14, J5.1, J5.2, J6.1, J6.2, R2.1, R3.2, R4.2, R5.2, R6.2, R7.2, R8.2, U3.2 (VO), U4.2 (vddio), U4.12 (vdda), U4.50 (vddio), U5.8 (VCC), X1.4 (V+)
vdda1: J2.13, U4.13 (vdda1)
vdda2: J2.10, U4.3 (vdda2)
xclk: J2.4, U4.5 (xclk), X1.3 (OUT)
~MEM_HOLD: J7.4, R8.1, U5.7 (~HOLD(D3))
~MEM_WP: J7.3, R5.1, U5.3 (~WP(D2))
~RST: SW1.1, U4.4 (~RST)

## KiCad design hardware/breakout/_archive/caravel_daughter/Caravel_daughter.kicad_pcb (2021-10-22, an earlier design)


Board: 2 copper layers, 25.4 x 25.4 mm, 37 parts (0 on the bottom side), 57 nets, no tracks yet.

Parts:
C1, C2, C3, C4, C6, C7, C8, C9, C10, C11, C13, C15: 0.1uf; C_0603_1608Metric
C5: 10uf; C_0603_1608Metric
C12, C14: 2.2uf; C_0603_1608Metric
D1: LED - 17-215SURC/S530-A2/TR8; LED_0603_1608Metric
J1: TC2030-IDC-NL; TAG_TC2030-IDC-NL
J2: Conn_01x02_Male; PinHeader_1x02_P1.00mm_Vertical_SMD_Pin1Left
J3, J4, J5, J6: Conn_01x14_Female; PinHeader_1x14_P1.27mm_Vertical
R1: 82 - 0805W8F820JT5E; R_0603_1608Metric
R2, R3: 100; R_0603_1608Metric
R4, R5, R6, R7, R8, R9: 10k; R_0603_1608Metric
SW1: SW_Push - SKQGADE010; SW4-SMD-5.2X5.2X1.5MM
T1: Logo; logo
U1: Caravel; Caravel_WCSP
U2: MIC5350-SGYMT-TR; SON50P200X200X60-9N
U3: W25Q32FVSS; SOIC127P790X216-8N
X1: DSC6001_10MHZ; DSC6001JE1A-010.0000

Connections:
+1V8: C11.2, C14.2, J6.2, J6.3, U1.A10, U2.7
+3V3: C12.2, C13.1, J6.6, J6.7, R1.1, U1.F10, U2.8
+5V: C5.2, J1.6, J6.14, R2.2, R3.2, U2.1
Caravel_CSB: R4.1, U1.C10, U3.1
Caravel_D0: R7.1, U1.D10, U3.5
Caravel_D1: R5.1, U1.D9, U3.2
Caravel_SCK: R8.1, U1.D8, U3.6
GND: C1.1, C2.1, C3.2, C4.1, C5.1, C6.1, C7.2, C8.1, C9.1, C10.1, C11.1, C12.1, C13.2, C14.1, C15.2, J1.1, J2.2, SW1.2, U1.B3, U1.B7, U1.C5, U1.C6, U1.D5, U1.D6, U1.E6, U1.F6, U2.2, U2.9, U3.4, X1.2
unnamed: C8.2, U2.3
unnamed: D1.2, R1.2
unnamed: J2.1, X1.1
unnamed: R2.1, U2.4
unnamed: R3.1, U2.5
unnamed: R6.1, U3.3
unnamed: R9.1, U3.7
gpio: D1.1, U1.E10
mprj_io[0]: J3.1, U1.D7
mprj_io[1]_SDO: J3.2, U1.E9
mprj_io[2]_SDI: J3.3, U1.F9
mprj_io[3]_CSB: J3.4, U1.E8
mprj_io[4]_SCK: J3.5, U1.F8
mprj_io[5]_ser_rx: J1.2, J3.6, U1.E7
mprj_io[6]_ser_tx: J1.3, J3.7, U1.F7
mprj_io[7]: J3.8, U1.E5
mprj_io[8]: J3.9, U1.F5
mprj_io[9]: J3.10, U1.E4
mprj_io[10]: J3.11, U1.F4
mprj_io[11]: J3.12, U1.E3
mprj_io[12]: J3.13, U1.F3
mprj_io[13]: J3.14, U1.D3
mprj_io[14]: J4.1, U1.E2
mprj_io[15]: J4.2, U1.F1
mprj_io[16]: J4.3, U1.E1
mprj_io[17]: J4.4, U1.D2
mprj_io[18]: J4.5, U1.D1
mprj_io[19]: J4.6, U1.C1
mprj_io[20]: J4.7, U1.C2
mprj_io[21]: J4.8, U1.B1
mprj_io[22]: J4.9, U1.B2
mprj_io[23]: J4.10, U1.A1
mprj_io[24]: J4.11, U1.C3
mprj_io[25]: J4.12, U1.A3
mprj_io[26]: J4.13, U1.B4
mprj_io[27]: J4.14, U1.A4
mprj_io[28]: J5.1, U1.B5
mprj_io[29]: J5.2, U1.A5
mprj_io[30]: J5.3, U1.B6
mprj_io[31]: J5.4, U1.A6
mprj_io[32]: J5.5, U1.A7
mprj_io[33]: J5.6, U1.C8
vccd1: C3.1, J6.4, U1.F2
vccd2: C1.2, J6.1, U1.A2
vdda1: C4.2, C7.1, J6.8, U1.D4
vdda2: C6.2, J6.5, U1.C7
vddio: C2.2, C9.2, C10.2, C15.1, R4.2, R5.2, R6.2, R7.2, R8.2, R9.2, U1.C4, U3.8, X1.4
xclk: U1.C9, X1.3
~RST: SW1.1, U1.B10

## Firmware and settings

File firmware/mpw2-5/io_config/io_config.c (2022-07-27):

#include "../defs.h"
//#include "../print_io.h"

// --------------------------------------------------------
// GPIO configuration test
//
// Assorted attempts to understand what's going on inside
// the GPIO serial programming shift register.
//
// It is believed that there may be timing violations
// causing a bit shift like the one on the first ChipIgnite
// chip, but probably not between every single I/O.
// --------------------------------------------------------

void clock11()
{
    reg_mprj_xfer = 0x66; reg_mprj_xfer = 0x76;
}

void clock00()
{
    reg_mprj_xfer = 0x06; reg_mprj_xfer = 0x16;
}

// --------------------------------------------------------

void clock10()
{
    reg_mprj_xfer = 0x46; reg_mprj_xfer = 0x56;
}

void clock01()
{
    reg_mprj_xfer = 0x26; reg_mprj_xfer = 0x36;
}

// --------------------------------------------------------

void load()
{
    reg_mprj_xfer = 0x06; reg_mprj_xfer = 0x0e;
    reg_mprj_xfer = 0x0e; reg_mprj_xfer = 0x06;		// Apply load
}

void main()
{
    unsigned int i, j, k;

    reg_mprj_datal = 0;
    reg_mprj_datah = 0;

    // Set I/O to the "intended" config
    reg_mprj_io_37 = 0x1809;
    reg_mprj_io_36 = 0x1809;
    reg_mprj_io_33 = 0x1809;
    reg_mprj_io_32 = 0x1809;
    reg_mprj_io_31 = 0x1809;
    reg_mprj_io_30 = 0x1809;
    reg_mprj_io_29 = 0x1809;
    reg_mprj_io_28 = 0x1809;
    reg_mprj_io_27 = 0x1809;
    reg_mprj_io_26 = 0x1809;
    reg_mprj_io_25 = 0x1809;
    reg_mprj_io_24 = 0x1809;
    reg_mprj_io_23 = 0x1809;
    reg_mprj_io_22 = 0x1809;
    reg_mprj_io_21 = 0x1809;
    reg_mprj_io_20 = 0x1809;
    reg_mprj_io_19 = 0x1809;
    reg_mprj_io_18 = 0x1809;
    reg_mprj_io_17 = 0x1809;
    reg_mprj_io_16 = 0x1809;
    reg_mprj_io_15 = 0x1809;
    reg_mprj_io_14 = 0x1809;
    reg_mprj_io_13 = 0x1809;
    reg_mprj_io_12 = 0x1809;
    reg_mprj_io_11 = 0x1809;
    reg_mprj_io_10 = 0x1809;
    reg_mprj_io_9  = 0x1809;
    reg_mprj_io_8  = 0x1809;
    reg_mprj_io_7  = 0x1809;
    reg_mprj_io_6  = 0x1809;
    reg_mprj_io_5  = 0x1809;
    reg_mprj_io_4  = 0x0403;
    reg_mprj_io_3  = 0x0403;
    reg_mprj_io_2  = 0x0403;
    reg_mprj_io_1  = 0x1809;
    reg_mprj_io_0  = 0x1809;

    // Enable GPIO (all output, ena = 0)
    reg_gpio_mode1 = 1;
    reg_gpio_mode0 = 0;
    reg_gpio_ien = 1;
    reg_gpio_oe = 1;

    // Enable bit-bang mode
    reg_mprj_xfer = 0x06;			// Enable bit-bang mode
    reg_mprj_xfer = 0x04; reg_mprj_xfer = 0x06;	// Pulse reset

    if (1) {
	// Channels 19 and 18
	clock11();
	clock11();
	clock11();
	clock11();
	clock11();
	clock11();
	clock11();
	clock11();
	clock11();
	clock11();
	clock11();
	clock01(); // 0  (affects ch. 20)

	// Channels 20 and 17
	clock01(); // 0
	clock01(); // 0
	clock01(); // 0
	clock11(); // 1
	clock11(); // 1
	clock11(); // 1
	clock11(); // 1
	clock11(); // 1
	clock11(); // 1
	clock11(); // 1
	clock11(); // 1
	clock11(); // 1

	// Channels 21 and 16	/* 21 cannot be made to work? */
	clock01();
	clock00();
	clock00();
	clock10();
	clock10();
	clock10();
	clock10();
	clock10();
	clock10();
	clock10();
	clock10();
	clock11();

	// Channels 22 and 15
	clock01(); // 0
	clock00(); // 0
	clock00(); // 0
	clock10(); // 1
	clock10(); // 1
	clock10(); // 1
	clock10(); // 1
	clock10(); // 1
	clock10(); // 1
	clock10(); // 1
	clock10();
	clock11();

	// Channels 23 and 14
	clock11();
	clock00();
	clock00();
	clock00();
	clock00();
	clock00();
	clock00();
	clock00();
	clock00();
	clock00();
	clock10();
	clock11();

	// Channels 24 and 13
	clock11();
	clock00();
	clock00();
	clock00();
	clock00();
	clock00();
	clock00();
	clock00();
	clock00();
	clock00();
	clock10();
	clock11();

	// Channels 25 and 12
	clock01();	/* Ch 25:  000110101011 works. . . */
	clock00();
	clock00();
	clock10();
	clock10();
	clock00();
	clock10();
	clock00();
	clock10();
	clock00();
	clock10();
	clock11();

	// Channels 26 and 11
	clock11();
	clock00();
	clock00();
	clock00();
	clock00();
	clock00();
	clock00();
	clock00();
	clock00();
	clock00();
	clock00();
	clock11();

	// Channels 27 and 10
	clock11();
	clock00();
	clock00();
	clock00();
	clock00();
	clock00();
	clock00();
	clock00();
	clock00();
	clock00();
	clock00();
	clock11();

	// Channels 28 and 9
	clock11();
	clock00();
	clock00();
	clock00();
	clock00();
	clock00();
	clock00();
	clock00();
	clock00();
	clock00();
	clock00();
	clock11();

	// Channels 29 and 8
	clock11();
	clock00();
	clock00();
	clock00();
	clock00();
	clock00();
	clock00();
	clock00();
	clock00();
	clock00();
	clock00();
	clock11();

	// Channels 30 and 7
	clock11();
	clock00();
	clock00();
	clock00();
	clock00();
	clock00();
	clock00();
	clock00();
	clock00();
	clock00();
	clock00();
	clock11();

	// Channels 31 and 6
	clock11();
	clock00();
	clock00();
	clock00();
	clock00();
	clock00();
	clock00();
	clock00();
	clock00();
	clock00();
	clock00();
	clock11();

	// Channels 32 and 5
	clock11();
	clock00();
	clock00();
	clock00();
	clock00();
	clock00();
	clock00();
	clock00();
	clock00();
	clock00();
	clock00();
	clock11();

	// Channels 33 and 4
	clock11();
	clock00();
	clock00();
	clock00();
	clock00();
	clock00();
	clock00();
	clock00();
	clock00();
	clock00();
	clock00();
	clock10();

	// Channels 34 and 3
	clock10();
	clock01();
	clock00();
	clock00();
	clock00();
	clock00();
	clock00();
	clock00();
	clock00();
	clock00();
	clock01();
	clock11();

	// Channels 35 and 2
	clock10();
	clock01();
	clock00();
	clock00();
	clock00();
	clock00();
	clock00();
	clock00();
	clock00();
	clock00();
	clock01();
	clock11();

	// Channels 36 and 1
	clock10();
	clock01();
	clock00();
	clock00();
	clock00();
	clock00();
	clock00();
	clock00();
	clock00();
	clock00();
	clock01();
	clock11();

	// Channels 37 and 0
	// NOTE:  Channel 0 must be off or else debug mode gets enabled!
	clock10();
	clock00();
	clock00();
	clock00();
	clock00();
	clock00();
	clock00();
	clock00();
	clock11();
	clock00();
	clock01();
	clock11();

	load();
	load();
	load();
    }

    while (1) {

	// Blink forever
	// Pulse N times for channel N before the long pulse

        reg_mprj_datal = 0x00000000;
        reg_mprj_datah = 0x00000000;

        i = 0x20;
        for (j = 0; j < 5; j++) {
             reg_mprj_datah = i;
             for (k = 0; k < 250; k++);
                 reg_mprj_datah = 0x00000000;
             for (k = 0; k < 250; k++);
             i >>= 1;
             i |= 0x20;
        }
        i = 0x80000000;
        for (j = 0; j < 32; j++) {
             reg_mprj_datah = 0x3f;
             reg_mprj_datal = i;
             for (k = 0; k < 250; k++);
             reg_mprj_datah = 0x00;
                 reg_mprj_datal = 0x00000000;
             for (k = 0; k < 250; k++);
             i >>= 1;
             i |= 0x80000000;
        }
        reg_mprj_datal = 0xffffffff;
        reg_mprj_datah = 0x0000003f;

        reg_gpio_out = 0x1;

        for (j = 0; j < 40000; j++);

        reg_mprj_datal = 0x00000000;
        reg_mprj_datah = 0x00000000;

        reg_gpio_out = 0x0;

        for (j = 0; j < 40000; j++);
   }
}

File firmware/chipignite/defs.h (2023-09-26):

/*
 * SPDX-FileCopyrightText: 2020 Efabless Corporation
 *
 * Licensed under the Apache License, Version 2.0 (the "License");
 * you may not use this file except in compliance with the License.
 * You may obtain a copy of the License at
 *
 *      http://www.apache.org/licenses/LICENSE-2.0
 *
 * Unless required by applicable law or agreed to in writing, software
 * distributed under the License is distributed on an "AS IS" BASIS,
 * WITHOUT WARRANTIES OR CONDITIONS OF ANY KIND, either express or implied.
 * See the License for the specific language governing permissions and
 * limitations under the License.
 * SPDX-License-Identifier: Apache-2.0
 */

#ifndef _DEF_H_
#define _DEF_H_

#include <stdint.h>
#include <stdbool.h>

#include <csr.h>

// a pointer to this is a null pointer, but the compiler does not
// know that because "sram" is a linker symbol from sections.lds.
extern uint32_t sram;

// Pointer to firmware flash routines
extern uint32_t flashio_worker_begin;
extern uint32_t flashio_worker_end;

// Storage area (MGMT: 0x0100_0000, User: 0x0200_0000)
#define reg_rw_block0  (*(volatile uint32_t*)0x01000000)
#define reg_rw_block1  (*(volatile uint32_t*)0x01100000)
#define reg_ro_block0  (*(volatile uint32_t*)0x02000000)

// UART (0x2000_0000)
//#define reg_uart_clkdiv (*(volatile uint32_t*)0x20000000)
#define reg_uart_data   (*(volatile uint32_t*) CSR_UART_RXTX_ADDR)
#define reg_uart_txfull   (*(volatile uint32_t*) CSR_UART_TXFULL_ADDR)
#define reg_uart_enable (*(volatile uint32_t*) CSR_UART_ENABLED_OUT_ADDR)
#define reg_uart_irq_en    (*(volatile uint32_t*) CSR_UART_EV_ENABLE_ADDR) // ADDED

// DEBUG (0x2000_0000)
//#define reg_uart_clkdiv (*(volatile uint32_t*)0x20000000)
#define reg_reset   (*(volatile uint32_t*) CSR_CTRL_RESET_ADDR)
#define reg_debug_data   (*(volatile uint32_t*) CSR_DEBUG_RXTX_ADDR)
#define reg_debug_txfull   (*(volatile uint32_t*) CSR_DEBUG_TXFULL_ADDR)
#define reg_debug_irq_en   (*(volatile uint32_t*) CSR_USER_IRQ_3_EV_ENABLE_ADDR)
//#define reg_debug_enable (*(volatile uint32_t*) CSR_UART_ENABLED_OUT_ADDR)

// GPIO (0x2100_0000)
#define reg_gpio_mode1  (*(volatile uint32_t*) CSR_GPIO_MODE1_ADDR)
#define reg_gpio_mode0  (*(volatile uint32_t*) CSR_GPIO_MODE0_ADDR)
#define reg_gpio_ien    (*(volatile uint32_t*) CSR_GPIO_IEN_ADDR)
#define reg_gpio_oe     (*(volatile uint32_t*) CSR_GPIO_OE_ADDR)
#define reg_gpio_in     (*(volatile uint32_t*) CSR_GPIO_IN_ADDR)
#define reg_gpio_out    (*(volatile uint32_t*) CSR_GPIO_OUT_ADDR)
//#define reg_gpio_pu   (*(volatile uint32_t*)0x21000008)
//#define reg_gpio_pd   (*(volatile uint32_t*)0x2100000c)

// Logic Analyzer (0x2200_0000)
#define reg_la3_data (*(volatile uint32_t*) CSR_LA_OUT_ADDR)
#define reg_la2_data (*(volatile uint32_t*) (CSR_LA_OUT_ADDR + 4))
#define reg_la1_data (*(volatile uint32_t*) (CSR_LA_OUT_ADDR + 8))
#define reg_la0_data (*(volatile uint32_t*) (CSR_LA_OUT_ADDR + 12))

#define reg_la3_data_in (*(volatile uint32_t*) CSR_LA_IN_ADDR)
#define reg_la2_data_in (*(volatile uint32_t*) (CSR_LA_IN_ADDR + 4))
#define reg_la1_data_in (*(volatile uint32_t*) (CSR_LA_IN_ADDR + 8))
#define reg_la0_data_in (*(volatile uint32_t*) (CSR_LA_IN_ADDR + 12))

#define reg_la3_oenb (*(volatile uint32_t*) CSR_LA_OE_ADDR)
#define reg_la2_oenb (*(volatile uint32_t*) (CSR_LA_OE_ADDR + 4))
#define reg_la1_oenb (*(volatile uint32_t*) (CSR_LA_OE_ADDR + 8))
#define reg_la0_oenb (*(volatile uint32_t*) (CSR_LA_OE_ADDR + 12))

#define reg_la3_iena (*(volatile uint32_t*) CSR_LA_IEN_ADDR)
#define reg_la2_iena (*(volatile uint32_t*) (CSR_LA_IEN_ADDR + 4))
#define reg_la1_iena (*(volatile uint32_t*) (CSR_LA_IEN_ADDR + 8))
#define reg_la0_iena (*(volatile uint32_t*) (CSR_LA_IEN_ADDR + 12))

#define reg_la_sample (*(volatile uint32_t*)0x25000030)

// User Project Control (0x2300_0000)
#define reg_mprj_xfer (*(volatile uint32_t*)0x26000000)
#define reg_mprj_pwr  (*(volatile uint32_t*)0x26000004)
#define reg_mprj_irq  (*(volatile uint32_t*)0x26000008)
#define reg_mprj_datal (*(volatile uint32_t*)0x2600000c)
#define reg_mprj_datah (*(volatile uint32_t*)0x26000010)

#define reg_mprj_io_0 (*(volatile uint32_t*)0x26000024)
#define reg_mprj_io_1 (*(volatile uint32_t*)0x26000028)
#define reg_mprj_io_2 (*(volatile uint32_t*)0x2600002c)
#define reg_mprj_io_3 (*(volatile uint32_t*)0x26000030)
#define reg_mprj_io_4 (*(volatile uint32_t*)0x26000034)
#define reg_mprj_io_5 (*(volatile uint32_t*)0x26000038)
#define reg_mprj_io_6 (*(volatile uint32_t*)0x2600003c)

#define reg_mprj_io_7 (*(volatile uint32_t*)0x26000040)
#define reg_mprj_io_8 (*(volatile uint32_t*)0x26000044)
#define reg_mprj_io_9 (*(volatile uint32_t*)0x26000048)
#define reg_mprj_io_10 (*(volatile uint32_t*)0x2600004c)

#define reg_mprj_io_11 (*(volatile uint32_t*)0x26000050)
#define reg_mprj_io_12 (*(volatile uint32_t*)0x26000054)
#define reg_mprj_io_13 (*(volatile uint32_t*)0x26000058)
#define reg_mprj_io_14 (*(volatile uint32_t*)0x2600005c)
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

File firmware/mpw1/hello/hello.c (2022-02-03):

//#include "../defs.h"
#include "../defs_mpw-two-mfix.h"
#include "../print_io.h"
//#include "spi_io.h"


// --------------------------------------------------------
// Firmware routines
// --------------------------------------------------------

void set_gpio(int pin)
{
    (volatile uint32_t) ((reg_mprj_datal) |= pin);
}

void clear_gpio(int pin)
{
    (volatile uint32_t) ((reg_mprj_datal) &= ~(pin));
}

void main()
{
	int i, j, k;

	i = 1;

//    reg_mprj_io_37 = GPIO_MODE_MGMT_STD_OUTPUT;
//    reg_mprj_io_36 = GPIO_MODE_MGMT_STD_OUTPUT;
//    reg_mprj_io_35 = GPIO_MODE_MGMT_STD_OUTPUT;
//    reg_mprj_io_34 = GPIO_MODE_MGMT_STD_OUTPUT;
//    reg_mprj_io_33 = GPIO_MODE_MGMT_STD_OUTPUT;
//    reg_mprj_io_32 = GPIO_MODE_MGMT_STD_OUTPUT;
//
//    reg_mprj_io_31 = GPIO_MODE_MGMT_STD_OUTPUT;
//    reg_mprj_io_30 = GPIO_MODE_MGMT_STD_OUTPUT;
//    reg_mprj_io_29 = GPIO_MODE_MGMT_STD_OUTPUT;
//    reg_mprj_io_28 = GPIO_MODE_MGMT_STD_OUTPUT;
//
//    reg_mprj_io_27 = GPIO_MODE_MGMT_STD_OUTPUT;
//    reg_mprj_io_26 = GPIO_MODE_MGMT_STD_OUTPUT;
//    reg_mprj_io_25 = GPIO_MODE_MGMT_STD_OUTPUT;
//    reg_mprj_io_24 = GPIO_MODE_MGMT_STD_OUTPUT;
//
//    reg_mprj_io_23 = GPIO_MODE_MGMT_STD_OUTPUT;
//    reg_mprj_io_22 = GPIO_MODE_MGMT_STD_OUTPUT;
//    reg_mprj_io_21 = GPIO_MODE_MGMT_STD_OUTPUT;
//    reg_mprj_io_20 = GPIO_MODE_MGMT_STD_OUTPUT;
//    reg_mprj_io_19 = GPIO_MODE_MGMT_STD_OUTPUT;
//
//    reg_mprj_io_18 = GPIO_MODE_MGMT_STD_OUTPUT;
//    reg_mprj_io_17 = GPIO_MODE_MGMT_STD_OUTPUT;
//    reg_mprj_io_16 = GPIO_MODE_MGMT_STD_OUTPUT;
//
//    reg_mprj_io_15 = GPIO_MODE_MGMT_STD_OUTPUT;
//    reg_mprj_io_14 = GPIO_MODE_MGMT_STD_OUTPUT;
//    reg_mprj_io_13 = GPIO_MODE_MGMT_STD_OUTPUT;
//    reg_mprj_io_12 = GPIO_MODE_MGMT_STD_OUTPUT;
//    reg_mprj_io_11 = GPIO_MODE_MGMT_STD_OUTPUT;
//    reg_mprj_io_10 = GPIO_MODE_MGMT_STD_OUTPUT;
//    reg_mprj_io_9 = GPIO_MODE_MGMT_STD_OUTPUT;
//    reg_mprj_io_8 = GPIO_MODE_MGMT_STD_OUTPUT;
//    reg_mprj_io_7 = GPIO_MODE_MGMT_STD_OUTPUT;
//    reg_mprj_io_6 = GPIO_MODE_MGMT_STD_OUTPUT;
//    reg_mprj_io_5 = GPIO_MODE_MGMT_STD_OUTPUT;
//
//    reg_mprj_io_4 = GPIO_MODE_USER_STD_INPUT_NOPULL;
//    reg_mprj_io_3 = GPIO_MODE_USER_STD_INPUT_NOPULL;
//    reg_mprj_io_2 = GPIO_MODE_USER_STD_INPUT_NOPULL;   // 0x0403
//    reg_mprj_io_1 = GPIO_MODE_USER_STD_BIDIRECTIONAL;  // 0x1803

    reg_mprj_io_6 = 0x7ff;

    reg_mprj_datal = 0;

    reg_uart_clkdiv = 1042;
    reg_uart_enable = 1;

    reg_mprj_xfer = 1;
    while (reg_mprj_xfer == 1);

	// Enable GPIO (all output, ena = 0)
	reg_gpio_ena = 0x0;
	reg_gpio_pu = 0x0;
	reg_gpio_pd = 0x0;
	reg_gpio_data = 0x1;

    reg_mprj_io_37 = GPIO_MODE_MGMT_STD_OUTPUT;
    reg_mprj_io_36 = GPIO_MODE_MGMT_STD_OUTPUT;
    reg_mprj_io_35 = GPIO_MODE_MGMT_STD_OUTPUT;
    reg_mprj_io_34 = GPIO_MODE_MGMT_STD_OUTPUT;
    reg_mprj_io_33 = GPIO_MODE_MGMT_STD_OUTPUT;
    reg_mprj_io_32 = GPIO_MODE_MGMT_STD_OUTPUT;

    reg_mprj_io_31 = GPIO_MODE_MGMT_STD_OUTPUT;
    reg_mprj_io_30 = GPIO_MODE_MGMT_STD_OUTPUT;
    reg_mprj_io_29 = GPIO_MODE_MGMT_STD_OUTPUT;
    reg_mprj_io_28 = GPIO_MODE_MGMT_STD_OUTPUT;

    reg_mprj_io_27 = GPIO_MODE_MGMT_STD_OUTPUT;
    reg_mprj_io_26 = GPIO_MODE_MGMT_STD_OUTPUT;
    reg_mprj_io_25 = GPIO_MODE_MGMT_STD_OUTPUT;
    reg_mprj_io_24 = GPIO_MODE_MGMT_STD_OUTPUT;

    reg_mprj_io_23 = GPIO_MODE_MGMT_STD_OUTPUT;
    reg_mprj_io_22 = GPIO_MODE_MGMT_STD_OUTPUT;
    reg_mprj_io_21 = GPIO_MODE_MGMT_STD_OUTPUT;
    reg_mprj_io_20 = GPIO_MODE_MGMT_STD_OUTPUT;
    reg_mprj_io_19 = GPIO_MODE_MGMT_STD_OUTPUT;

    reg_mprj_io_18 = GPIO_MODE_MGMT_STD_OUTPUT;
    reg_mprj_io_17 = GPIO_MODE_MGMT_STD_OUTPUT;
    reg_mprj_io_16 = GPIO_MODE_MGMT_STD_OUTPUT;

    reg_mprj_io_15 = GPIO_MODE_MGMT_STD_OUTPUT;
    reg_mprj_io_14 = GPIO_MODE_MGMT_STD_OUTPUT;
    reg_mprj_io_13 = GPIO_MODE_MGMT_STD_OUTPUT;
    reg_mprj_io_12 = GPIO_MODE_MGMT_STD_OUTPUT;
    reg_mprj_io_11 = GPIO_MODE_MGMT_STD_OUTPUT;
    reg_mprj_io_10 = GPIO_MODE_MGMT_STD_OUTPUT;
    reg_mprj_io_9 = GPIO_MODE_MGMT_STD_OUTPUT;
    reg_mprj_io_8 = GPIO_MODE_MGMT_STD_OUTPUT;
    reg_mprj_io_7 = GPIO_MODE_MGMT_STD_OUTPUT;
    reg_mprj_io_6 = GPIO_MODE_MGMT_STD_OUTPUT;
    reg_mprj_io_5 = GPIO_MODE_MGMT_STD_OUTPUT;

    reg_mprj_io_4 = GPIO_MODE_USER_STD_INPUT_NOPULL;
    reg_mprj_io_3 = GPIO_MODE_USER_STD_INPUT_NOPULL;
    reg_mprj_io_2 = GPIO_MODE_USER_STD_INPUT_NOPULL;   // 0x0403
    reg_mprj_io_1 = GPIO_MODE_USER_STD_BIDIRECTIONAL;  // 0x1803

//	reg_mprj_datal = 0x00000000;
//	reg_mprj_datah = 0x00000000;

//    spi_init();

//    print("Hello!\n");

    char *msg[] = {
//  "******************* ",
    " Woowzaaa!!         ",
    "                    ",
    " I'm Caravel !!     ",
    "      I'm Alive !!! ",
//  "******************* ",
    };

    int n = 4;

    putchar("|"); putchar(0x80);
    putchar("|"); putchar(0x9e);
    putchar("|"); putchar(0xbc);

	while(1) {
	    print("|"); putchar(0x2d); // clear screen

        for (i=0; i < 2; i++) {
            reg_gpio_data = 0x0;
            for (j = 0; j < 3000; j++);
            reg_gpio_data = 0x1;
            for (j = 0; j < 5000; j++);
        }

	    for (i = 0; i < n; i++) {
	        print(msg[i]);
	        for (j = 0; j < 5000; j++);
	        reg_gpio_data = 0x0;
            for (j = 0; j < 5000; j++);
	        reg_gpio_data = 0x1;
	    }

        for (j = 0; j < 10000; j++);

//        for (i=0; i < 2; i++) {
//            reg_gpio_data = 0x0;
//            for (j = 0; j < 3000; j++);
//            reg_gpio_data = 0x1;
//            for (j = 0; j < 5000; j++);
//        }

//        i = 0;
//        while (i < 38) {
//            for (j = i; j < i+4; j++) {
////                print("|"); putchar(0x2d); // clear screen
//                print_dec(j); print(" : 0x"); print_hex(reg_mprj_io_0 + j*4, 4); print("\n");
////                print_dec(j); print(" : 0x"); print_hex(reg_mprj_io_0 + j*4, 4); print("\n");
////                print_dec(j); print(" : 0x"); print_hex(reg_mprj_io_0 + j*4, 4); print("\n");
//                for (k = 0; k < 10000; k++);
//            }
//            i += 4;
//        }
//
//        for (j = 0; j < 30000; j++);

    }

//        reg_mprj_datal = 0x00080000;
//        reg_mprj_datal = 0xffffffff;
//        reg_mprj_datah = 0xffffffff;
//        set_gpio(19);
//        reg_gpio_data = 0x0;
//
//        for (j = 0; j < 3000; j++);
//
////       	reg_mprj_datal = 0x00000000;
////       	reg_mprj_datah = 0x00000000;
////        clear_gpio(19);
//        reg_gpio_data = 0x1;
//
//        for (j = 0; j < 3000; j++);

//        putchar('x');

//	}
}

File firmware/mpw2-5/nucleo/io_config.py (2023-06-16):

from nucleo_api import *
import os
import gpio_config_builder
from flash import flash_mem
import sys
from machine import Pin

VERSION = "io_config -- version 1.2.2"
config_filename = "gpio_config_def.py"
debug = False
# debug=True



# used as an activity indicator
#        - active = flash firmware, checking for IO pulses

led_blue = Led("B7")

# used for program start and completion

led_green = Led("B0")

# red and green are used at program termination
#       - flashing red = chain configuration failure

led_red = Led("B14")


def run_builder(gpio_l, gpio_h, bypass):
    """runs the builder to get the configuration stream

    Args:
        gpio_l (class): low chain class
        gpio_h (class): high chain class

    Returns:
        array: configuration stream after running builder
    """

    gpio_l = ",".join(gpio_l)
    gpio_h = ",".join(gpio_h)
    return gpio_config_builder.build_config(gpio_h, gpio_l, True, bypass)


def run_builder_sanity(gpio_l, gpio_h, bypass):
    """runs the builder for the sanity check, where it will skip the initiallization of low and high chain

    Args:
        gpio_l (class): low chain class
        gpio_h (class): high chain class

    Returns:
        array: configuration sream after running builder
    """
    return gpio_config_builder.build_config(gpio_h, gpio_l, False, bypass)


def flash_data(test_name, config_stream, first_line=1):
    """flashes only the data part that changes with the config_stream

    Args:
        test_name (string): name of test
        config_stream (array): description of the bitstream of each IO
        first_line (int, optional): flag to make sure the config_stream is in the correct location. Defaults to 1.
    """
    hex_file = open(f"{test_name}-tmp.hex", "w")
    hex_data = ""
    output_hex = []
    n_bits = config_stream[0]

    with open(f"{test_name}.hex", mode="r") as f:
        line = f.readline()
        line = line.strip()
        while line != "":
            if line.startswith("@"):
                if first_line > 0:
                    first_line = first_line - 1
                else:
                    output_hex = [line.strip()]
                    break
            line = f.readline()

    count = 0
    for d in config_stream:
        hex_data = hex_data + " {:02x}".format(d)
        count = count + 1
        if count >= 16:
            output_hex.append(f"{hex_data[1:]}")
            count = 0
            hex_data = ""

    if hex_data:
        c = 0
        last_line_len = len(hex_data[1:].split())
        if last_line_len <= 8:
            while len(hex_data[1:].split()) < 8:
                hex_data = hex_data + " " + "00"
            hex_data = (
                hex_data
                + " "
                + f"{str(hex(int(n_bits)))[2:].upper()} 00 00 00 00 00 00 00 "
            )
            output_hex.append(f"{hex_data[1:]}")
        elif last_line_len > 8 and last_line_len < 16:
            while len(hex_data[1:].split()) < 16:
                hex_data = hex_data + " " + "00"
            output_hex.append(f"{hex_data[1:]}")
            output_hex.append(
                f"{str(hex(int(n_bits)))[2:].upper()} 00 00 00 00 00 00 00 "
            )
    else:
        output_hex.append(f"{str(hex(int(n_bits)))[2:].upper()} 00 00 00 00 00 00 00 ")
    for i in output_hex:
        hex_file.write(f"{i}\n")
    hex_file.close()

    flash(f"{test_name}-tmp.hex", debug)


def exec_flash_data(test, test_name, config_stream):
    """executes firmware flashing sequence and data flashing

    Args:
        test (class): description of the test about to run
        test_name (string): name of test
        config_stream (string): description of the bitstream of each IO
    """
    print("::::: flashing Caravel :::::")
    test.apply_reset()
    # test.powerup_flash()
    test.powerup_sequence()
    erase()
    # test.flash(f"{test_name}.hex")
    flash(f"{test_name}.hex", debug)
    flash_data(test_name, config_stream)
    test.powerup_sequence()
    test.release_reset()
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

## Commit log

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2021-09-28 re-organizing the repo and pushing kicad schematic
    [Caravel_pcb.kicad_pcb, Caravel_pcb.sch, TC2030-IDC-NL.step]
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2022-05-11 add directory for caravel_pcb_v2
    [Caravel_BOM.xlsx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]
2022-05-17 removed TMUX, used caravel_breakout
    [caravel_pcb_v3_FTDI.kicad_pcb, caravel_pcb_v3_FTDI.kicad_sch]
2022-05-17 replaced FTDI with MCP2221A, used caravel_breakout
    [caravel_pcb_v3_MCP.kicad_sch]
2022-06-08 Caravel QFN breakout board with PCB
    [caravel_breakout_QFN.kicad_pcb, caravel_breakout_QFN.kicad_sch]
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2022-06-09 Update MCP version of the V3 caravel board
    Updates footprint assignments and create initial PCB.
    [caravel_pcb_v3_MCP.kicad_pcb, caravel_pcb_v3_MCP.kicad_sch]
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2022-07-02 fix caravel breakout pin mismatch
    [caravel_pcb_v3_FTDI_flexy.kicad_pcb, caravel_pcb_v3_FTDI_flexy.kicad_sch]
2022-07-06 add pads on both sides of caravel breakout board (Rev C)
    [caravel_breakout_QFN.kicad_pcb]
2022-07-06 update FTDI caravel board PCB and BOM (Rev 3C)
    [caravel_pcb_v3_FTDI.xlsx, caravel_pcb_v3_FTDI_flexy.kicad_pcb, caravel_pcb_v3_FTDI_flexy.kicad_sch]
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2022-08-07 add caravel main board with SMD pads (Rev 3E)
    [caravel_pcb_v3_FTDI_SMD.kicad_pcb, caravel_pcb_v3_FTDI_SMD.kicad_sch]
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2022-08-08 add caravel FTDI board with QFN test socket(Rev 1)
    [caravel_FTDI_QFN_test_socket.kicad_pcb, caravel_FTDI_QFN_test_socket.kicad_sch]
2022-08-12 add BOM caravel FTDI board QFN test socket (Rev 1)
    [caravel_FTDI_QFN_test_socket.xlsx]
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2022-08-24 fix page misalignment for flash programming
    [caravel_hkflash.py]
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2022-08-26 further updates, correction for data dependent holds, 8 gpio working on upper IO.
    [gpio_config_builder.py, gpio_config_simulator.py]
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2022-09-01 add wip of caravel board compatible with Nucleo
    [caravel_breakout_Nucleo.kicad_pcb, caravel_breakout_Nucleo.kicad_sch]
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2022-09-08 update caravel FTDI mainboard V4 (Rev 4B) to support different LDO devices with the same footprint
    [caravel_pcb_v4_FTDI.xlsx, caravel_pcb_v4_FTDI_SMD.kicad_pcb, caravel_pcb_v4_FTDI_SMD.kicad_sch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]
2022-09-08 update BOM caravel FTDI mainboard V4 (Rev 4B)
    [caravel_pcb_v4_FTDI.xlsx]
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2022-10-02 update caravel nucleo hat board Rev A PCB
    [caravel_Nucleo.kicad_pcb, caravel_Nucleo.kicad_sch]
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2022-10-04 update caravel QFN breakout board with WCSP pinout (V2)
    [caravel_breakout_QFN.kicad_pcb, caravel_breakout_QFN.kicad_sch]
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2022-11-07 fix manipulation of hex
    [io_config.py]
2022-11-11 add reset for flash.py
    [flash.py]
2022-11-13 update gpio_config_builder.py and gpio_config_io.c to not generate n_bits value
    [caravel_Nucleo.kicad_pcb, caravel_Nucleo.kicad_sch, caravel_Nucleo.xlsx]
2022-11-13 iteration for fixing io_config.py
    [io_config.py]
2022-11-14 fix io_config.py - hex file read to find addr
    [io_config.py]
2022-11-14 fix padding in gpio_config_builder.py
    [gpio_config_builder.py]
2022-11-14 fixing bug with io_config.py
    [io_config.py]
2022-11-17 correct firmware for position of n_bits
    [gpio_config_builder.py]
2022-11-18 fix higher chain
2022-11-18 update config_io_o to pad to fixed length
    [gpio_config_builder.py]
2022-11-20 changed protocol to only use 1 hex file and modified the script to output the correct file format in the nucleo
    [config_io_o.c, io_config.py]
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2022-12-23 correct path for import
    [gpio_config_builder.py]
2022-12-23 fix simulator, add gpio checker
    [gpio_config_builder.py, gpio_config_checker.py]
2023-01-20 Include instructions to get your correct device.
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2023-01-27 fix sanity check typo
    [io_config.py]
2023-01-27 correct Makefile issue with check_device
    [io_config.py]
2023-01-28 Fixing sed command
    On Ubuntu 21.10 sed needs the parameter for the -i to be attached directly without a space in between
    Adding additional TOOLCHAIN path
2023-01-30 fixed issue with io[32]
    [config_io_o.c]
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2023-02-01 update documentation and correct powerup for Nucleo boot
2023-02-02 correct IO[37] and add poweron() for io_config.py
    [io_config.py, nucleo_api.py]
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2023-02-02 added the type of violation in failure message
    [io_config.py]
2023-02-02 fixed bug with sanity check
    [io_config.py]
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2023-02-02 changed how the pass/fail is printed
    [io_config.py]
2023-02-02 fix voltage on poweron()
    [io_config.py]
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2023-02-03 correct power sequence; remove turn_off_ios()
    [io_config.py, nucleo_api.py]
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2023-02-04 update firmware to swap IO 0 & 37
    [config_io_o.c, gpio_config_builder.py, io_config.py]
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2023-02-06 added the MGMT_IN fix for low voltage on analog projects
    [gpio_config_builder.py, io_config.py]
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2023-03-20 add caravel breakout board as M.2 card (V1)
    [caravel-M.2-card.kicad_pcb, caravel-M.2-card.kicad_sch, caravel-M.2-card.xls]
2023-03-23 ~ rename `caravel-M.2-card-WCSP` for caravel breakout M.2 card as the caravel package is WCSP
    [caravel-M.2-card-WCSP.kicad_pcb, caravel-M.2-card-WCSP.kicad_sch, caravel-M.2-card-WCSP.xls]
2023-03-23 ~ update M.2 connector footprint ~ update old strive footprints as they produced some DRC errors
2023-03-23 + add caravel M.2 carrier board (REV 5A) that is compatible with caravel M.2 card
    [caravel-M.2-carrier.kicad_pcb, caravel-M.2-carrier.kicad_sch, caravel-M.2-carrier.xlsx]
2023-03-27 update Caravel M.2 card PCB + add large via for each power domain to ease monitoring them
    [caravel-M.2-card-WCSP.kicad_pcb]
2023-03-28 rename caravel M.2 carrier board to caravel dev v5 board update Caravel dev (REV5A) pcb: ~ update the serial display connector to 3-pin + add large via for the manual reset to be able to monitor it
    [caravel-dev-v5-M.2.kicad_pcb, caravel-dev-v5-M.2.kicad_sch, caravel-dev-v5-M.2.xlsx]
2023-03-28 add gerber files for Caravel dev (REV5A) and M.2 card pcbs
    [caravel-dev-v5-M.2.kicad_pcb]
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2023-04-03 add QFN caravel breakout board as M.2 card (V1)
    [caravel-M.2-card-QFN.kicad_pcb, caravel-M.2-card-QFN.kicad_sch]
2023-04-03 ~ update Sparkfun MicroMod footprint with copper fill keepout area near the card edge this is required to avoid shorts when the card is inserted into the connector
2023-04-03 update Caravel M.2 card PCBs - remove copper fill at the card edge to avoid shorts when the card is inserted in the M.2 connector
    [caravel-M.2-card-QFN.kicad_pcb, caravel-M.2-card-WCSP.kicad_pcb]
2023-04-03 add caravel Nucleo hat PCB that utilizes M.2 connector (REV 2A)
    [caravel-Nucleo-v2-M.2.kicad_pcb, caravel-Nucleo-v2-M.2.kicad_sch, caravel-Nucleo-v2-M.2.xlsx]
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2023-04-05 add LED bar pcb for caravel demo project
    [led-bar-pcb.kicad_pcb, led-bar-pcb.kicad_sch, led-bar-pcb.xlsx]
2023-04-05 update `led-bar-pcb` BOM to fix resistors values update `caravel-Nucleo-v2-M.2` BOM to remove flexy pins from the previous iteration
    [caravel-Nucleo-v2-M.2.xlsx, led-bar-pcb.xlsx]
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2023-04-17 ~ fix `caravel-M.2-card-QFN` BOM caps quantity
    [caravel-M.2-card-QFN.xls]
2023-04-27 ~ update `ledled-bar-pcb` BOM with alternative LED bar that has smaller Vf
    [led-bar-pcb.xlsx]
2023-05-02 add 5V oscillator footprint
2023-05-02 add 5V development board (REV 6A) BOM and schematic
    [5V-dev-v6-M.2.kicad_sch, 5V-dev-v6-M.2.xlsx]
2023-05-03 add 5V development board (REV 6A) PCB and gerbers
    [5V-dev-v6-M.2.kicad_pcb, 5V-dev-v6-M.2.kicad_sch]
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2023-05-15 update 5V development board (REV 6B) schematic: ~ fix the reversed connections on the U10 level shifter + add 1 and 0.01 uF bypass caps to the Flash memory supply + add 10 uF bulk decoupling cap to t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
    [caravel-5V-dev-v6-M.2.kicad_sch]
2023-05-25 update `caravel-5V-dev-v6-M.2` to REV6B that fixes identified issues during bringup
    [caravel-5V-dev-v6-M.2.kicad_pcb, caravel-5V-dev-v6-M.2.kicad_sch]
2023-05-26 update `caravel-5V-dev-v6-M.2` (REV6B) + add an 0.1uF bypass cap to the Flash level shifters ~ update BOM
    [caravel-5V-dev-v6-M.2.kicad_sch, caravel-5V-dev-v6-M.2.xlsx]
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2023-07-24 update `caravel-dev-v5-M.2` BOM: ~ X1 MEMS oscillator is obsolete and is updated to a replacement part ~ pin-header parts are out of stock
    [caravel-dev-v5-M.2.xlsx]
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2023-08-17 + add fab drawing for `caravel-M.2-card-QFN` and `caravel-dev-v5-M.2`
    [Fab-Drawing-caravel-M.2-card-QFN.kicad_pcb, Fab-Drawing-caravel-dev-v5-M.2.kicad_pcb]
2023-08-21 Corrected the assignments for GPIO pull-up and pull-down input modes to match the values in the caravel repository.
    [defs.h]
2023-10-07 add gerbers for panelized breakout; reorganize hardware directories
    [Caravel_BOM.xlsx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]
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2024-01-16 fix typo in binary reversal of project id
    [caravel_hkdebug.py]
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2024-01-31 + add clear dev board schematic and BOM
    [clear-dev-v1.kicad_sch, clear-dev-v1.xlsx]
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2024-01-31 ~ update clear PCB with test pads for clock generator dither enable and power-down mode enable to allow enabling them if needed
    [clear-dev-v1.kicad_pcb, clear-dev-v1.kicad_sch]
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2024-02-05 + add a tri-state buffer to connect `MEM_SO` to `USB_SI` only when the FTDI is programming the Flash
    [clear-dev-v1.kicad_sch, clear-dev-v1.xlsx]
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2024-02-08 + add clear dev board gerbers and Fab drawing
    [Fab-Drawing-clear-dev-v1.kicad_pcb]
2024-02-12 ~ update caravel v5 board: ~ fix UART mode issue by enabling it by default (pull `~UART_EN` down) and in SPI mode, the FTDI drives `~UART_EN` high. This is required since the FTDI GPIOs are not confi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
    [caravel-dev-v5-M.2.kicad_sch]
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2024-03-10 ~ update caravel REV 5B with larger logos
    [caravel-dev-v5-M.2.kicad_pcb, caravel-dev-v5-M.2.kicad_sch]
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2024-04-21 update clear dev board to REV 1B after layout review
    [Fab-Drawing-clear-dev-v1.kicad_pcb, clear-dev-v1.kicad_pcb, clear-dev-v1.kicad_sch]
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2024-07-02 HKDebug cleanup fixes: Restore UART enable per each script; fix minor bugs
    [caravel_hkdebug.py, caravel_hkflash.py, gpio.py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]

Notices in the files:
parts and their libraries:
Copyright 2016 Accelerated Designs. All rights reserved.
